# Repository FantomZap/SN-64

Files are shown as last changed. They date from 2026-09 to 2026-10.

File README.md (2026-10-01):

# SN 64

SN 64 is an active engineering project for an FPGA-based SNES/Super Famicom cartridge adapter. **The target is one adapter for both an original Nintendo 64 and ModRetro M64 through the standard N64 cartridge interface, without internal console modifications.** Compatibility has not yet been demonstrated on hardware.

The FPGA will recreate the SNES motherboard environment and provide a protected, complete SNES cartridge interface. Original SNES/SFC cartridges, Super EverDrive X5/X6, and FXPAK Pro are primary compatibility targets. The host console supplies controller input and runs the adapter's configuration and diagnostics bootstrap.

## Current status

**The project now includes a simulated SNES console candidate with a contention-checked physical cartridge bridge and a simulated N64/M64 host endpoint (reused SummerCart64 PI controller with an SN64 ROM window and mailbox), editable mechanical reference parts, and the KiCad cartridge/USB circuit draft. No completed or tested SN 64 hardware exists yet.** The [core evaluation](fpga/README.md) reuses pinned SNESTang sources and includes original diagnostics, synthesis and internal FPGA fit experiments. The [mechanical package](mechanical/README.md) contains FreeCAD, STEP and STL files for a socket hole-pattern coupon and source N64 board reference; these are not a final enclosure. The [editable schematic](hardware/sn64/README.md), revision `0.4-r3`, contains both cartridge connectors and five child sheets wired together by a shared net-name contract: the [USB programmer](hardware/sn64/usb-programmer.kicad_sch) (USB-C, protection, FT232HL, isolated JTAG), the [cartridge interface](hardware/sn64/cart-interface.kicad_sch) (5 V/3.3 V translators, reset/IRQ/CIC), the [FPGA](hardware/sn64/fpga.kicad_sch) (ECP5-85F with every ball assigned, configuration flash, N64 bus switches), [power](hardware/sn64/power.kicad_sch) (host/USB source selection, regulators, default-off cartridge power, monitors) and [clock/cartridge audio](hardware/sn64/av-clock.kicad_sch) (Si5351A, PCM1808 ADC). The FPGA design is routed on that sheet's real pinout.

Independent static checks on the integrated schematic: ERC 0 errors; 30 interface, 69 USB, 20 cartridge, 23 power, 30 clock/A-V and 4 root-connectivity checks pass; the FPGA sheet passes 12 of 13, and the failing check is a recorded open decision (a 5 V divider feeding one FPGA ball). These verify source agreement and schematic connectivity, not working hardware or USB compliance. The [136-entry requirements register](docs/requirements.md) preserves every specification target and records partial evidence separately from acceptance. Several footprints, the final BOM, board-level I/O timing, power and signal-integrity analysis, PCB layout, enclosure and every hardware test remain pending. **This is not fabrication ready.**

Every target in the original specification remains in scope, including PAL, protection, save integrity, telemetry, independent recovery, factory testing, and the additional requirements. The SNES picture and sound go to the console over the cartridge bus and appear on the console's own output (M64 HDMI, N64 AV jack); the adapter has no video output of its own. M64's reserved contacts stay isolated.

## Documents

- [Engineering specification, Rev A](SN_64_Engineering_Specification_Rev_A.docx)
- [Engineering implementation plan](docs/superpowers/plans/2026-09-28-sn64-engineering-plan.md)
- [Full requirements and acceptance register](docs/requirements.md)
- [System architecture and integration status](docs/architecture.md)
- [Console-core evaluation and reproducible builds](fpga/README.md)
- [Physical cartridge bridge design and open tests](docs/design/physical-cartridge-bridge.md)
- [Cartridge bridge implementation and simulation evidence](docs/design/cartridge-bridge-implementation.md)
- [N64/M64 endpoint implementation and mailbox map](docs/design/n64-endpoint-implementation.md)
- [N64 CIC lockout implementation](docs/design/n64-cic-implementation.md)
- [Power-control state machine](docs/design/power-sequencer-implementation.md)
- [Clock plan and region selection](docs/design/clock-plan.md)
- [Controller path and default N64 mapping](docs/design/controller-path-implementation.md)
- [SNES CIC lock and region detection](docs/design/snes-cic-implementation.md)
- [N64 bootstrap menu ROM](docs/design/n64-bootstrap.md)
- [Integrated top level and system simulation](docs/design/system-integration.md)
- [Bootstrap ROM window from the configuration flash](docs/design/bootrom-flash.md)
- [Mechanical architecture: board arrangement, insertion depths, region-free opening](docs/design/mechanical-architecture.md)
- [Console video path: SNES picture and sound through the N64/M64's own output](docs/design/console-video-path.md)
- [ROM-header region fallback](docs/design/header-region-probe.md)
- [On-board HDMI output (retired 2026-09-29)](docs/design/av-output-implementation.md)
- [Cartridge analog audio into the console stream](docs/design/cart-audio-implementation.md)
- [Cartridge interface schematic sheet](docs/design/cart-interface-schematic.md)
- [FPGA schematic sheet and board pinout](docs/design/fpga-schematic.md)
- [Power schematic sheet](docs/design/power-schematic.md)
- [Clock and cartridge-audio schematic sheet](docs/design/av-clock-schematic.md)
- [Cartridge data-bus source evidence and unresolved behavior](docs/design/bus-electrical-evidence.md)
- [FPGA/package, supply and board reuse review](docs/design/fpga-board-selection.md)
- [Power architecture, including M64 USB power](docs/design/power-architecture.md)
- [Socket selection and missing manufacturer dimensions](docs/design/socket-selection.md)
- [Editable mechanical references and fit coupon](mechanical/README.md)
- [Peripheral research and current decisions](docs/research/snes-peripherals.md)
- [Reusable SNES circuits, layouts and FPGA source](docs/research/reusable-designs.md)
- [Connector, cartridge and mounting dimensions](docs/dimensions.md)
- [Official M64 schematics and mechanical references](docs/research/m64-reference-files.md)
- [Local reference collection and source manifests](references/README.md)
- [KiCad cartridge-interface draft and verification](hardware/sn64/README.md)
- [SNES signal directions and electrical notes](docs/design/snes-interface-notes.md)
- [N64/M64 signal directions and power references](docs/design/n64-interface-notes.md)
- [sd2snes level-shifter reuse review](docs/design/translation-reuse-review.md)
- [USB programming architecture and remaining integration](docs/design/usb-programming-architecture.md)
- [USB connector mechanics and crystal selection](docs/design/usb-connector-mechanics.md)
- [Dated project work log](docs/project-work-log.md)

Current input decisions are standard, configurable N64-to-SNES controller mapping; no multitap; and undecided Super Scope/Justifier support. Virtual SNES mouse control using an N64 controller is deferred to a later FPGA/firmware update. The initial design must preserve the necessary input data, update path, and justified resource margins. Other researched accessories are candidates, not selected features.

**USB-C is mandatory in the first hardware revision.** Provide a side-mounted, externally accessible USB-C data port for initial firmware/FPGA programming, subsequent updates and recovery from a computer. It must be usable without a successful N64 or M64 boot. Include the connector, supporting programming circuitry and enclosure opening in the initial design; a power-only port or a future hardware addition does not satisfy this requirement. The bridge circuit is now drawn, but blank-board loading, persistent image programming and recovery still require the selected FPGA/storage, their power design, host software and bench validation.

## Tools and research approach

- **KiCad 10.0.6:** schematics, PCB layout, checks, and manufacturing exports.
- **FreeCAD 1.1.4:** dimensioned enclosure and mechanical assembly models.
- **Blender:** available for visualization and mesh work.
- **OSS CAD Suite 2026-09-28:** Yosys/Slang, Verilator, nextpnr-ecp5 and programming utilities; [pinned toolchain](fpga/reports/toolchain.json). Initial loading of actual SN64 hardware is still untested.

Start by adapting working upstream designs: reuse their HDL, circuits, layouts, footprints and mechanical CAD where they fit. The main custom work is integrating the physical SNES cartridge bridge with the SNES core, protected power, the N64 host endpoint, A/V and enclosure. Dimensions and interface assumptions retain their provenance and are cross-checked. Physical fit and functional tests follow adaptation.

## Planned outputs

These directories describe the intended outputs. Cartridge/USB schematics, the core candidate/tests, mechanical reference models and the acceptance register exist; the complete product implementations remain in progress.

| Planned directory | Contents |
|---|---|
| `references/` | Reference drawings, datasheets, CAD provenance, and license records |
| `hardware/sn64/` | KiCad schematic, PCB, libraries, and component models |
| `fpga/` | HDL, core integration, simulations, and constraints |
| `firmware/` | N64 bootstrap, controls, diagnostics, updates, and recovery |
| `mechanical/` | Enclosure CAD, drawings, fit samples, and assembly models |
| `test/` | Bring-up procedures, fixtures, measurements, and compatibility results |
| `manufacturing/` | Versioned PCBWay fabrication, assembly, and enclosure packages |

PCBWay is the intended manufacturing provider. Release deliverables include editable KiCad sources, schematic PDFs, Gerbers and NC drills, stack-up/fabrication notes, BOM with manufacturer part numbers and approved alternates, placement files, assembly drawings, programming/test instructions, and test-point/JTAG documentation. Enclosure deliverables include editable CAD, STEP/STL parts, dimensioned drawings, material/finish/fastener notes, and verified interface dimensions.

Manufacturing and compatibility claims will follow prototype bring-up, physical fit checks, and recorded validation on both hosts.

## Licensing

SN64 is open hardware and free software: [GPL-3.0-or-later](LICENSE-GPL-3.0-or-later.txt) for the FPGA logic, firmware and scripts, and [CERN-OHL-S-2.0](LICENSE-CERN-OHL-S-2.0.txt) for the hardware design files and documentation. [LICENSING.md](LICENSING.md) says what applies to what and what you may and must do; [NOTICE](NOTICE) holds the attribution terms. Credit line: **SN64 by FantomZap**, source at <https://github.com/FantomZap/SN-64>.

## Credits

SN64 is built on other people's open work, above all [SNESTang](https://github.com/nand2mario/snestang) by nand2mario (a port of the SNES core by srg320 and gyurco) and [SummerCart64](https://github.com/Polprzewodnikowy/SummerCart64) by Mateusz Faderewski. The full list, with what each project contributed and its licence, is in [CREDITS.md](CREDITS.md).

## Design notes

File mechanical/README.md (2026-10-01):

# Mechanical fit references

These are source-backed nominal reference models, not a final SN64 assembly or fabrication package. [Socket selection and open dimensions](../docs/design/socket-selection.md) distinguish supplier evidence from assumptions.

| Model | Editable CAD | Neutral exports | Scope |
|---|---|---|---|
| SNES hole-pattern coupon | [FCStd](fit-references/snes-hole-pattern-coupon.FCStd) | [STEP](fit-references/snes-hole-pattern-coupon.step), [STL](fit-references/snes-hole-pattern-coupon.stl) | 62 nominal Sanni holes; plate margins/thickness are explicit coupon choices |
| N64 source-board reference | [FCStd](fit-references/n64-sc64-board-reference.FCStd) | [STEP](fit-references/n64-sc64-board-reference.step), [STL](fit-references/n64-sc64-board-reference.stl) | SummerCart64 full perimeter, 1.2 mm thickness and two mounting holes; no copper or mating bevel |

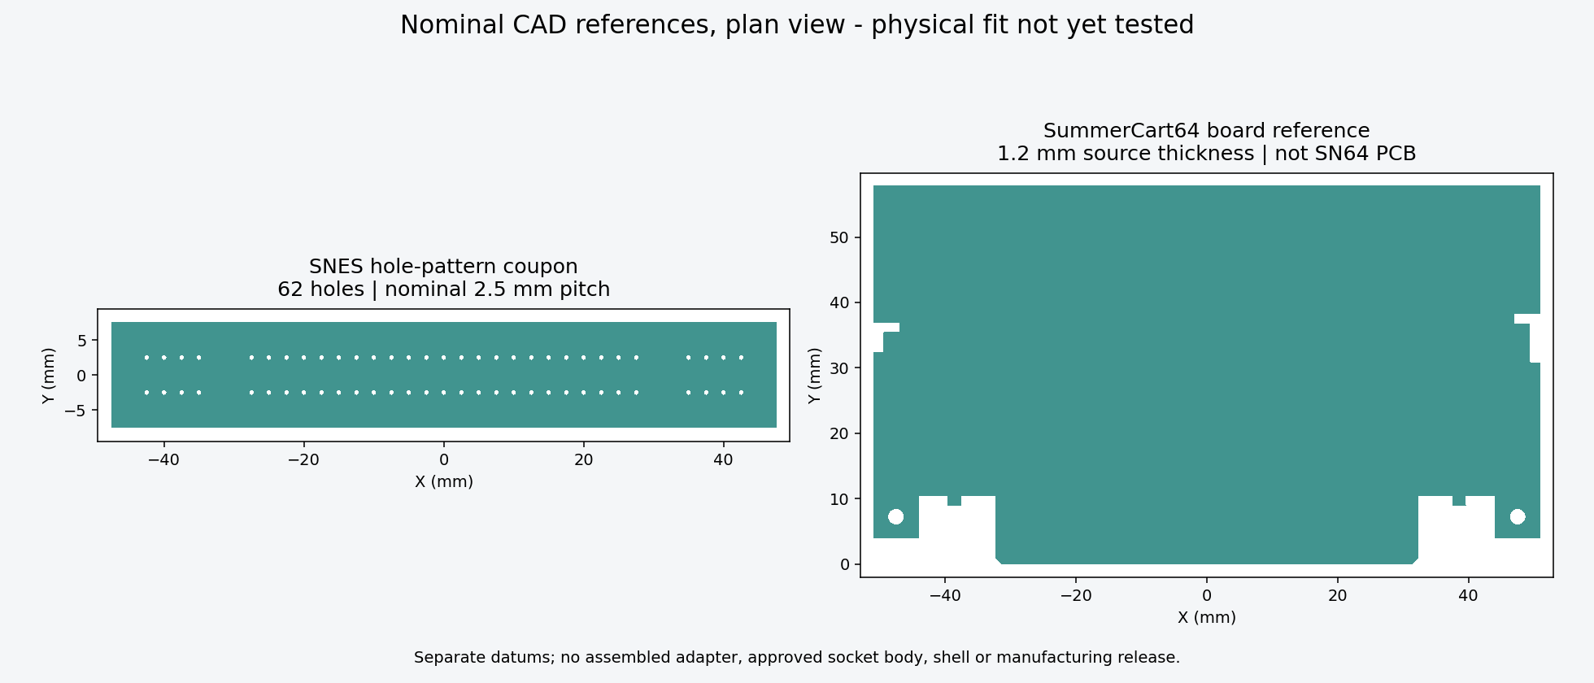
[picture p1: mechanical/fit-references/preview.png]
Nominal reference preview


## Datums and editable parameters

All values are millimetres. The two documents are **independent references**, not assembled at a common mating datum.

- SNES coupon: X = Sanni footprint Y − 42.5; Y = Sanni footprint X − 2.5. Pin 1 is (−42.5, −2.5), pin 31 is (+42.5, −2.5), pin 32 is (−42.5, +2.5). Z = 0 is the coupon bottom. The native `Parameters` spreadsheet controls the 95 × 15 × 1.6 mm plate and nominal 0.762 mm hole diameter; plate dimensions are design choices and are **not socket dimensions or a selected PCB thickness**. Individual cylinder placements retain the 62 source centres. No housing, mounting ears or solder-tail shape has been invented.
- N64 reference: X = source PCB X − 150; Y = 135.5 − source PCB Y. The origin is the insertion-tip midpoint, Y points toward the board body, and Z = 0 is the bottom face. The source-outline sketch preserves all 35 segments as fixed geometry; the spreadsheet controls extrusion thickness and nominal 2.5 mm mounting-hole diameter. Hole centres are (±47.5, 7.25). Do not treat the entire source board perimeter as SN64's approved outline.

The coupon has nominal holes without printer or fabrication compensation. Inspect its dimensions before using it as a sample jig; small printed holes may need calibrated finishing. A plastic reference does not reproduce contact plating, board stiffness or insertion behavior. Do not force a reference into a connector. Physical measurements and sample tests have not been performed.

## Verification and reproduction

[Validation results](fit-references/validation.json) record FreeCAD 1.1.4, bounds, volumes and file hashes. Both generated bodies are valid single solids; STEP reimport preserves validity/volume, and both STL exports are closed. Both FCStd files were reopened and their thickness parameter temporarily changed to 2 mm: each recomputed to a valid 2 mm body. The temporary changes were not saved. The exported mesh preview was visually inspected. These checks verify the artifacts, not socket or host fit.

From the repository root, using the installed tool versions:

```powershell
& 'C:/Program Files/KiCad/10.0/bin/python.exe' mechanical/extract_source_datums.py --source-root '%USERPROFILE%/Documents/Codex/SN 64 Project'
& 'C:/Program Files/FreeCAD 1.1/bin/python.exe' mechanical/build_fit_references.py
& 'C:/Program Files/FreeCAD 1.1/bin/python.exe' mechanical/render_fit_references.py
& 'C:/Program Files/FreeCAD 1.1/bin/python.exe' mechanical/inspect_reference_shells.py --source-root '%USERPROFILE%/Documents/Codex/SN 64 Project'
```

`build_fit_references.py` regenerates its named outputs. Preserve manual edits separately before running it. [Source datums](source-datums.json) include pinned source URLs and SHA-256 hashes. [Shell inspection](shell-inspection.json) records the independently imported upstream models; its bounding boxes must not be combined into a supposed assembled-cartridge envelope. Local originals and `downloads/Upstream-shell-references.FCStd` stay ignored in Git.

The extractor verifies both source CAD hashes and revisions against this checkout's `references/source-manifest.json` before parsing or writing. Run `python mechanical/test_source_provenance.py --source-root <reference-project>` with KiCad Python to check authentic inputs and rejection of both modified inputs without overwriting saved datums.

## Attribution and remaining design

The hole-pattern coupon derives its geometry from [Sanni/cartreader](https://github.com/sanni/cartreader/blob/060d8ae0bf4be40bfc6a368bf6fbf7b594b3884d/hardware/footprints/%21OSCR.pretty/SNES%20Slot.kicad_mod), whose hardware notice is [CC-BY-4.0](licenses/Sanni-hardware-CC-BY-4.0.txt). Changes: rotated/centred coordinate system, added parameterized coupon plate and subtracted the source holes. The N64 reference derives from [Polprzewodnikowy/SummerCart64](https://github.com/Polprzewodnikowy/SummerCart64/blob/a1e7996d2cbece686820a5c785029c68514f17b0/hw/pcb/sc64v2.kicad_pcb), with [CERN-OHL-S-2.0 hardware notice](licenses/SummerCart64-PCB-CERN-OHL-S-2.0.txt). Changes: geometry-only extraction, insertion-tip datum, native extrusion/cuts and exports. Neither upstream author endorses SN64 or these changes. Source and editable generation files accompany the derivatives.

[Shell provenance](shell-source-manifest.json) separately records usagi_'s archived [CC-BY-3.0 notice](licenses/usagi-SFC-shell-CC-BY-3.0.txt); that notice is not assigned to other repository files.

Next mechanical work is qualifying the actual socket, selecting the SN64 board/stackup and placements, aligning both hosts' bay/door/eject geometry, and supporting the full cartridge set. Final shell features must include the first-revision side USB-C port and accessible cable path. Enclosure, print material/tolerances, stress/fit tests and PCBWay release remain unfinished.

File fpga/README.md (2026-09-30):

# Console-core evaluation

This directory contains a reproducible **console-only engineering candidate** built from SNESTang. It is not programmable SN64 release firmware. The blocks listed below (bridge, N64 endpoint and CIC, console video path, power sequencing, clocks, flash boot ROM, cartridge audio) are integrated in `rtl/sn64_top.sv` and routed on the board pinout, but everything is simulated or synthesised only: no bitstream has been generated or run on hardware.

- [Pinned upstream selection and hashes](vendor/snestang/provenance.json), with original GPL license and file notices retained.
- [Candidate wrapper](rtl/sn64_console_candidate.sv): CPU/PPU/APU plus 128 KiB WRAM, 64 KiB VRAM and 64 KiB ARAM in synchronous inferred RAM.
- [Diagnostic](tests/tb_console_boot.sv): original instruction program; no commercial game image.
- [WRAM bus diagnostic](tests/tb_wram_bus.sv): active-cycle RAM data, direct/mirrored addresses, RAM port and B-to-A DMA.
- [Cartridge bridge](rtl/sn64_cart_bridge.sv) and [socket-facing top](rtl/sn64_console_with_bridge.sv): data-bus ownership with one released clock at every turnaround; [physical-bus diagnostic](tests/tb_cart_bridge.sv) with contention monitor and a fault-injected run. See [implementation notes](../docs/design/cartridge-bridge-implementation.md).
- [N64/M64 endpoint](rtl/sn64_n64_endpoint.sv): vendored [SummerCart64 PI controller](vendor/summercart64/provenance.json) (GPL-3.0, unmodified) with an SN64 bootstrap ROM window and mailbox; [host-model diagnostic](tests/tb_n64_endpoint.sv). See [endpoint notes](../docs/design/n64-endpoint-implementation.md).
- [N64 CIC lockout](../docs/design/n64-cic-implementation.md): vendored SummerCart64 CIC (SERV soft core, ISC) running the vendored UltraCIC_C firmware (MIT); build the image with `fpga/tools/build_cic.py` (xPack riscv-none-elf-gcc), then [tb_n64_cic.sv](tests/tb_n64_cic.sv) checks the ID, seed and checksum streams against an independent reference.
- [Recorded evaluation](reports/evaluation.md) and [machine-readable evidence](reports/evaluation.json).
- [Board top level](rtl/sn64_board_top.sv): one ECP5 PLL (25 -> 62.5 MHz), one DCSC that selects the NTSC/PAL SNES master and starts/stops it glitchlessly, bootstrap ROM from the configuration flash, CIC pads, and the pad adapters the FPGA schematic sheet needs (cart_data inout, open-drain Si5351 I2C, cart_reset_pull_n, reserved JOYBUS/INT, cartridge-audio ADC inputs). Its pins come from [constraints/sn64_board.lpf](constraints/sn64_board.lpf), generated with the [FPGA sheet](../docs/design/fpga-schematic.md). Route it with `python tools/route_top.py` (default `--top board` with the real LPF; `--lpf` selects another constraint file, e.g. the older `constraints/sn64_board_trial.lpf`; see [integration notes](../docs/design/system-integration.md)).
- [Cartridge analog audio](../docs/design/cart-audio-implementation.md): [sn64_i2s_rx.sv](rtl/sn64_i2s_rx.sv) (I2S receiver sampled by the 62.5 MHz host clock) and [sn64_audio_mix.sv](rtl/sn64_audio_mix.sv) (elastic buffer into the SNES domain, saturating mix with the DSP output); [bench](tests/tb_audio_mix.sv) with four fault builds.
- [Console video path](../docs/design/console-video-path.md): [sn64_frame_window.sv](rtl/sn64_frame_window.sv) (RGBA5551 frame buffer and audio ring behind the endpoint's PI domain-2 window at 0x0800_0000); [bench](tests/tb_frame_window.sv) with a PI host model at fast timing and a fault build. The board's own HDMI output was removed on 2026-09-29 ([retired notes](../docs/design/av-output-implementation.md)).
- [Bootstrap ROM from flash](rtl/sn64_bootrom_flash.sv): vendored SummerCart64 `memory_flash` (QSPI EBh, unmodified) behind the endpoint's ROM window, `ROM_FROM_FLASH=1`; [bench](tests/tb_bootrom_flash.sv) with a QSPI flash model. See [notes](../docs/design/bootrom-flash.md).
- [ROM-header region probe](rtl/sn64_header_probe.sv): reads the SNES header with the cartridge held in reset to pick NTSC/PAL when there is no key CIC; [bench](tests/tb_header_probe.sv). See [notes](../docs/design/header-region-probe.md).
- [CIC pad sequencing](rtl/sn64_cic_pad.sv): SN74LVC1T45 DIR against pad drive; [bench](tests/tb_cic_pad.sv).
- [Physical-cartridge bridge work](../docs/design/physical-cartridge-bridge.md) and [FPGA selection](../docs/design/fpga-board-selection.md).

## What is reused and changed

SummerCart64's PI controller is vendored separately under `vendor/summercart64/` with its own provenance and GPL-3.0 license. The 35 SNESTang files come from SNESTang commit `5f0ef193145f67bded7f73f2c477ac8da4d85f7e`. They retain their upstream content except newline normalization recorded per file. The ROM-loader/cartridge-emulation wrapper is excluded so the real cartridge retains its ROM, save memory and enhancement hardware.

`tools/prepare_core.py` verifies every source hash and writes generated copies under ignored `build/`. It selects the upstream `VERILATOR` inferred-memory branch, omits ten simulation-only diagnostic statements, connects HIGH_RES, exports PHI2, ties the open TURBO input low and exports the CPU/DMA/HDMA address **before** the upstream WRAM mirror conversion. Internal RAM decoding keeps its original address path. The generated preparation manifest lists changes and hashes. No vendor file is patched in place.

The diagnostic checks reset-vector fetch, native CPU execution, external 16-bit reads/writes, 16-bit WRAM readback, preservation of a low-bank mirrored address, a B-bus write, cartridge-to-WRAM DMA and PHI2 presence. A corrupted cartridge read must produce the expected failure. Both PAL mode-bit values run, but the test clock remains the same: this is **not PAL clock/video qualification**. It does not yet exercise graphics, sound, HDMA, cartridge select qualification, open bus, output-enable timing or real cartridges.

The wrapper now selects the current WRAM byte for `cart_data_out` during an active RAM read instead of the previous MDR byte. `cart_wram_read_valid` qualifies that source with core enable/reset and RAM CE/OE. It is **not** a complete translator output enable. The separate bus diagnostic checks direct reads, both low-memory mirrors, CPU RAM-port reads, B-to-A DMA and immediate source-valid removal during pause/reset with the clock stopped. CPU-internal register reads remain distinct from electrically visible data; see [source evidence](../docs/design/bus-electrical-evidence.md).

## Reproduction

CIC firmware (needed for the CIC test; otherwise that test is reported as skipped):

```powershell
python fpga/tools/build_cic.py --toolchain C:/path/to/xpack-riscv-none-elf-gcc/bin
```

Use [OSS CAD Suite](https://github.com/YosysHQ/oss-cad-suite-build/releases/tag/2026-09-28) for Yosys/Slang, Verilator and nextpnr-ecp5. Windows also needs a C++ compiler and GNU Make; the inspected [w64devkit 2.10.0](https://github.com/skeeto/w64devkit/releases/tag/v2.10.0) provides both. These portable tools were installed under the user's `.codex/tools` folder without changing system PATH. [Tool versions and archive hashes](reports/toolchain.json) identify this run.

From the repository root, adapt the two installation paths:

```powershell
. 'C:/path/to/oss-cad-suite/environment.ps1'
$env:PATH = 'C:/path/to/w64devkit/bin;' + $env:PATH
& 'C:/Program Files/KiCad/10.0/bin/python.exe' fpga/tools/evaluate.py --sim-build-dir C:/sn64-build/sim-console --mode all
```

The Verilator object directory must contain no spaces, even if the repository does. On Windows the runner invokes `verilator_bin.exe` and sets its installed `VERILATOR_ROOT`; the extensionless Perl wrapper is not relied upon. Normal Python 3 works too; KiCad's bundled Python was convenient here. No network download is needed to prepare or evaluate the vendored core once tools are installed.

`--mode sim` runs all diagnostics, including the bridge bench and its fault-injected build (which must fail); `--mode synth` maps the core; `--mode pnr` uses the **existing** `build/console-ecp5.json` and does not independently establish that it matches current sources. Use `--mode all` for a current complete experiment. Logs and the fresh report are written to `build/evaluation/`; reviewed snapshots are copied into `fpga/reports/` deliberately.

Yosys uses `scratchpad -set abc9.xaiger 1`: the pinned Windows build's experimental XAIGER2 backend asserted during export. This selects its existing older XAIGER path; it does not skip logic mapping. The synthesis report explicitly checks that the mapped TURBO control is constant zero. Earlier static-function alias and unused-debug warnings are preserved, not represented as a warning-free build.

P&R targets an ECP5-85F, CABGA381, speed grade 6, at 21.477273 MHz **with unconstrained trial I/O locations**. No board pinout or external setup/hold constraints have been applied and no bitstream is generated. The result is evidence for internal resource/timing feasibility only; the full design must repeat it after host, A/V, protection and board constraints are added.

## License and source availability

The selected core is distributed with [upstream GPL-3.0 text](vendor/snestang/LICENSE) and retained file-level notices. SN64's wrapper and diagnostic use GPL-3.0-or-later. Keep this source, preparation patches, manifests and build instructions with future derived distributions; complete combined-project license review before releasing a product. Other hardware/CAD licenses are tracked in their own directories.

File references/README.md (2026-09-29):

# Downloaded design starting points

The collection is intended for direct reuse and adaptation. Upstream downloads live locally under `references/downloads/`; they are ignored by Git, while source URLs, hashes and our measurements are retained. Downloading an upstream design does not select all its components for SN 64.

| Part of SN 64 | Reuse starting point | Local folder |
|---|---|---|
| SNES FPGA logic | MiSTer SNES CPU/PPU/APU and timing implementation | `downloads/fpga/SNES_MiSTer-c61bfd45171c62000417333cd4679890bcd091a6/` |
| SNES motherboard wiring and footprints | OpenSFC SHVC-CPU-01 Rev A KiCad project and libraries | `downloads/fpga/OpenSFC-6574450b1a4594b2aae436cf23869b0fb5808ce8/` |
| SNES electrical interface, regulator/audio examples, CIC | sd2snes Rev F schematics, PCB, libraries and SuperCIC | `downloads/fpga/sd2snes-cf7e21d7a5978fcd74981d71c3cfbf6e982a4dd1/` |
| Female SNES socket and adapter layout | sanni/cartreader footprint and SNES adapter KiCad project | `downloads/sanni/` |
| N64/M64 lower cartridge edge, host circuitry and shell | SummerCart64 PCB, schematic, STEP and STL shell files | `downloads/summercart64/` |
| M64 host-side cross-check and surrounding mechanics | Official cartridge/mainboard schematics, assembly drawings and cartridge/door/eject CAD | `downloads/m64/` |
| Alternative standalone SNES FPGA integration | SNESTang source archive, HDMI/memory design notes and board constraints | `downloads/snestang/` |

Read the [SNES reuse map](../docs/research/reusable-designs.md), [dimension sheet](../docs/dimensions.md) and [M64 file index](../docs/research/m64-reference-files.md) for exact roles and source links.

## SNESTang alternative

[SNESTang](https://github.com/nand2mario/snestang/tree/5f0ef193145f67bded7f73f2c477ac8da4d85f7e) is an existing port of the SNES core to Sipeed Tang boards. Its working board integration, HDMI path and memory controller are useful alternatives to porting the MiSTer wrapper directly. It loads ROMs from microSD, so a physical cartridge interface is still adaptation work. Its [design notes](https://github.com/nand2mario/snestang/blob/5f0ef193145f67bded7f73f2c477ac8da4d85f7e/doc/design.md) discuss clock changes for HDMI synchronization; those cannot be copied blindly into a physical-cartridge timing design. This is a candidate, not a final FPGA selection.

The board vendor publishes [Tang Console schematics, BOM and mechanical resources](https://wiki.sipeed.com/hardware/en/tang/tang-console/mega-console.html#Hardware-Resources). Those board-resource links were located; the vendor files themselves have not been downloaded in this collection. SNESTang's source archive, README, license and design notes were downloaded and hashed in [its manifest](snestang-manifest.json).

## Provenance and practical outputs

- [SummerCart64 and sanni manifest](source-manifest.json): pinned commits, download URLs, byte counts and SHA-256.
- [SNESTang manifest](snestang-manifest.json): pinned source archive and documentation.
- Other download folders contain their own `manifest.json` with provenance and checksums; the research notes identify pinned upstream versions and source notices.
- [Extracted dimensions](measurements/): full N64 and SNES pad-coordinate CSVs, hole positions, STEP validity and shell bounds.
- [Extraction script](extract_dimensions.py): verifies the upstream hashes before reading the KiCad geometry.
- `.local/research/exports/`: locally generated schematic PDFs, N64 board STEP and a FreeCAD shell reference document.

OpenSFC is a motherboard reproduction using original custom chips. sd2snes is a cartridge, and SummerCart64 is an N64 cartridge. Their useful circuitry is reused according to its role; the SNES motherboard behavior comes from the SNES FPGA core.

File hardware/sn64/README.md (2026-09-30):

# SN 64 KiCad schematic draft

Open **[sn64.kicad_pro](sn64.kicad_pro)** in KiCad 10, then open the schematic. The root (rev `0.4-r3`, A2) holds both cartridge connectors and five child sheets, wired by same-name root labels (the shared net-name contract in [system-integration.md](../../docs/design/system-integration.md#schematic-integration-round-3-2026-09-29)):

- page 2: the [USB programmer child sheet](usb-programmer.kicad_sch) (exports USB_VBUS, USB_3V3, USB_CC1/CC2, jtag_tck/tms/tdi/tdo, TARGET_VREF; R101/R102 DNP because the power sheet's TUSB320 presents Rd);
- page 3: the [SNES cartridge interface child sheet](cart-interface.kicad_sch) (rev 0.3.1-cart: 5 V/3.3 V translators, reset/IRQ/CIC paths, per-pin CIC data translators; see [notes](../../docs/design/cart-interface-schematic.md));
- page 4: the [FPGA child sheet](fpga.kicad_sch) (rev 0.5-fpga, no HDMI pins, designators 4xx: LFE5U-85F CABGA381 with all 381 balls assigned, W25Q128JVSIQ configuration flash, JTAG, SN74CB3Q3384A N64 bus switches; see [notes](../../docs/design/fpga-schematic.md)). Its pin table also generates [interfaces/fpga-pin-map.csv](interfaces/fpga-pin-map.csv) and [fpga/constraints/sn64_board.lpf](../../fpga/constraints/sn64_board.lpf);
- page 5: the [power child sheet](power.kicad_sch) (designators 3xx: host/USB eFuse priority mux, TUSB320, TPS63070 5V_PRE, three TLV62569 FPGA rails, default-off cartridge eFuse and interface switch, monitors; see [notes](../../docs/design/power-schematic.md));
- page 6: the [clock/cartridge-audio child sheet](av-clock.kicad_sch) (draft 0.2-av, designators 7xx: Si5351A + 25 MHz crystal, 25 MHz FPGA oscillator, PCM1808 I2S-master cartridge-audio ADC; the HDMI output of draft 0.1-av was removed on 2026-09-29; see [notes](../../docs/design/av-clock-schematic.md)).

The [PDF](exports/sn64-interface-draft.pdf) is a review export of all six pages; the round-3 export was not visually inspected (no rasteriser available). Project-local libraries hold the symbols KiCad does not ship. It is not a complete electrical design or a manufacturing package.

The SNES socket now lives on its own small board: **[../sn64-socket/](../sn64-socket/)** (generated by [tools/split_socket_board.py](tools/split_socket_board.py); design note [mechanical-architecture.md](../../docs/design/mechanical-architecture.md)). On this main board, J2 is the 2x40 2.00 mm joint header. Check both boards with `tools/verify_socket_joint.py` (and `--negative-test`).

**Board (first draft, 2026-09-29):** [sn64.kicad_pcb](sn64.kicad_pcb) is generated by [tools/build_main_pcb.py](tools/build_main_pcb.py): 6 layers, 1.2 mm, PCBWay-compatible rules, the SummerCart64 lower outline extended to 70 mm above the tongue shoulders, all 410 parts imported with their 530 nets and a connectivity-pulled placement inside block zones (N64 interface at the bottom, FPGA centred with its decoupling underneath, translators under the top joint header with their resistor arrays beneath them, power/USB left, clock/audio right; small passives on the bottom side). DRC after placement (rebuilt 2026-09-29 without the HDMI parts): 0 real errors; the only reports are the USB-C receptacle pads at the board edge (by design; rule exception in `sn64.kicad_dru`) and the N64 fingers' shared solder-mask opening (SummerCart64 footprint).

**Routing draft (2026-09-30):** the tracked board now carries a first autorouted draft ([notes](../../docs/design/pcb-routing.md)): FPGA rotated 180° so its N64 bank faces the bus switches, 240 dog-bone fan-out vias, GND plane on In1, 3.3 V plane on In3, 1.1 V island on In4, signals routed by KiCadRoutingTools (Rust A*, run 2), 157 plane vias, outer GND pours. DRC: no shorts, crossings, clearance or hole violations. **Still open:** 75 signal/power nets (95 connections, mostly in the translator row) and 219 plane pads without a via ([validation/pcb-open-connections.json](validation/pcb-open-connections.json)). Tools: [tools/prepare_route.py](tools/prepare_route.py), [tools/add_plane_vias.py](tools/add_plane_vias.py), [tools/finish_route.py](tools/finish_route.py), [tools/fab-pcbway.txt](tools/fab-pcbway.txt). Rerunning `build_main_pcb.py --force` regenerates the placement and discards this routing. Renders: [top](exports/sn64-pcb-draft-top.png), [bottom](exports/sn64-pcb-draft-bottom.png). Nothing is routed yet; the placement is a starting point, not a reviewed layout.

## What is present

| Item | Contents |
|---|---|
| J1 | 50-contact N64 edge, intended for both original N64 and M64 |
| J2 | Full 62-contact SNES/SFC female socket, including outer contacts and analog audio |
| USB child sheet | J101 JAE USB-C, DNP CC resistors (the power sheet's TUSB320 presents Rd), data/CC ESD arrays, AP2112K-3.3 bridge regulator, FT232HL revision C, 12 MHz crystal, optional DNP EEPROM, SN74AXC4T774 JTAG isolation and J102 target-side service header |
| Symbol library | Editable native KiCad symbols, numbered from the checked pin maps |
| Footprint library | Sanni female-socket and SummerCart64 N64 edge references; local USB component footprints including the reused JAE receptacle geometry |
| Pin maps | [N64](interfaces/n64-pin-map.csv), [SNES](interfaces/snes-pin-map.csv) and [USB circuit nets](interfaces/usb-programmer-net-map.csv) |
| FPGA, power, A/V sheets | See the page list above; authored by [add_fpga_sheet.py](tools/add_fpga_sheet.py), [add_power_sheet.py](tools/add_power_sheet.py) and [add_av_clock_sheet.py](tools/add_av_clock_sheet.py) (deterministic, refuse to overwrite without `--force`), checked by [verify_fpga_sheet.py](tools/verify_fpga_sheet.py), [verify_power_sheet.py](tools/verify_power_sheet.py) and [verify_av_clock_sheet.py](tools/verify_av_clock_sheet.py) |
| Validation | Exported netlist, ERC report, per-sheet checks (interface 31, USB 69, cartridge 20, FPGA 14, power 23, A/V 27) and the [root connectivity check](tools/verify_root_connectivity.py) (4 checks over 141 contract names) |

`GND` is the only net that directly crosses the USB/host-connector boundary. `HOST_3V3`, `HOST_12V`, `SNES_5V_CART`, `USB_VBUS`, `USB_3V3` and `TARGET_VREF` are distinct nets. USB_VBUS also feeds the power sheet's default-off USB input (U302, enabled only when the TUSB320 U301 reports at least 1.5 A and USB_3V3 is present); `TARGET_VREF` comes from FPGA_3V3 through R414 on the FPGA sheet and is not a USB target-power output. The N64 edge reaches the FPGA only through the host-gated bus switches; N64_AUDIO_L/R and the reserved edge contacts stay unconnected. `_N` in net names denotes active low; the cartridge symbols retain the source maps' slash notation.

Connector pins deliberately have the ordinary passive connector type. The CSV and [electrical notes](../../docs/design/snes-interface-notes.md), rather than these pin types, define endpoint direction and special handling. ERC cannot establish drive ownership, voltage tolerance or timing at these pending interfaces.

The USB bridge uses MPSSE JTAG with ACBUS6 controlling the translator's pulled-up, default-disabled `/OE`. The documented host command must include `--status-pin 14`. Its target JTAG nets now reach the ECP5's dedicated JTAG balls on the FPGA sheet (round 3); the configuration flash is loaded through the FPGA. The [programming architecture](../../docs/design/usb-programming-architecture.md) records blank-EEPROM startup, power isolation, persistent-loading requirements and the remaining tests. [Connector and crystal notes](../../docs/design/usb-connector-mechanics.md) record the source geometry and provisional 11 pF crystal load capacitors.

## Reused geometry and its limits

The SNES footprint retains all 62 pads, 2.5 mm ordinary pitch, two 7.5 mm gaps per row, 5 mm row separation, 1.524 mm pads and 0.762 mm drills. A specific purchasable socket, body dimensions and mounting details still need approval before board layout.

The N64 footprint preserves all 50 source pads, 2.5 mm pitch and 1.5 x 7 mm copper dimensions. Pads 1-25 remain on B.Cu and 26-50 on F.Cu. Its origin corresponds to source board coordinates (150,125), so pads are at local Y=6 mm. Six retained `Edge.Cuts` segments form the open lower connector profile, ending at local (±32.25,0) with its bottom at Y=10.5 mm. **Do not duplicate these cuts** when extending the board outline. The footprint does not include a complete board perimeter, mounting holes, layer stack or bevel. Those are separate controlled dimensions in [the geometry record](../../docs/dimensions.md). No generic KiCad board thickness should be treated as the connector thickness.

See [THIRD_PARTY.md](THIRD_PARTY.md), [cartridge provenance](libraries/provenance.json) and [USB provenance](libraries/usb-provenance.json) for sources, modifications and retained licenses. All 24 USB footprint pad objects also match the source geometry in the [footprint review](validation/usb-footprint-review.json). The copies of upstream footprints are reference assets, not a fit-tested SN 64 board.

## Validation and reproducibility

KiCad 10.0.6 exports the six-page schematic to XML and PDF. The round-3 PDF was **not** visually inspected (no rasteriser on this machine); earlier two-sheet exports were. The saved ERC report contains **zero errors** and 10 warnings: 5 `isolated_pin_label` on the reserved N64 edge labels (N64_AUDIO_L/R, N64_KEY1/KEY2_RESERVED, N64_VIDEO_SYNC_RESERVED) and 5 `pin_to_pin` (cartridge U206 unused B4-B8 on the flagged GND). On the integrated root: `verify_cart_interface.py` 20/20 (negative 6/6), `verify_power_sheet.py` 23/23 (negative 11/11), `verify_av_clock_sheet.py` 30/30 (negative 12/12), `verify_fpga_sheet.py` **12/13** (negative 10/10; the failing check is `efuse_fault_n`, a 5V_PRE divider on ball K4, an open owner decision in [system-integration.md](../../docs/design/system-integration.md)), `verify_root_connectivity.py` 4/4 (negative 4/4). The schematic is incomplete and is not an ERC-clean release. Rerun checks as circuitry changes.

The [independent validation script](tools/verify_interfaces.py) checks the exported connector pin/net assignments against the separately researched maps, rejects accidental cross-domain connections, and compares both footprints against the original downloaded sources. The corresponding [result](validation/interface-check.json) and [review](validation/interface-review.md) record the result and remaining limitations.

The saved reports record **30 cartridge-interface checks passed and 69 USB checks passed, with zero failed checks** (the USB set now also checks the DNP CC resistors and the CC/VBUS/USB_3V3/JTAG/TARGET_VREF exports). The [USB validator](tools/verify_usb_programmer.py) independently exports the schematic and compares it with fixed manufacturer pin tables, checking all USB component pins, rail separation, CC/data/ESD connections, bridge support, JTAG directions and disabled startup. See its [result](validation/usb-check.json) and [review](validation/usb-review.md). These are static checks; no USB enumeration, clock measurement, suspend-current measurement, programming, cold boot, electrical protection or compatibility test has been performed on SN 64 hardware.

To regenerate review files after editing, run these from this directory with KiCad's CLI on PATH:

```powershell
kicad-cli sch export netlist --format kicadxml -o validation/sn64.xml sn64.kicad_sch
kicad-cli sch export pdf -o exports/sn64-interface-draft.pdf sn64.kicad_sch
kicad-cli sch erc --format json --output validation/erc.json --exit-code-violations sn64.kicad_sch
```

The per-sheet and root checks, from the repository root with KiCad's Python (each also takes `--negative-test`, except the interface and USB validators):

```powershell
$py = 'C:\Program Files\KiCad\10.0\bin\python.exe'; $cli = 'C:\Program Files\KiCad\10.0\bin\kicad-cli.exe'
& $py hardware/sn64/tools/verify_interfaces.py --source-root . --kicad-cli $cli
& $py hardware/sn64/tools/verify_usb_programmer.py --kicad-cli $cli
& $py hardware/sn64/tools/verify_cart_interface.py --kicad-cli $cli
& $py hardware/sn64/tools/verify_fpga_sheet.py --kicad-cli $cli --lattice-csv <ECP5U-85 pinout CSV> --datasheets <dir>
& $py hardware/sn64/tools/verify_power_sheet.py --kicad-cli $cli
& $py hardware/sn64/tools/verify_av_clock_sheet.py --project hardware/sn64 --kicad-cli $cli
& $py hardware/sn64/tools/verify_root_connectivity.py --kicad-cli $cli
```

The initial authoring script, [create_interface_draft.py](tools/create_interface_draft.py), uses KiCad's Python and downloaded upstream sources. It refuses to replace an existing schematic unless explicitly passed `--force`. Once circuit editing begins, edit the native KiCad files; do not regenerate the initial sheet over the circuit work.

[add_usb_programmer.py](tools/add_usb_programmer.py) records how the initial USB sheet was authored from the reference designs and installed KiCad libraries. It also refuses to replace its sheet without `--force`; use native KiCad editing for subsequent development. Regeneration requires `--source-root <original-project-with-downloads>` and `--kicad-share <KiCad-share-directory>`, and intentionally replaces the entire USB child sheet when forced.

## Remaining integration

**Required in the first revision:** a side-mounted USB-C data/programming port and matching enclosure opening, supporting initial firmware/FPGA loading, updates and recovery without successful host-console boot. The bridge and service-access circuit now exists; the complete programming path remains pending target integration and testing. Final side-port placement, cable access and shell clearances remain mechanical work.

1. Build the power budget for the FPGA, memory, digital A/V and real cartridges on both hosts. The M64 reference annotates a 500 mA cartridge limiter; that is not a guaranteed SN 64 allowance. There is no 5 V N64 edge supply. Select input power, no-backfeed paths and default-off protected cartridge power from the actual budget.
2. Adapt the sd2snes translator circuit using the [reuse review](../../docs/design/translation-reuse-review.md). Reverse address/strobe ownership for a console endpoint; define enable, read/write turnaround and power-off behavior for the exact part. Separately implement IRQ/reset, CIC, expansion and analog audio.
3. Integrate the reusable SNES FPGA core, physical cartridge bridge and N64 endpoint. Select FPGA/package and memory only after resource, I/O, clock and timing evidence. Connect the USB programmer to the selected target and persistent configuration storage, define programming power/boot straps and package the loading/recovery software. Add health monitoring and A/V, then review the complete schematic.
4. Place and route a PCB with the verified mechanical constraints; develop the FreeCAD enclosure around that assembly. Produce PCBWay files after electrical review and prototype/fit validation.

These are stages of the full specification. PAL, protection, save integrity, telemetry, factory testing and all remaining specification targets are retained. Video and audio go to the console over the cartridge bus (console video path); the adapter has no output of its own. No PCB layout, FPGA bitstream, working adapter, print-ready shell or PCBWay manufacturing release is included in this revision.

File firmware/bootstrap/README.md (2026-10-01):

# SN64 bootstrap ROM (N64/M64 side)

The small program an N64 or M64 boots from the SN64 cartridge. It shows the SN64 menu, reads the N64 controllers, maps them to SNES button images and writes them to the SN64 mailbox every frame. It also lets the user request or drop SNES cartridge power. Built with [libdragon](https://github.com/DragonMinded/libdragon) (Unlicense). SN64 sources are GPL-3.0-or-later.

**Status:** builds, passes the CIC-6102 boot-checksum check, and passes host tests and an RTL co-simulation with the FPGA endpoint. **It has not run on an N64, an M64 or an emulator.** Design notes, evidence and limits are in [docs/design/n64-bootstrap.md](../../docs/design/n64-bootstrap.md).

## Layout

| Path | What |
|---|---|
| `src/main.c` | Menu, controller loop, mailbox access (libdragon `display`, `graphics`, `joypad`, `io_read`/`io_write`) |
| `src/sn64_mailbox.h` | Register map at `0x1FFF_0000`, the 32-bit register pairing, and the provisional STATUS bit layout, REGION_INFO/REGION_SOURCE layouts |
| `src/sn64_mapping.[ch]` | N64 to SNES mapping table and function (pure C, host-testable) |
| `rom.mk` | libdragon ROM build (runs inside the output directory) |
| `Makefile` | Entry point: `rom`, `check`, `words`, `test`, `test-negative`, `clean` |
| `tests/test_mapping.c` | Host unit test of the default mapping |
| `tests/tb_bootstrap_rom_window.sv` | Verilator bench: loads the converted image into `sn64_n64_endpoint`, reads it back over the PI model, and replays the per-frame mailbox traffic |
| `tools/setup_libdragon.sh` | Pinned, SHA-256-checked toolchain + libdragon install (no admin, no Docker, no WSL) |
| `tools/n64_cic_check.py` | CIC-6102 boot check (IPL2 hash of IPL3, ported from ares, ISC) |
| `tools/z64_to_rom_words.py` | `.z64` to FPGA ROM-window word image (`$readmemh`, big-endian 16-bit) |
| `tools/test_rom_tools.py` | Self-checking test of both tools, with `--inject-fault` |
| `tools/run_rom_window_sim.ps1` | Builds and runs the Verilator bench, then the fault-injected run |

## Build (Windows, Git Bash)

```bash
bash firmware/bootstrap/tools/setup_libdragon.sh          # once, ~1 min
export N64_INST="$(cygpath -m "$HOME")/.codex/tools/libdragon-gcc-toolchain-20260915/n64inst"
export PATH="$HOME/.codex/tools/libdragon-gcc-toolchain-20260915/n64inst/bin:$PATH"
cd firmware/bootstrap
make                 # -> build/n64-bootstrap/sn64_bootstrap.z64
make check           # CIC-6102 boot checksum
make words           # -> build/n64-bootstrap/sn64_bootstrap_words.mem (+ .json manifest)
make test HOST_CC=$HOME/.codex/tools/w64devkit-2.10.0/w64devkit/bin/gcc.exe
make test-negative HOST_CC=$HOME/.codex/tools/w64devkit-2.10.0/w64devkit/bin/gcc.exe
```

From the repository root in PowerShell, after `make words`:

```powershell
powershell -NoProfile -ExecutionPolicy Bypass -File firmware/bootstrap/tools/run_rom_window_sim.ps1
```

Build outputs stay under `build/n64-bootstrap/`. Do not commit ROM binaries.

## FPGA contract

- The ROM image needs **`ROM_ADDR_BITS = 16`** (64 Ki words = 128 KiB) with the default aPLib compression (`N64_ROM_ELFCOMPRESS=2`). It was 114,688 bytes before the console video path; with the display loop it is 131,072 bytes (exactly the 128 KiB window; the board top uses `ROM_ADDR_BITS = 17`, 256 KiB, for headroom). With libdragon's default LZ4 it is 147,456 bytes and needs 17. The endpoint's current default of 12 (8 KiB) is too small; the converter rejects the image for it.
- Word image: `word[i] = rom[2i] << 8 | rom[2i+1]`. Line *i* of the `.mem` file is `rom_waddr` *i*, with zero padding up to `2**ROM_ADDR_BITS`.
- Mailbox registers are accessed only as 32-bit pairs: `{MAGIC,VERSION}`, `{STATUS,SEQ}`, `{JOY1,JOY2}`, `{JOY1_STICK,CONTROL}`, `{COMMIT,REGION_INFO}` (COMMIT written, REGION_INFO read) and `{REGION_SOURCE,-}` (read). The bootstrap never writes unless MAGIC reads `0x534E`.
- SNES button image: bit 0 = B, then Y, Select, Start, Up, Down, Left, Right, A, X, L, R (bit 11). **1 = pressed.** Bits 15:12 are 0.

## Controls

- **Menu:** Up/Down to move, A to choose, B to go back.
- **Start SNES cartridge:** sets `CONTROL.run_request` and forwards both controllers. While the menu is shown, the SNES sees a neutral pad.
- **Returning to the menu:** hold **Z+L+R for about 1 s**. The cartridge keeps running.
- **Power down cartridge:** clears `run_request`.

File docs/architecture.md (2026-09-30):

# SN64 architecture and current implementation boundary

Engineering snapshot: 2026-09-29. The target is one adapter for original Nintendo 64 and ModRetro M64, with a complete physical SNES/SFC cartridge interface and independent recovery through the side USB-C data port. The [requirements register](requirements.md) and [acceptance matrix](../test/acceptance-matrix.csv) retain the complete specification. **A console-core resource/simulation candidate exists; a completed SN64 board, physical cartridge bridge and hardware compatibility do not.**

## Whole-product blocks

```mermaid
flowchart TB
  PC[Computer / side USB-C data] --> USB[FT232HL programmer and isolated JTAG]
  USB --> CFG[FPGA configuration and persistent flash]
  US[Qualified USB power] --> PWR[Protected source selection / system regulators]
  HOST[Original N64 or M64 cartridge interface] --> PWR
  HOST <--> ENDPOINT[N64 PI / CIC / control endpoint]
  ENDPOINT <--> MAIL[Versioned controls / configuration / telemetry]
  MAIL <--> CORE[SNES CPU / DMA / PPU / APU]
  CORE <--> MEM[WRAM / VRAM / ARAM]
  CORE <--> BRIDGE[Physical A/B bus ownership and timing bridge]
  BRIDGE <--> LEVEL[Voltage translation / shared-line interfaces]
  LEVEL <--> SLOT[Full 62-contact SNES socket]
  PWR --> SWITCH[Default-off protected cartridge 5 V]
  SWITCH --> SLOT
  MON[Hardware rail / fault veto] --> SWITCH
  MON --> LEVEL
  CLOCK[NTSC / PAL / PHI2 / CIC clock and reset control] --> CORE
  CLOCK --> LEVEL
  CORE --> AV[Video / digital audio buffering and output]
  SLOT --> ANALOG[Cartridge L/R analog audio input and conversion]
  ANALOG --> AV
  AV --> OUT[Frame and audio window over the cartridge bus]
  OUT --> HOSTOUT[Console output: M64 HDMI, N64 AV jack]
```

The arrows describe the intended system, not completed circuitry. The current block status is:

| Block | Existing evidence | Work still required |
|---|---|---|
| SNES logic and local memory | Pinned source subset, generated interface patches, synthesizable candidate and original diagnostic program. | PPU/APU/gameplay, timing, reset and compatibility validation; physical bridge integration. |
| SNES socket | Verified 62-contact map and reference footprint. | Exact socket sample/drawing qualification, translator circuitry, protected power, clocks, CIC, analog audio and physical bus implementation. See [socket selection](design/socket-selection.md) and [bridge design](design/physical-cartridge-bridge.md). |
| N64/M64 host endpoint | Pinned SummerCart64 PI/SI/CIC source and connector evidence. | Adapt and test the endpoint, bootstrap and versioned controls/configuration/telemetry protocol. Host reset and SNES reset require separate ownership. See [host interface notes](design/n64-interface-notes.md). |
| USB programming | KiCad FT232HL/MPSSE circuit with default-disabled JTAG isolation. | Blank-safe target power, exact FPGA/flash hookup, persistent-image programming, failed-update recovery and cold-boot tests. See [programming architecture](design/usb-programming-architecture.md). |
| Power/protection | Source budgets and component candidates, with unknown loads explicitly retained. | Full current/transient/thermal budget, rail sequencing, fault circuitry and measurements. Host-only play feasibility remains unresolved; no direct supply paralleling. See [power architecture](design/power-architecture.md). |
| Clocks, A/V and cartridge audio | Core RGB/timing and audio sample ports. | Oscillator/PLL implementation, regional timing, output transport, cartridge analog input conditioning/conversion/mixing, synchronization and measured latency. |
| Board and enclosure | Connector/USB circuit drafts and source-derived mechanical references. | Whole-system pin/bank allocation, PCB layout, qualified socket, complete enclosure, cable clearance and both-host fit. |

The host bootstrap will supply controller state and configuration while the FPGA runs SNES timing. Its proposed control protocol must retain buttons and analog axes, a version/build identity, stale-input handling, reset/fault status and update compatibility. No multitap is selected. Deferred virtual mouse support still needs an update path and justified capacity; lightgun support remains undecided. No throughput or latency acceptance is inferred from the block diagram.

The SNES picture and sound go to the console as frame data over the cartridge bus (PI domain 2) and the boot program shows them on the console's own output: the M64's HDMI, an original N64's AV jack ([console-video-path.md](design/console-video-path.md)). The board has no video output of its own (its HDMI port was removed on 2026-09-29). M64's reserved contacts stay isolated.

## Core reuse comparison

| Source and inspected revision | Useful reusable work | SN64 decision and limitation |
|---|---|---|
| [nand2mario/SNESTang](https://github.com/nand2mario/snestang/tree/5f0ef193145f67bded7f73f2c477ac8da4d85f7e), `5f0ef193145f67bded7f73f2c477ac8da4d85f7e` | Verilog/SystemVerilog CPU, PPU, APU and DMA; portable inferred PPU-memory branches. | Current bounded candidate. Its selected console subset builds with the evaluated Windows tools. Exclude the board wrapper, ROM loader, soft MCU and emulated cartridge maps; physical cartridges must retain responsibility for ROM, save RAM and enhancement logic. |
| [MiSTer SNES](https://github.com/MiSTer-devel/SNES_MiSTer/tree/c61bfd45171c62000417333cd4679890bcd091a6), `c61bfd45171c62000417333cd4679890bcd091a6` | Existing console implementation, compatibility fixes and a broader source reference. | Continue using as a behavioral/reference source. Its [main module](https://github.com/MiSTer-devel/SNES_MiSTer/blob/c61bfd45171c62000417333cd4679890bcd091a6/rtl/main.v) and platform wrapper contain mapped ROM/save interfaces and emulated cartridge chips; these are not physical socket ports. No equivalent SN64 ECP5 build was measured for this snapshot. |
| [m1nl/SNESTang MiSTle fork](https://github.com/m1nl/snestang/tree/c84161d134c35c15d45aeabcef3b40cbe55cf3ef), `c84161d134c35c15d45aeabcef3b40cbe55cf3ef` | Current `mistle` head inspected on 2026-09-29: ECP5/IcePi-Zero integration, SERV/QERV I/O, mixed VHDL/Verilog core, memory/HDMI/audio adaptation. | Strong portability/comparison candidate, not adopted into this build. The [README](https://github.com/m1nl/snestang/blob/c84161d134c35c15d45aeabcef3b40cbe55cf3ef/README.md) calls the port work in progress. Inspected [SNES.vhd](https://github.com/m1nl/snestang/blob/c84161d134c35c15d45aeabcef3b40cbe55cf3ef/src/SNES.vhd) and [main.v](https://github.com/m1nl/snestang/blob/c84161d134c35c15d45aeabcef3b40cbe55cf3ef/src/main.v) retain console internals behind a mapped ROM/BSRAM cartridge path; a physical bridge is still required. Its mixed-language build needs separate toolchain/resource validation. |

The current selection establishes a reproducible starting point, not superiority over the other cores or full cartridge compatibility. Evaluate an alternative against the same memory configuration, diagnostic tests and physical-bus contract before comparing area or timing. Reuse upstream fixes with a recorded diff and regression evidence.

The [vendored provenance](../fpga/vendor/snestang/provenance.json) records the upstream commit, archive hash and hashes for 35 selected files. The retained [LICENSE](../fpga/vendor/snestang/LICENSE) contains GPL version 3; preserve file notices and identify adaptations in distribution records. Hardware and firmware reference licenses are tracked separately in the [reuse record](research/reusable-designs.md) and hardware notices. The original project diagnostic contains no commercial game ROM.

## Candidate implementation

[sn64_console_candidate.sv](../fpga/rtl/sn64_console_candidate.sv) instantiates the SNES subsystem and byte-wide synchronous RAM. [prepare_core.py](../fpga/tools/prepare_core.py) verifies vendored hashes and writes generated copies, leaving upstream files unchanged. It removes diagnostic print statements, exports PHI2 and HIGH_RES, ties the unconnected TURBO input low, and exports the CPU/DMA/HDMA-selected raw address before internal WRAM mirror canonicalization. Generated-file hashes and interface changes are recorded in `build/core-preparation.json`.

| Memory | Candidate capacity | Baseline mapped DP16KD blocks |
|---|---:|---:|
| WRAM | 128 KiB | 64 |
| VRAM low/high byte banks | 32 KiB + 32 KiB | 16 + 16 |
| ARAM | 64 KiB | 32 |
| Other core memories | Microcode, PPU/APU storage | 11 |
| Total observed baseline | 256 KiB main RAM plus core storage | 139 |

Reads have one master-clock latency; writes use the core's active-low enables. The candidate does not initialize its main RAM arrays. Simulation initialization and FPGA power-up contents must not become an assumed software contract. Cartridge ROM/save storage is external to this candidate; no game image buffer or emulated save backup path replaces the inserted cartridge.

The current resource experiment measured **139 DP16KD, 26,669 LUT4, 10,775 FF and 19 multipliers** after the interface fixes. Trial routing achieved 29.91 MHz against the 21.477273 MHz internal-clock constraint, with unconstrained I/O. The [evaluation report](../fpga/reports/evaluation.md) and [machine-readable results](../fpga/reports/evaluation.json) own source fingerprints, commands, test results, warnings and route limits; this does not qualify board pins or external timing.

The [FPGA selection note](design/fpga-board-selection.md) keeps an ECP5-85F/BG381 candidate. Baseline RAM uses 139 of its 208 EBR blocks, leaving 69 before adding host logic, output buffers and all remaining integration. That arithmetic is not a reserved product budget. A 45F/external-memory alternative requires a new memory controller, synthesis, route, power estimate and latency validation. Board package/pins, rails and grade must be fixed from the complete system, not from an unconstrained core-only placement.

## Evidence and next integration boundary

The boot diagnostic exercises reset/native CPU execution, external data reads/writes, WRAM, an internal WRAM mirror's raw bus address, a B-bus write, A-to-B DMA and PHI2 activity. A separate WRAM diagnostic checks the current byte on the candidate's cartridge output during direct and mirrored RAM reads, RAM data-port reads and B-to-A DMA, plus source-valid disable with a stopped clock during pause/reset. The wrapper now selects current WRAM Q during its qualified read window; the previous output could retain a stale CPU byte. This source-valid flag is not a complete translator output enable. The [bus evidence audit](design/bus-electrical-evidence.md) records the motherboard topology supporting this change and the unresolved CPU-register drive behavior.

A run with PAL asserted uses the same testbench input-clock period; it is a mode-bit test, not PAL video, clock or compatibility acceptance. Preserve an intentionally corrupted-read run to show that the data checks fail when expected. Current results belong in the evaluation report.

Before a board-facing build, implement and test the [physical cartridge bridge contract](design/physical-cartridge-bridge.md), constrain real clocks and socket I/O timing, integrate safe rail/fault gating, and add PPU/APU and both-host tests. Static-function alias and temporary-reset synthesis warnings require recorded disposition; a clean final netlist check alone does not validate gameplay. A resource count or synthetic route cannot establish cartridge thresholds, power draw, setup/hold at the socket, safe startup, USB compliance or manufacturer readiness.

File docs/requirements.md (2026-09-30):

# SN64 requirements and acceptance register

Baseline recorded 2026-09-29 from [Engineering Specification Rev A](../SN_64_Engineering_Specification_Rev_A.docx), with the user's clarifications in the [engineering plan](superpowers/plans/2026-09-28-sn64-engineering-plan.md) and [project README](../README.md). **Every specification target remains in scope. No completed prototype, hardware acceptance, or fabrication readiness is claimed.**

The authoritative row-level register is [test/acceptance-matrix.csv](../test/acceptance-matrix.csv). It contains **136 stable IDs: 110 source-item rows covering all 18 sections, 16 explicit compatibility subclasses, and 10 user-clarification rows**. Every original paragraph/bullet is retained verbatim in `source_text`; compound clauses remain binding together and their acceptance evidence names the required checks. Section 18 rows track source provenance rather than additional product functions.

## IDs and source mapping

`SN64-SS-II` identifies source section SS and paragraph/bullet II, counted in source order beneath that heading. These item numbers are register locators; Rev A itself only numbers sections. `SN64-14-02-X5`, for example, refines §14 item 2 without replacing its parent. `SN64-U-NN` records an explicit user clarification or its recorded project interpretation. Do not reuse or renumber IDs when the design changes; record supersession and keep traceability.

| Source section | Original items covered | Base IDs |
|---|---:|---|
| 1. Product Definition | 2 | `SN64-01-01`–`SN64-01-02` |
| 2. Hard Requirements | 9 | `SN64-02-01`–`SN64-02-09` |
| 3. Architecture | 2 | `SN64-03-01`–`SN64-03-02` |
| 4. SNES Cartridge Interface | 3 | `SN64-04-01`–`SN64-04-03` |
| 5. FPGA SNES Subsystem | 4 | `SN64-05-01`–`SN64-05-04` |
| 6. N64 and M64 Host Interface | 4 | `SN64-06-01`–`SN64-06-04` |
| 7. Video and Audio | 3 | `SN64-07-01`–`SN64-07-03` |
| 8. Safety and Protection | 13 | `SN64-08-01`–`SN64-08-13` |
| 9. Firmware and Recovery | 4 | `SN64-09-01`–`SN64-09-04` |
| 10. Mechanical Design | 7 | `SN64-10-01`–`SN64-10-07` |
| 11. PCB Architecture | 3 | `SN64-11-01`–`SN64-11-03` |
| 12. Manufacturing Package | 10 | `SN64-12-01`–`SN64-12-10` |
| 13. Bring-Up Procedure | 16 | `SN64-13-01`–`SN64-13-16` |
| 14. Compatibility Certification | 2 | `SN64-14-01`–`SN64-14-02` |
| 15. Additional Requirements Worth Adding | 12 | `SN64-15-01`–`SN64-15-12` |
| 16. Rev A Success Criteria | 2 | `SN64-16-01`–`SN64-16-02` |
| 17. Known Unknowns Before Fabrication | 7 | `SN64-17-01`–`SN64-17-07` |
| 18. Source Notes | 7 | `SN64-18-01`–`SN64-18-07` |

The 16 compatibility refinements distinguish LoROM, HiROM, battery SRAM, DSP, Super FX, SA-1, S-DD1, Cx4, physical X5, physical X6, FXPAK Pro ordinary ROMs, FXPAK enhancement implementations, representative N64 revisions, PAL, M64 stock timing and M64 overclock modes. Original SNES/SFC regions and shell families are also required by §1, §2 and §10; they must be represented in the actual test inventory.

Source fingerprint: DOCX SHA-256 `9d29fa2ec6e551718fd1fb2367175e7e6764853a06179bc2e7424c8235a84581`. The extraction used for item ordering was `.local/specification.txt`, SHA-256 `01445c56e40a48ba294c58872e9a5bb71c81f2eb692aab53b0db2b78d3038780`. If an extraction conflicts with the original document, use the original document and record the correction.

## Evidence is separate from acceptance

`evidence_level` describes the strongest **partial evidence actually referenced**, not completion of the entire row:

| Level | Meaning |
|---|---|
| documented | Requirement, provenance, architecture decision or acceptance procedure recorded |
| designed | Relevant draft circuit, HDL, CAD or interface artifact exists; it may implement only part of the row |
| simulated | A reproducible passing simulation is cited with its exact tested scope and limitations |
| measured | Measurements on identified SN64 hardware are cited with instruments, conditions, limits and raw evidence |

Static schematic/footprint/CAD checks remain design evidence. They do not become electrical measurements, a USB-compliance result, cartridge compatibility or host-fit validation. A compiled simulation executable alone is not a passing simulation. A hardware measurement alone is not acceptance unless it covers the complete requirement under defined limits.

At this register snapshot (updated 2026-09-29 after the round-3 integration: power, FPGA and clock/cartridge-audio schematic sheets attached to the root, cartridge-audio simulation; the on-board HDMI output was removed later that day in favour of the console video path), **24 rows have partial simulation evidence, 39 have partial design evidence and 73 are documented; zero are measured. All 136 rows remain `NOT_ACCEPTED`.** Round 3 moved `SN64-07-01` to simulated (now evidenced by the console video path benches, `tb_frame_window` and `tb_system`, after the on-board HDMI was removed) and `SN64-17-04` to designed (A/V schematic candidate), and added power-sheet static evidence to `SN64-02-07`, `04-03`, `08-01`, `08-02`, `08-03`, `08-06`, `08-10` and `08-13`. Simulation rows cite the exact benches in `current_evidence`; they establish behaviour against models, not hardware. The referenced [30 interface checks](../hardware/sn64/validation/interface-check.json), [69 USB checks](../hardware/sn64/validation/usb-check.json), the per-sheet checks in [hardware/sn64/validation](../hardware/sn64/validation/) and [CAD validation](../mechanical/fit-references/validation.json) are useful limited design evidence.

The [preserved core evaluation](../fpga/reports/evaluation.md) and [machine-readable results](../fpga/reports/evaluation.json) support `simulated` for `SN64-05-01` through `SN64-05-03` only: a 1,336-clock diagnostic checks reset/native CPU execution, modeled external reads/writes, WRAM and its mirror address, a B-bus write, two-byte A-to-B DMA and PHI2 activity. A separate 1,089-clock regression checks current WRAM output during direct/two-mirror reads, RAM data-port reads, B-to-A DMA and reset/pause source-valid gating. It does not model physical output enables or prove bus ownership. The PAL mode-bit run uses the same 46.56 ns clock and does not qualify PAL clock/video/audio. Core synthesis and a trial internal route provide resource/timing feasibility evidence with unconstrained external I/O. Graphics, sound, HDMA, full clock/memory timing, physical bus ownership, real cartridges and whole-system operation remain unverified; no requirement is accepted by these results.

## Stage gates and scope decisions

- **Rev A:** independent digital SNES A/V, safe original-N64 and ordinary-cartridge M64 operation, representative real cartridges plus physical X5/X6/FXPAK Pro, saves, controls, fault reporting, reset/power-cycle resilience and invalid-image recovery without rework. §16 is a conjunction: all its criteria need evidence.
- **First-revision USB:** side-mounted externally accessible USB-C **data** circuitry and enclosure access are mandatory. USB enumeration, blank-target initial loading, persistent storage programming, power-off/cold-boot persistence, later updates and failed-image recovery are distinct tests. Operation must not require a working N64/M64 boot or preloaded main FPGA/MCU image. JTAG/service access remains required independently; a connector or FTDI enumeration alone does not satisfy the complete path.
- **Full target:** PAL and supported M64 single-HDMI remain required, along with every additional §15 provision and the complete compatibility inventory. NTSC-first work and independent A/V do not remove those targets. Resource reservation does not establish M64 integration.
- **Production:** complete §12 package, factory self-test, golden cartridge/fixture, lifecycle/license/branding work, pre-compliance and mechanical/thermal reliability evidence are required. §16.2 prohibits treating the design as a production candidate, reducing cost or miniaturizing before Rev A success. Later changes need affected regression checks.
- **User control decisions:** no multitap. Virtual mouse implementation is deferred, while initial analog/button transport, update path and justified capacity provision remain required. Super Scope/Justifier remain undecided; other researched accessories are not automatically selected.
- **Manufacturing route and reuse:** PCBWay is the intended PCB/assembly and enclosure provider. Reuse existing working designs with exact provenance; existing schematics or models do not automatically qualify a different device, socket or integration.

## Open interpretations and quantitative limits

These points need explicit engineering resolution; none is an implicit waiver or pass:

| Issue | Source relationship and current interpretation |
|---|---|
| Future M64 interface versus “Before Fabrication” | §6.4/§7.3 reserve a future supported path, while §17 lists that unknown under a broad pre-fabrication heading. Track it as an unresolved full-target dependency. Any prototype release decision must explicitly state its limited scope; do not claim full completion or invent a private interface. |
| PAL sequencing versus full coverage | §5 starts validation with NTSC; §14 says PAL where available. PAL implementation/qualification remains required. Record missing samples as untested and track host region, cartridge region and SNES timing mode separately. |
| Representative Rev A set versus complete matrix | §16 permits a representative milestone set; §14 supplies the broader target inventory. Define the representative set before accepting Rev A and keep all uncovered classes open for full completion. |
| Controller default detail | §6 fixes D-pad, Start→Start and Z→Select, but does not specify each face/C/shoulder assignment. Freeze a complete A/B/X/Y/L/R mapping table and test it; do not infer a unique mapping from the prose. |
| Clock and peripheral completeness | SYSTEM CLK, PHI2 and REFRESH are real socket signals in the verified map. All outer contacts, EXPAND, shared reset/CIC behavior and L/R analog input handling remain required; a 62-hole count is insufficient. |
| Power available from either host | Host limits, cartridge loads and exact FPGA demand are not specified. The M64 limiter annotation is not a guaranteed system budget. Determine whether supplemental USB play power is required and supported; initial USB programming power must work independently. |
| Conditional implementation choices | BRAM is preferred where practical; external RAM requires characterized deterministic timing. A multilayer PCB is mandatory, but the source permits a justified four-layer design and prefers six where beneficial. Alternates are required where possible, with no assumed pin-compatible substitutes. |

The source gives few numeric performance or abuse-test limits. Define, review and version the following before their acceptance runs; candidate numbers from design notes are not source requirements or universal manufacturer guarantees.

| Owner | Limits/protocol still to freeze |
|---|---|
| Power/protection | Rail windows/ripple, source margin, inrush/peak/steady load, trip and discharge timing, reverse leakage and power-order cases |
| Signal integrity/clocks | Logic levels/leakage, OE/DIR dead time, setup/hold, frequency/jitter/duty, overshoot/ringing/edges and representative loading |
| Firmware/A/V | Controller update/latency/stale-input handling; output formats, frame/dropout/synchronization and cartridge-audio mixing/clipping/noise criteria |
| Reliability/save integrity | Cold/warm/power-cycle counts, extended-runtime duration, fault/brownout profiles, interruption phases and byte/state comparison method |
| Mechanical/thermal | Fit/cable/eject clearances, insertion/extraction forces, cycles, side load/wobble/permanent set, ambient/load range and thermal margin |
| EMC/ESD | Test setup, operating modes, levels/limits, acceptable recovery and remediation/retest criteria |

For example, the provisional 4.75–5.25 V window in a candidate power note is not certified as every cartridge's allowed supply range. Freeze the actual device/system tolerance budget before using any such window as a pass criterion.

## Required acceptance-run records

The CSV is the acceptance **plan/register**, not a fabricated log of completed runs. Each later run should record:

- Run ID/date/operator and linked requirement IDs; hardware revision, FPGA build ID, firmware/tool/source hashes and image versions.
- Host model/motherboard revision/region/firmware, M64 stock or exact overclock setting, cartridge title/board/chip/region, and flashcart hardware/firmware/core/SD details.
- SNES NTSC/PAL mode separately from host and cartridge region; supply source, enclosure configuration, ambient/load and instrument/probe settings.
- Versioned procedure and predeclared limits, repetitions/runtime, raw captures/measurements/save comparisons, and per-check pass/fail/not-run results. “Not applicable” needs a reason.
- All eight §14.1 outcomes for each applicable target pair: cold boot, warm reset, controls, video, audio, saves, cartridge reset and extended runtime.
- Fault/recovery state, anomalies, follow-up fixes and the exact evidence reviewed for acceptance.

Preserve §13 ordering: unpowered inspection, isolated current-limited bench power, rails/safe image, host fixture, dummy cartridge load, clocks/buses, diagnostic ROM, progressively more capable real cartridges, both hosts, and fault injection before extended compatibility testing. Do not attach valuable host/cartridge hardware before the fixture and protection checks that precede it.

Coverage verification for this revision checks unique IDs, all 110 original source items represented with matching source text, all 16 compatibility subclasses and all 10 user entries, and no accepted/measured row without evidence. This is a completeness check of the register, not verification of SN64 hardware.

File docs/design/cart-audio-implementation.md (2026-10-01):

# Cartridge analog audio into the console audio stream

Snapshot 2026-09-29. Some SNES cartridges put their own sound on socket pins 31/32: MSU-1 music on the FXPAK Pro, and a few coprocessor boards. This block adds that sound to the SNES core's sound before it goes to the console ([console-video-path.md](console-video-path.md)).

**Status: simulated and synthesised only.** It has run in Verilator and also in Icarus, which is four-state and therefore able to see unknown (X) values. Nothing has run on hardware. The ADC part number, its oscillator and the analog front end belong to the clock/A-V schematic sheet and are not chosen here.

## Plain-language summary

A small converter chip (the ADC) on the board turns the cartridge's left and right audio into numbers, 32,000 times a second. It runs on its own crystal and sends those numbers over three wires in the standard I2S format.

The FPGA listens on those wires with a fast clock, about 30 times faster than the ADC's bit clock. It picks out each 24-bit left/right pair. It adds the pair to the SNES core's own sound, and the result goes into the frame window's audio ring, which the console reads over the cartridge bus.

The two sounds are made by different clocks, so one side always runs a tiny bit faster than the other. A short waiting line (8 samples) absorbs the difference. When the line runs completely full or completely empty, one cartridge sample is skipped or played twice. At the ±500 ppm offset tested here that happens about 16 times a second, and each one is a single sample.

If both sounds are loud at the same instant, the sum is clipped at full scale. It never wraps around into a loud click.

## Files

| File | Role |
|---|---|
| [fpga/rtl/sn64_i2s_rx.sv](../../fpga/rtl/sn64_i2s_rx.sv) | I2S slave receiver. BCK/LRCK/DOUT are oversampled by a fast clock (`clk_host`, 62.5 MHz). It detects edges, extracts the words and checks framing. |
| [fpga/rtl/sn64_audio_mix.sv](../../fpga/rtl/sn64_audio_mix.sv) | Toggle crossing into `clk_snes`, 8-frame elastic buffer with one-sample slips, and saturating mix into the DSP stream. |
| [fpga/rtl/sn64_top.sv](../../fpga/rtl/sn64_top.sv) | New ports `adc_bck`, `adc_lrck`, `adc_dout`. The receiver runs on `clk_host` and the mixer sits between the core's audio and `sn64_av_out`. |
| [fpga/tests/tb_audio_mix.sv](../../fpga/tests/tb_audio_mix.sv) | Self-checking bench: an asynchronous I2S master at a chosen ppm offset, and an SNES sample stream. It also holds the four fault builds. |
| [fpga/tests/tb_system.sv](../../fpga/tests/tb_system.sv) | Whole-system check: an I2S master on the new ports, with the mixed audio checked at the input of `sn64_av_out`. |

Both RTL files are original SN64 code, GPL-3.0-or-later. No suitable open I2S-slave-with-elastic-buffer block was found to reuse:

- SNESTang's HDMI audio path resamples through a FIFO. [av-output-implementation.md](av-output-implementation.md) records why that was rejected.

## Signal path

```text
 ADC (I2S master, own oscillator)          clk_host 62.5 MHz                     clk_snes 21.48 / 21.28 MHz
 BCK 2.048 MHz, LRCK 32 kHz, DOUT  ──►  sn64_i2s_rx: 3+2-stage synchronisers, ──► sn64_audio_mix: toggle sync ──► FIFO (8) ──┐
                                        BCK-rise detect, 24-bit L/R, framing     (frame held 31 us)                            │
 SNES core DSP: audio_left/right, audio_ready (1 pulse per sample) ───────────────────────────────────────────► sat16(snes + cart)
                                                                                                                   │
                                                                                 sn64_av_out (audio port unchanged) ◄┘
```

## Board ADC (from the clock/audio sheet)

- ADC: **PCM1808** in I2S master mode at 384 fs from its own 12.288 MHz oscillator, 24-bit I2S, BCK = 64 fs = 2.048 MHz ([av-clock-schematic.md](av-clock-schematic.md)).
- TI SLES177B section 6.6 master-mode timing: BCK high/low >= 65 ns; t(CKLR) and t(CKDO), BCK falling edge to LRCK/DOUT valid, -10 to +20 ns; t(LRDO) -10 to +20 ns; rise/fall <= 20 ns.
- Level: ADC full scale (0.6 x VCC = 3.0 Vp-p at VINx) corresponds to 6.0 Vp-p at the socket contact (network gain 0.500). An sd2snes-class source sits at about -20.6 dBFS. The console mixes cartridge audio and S-DSP with equal 10 k weights (OpenSFC R62/R55 vs R60/R61), so the digital mix gain needs the S-DSP's analog level: open.

## Sources

- **I2S format and timing.** Philips Semiconductors, "I2S bus specification", February 1986, revised 5 June 1996. The copy came from the Internet Archive capture of `nxp.com/acrobat_download/various/I2SBUS.pdf`, downloaded 2026-09-29, 61,326 bytes, SHA-256 `8b745bc8e8a3d8da17e982477411ddf20c627edd557a84c2e7a6c5647ed97bda`, saved as `build/r3-audio/refs/philips-i2s-bus-spec-1996.pdf` (untracked). The current NXP UM11732 link returned "page not available". Facts used:
  - two's complement, MSB first;
  - the MSB is sent one clock period after WS changes;
  - WS = 0 is left;
  - the receiver latches on the rising (leading) SCK edge;
  - the transmitter's delay is tdtr ≤ 0.8T and its hold is thtr ≥ 0;
  - master-mode SCK HIGH and LOW are each ≥ 0.35T (Table 1 and notes 2a, 3, 4).
- **Task inputs, not re-derived here.** fs = 32 kHz nominal, 24-bit Philips I2S, BCK = 64 fs, and the ADC as I2S master on its own oscillator come from the round's system contract. The ADC part is not yet selected, so its tDO, duty and word length must be checked against the table below once it is.
- **SNES DSP sample rate.** Taken from the pinned SNESTang core (`build/generated/snestang/src/dsp.v`, `CEGen.v`, `dsp.vh`, prepared by `fpga/tools/prepare_core.py`):
  - `CEGen` fires at `f_master × ACLK_FREQ / 2147730`, with `ACLK_FREQ = 411904`;
  - `SND_RDY` fires once per 32 steps × 4 substeps = 128 CE.

## Receiver: why the sampling point is safe

The I2S lines are not used as clocks. All three pass through identical flip-flop chains clocked by `clk_host`, which is 16 ns and always on. A BCK rising edge is detected at stage 2, the first sample that is high after one that is low. SD and WS are taken `DATA_LAG = 2` captures before the capture that first saw BCK high.

| Quantity (T = 1/(64 × 32 kHz) = 488.3 ns) | Value | Source |
|---|---:|---|
| SD/WS guaranteed valid before a rising edge (tdtr ≤ 0.8T, thtr ≥ 0) | last 0.2T = 97.7 ns | I2S spec, Table 1 |
| When the lagged capture was taken | 16 to 48 ns before the edge (includes one clock of metastability uncertainty) | design |
| Margin, early side | 97.7 − 48 = **49.7 ns** | |
| Margin, late side | **16 ns** (one full clock before the edge) | |
| SCK HIGH/LOW minimum (0.35T) versus the sampling period | 170.9 ns = 10.7 clocks, so no edge is missed | I2S spec, Table 1 |
| The same arithmetic at `clk_snes` (46.6 ns) | lag window 140 ns > 97.7 ns: **does not fit** | why `clk_host` is used |

A converter that changes data on the falling edge, as most do, has far more margin (about T/2 − tDO before the rising edge). The bench does not rely on that. After every rising edge its model changes SD/WS at a random time anywhere in the specification's window, [1 ns, 0.78T]. The fault build `SN64_FAULT_I2S_LATE_SAMPLE` takes SD/WS from the same capture as BCK, which is up to 16 ns after the edge, and the bench rejects it.

**Framing.** Every slot must be exactly 32 BCK periods (64 fs). The first rising edge after a WS change carries the previous slot's last bit; the next 24 edges carry the word. A frame (left, then right) is delivered only if the slots before and between the words had full length. `locked` needs 2 good frames and drops on any bad slot. `frame_errors` counts bad slots, saturating.

## Elastic buffer and slip policy

Each frame the receiver completes flips `frame_tog`, and the words are held for a whole frame (31 µs). The mixer synchronises the toggle with two flops, then writes the held words into an 8-entry FIFO in `clk_snes`.

- **Priming.** Reading starts when the FIFO is half full (4 frames). Cartridge latency is therefore about 125 µs, which is negligible.
- **One output per SNES sample.** Each `audio_ready` rising edge pops one frame and emits one mixed sample one clock later. The SNES stream is never delayed, dropped or repeated.
- **ADC faster.** If the FIFO is full and nothing is popped on that clock, the incoming frame is dropped (overflow slip).
- **ADC slower.** If the FIFO is empty at a pop, the previous frame is repeated (underflow slip).
- **Slip rate.** Slips occur once per 1/|Δf| samples. They do not come in bursts, because the synchroniser can only move a frame by one clock, so the next event order cannot change twice in a row.
- **Checks.** The bench checks that no two slips are adjacent and that the gap between slips is at least half the gap the rate predicts.
- **Reset and lock loss.** With `cart_enable` low, core reset, or the ADC not locked, the FIFO is flushed and the SNES samples pass through bit-exact.

### Rates, and a finding about the pinned core

| SNES clock | Core DSP sample rate with the pinned `ACLK_FREQ = 411904` | Offset vs a 32,000 Hz ADC | One cartridge-sample slip every |
|---|---:|---:|---:|
| NTSC 21.477272 MHz | 32,179.96 Hz | +5,624 ppm | 5.6 ms (repeats) |
| PAL 21.28137 MHz | 31,886.43 Hz | −3,549 ppm | 8.8 ms (drops) |

The SNESTang default makes the DSP 0.56 % fast. `dsp.vh` keeps the original 409600 commented out. SNESTang also derives the CE from an NTSC constant in both regions. A 32 kHz ADC therefore slips about 180 times a second on NTSC, not the few times a second that crystal tolerances alone would cause.

`tb_system` sees this directly on the real core. Its run slips the cartridge stream 2 to 3 times in about 1,000 samples (repeats), as the table predicts.

- **Scope of the finding.** The mixer handles it correctly: it is tested at the SNESTang rate (`+snes_rate=32180`). It is still an audible-quality question for MSU-1 music.
- **Not changed here.** The DSP rate is a core-configuration decision. See the open items.

**Resolved 2026-09-29.** `fpga/tools/prepare_core.py` now patches the generated core back to the original rate: `ACLK_FREQ = 409600` (the value SNESTang keeps commented out as "original snes frequency") and a CE divider that uses the region's own master clock (`PAL ? 2128137 : 2147727`, as MiSTer `DSP.vhd` line 238 does). The DSP then runs at 4.096 MHz / 128 = **32,000 Hz in both regions**, matching the ADC and the HDMI channel status; the only remaining slips come from crystal tolerance (tens of ppm, a slip every several seconds). The `+snes_rate=32180` bench runs are kept as a stress test of the slip path. The table above records the pinned core's behaviour before the patch. After it, `tb_system` NTSC runs show 0 slips; the PAL runs show about 8 overflow slips per run because the bench's PAL master is 21.04 MHz (chosen for an exact 432/341 pixel ratio), 1.1 % below the real 21.28137 MHz, which makes the simulated DSP 1.1 % slower than the 32 kHz ADC model. That is a bench artefact, not a design rate.

## Mix, gain and headroom

`out = sat16(snes + cart_scaled)`, where `cart_scaled = (adc × CART_GAIN_Q12) >>> 20`, an arithmetic shift, i.e. floor.

- **Gain.** `CART_GAIN_Q12` is unsigned Q4.12; 4096 = 1.0, the default. At 1.0 an ADC full-scale word maps to 16-bit full scale (`adc[23:8]`) and no multiplier is synthesised. Any other value costs a MULT18X18D pair per channel.
- **Headroom.** The core's DSP output is already clamped to 16 bits (`CLAMP16` in `dsp.v`). The sum can reach twice full scale, so there is **0 dB of headroom** for coincident full-scale peaks. The output saturates at +32767 / −32768 and never wraps. The bench exercises this on more than 150 samples per run (more than 1,400 in the long runs), and the `SN64_FAULT_AUDIO_WRAP` build is rejected.
- **Why not −6 dB on both.** That would make clipping impossible but would lower every game by 6 dB and drop one bit of DSP resolution for the rare cartridge that has its own audio.
- **PROVISIONAL.** The gain of 1.0 is a placeholder. The correct value depends on the analog front end (cartridge line level versus ADC full scale, clock/A-V sheet) and on the level of cartridge audio relative to the DSP on a real console. Neither has been sourced or measured. Measure both on the prototype before fixing it.

## Verification

Commands, from the repo root with the tool environment in `CLAUDE.local.md`. `evaluate.py --mode sim` runs all of these.

```powershell
verilator_bin --binary --timing --build-jobs 4 -Wno-fatal --top-module tb_audio_mix --Mdir %USERPROFILE%/.claude/projects/SN64/build/r3-audio/mix fpga/rtl/sn64_cdc.sv fpga/rtl/sn64_i2s_rx.sv fpga/rtl/sn64_audio_mix.sv fpga/tests/tb_audio_mix.sv
build/r3-audio/mix/Vtb_audio_mix.exe +adc_ppm=500
build/r3-audio/mix/Vtb_audio_mix.exe +adc_ppm=-500 +duty=35
build/r3-audio/mix/Vtb_audio_mix.exe +adc_ppm=0 +snes_rate=32180
# fault builds: add +define+SN64_FAULT_AUDIO_SWAP_LR | SN64_FAULT_AUDIO_NO_SIGNEXT | SN64_FAULT_AUDIO_WRAP | SN64_FAULT_I2S_LATE_SAMPLE (each must FAIL)
iverilog -g2012 -o build/r3-audio/iv/tb_audio_mix.vvp -s tb_audio_mix fpga/rtl/sn64_cdc.sv fpga/rtl/sn64_i2s_rx.sv fpga/rtl/sn64_audio_mix.sv fpga/tests/tb_audio_mix.sv
vvp -n build/r3-audio/iv/tb_audio_mix.vvp +adc_ppm=0 +snes_rate=32180
```

### What the bench checks

- **Integrity.** Every output equals `sat16(snes + adc[23:8])` for a single ADC frame *n*, the same *n* on L and R. That covers pairing, sign, truncation and gain.
- **Sequence.** *n* advances by exactly one per SNES sample except at a slip.
- **Slip direction and count.** Only drops when the ADC is faster and only repeats when it is slower, with at least two per run. The net count must agree with the rate offset to within half the buffer ±2, and the DUT's own counters must agree.
- **Second mixer.** A second mixer with gain 0.5 is checked on the same frames.
- **Other checks.** At least 10 saturating outputs, exactly one output per SNES sample, and `$isunknown` on every output.

### Results, 2026-09-29, this snapshot

| Run | Result |
|---|---|
| `+adc_ppm=500` | PASS: 14,785 outputs bit-exact, **3 drops, 0 repeats**, min gap 2,079 (rate implies 2,076), 1,454 saturated, 0 framing errors |
| `+adc_ppm=-500 +duty=35` (BCK high 35 %, the specification minimum) | PASS: 13,764 outputs, **0 drops, 5 repeats**, min gap 1,927 (1,930), 1,449 saturated |
| `+adc_ppm=0 +snes_rate=32180` (pinned SNESTang NTSC rate) | PASS: 1,503 outputs, 0 drops, **6 repeats**, one every 178 samples as predicted, 152 saturated |
| same run, Icarus `vvp` (four-state) | PASS with identical counts, no X on any output |
| `SN64_FAULT_AUDIO_SWAP_LR` | **FAIL as required**: output 6 `L=ce19 R=8eb6` matches no ADC frame |
| `SN64_FAULT_AUDIO_NO_SIGNEXT` | **FAIL as required**: negative cartridge words come out as `7fff` |
| `SN64_FAULT_AUDIO_WRAP` | **FAIL as required**: `snes 7d00 + cart` gives `da07` instead of `7fff` |
| `SN64_FAULT_I2S_LATE_SAMPLE` | **FAIL as required**: bit errors (for example `R=3b6b`, expected `3b5b`) when SD changes within 16 ns after the edge |
| `tb_system`, all four runs (default, `+pal_header`, `+pal_key +ntsc_header`, `+ntsc_key +pal_header`) | PASS: 997 to 1,098 samples at `sn64_av_out` equal `sat16(DSP + ADC word)` after 3 priming samples, 0 wrong, 0 framing errors, 2 to 3 underflow slips at the core's real rate |

### Synthesis

Yosys, OSS CAD Suite 20260928, `synth_ecp5`, `check -assert` gives 0 problems for both:

- **`sn64_i2s_rx`:** 58 LUT4, 147 FF, 25 CCU2C.
- **`sn64_audio_mix`:** 208 LUT4, 112 FF, 50 CCU2C, 8 TRELLIS_DPR16X4 (the FIFO; the 8 LSBs the gain-1.0 mix never uses are trimmed), and no multiplier.

Logs: `build/r3-audio/synth-*.log`, untracked. Not yet in a place-and-route run: `route_top.py` needs the two new files (integration edit).

## Limits and open items

1. **Hardware.** The ADC part, its oscillator, tDO and BCK duty, the analog front end, and the grounding against FPGA noise all belong to the clock/A-V sheet. Check them against the sampling table above once chosen.
2. **SNES DSP rate (decision needed, not made here).** With the pinned `ACLK_FREQ = 411904`, cartridge audio slips every 5.6 ms (NTSC) or 8.8 ms (PAL). Options:
   - restore 409600, the original 32.000 kHz, in the generated core copy, and make the CE input constant region-correct;
   - or choose the ADC oscillator to match the core.

3. **Gain and headroom** are provisional (see above). Consider making `CART_GAIN` a menu setting through the mailbox if cartridges differ.
4. **Telemetry.** `adc_locked`, `frame_errors` and the slip counters exist in `sn64_top` but are not yet in the mailbox. They are useful for a diagnostics page.
5. **No glitch filter on BCK.** A noise spike longer than one 16 ns sample would be taken as an edge. The framing check then drops lock until two clean frames arrive. Revisit after board layout.
6. **Slip audibility.** A single-sample repeat or drop is inaudible on most material at the crystal-tolerance rate. At the SNESTang rate offset it may be audible on sustained tones. A fractional resampler would remove it, at the cost of logic and a multiplier.

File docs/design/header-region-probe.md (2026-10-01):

# ROM-header region probe

Snapshot 2026-09-29. Region fallback for cartridges that have no key CIC or whose key does not pass. **Simulated and synthesised only; nothing here has run on hardware.** It is not yet wired into `sn64_top.sv`: the integration edits are listed below and were checked on a scratch copy of the top level only (see "Integration trial").

| File | What it is |
|---|---|
| [fpga/rtl/sn64_header_probe.sv](../../fpga/rtl/sn64_header_probe.sv) | `sn64_header_probe` (clk_25 state machine) and `sn64_header_probe_mux` (socket owner mux) |
| [fpga/tests/tb_header_probe.sv](../../fpga/tests/tb_header_probe.sv) | Self-checking bench: cartridge models, strobe timing, safety monitors, fault injection |

## Plain-language summary

A real SNES starts at one speed for NTSC and a slightly different one for PAL. SN64 must choose before the SNES clock starts, and the clock never changes afterwards ([clock plan](clock-plan.md)). The cartridge's key chip usually says which region it is. When there is no key chip, SN64 now reads the cartridge's name tag (the ROM header) instead. ROM chips answer without a clock, so the FPGA can put an address on the socket, pull the "ROM select" and "read" lines low, and read the byte back. It reads the 32-byte header twice, and trusts it only if both reads match, the built-in checksum pair agrees, and the map-mode and country bytes are known values. If anything looks wrong, it falls back to NTSC. It never drives the data lines, never writes, never touches the reset line, and lets go of the socket the instant its permission is withdrawn.

## Where it sits

```text
          clk_25 domain                              clk_snes domain (stopped during the probe)
 seq_state, rails, !snes_clk_run ──► hdr_permit       sn64_console_with_bridge ──► br_* outputs
                                        │                                                │
                          sn64_header_probe ──► hdr_* ─────► sn64_header_probe_mux ◄─────┘
                                        │                           │  (bridge_permit selects the bridge)
                   header_valid/pal ───►│ region decision           ▼
                                                              socket pads / translator /OE, DIR
```

The mux owns the pads. The bridge drives them only while `bridge_permit` is high. The probe drives the address/strobe octets only while its own permit is high and the bridge is not permitted. Otherwise every translator is released. `/RESET` does not go through the mux; it stays with the power sequencer, which holds it low for the whole probe window.

## Header format (sources)

- fullsnes, "SNES Cartridge ROM Header", <https://problemkaputt.de/fullsnes.htm>, downloaded 2026-09-29, 1,524,441 bytes, SHA-256 `3853b65a7331bf12eea431ff494a2948a1c78ef22f7e819db4b139fd5a79f6c6`. The header is "mapped to 00FFxxh in SNES memory"; in ROM images it sits at 007Fxxh (LoROM), 00FFxxh (HiROM) or 40FFxxh (ExHiROM).
- SNESdev wiki, "ROM header", <https://snes.nesdev.org/wiki/ROM_header>, read 2026-09-29 (the raw page is behind a bot check, so no hash). It gives the same field offsets, the `001smmmm` map-mode layout, map modes 0/1/2/3/5/A and the ExHiROM location. Its region table lists names but no video standard for $0D-$10, so the NTSC/PAL column below is taken from fullsnes.

| Address | Field | Used for |
|---|---|---|
| `$FFD5` | Map mode: bits 7-6 = 0, bit 5 = 1, bit 4 = speed, bits 3-0 = map mode (0 LoROM, 1 HiROM, 2 S-DD1, 3 SA-1, 5 ExHiROM, A SPC7110) | Validity |
| `$FFD9` | Country code, which implies NTSC or PAL | Region |
| `$FFDC-$FFDD` | Checksum complement, little-endian, = checksum XOR `$FFFF` | Validity |
| `$FFDE-$FFDF` | Checksum | Validity |

ExHiROM: CPU bank `$00` upper half shows ROM `$40xxxx`, where the ExHiROM header lives, so reading `$00:FFC0` covers all three maps. The optional second read at `$40:FFC0` is therefore not implemented. Only two JP games use ExHiROM, and neither has a real cartridge in the test plan yet.

### Country code to region (fullsnes, "Country (also implies PAL/NTSC) (FFD9h)")

| Code | Country | Region used |
|---|---|---|
| `$00` | Japan / International | NTSC |
| `$01` | USA and Canada | NTSC |
| `$02` | Europe, Oceania, Asia | PAL |
| `$03` | Sweden/Scandinavia | PAL |
| `$04` | Finland | PAL |
| `$05` | Denmark | PAL |
| `$06` | France (SECAM, 50 Hz) | PAL |
| `$07` | Holland | PAL |
| `$08` | Spain | PAL |
| `$09` | Germany, Austria, Switzerland | PAL |
| `$0A` | Italy | PAL |
| `$0B` | China, Hong Kong | PAL |
| `$0C` | Indonesia | PAL |
| `$0D` | South Korea | NTSC |
| `$0E` | "Common (?)" | not trusted |
| `$0F` | Canada | NTSC |
| `$10` | Brazil (PAL-M, 60 Hz NTSC-like timing) | NTSC |
| `$11` | Australia | PAL |
| `$12-$14`, `$15+` | "Other variation (?)" / undefined | not trusted |

An untrusted code makes the header invalid, and the top falls back to NTSC.

## Validation

`header_valid` is 1 only if **all** hold:

1. **Stable bus**: the 32 bytes read the same on two full passes. This rejects a floating data bus (no cartridge, or a cartridge that is not answering).
2. **Checksum pair**: `complement XOR checksum == $FFFF`.
3. **Map mode**: bits 7-5 = `001`, and the mode is one of 0, 1, 2, 3, 5, A.
4. **Known country**: one of the codes in the table above that has a region.

`reject[3:0]` reports which checks failed, as `{unstable, checksum, map, country}`, and `header_country` and `header_map` report the raw bytes for telemetry. An abort (permit lost mid-probe) gives `done=1, aborted=1, header_valid=0`.

Known consequence: homebrew often carries `0000/0000` or `FFFF/0000` in the checksum fields (fullsnes). Such carts fail check 2 and run NTSC unless the menu forces PAL.

## Bus timing (clk_25, 40 ns per cycle, defaults)

| Step | Cycles | Time | Requirement |
|---|---|---|---|
| Translators enabled at idle levels before the first address | 4 | 160 ns | Translator enable time |
| Address valid before `/ROMSEL` falls | 2 | 80 ns | ≥ 50 ns setup |
| `/ROMSEL` low before `/RD` falls | 1 | 40 ns | `/RD` nested inside `/ROMSEL` |
| `/RD` low | 10 | 400 ns | ≥ 200 ns (slow mask ROM, fullsnes `FFD5h` bit 4: "Slow 200ns") plus translator delays |
| Data sampled (two-flop synchroniser, captured at the end of `/RD`) | | 320 ns after `/RD` fell, 440 ns after the address | Data stable long before sampling |
| `/RD` high before `/ROMSEL` rises | 1 | 40 ns | |
| Both strobes high, address held, before the next address | 3 | 120 ns | Full release; ROM output float time |

That is 17 cycles per byte and 64 reads (two passes), about 44 µs per cartridge power-up. With 64 reads the probe finishes long before the 300 ms region timeout.

## Safety rules and how they are enforced

| Rule | Mechanism | Checked by |
|---|---|---|
| D0-D7 never driven | The mux forces `data_dir = 0` (cartridge to FPGA) while the probe owns the pads; the probe's data enable is listen-only, from `/ROMSEL` fall to `/ROMSEL` rise | Bench monitor, every ns |
| Drive only with permission | Every enable and strobe is `permit AND register`, combinationally | "socket enabled without permit / with no owner" monitors |
| Release immediately when permit drops | Combinational gate; the state machine then aborts on the next clk_25 edge and never restarts in the same enable window | Permit dropped mid-`/RD` (not on a clock edge): released 1.0 ns later (monitor resolution), well inside the one-cycle (40 ns) limit |
| Never assert `/WR`, `/PWR` | The mux ties `/WR`, `/PWR`, `/PARD`, `/WRAMSEL` high, `PA=$FF`, and `REFRESH`, `PHI2`, `SYSTEM_CLK` low while the probe owns | Bench monitor |
| Never touch `/RESET` | No `/RESET` port. The top only permits the probe while the sequencer holds `/RESET` (`seq_reset_pull`) | Integration trial monitor (`tb_system` copy) |
| Bridge and probe never both own | The probe permit includes `!bus_permit` and `!snes_clk_run`; the mux gives the bridge priority | Bench mux check |
| Stale bridge data-octet state after the SNES clock stops | The mux passes bridge `data_oe_n`/`data_dir`/`ctl_oe_n` only while `bridge_permit` is high | Bench: stale `data_dir=1, data_oe_n=0` with the bridge not permitted is blocked |

**Finding (bridge, not changed here):** in [sn64_cart_bridge.sv](../../fpga/rtl/sn64_cart_bridge.sv), `data_oe_n` and `data_dir` come from `drive_q`/`listen_q`, which are cleared only on a `clk_snes` edge. `ctl_oe_n` is gated by permit combinationally, but the data octet is not. When the sequencer shuts down, `snes_clk_run` falls one clk_25 cycle after `bus_permit`, so the board clock gate may stop `clk_snes` before an edge clears a driving `drive_q`. That would leave D0-D7 driven toward a cartridge that is powering down. The mux gate above closes this at the top level. A direct fix in the bridge (`data_oe_n = !((drive_q || listen_q) && permit)`) is still recommended. Not reproduced in `tb_system`; this is a code-review finding.

## Region decision priority (in `sn64_top`)

**Forced mode > passing key CIC > valid ROM header > NTSC default.**

- Forced (menu NTSC/PAL): the probe is not enabled at all (`hdr_enable` requires auto mode). `sn64_clock_init` already gives the forced mode priority.
- Passing key: `cic_region_valid` decides at once, and the header result is ignored.
- Otherwise, the decision waits until the key has settled (failed, or the region timeout expired) **and** the probe is done (or the timeout expired). Then `det_pal = header_valid ? header_pal : 0`.
- `det_valid` is now asserted for the NTSC default too. Before this, an absent key left `sn64_clock_init` holding whatever region the previous cartridge had used, because it keeps `region_pal` when `detected_valid = 0`.

## Tests run (2026-09-29, this snapshot)

Commands, from the repo root, after the tool environment in `CLAUDE.local.md`:

```powershell
verilator_bin --binary --timing --build-jobs 4 -Wno-fatal --top-module tb_header_probe --Mdir %USERPROFILE%/.claude/projects/SN64/build/hdrprobe-sim fpga/rtl/sn64_header_probe.sv fpga/tests/tb_header_probe.sv
build/hdrprobe-sim/Vtb_header_probe.exe
# fault builds (each must FAIL): add +define+SN64_FAULT_SKIP_CHECKSUM or +define+TB_SHORT_ACCESS
yosys -Q -T -p "plugin -i slang; read_slang --top sn64_header_probe fpga/rtl/sn64_header_probe.sv; scratchpad -set abc9.xaiger 1; synth_ecp5 -top sn64_header_probe -json build/hdrprobe-sn64_header_probe.json; stat; check -assert"
```

| Run | Result |
|---|---|
| Normal bench | **PASS**. Accepted LoROM US (valid, NTSC, `$01`), HiROM EU (valid, PAL, `$02`, with a LoROM-looking decoy at the wrong offset) and South Korea (`$0D`, NTSC). Rejected, with the expected `reject` bits: corrupted checksum pair (`0100`), unknown country `$0E` (`0001`), bad map mode (`0010`), absent cartridge pulled up (`0111`), pulled down (`0110`) and floating (unstable bit set). Also checked: 576 reads with minimum address→`/ROMSEL` 80 ns, `/RD` low 400 ns, `/ROMSEL` high gap 200 ns; no D-bus drive, no `/WR`/`/PWR`; permit drop released in 1.0 ns and gave an aborted, invalid result with no restart; permit without enable drives nothing; the result clears when enable drops; stale bridge state blocked; the bridge wins over the probe. |
| `+define+SN64_FAULT_SKIP_CHECKSUM` | **FAIL** as required: the corrupted checksum is accepted (`header_valid=1 expected 0`). Floating and absent buses are still rejected by the other checks. |
| `+define+TB_SHORT_ACCESS` (`/RD` 120 ns) | **FAIL** as required: every valid cartridge reads garbage bytes (the ROM model returns correct data only after 214 ns), and the timing check reports `/RD` low < 200 ns. |
| Yosys ECP5 synthesis | `sn64_header_probe`: 399 LUT4, 323 TRELLIS_FF (256 of them hold the header bytes), 61 PFUMX, 18 L6MUX21, 7 CCU2C. `sn64_header_probe_mux`: 45 LUT4. `check -assert`: 0 problems. |

The cartridge models are behavioural: a mask ROM with one lumped 214 ns access delay (200 ns plus two 7 ns translator hops, an assumption, not a measured value), ideal translators, and no analog levels. The absent-cartridge "floating" model is random data, not a physical model of the SN74LVC4245A with an open A side.

## Integration trial

The integration edits were applied to scratch copies of `sn64_top.sv` (as of 2026-09-29 18:08, which already includes the HDMI output) and `tb_system.sv`, not to the repo files. They were built with the full `evaluate.py` system source list plus `fpga/rtl/sn64_header_probe.sv` (build dir `build/hdrprobe-integ-system`; the diffs are in `build/hdrprobe-integ-system-patches/`). The `tb_system` copy adds: probe ownership accepted by the "no socket drive without permission" invariant; a new invariant that while the probe owns the socket there is no `/WR`/`/PWR`, no D-bus drive, no running SNES clock and `/RESET` is held; an optional EU header at `$00:FFC0` (`+pal_header`); and a check that the region at clock start matches the header (PAL) or the NTSC default.

| `tb_system` run | Result |
|---|---|
| Default cartridge (no header at `$00:FFC0`, the bus reads `$00`) | **PASS**, STATUS `0x545F` (same as the baseline). Probe `done=1 valid=0 reject=0110`, so the NTSC default was used. |
| `+pal_header` (EU `$02`, valid checksum pair) | **PASS**, STATUS `0x54DF` (PAL bit set). Probe `done=1 valid=1 pal=1 country=02`. The SNES program ran and the region did not change while the clock ran. |

This trial does not replace running `evaluate.py --mode sim` after the real merge.

## Limits and open items

1. **Hardware**: nothing measured. Check real mask-ROM, MAD-1 decoder and translator timing, and the floating-bus behaviour with no cartridge, on the prototype.
2. **Cartridges that do not answer in reset or without a clock**: the probe runs with `/RESET` held and no SYSTEM_CLK. Coprocessor boards whose ROM is reached through the coprocessor (for example SA-1), and flashcarts that are still booting (FXPAK Pro / Super EverDrive load their FPGA from SD), may return garbage or their menu header. Validation fails closed (NTSC), or reports the flashcart menu's own region, as the clock plan already expects. A late retry (re-probe shortly before the region timeout) is not implemented.
3. **Telemetry: done 2026-09-29**, see "Telemetry" below.
4. **`tb_system`** must accept probe ownership in its "socket enabled without permission" invariant (edit listed in the integration notes).
5. **Constraints**: the mux mixes clk_25-domain and clk_snes-domain signals onto the same pads. They are never active together, so the cross-domain paths into the mux are false paths for timing. `SYSTEM_CLK` gains one LUT level through the mux (review with the board wrapper's clock-output choice).
6. **Glitches on `cart_5v_ok`/`iface_rail_ok`** drop the probe permit combinationally, which aborts the probe (invalid, so NTSC). The sequencer faults on a real rail loss in IFACE anyway.
7. The 256-flop header store could shrink to the six used bytes plus a signature for the stability check if LUT/FF budget becomes tight.

## Telemetry

Added 2026-09-29. STATUS is full, so the probe result and the reason for the region choice are in two new mailbox words, [n64-endpoint-implementation.md](n64-endpoint-implementation.md):

| Word | Bits |
|---|---|
| `0x1A` REGION_INFO | 7:0 `header_country`, 11:8 `reject` `{unstable, checksum, map, country}`, 12 `done`, 13 `header_valid`, 14 `header_pal`, 15 `aborted` |
| `0x1C` REGION_SOURCE | 1:0 source: 0 forced (CONTROL region mode), 1 passing key CIC, 2 valid ROM header, 3 NTSC default (no passing key and no valid header, or the timeout); 2 decided; 3 region timeout had expired; 4 decided region PAL |

- **Where it is computed.** In `sn64_top` (clk_25). The source follows the same priority as the decision: forced > key > header > default.
- **Snapshot.** Both words are captured on the clk_25 edge that sets `snes_clk_run`. That is the edge on which `sn64_clock_init` latches `region_pal` from the same inputs, so the telemetry describes the region actually used.
- **Before and after.** The snapshot is kept until the next cartridge start. Before the first decision REGION_INFO shows the live probe outputs and `decided` is 0.
- **Crossing.** One 32-bit `sn64_cdc_word` to the host clock.
- **Menu.** The bootstrap shows "Region: PAL via key CIC" (or ROM header, menu (forced), default) on the main screen. The status screen adds "Header: ok/bad, ctry XX, rej ....".

| `tb_system` run | REGION_INFO | REGION_SOURCE | STATUS |
|---|---|---|---|
| no header, no key | `1600` (done, invalid, reject `0110`, country `00`) | `0007` (NTSC default, decided) | `545F` |
| `+pal_header` | `7002` (valid EU) | `0016` (header, PAL) | `54DF` |
| `+pal_key +ntsc_header` | `3001` (valid USA) | `0015` (**key**, PAL) | `34DF` |
| `+ntsc_key +pal_header` | `7002` (valid EU) | `0005` (**key**, NTSC) | `345F` |

The endpoint bench has a fault build with the two words swapped, and it fails as required.

## Reuse

No existing hardware header reader was found to reuse. The pinned SNESTang and SNES_MiSTer sources receive ROM images from a loader. SNES_MiSTer (`SNES.sv` at `c61bfd4`, "ROM DETECT") takes `rom_region` from a word the HPS loader sends and applies `PAL <= (!status[15:14]) ? rom_region : status[15]`, meaning the menu's Auto/NTSC/PAL setting with the ROM's region in Auto. SN64 follows the same precedence. The pinned sd2snes files are only its CIC and PCB. The probe logic is original SN64 code (GPL-3.0-or-later), written from the published header format above.

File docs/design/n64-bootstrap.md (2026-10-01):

# N64 bootstrap ROM: implementation and evidence

Implemented 2026-09-29. This is the first version of the program the N64 or M64 runs from the SN64 cartridge. It is built with libdragon and passes a boot-checksum check, host unit tests and a co-simulation against the FPGA N64 endpoint. **It has not run on an N64, an M64 or an emulator.** The register contract is the [endpoint note](n64-endpoint-implementation.md). Relevant requirements are SN64-06-01, -06-02, -06-03, -09-02 and -08-13; none is accepted by this work.

## Plain-language summary
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

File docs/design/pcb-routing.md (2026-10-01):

# Main board routing

Started 2026-09-29. This note records how the placed main board ([hardware/sn64/sn64.kicad_pcb](../../hardware/sn64/sn64.kicad_pcb)) is being routed, what each tool does and what the result is worth. **Nothing here is a reviewed layout**: the placement is the block-zone draft from [build_main_pcb.py](../../hardware/sn64/tools/build_main_pcb.py), the fan-out and planes are generated, and the traces come from an autorouter. It is the first complete
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

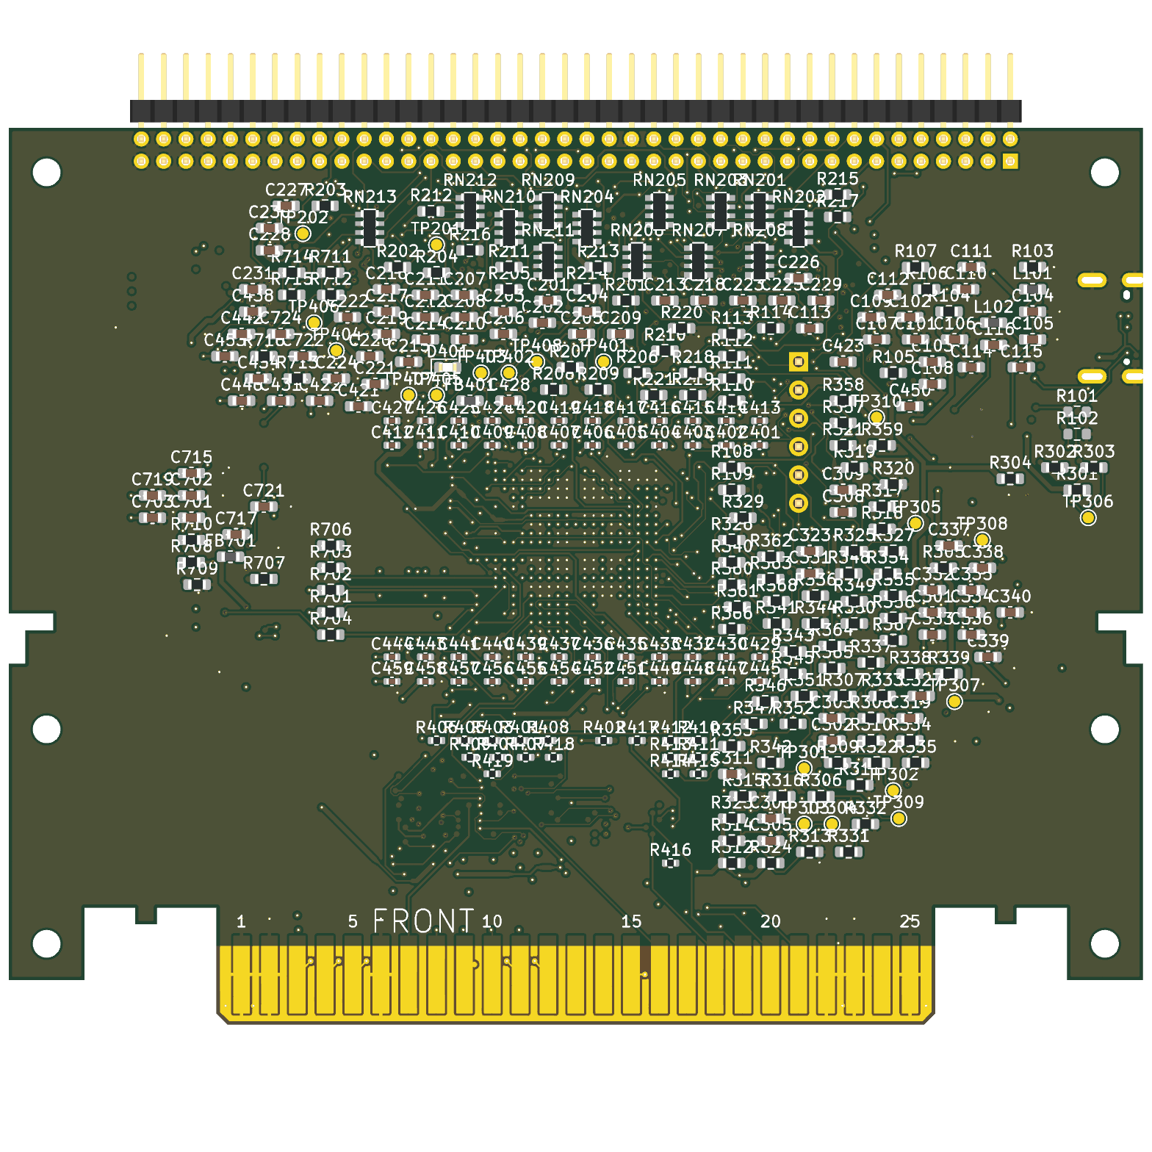
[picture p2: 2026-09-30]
hardware/sn64/exports/sn64-pcb-draft-bottom.png

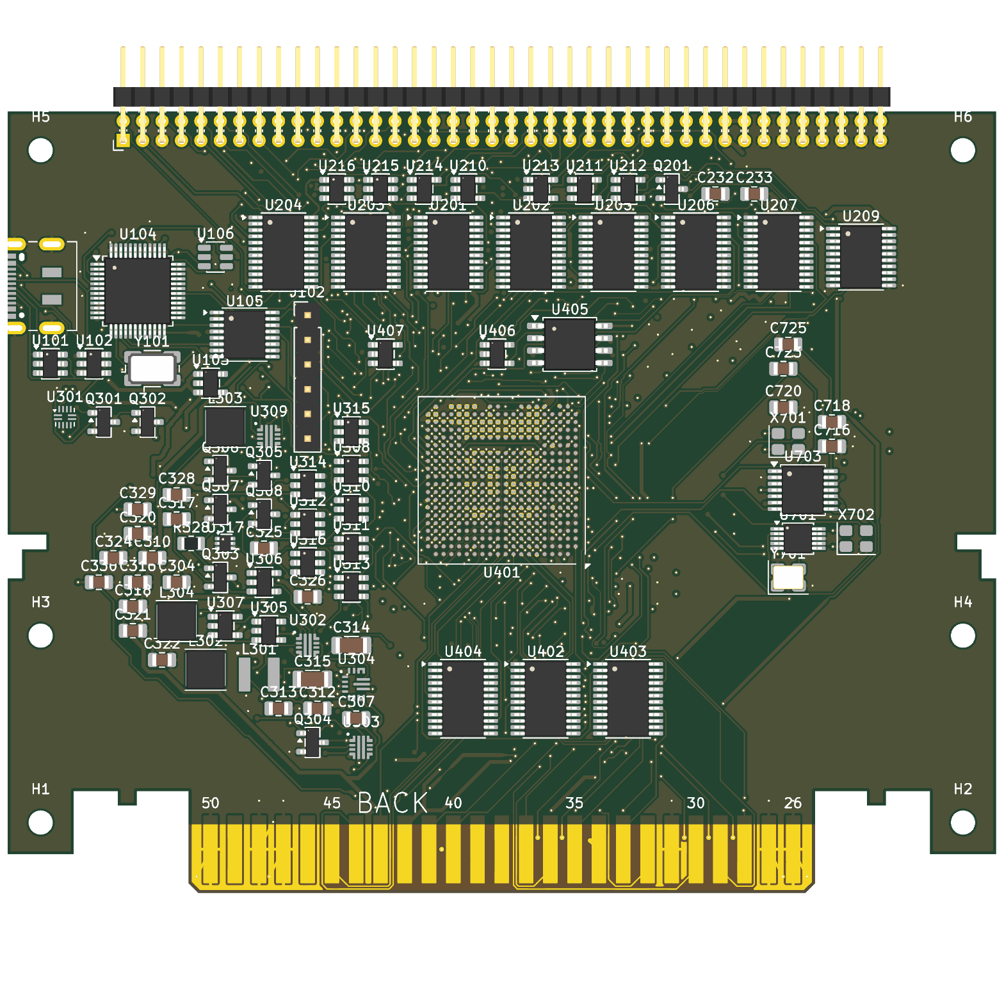
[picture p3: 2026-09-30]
hardware/sn64/exports/sn64-pcb-draft-top.png

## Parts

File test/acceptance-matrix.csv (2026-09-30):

requirement_id | source_ref | source_text | target | stage | owner | evidence_level | acceptance_status | acceptance_evidence | current_evidence | open_dependencies
SN64-01-01 | Rev A §1 item 1 | SN 64 is a modern FPGA-based successor in concept to the TriStar 64's SNES functionality. It recreates the console-side SNES environment required by real cartridges while using an original Nintendo 64 or ModRetro M64 as the host/controller platform. | FPGA SNES environment with N64/M64 host/controllers | Rev A | system | simulated | NOT_ACCEPTED | Architecture review plus recorded real-cartridge operation on each unmodified host; host controller data demonstrably drives console-side SNES logic. | docs/superpowers/plans/2026-09-28-sn64-engineering-plan.md; fpga/rtl/sn64_console_candidate.sv; fpga/tests/tb_console_boot.sv (candidate and testbench; this entry does not assert a passing run); fpga/tests/tb_system.sv (whole-system power-on in simulation: N64 mailbox, ordered cartridge power, Si5351 lock, region decision, SNES program from a modelled cartridge reading the N64 controller image; see docs/design/system-integration.md) | Integrated hardware, FPGA and bootstrap; both hosts.
SN64-01-02 | Rev A §1 item 2 | The top slot is required to behave electrically and temporally like a genuine SNES/Super Famicom cartridge interface. Original cartridges, Super EverDrive X5/X6 and FXPAK Pro are first-class targets. | Electrically/timing-faithful full SNES slot and first-class cartridges | Rev A | cartridge interface | designed | NOT_ACCEPTED | Capture address/data/control/clock/reset/audio behavior against approved SNES timing limits and complete §14 matrix for original carts, X5, X6 and FXPAK Pro. | hardware/sn64/validation/interface-check.json (30 static checks; connector reference consistency only) | Qualified socket, complete bridge, timing limits and physical cartridge tests.
SN64-02-01 | Rev A §2 item 1 | Original Nintendo 64 operation with no internal console modification. | Original Nintendo 64 without internal modifications | Rev A | N64 endpoint | simulated | NOT_ACCEPTED | Identify tested N64 revisions; run bootstrap, controllers, real SNES cartridge, A/V, telemetry and recovery with no internal console modification. | docs/superpowers/plans/2026-09-28-sn64-engineering-plan.md; fpga/tests/tb_n64_endpoint.sv, tb_n64_cic.sv (PI endpoint and CIC-6102 handshake against console models); firmware/bootstrap (menu ROM, CIC-6102 IPL checksum verified) | Working adapter and representative N64 hardware.
SN64-02-02 | Rev A §2 item 2 | ModRetro M64 operation using ordinary N64-cartridge-compatible behavior. | M64 through ordinary N64-cartridge behavior | Rev A | N64 endpoint | simulated | NOT_ACCEPTED | Repeat baseline tests on stock-timing M64 using the same adapter and only documented/ordinary cartridge transactions. | docs/superpowers/plans/2026-09-28-sn64-engineering-plan.md; Same ordinary-cartridge endpoint as SN64-02-01 (no M64-specific interface used) | Working endpoint and M64 tests; no private integration assumption.
SN64-02-03 | Rev A §2 item 3 | Original SNES/SFC cartridge support. | Original SNES/SFC cartridge support | Rev A | compatibility | documented | NOT_ACCEPTED | Record §14 per-target results for physical original SNES and SFC cartridges across required board and region classes. | hardware/sn64/validation/interface-check.json (30 static checks; connector reference consistency only) | Physical cartridge suite; completed console core and bridge.
SN64-02-04 | Rev A §2 item 4 | Explicit Super EverDrive X5/X6 and FXPAK Pro validation. | Physical Super EverDrive X5/X6 and FXPAK Pro validation | Rev A | compatibility | documented | NOT_ACCEPTED | Separate passing result records for physical X5, X6 and FXPAK Pro, with product/hardware/firmware revisions and §14 outcomes; generic ROM simulation is insufficient. | docs/superpowers/plans/2026-09-28-sn64-engineering-plan.md | All three physical products and their supported modes.
SN64-02-05 | Rev A §2 item 5 | Complete 62-pin SNES interface including expansion pads and cartridge audio inputs. | 62 contacts including expansion and cartridge audio | Rev A | cartridge interface | designed | NOT_ACCEPTED | Schematic/netlist and continuity checks cover all 62 numbered contacts; functional tests exercise outer pins, CIC/reset/EXPAND and both analog audio inputs. | hardware/sn64/validation/interface-check.json (30 static checks; connector reference consistency only); hardware/sn64/validation/av-clock-check.json (static: analog audio input network and ADC for contacts 31/62); hardware/sn64/validation/root-connectivity-check.json (SNES_AUDIO_L/R_IN reach the A/V sheet; static) | Active circuitry and hardware measurements; passive pad count alone cannot pass.
SN64-02-06 | Rev A §2 item 6 | FPGA-based SNES motherboard logic and timing-sensitive N64 interface. | FPGA SNES motherboard and timing-sensitive N64 endpoint | Rev A | FPGA | simulated | NOT_ACCEPTED | Synthesized integrated top includes both functions; timing reports and measured transactions demonstrate correct operation on both hosts. | fpga/rtl/sn64_console_candidate.sv; fpga/tests/tb_console_boot.sv (candidate and testbench; this entry does not assert a passing run); fpga/tests/tb_cart_bridge.sv, tb_n64_endpoint.sv, tb_system.sv; whole-design ECP5 synthesis in docs/design/system-integration.md | FPGA/package choice, endpoint integration, constraints and timing closure.
SN64-02-07 | Rev A §2 item 7 | Electrical protection for host, adapter and cartridge. | Protection for host, adapter and cartridge | Rev A | power/protection | simulated | NOT_ACCEPTED | Execute §8 and §15 fault matrix without unsafe voltages/contention, unintended cartridge enable, save corruption or hardware damage under defined fault conditions. | docs/design/power-architecture.md (candidate architecture; no measured power budget); hardware/sn64/validation/usb-check.json (64 static connectivity checks; no USB hardware test); fpga/tests/tb_power_sequencer.sv (digital permission/fault logic only); hardware/sn64/cart-interface.kicad_sch (translator default-disable topology, verify_cart_interface.py); hardware/sn64/power.kicad_sch + tools/verify_power_sheet.py (23 static checks, 11/11 mutations detected; attached to the root at the round-3 integration, ERC 0 errors; schematic only, no hardware) | Protection implementation, approved thresholds and fault equipment.
SN64-02-08 | Rev A §2 item 8 | Field-updatable FPGA/firmware with independent recovery programming. | Field updates with independent recovery | Rev A | firmware/programmer | designed | NOT_ACCEPTED | Update FPGA/firmware using version/integrity checks; recover deliberately invalid images without successful host boot or hardware rework. | hardware/sn64/validation/usb-check.json (64 static connectivity checks; no USB hardware test) | Target power/storage/programming route, host software and hardware recovery tests.
SN64-02-09 | Rev A §2 item 9 | Manufacturing test pads, telemetry and diagnostic firmware. | Manufacturing pads, telemetry and diagnostics | Rev A | manufacturing/firmware | designed | NOT_ACCEPTED | Audit test-point coverage; fixture and diagnostic image return recorded measurements, identity and faults against known injected conditions. | hardware/sn64/validation/usb-check.json (64 static connectivity checks; no USB hardware test); J102 service-access draft | Full test-point map, sensors/registers, fixture and diagnostic firmware.
SN64-03-01 | Rev A §3 item 1 | N64 / M64 → N64 cartridge-bus interface → FPGA + protection/support logic → SNES motherboard core → protected 5 V SNES cartridge interface → SNES/SFC cartridge, Super EverDrive or FXPAK Pro. | Complete host-to-physical-cartridge architecture | Rev A | system | designed | NOT_ACCEPTED | Trace every architectural block from host edge through endpoint/protection/core and translated protected 5 V socket; demonstrate end-to-end physical-cartridge operation. | docs/superpowers/plans/2026-09-28-sn64-engineering-plan.md; hardware/sn64/validation/interface-check.json (30 static checks; connector reference consistency only); docs/design/power-architecture.md (candidate architecture; no measured power budget) | Core/bridge/endpoint integration and remaining circuitry.
SN64-03-02 | Rev A §3 item 2 | The original TriStar proves the concept but is not copied circuit-for-circuit. Its obsolete NES subsystem, cheat hardware, memory editor and analog switching are omitted. | TriStar conceptual precedent and explicit exclusions | Rev A | system | documented | NOT_ACCEPTED | Design/BOM/HDL review shows no copied obsolete NES subsystem, cheat hardware, memory editor or required legacy analog-switch topology; reused blocks have provenance. | docs/superpowers/plans/2026-09-28-sn64-engineering-plan.md | Repeat scope audit of final design.
SN64-04-01 | Rev A §4 item 1 | The 62-contact SNES connector carries A0–A23, D0–D7, /RD, /WR, /ROMSEL, /IRQ, /RESET, SYSTEM CLK, PHI2, PA0–PA7, /PRD, /PWR, /WRAMSEL, REFRESH, EXPAND, CIC-related lines, +5 V, grounds, enhancement/expansion pads and left/right cartridge audio inputs. | Complete 62-contact signal behavior | Rev A | cartridge interface | simulated | NOT_ACCEPTED | Verify pin maps, continuity and behavior for A0–23, D0–7, RD/WR/ROMSEL/IRQ/RESET, SYSTEM CLK/PHI2, PA0–7/PRD/PWR/WRAMSEL/REFRESH/EXPAND, CIC, +5 V/grounds, outer contacts and L/R audio. Record shared/open-drain drive ownership. | hardware/sn64/validation/interface-check.json (30 static checks; connector reference consistency only); docs/design/snes-interface-notes.md; fpga/tests/tb_cart_bridge.sv (bus ownership), hardware/sn64/cart-interface.kicad_sch with verify_cart_interface.py (62/62 contacts accounted); CIC data pins must-fix open | Complete routing, bidirectional reset/CIC handling, audio integration and timing fixtures.
SN64-04-02 | Rev A §4 item 2 | The cartridge domain is 5 V. FPGA pins must not rely on undocumented 5 V tolerance. Proper direction-controlled translation/buffering is required, including power-off isolation and contention-safe bidirectional data handling. | 5 V cartridge translation, isolation and bus turnaround | Rev A | cartridge interface | simulated | NOT_ACCEPTED | Datasheet audit and worst-case timing calculation for each exact translator; measure legal logic levels, disabled/power-off leakage and contention-free OE/DIR read-write transitions with all power orders. | docs/design/translation-reuse-review.md (reference review; no final cartridge translator); docs/design/power-architecture.md (candidate architecture; no measured power budget); fpga/tests/tb_cart_bridge.sv (released clock at every owner change, contention monitor, fault build rejected); SN74LVC4245A translator sheet | Exact translator/order code, voltage limits, delays, dead time and isolation circuit.
SN64-04-03 | Rev A §4 item 3 | Cartridge +5 V uses a protected high-side load switch with soft start, current limiting, reverse-current blocking, voltage/current sensing and a hardware default-OFF state until configuration and rail checks pass. | Protected default-off 5 V cartridge supply | Rev A | power/protection | simulated | NOT_ACCEPTED | Verify high-side switch soft-start, current limit, reverse blocking and calibrated voltage/current sense; inject faults/configuration failure and prove hardware keeps power OFF until configuration and rail checks pass. | docs/design/power-architecture.md (candidate architecture; no measured power budget); fpga/tests/tb_power_sequencer.sv (default-off 5 V, ordered bring-up, latched faults; digital half only); hardware/sn64/power.kicad_sch + tools/verify_power_sheet.py (23 static checks, 11/11 mutations detected; attached to the root at the round-3 integration, ERC 0 errors; schematic only, no hardware) | Final switch/monitor circuit, characterized loads, tolerance analysis and enable truth table.
SN64-05-01 | Rev A §5 item 1 | The FPGA reproduces the console-side CPU, PPU, APU, memory map, DMA/HDMA, timers, arbitration and cartridge timing. With a physical cartridge inserted, cartridge ROM and cartridge-specific hardware remain outside the FPGA. | Console-side SNES CPU/PPU/APU/memory/timing with physical cart hardware | Rev A | FPGA | simulated | NOT_ACCEPTED | Trace CPU, PPU, APU, map, DMA/HDMA, timers, arbitration and timing; compare functional traces and real output against test expectations while ROM/enhancement hardware reside in the inserted cartridge. | fpga/reports/evaluation.md and evaluation.json (2026-09-29, --mode all): 1,336-clock diagnostic passes reset/native CPU, modeled external reads/writes, WRAM, B-bus write and two-byte A-to-B DMA; PHI2 activity only. NTSC and PAL mode-bit runs use the same 46.56 ns clock; no PAL clock/video/audio qualification. Candidate synthesis and trial internal route complete; no physical hardware tested. Additional 1,089-clock WRAM bus regression passes current direct/two-mirror and data-port reads, B-to-A DMA and reset/pause source-valid gating; no electrical OE or physical bus qualification. | PPU/APU/HDMA/timers/arbitration and full cartridge clock timing verification; physical ROM/enhancement-chip, graphics/audio and complete-system tests.
SN64-05-02 | Rev A §5 item 2 | A mature open SNES FPGA core can be adapted, but its ROM-loader path must be replaced by a physical cartridge bridge. | Replace loader path with physical cartridge bridge | Rev A | FPGA | simulated | NOT_ACCEPTED | Show active ROM/cart access reaches external address/data/control pins without loader remapping or an uploaded-ROM substitute; test physical reads/writes and cartridge-owned hardware arbitration. | fpga/reports/evaluation.md and evaluation.json (2026-09-29): modeled external read/write and DMA checks pass; raw $00:0010 mirrored-WRAM address is preserved at the wrapper cartridge interface. Corrupt low-byte injection fails the expected readback assertion. These are core/testbench checks, not electrical slot or real-cartridge validation. Additional 1,089-clock WRAM bus regression passes current direct/two-mirror and data-port reads, B-to-A DMA and reset/pause source-valid gating; no electrical OE or physical bus qualification.; fpga/tests/tb_cart_bridge.sv and tb_system.sv: physical-bus bridge replaces the loader path in simulation | Physical D-bus reads/ownership, partially driven/open-bus behavior, peripheral-bus completeness, clocks, reset/CIC, translator turnaround/latency and cartridge-owned hardware arbitration.
SN64-05-03 | Rev A §5 item 3 | SNES WRAM and other cycle-critical memories require deterministic latency. BRAM is preferred where practical, with synchronous external RAM only where timing is characterized. | Deterministic WRAM and cycle-critical memory | Rev A | FPGA/memory | simulated | NOT_ACCEPTED | Document allocation and worst-case latency per memory; prefer BRAM with justification; simulate arbitration and close timing for any synchronous external RAM under simultaneous CPU/PPU/APU/DMA traffic. | fpga/reports/evaluation.md and evaluation.json (2026-09-29): WRAM readback, mirror-address regression and two-byte cartridge-to-WRAM DMA pass. Synthesis uses 139/208 EBRs (64 WRAM, 16+16 VRAM, 32 ARAM, 11 other); trial internal route reaches 29.91 MHz against 21.477273 MHz with unconstrained I/O. This is partial core evidence, not complete memory timing qualification. Additional 1,089-clock WRAM bus regression passes current direct/two-mirror and data-port reads, B-to-A DMA and reset/pause source-valid gating; no electrical OE or physical bus qualification. | Worst-case simultaneous CPU/PPU/APU/DMA/HDMA memory latency and ARAM timing; full-product capacity/margins, final device/pins, external-memory decision and any external timing closure.
SN64-05-04 | Rev A §5 item 4 | A low-jitter oscillator and FPGA clock management generate SNES timing. NTSC is the first validation target; PAL remains an architectural target. Cartridge clock outputs include tunable series termination footprints. | Low-jitter clocks, NTSC first, retained PAL and tunable outputs | Rev A NTSC; full-target PAL | clocks/FPGA | simulated | NOT_ACCEPTED | Oscillator/PLL plan supports NTSC and PAL; measure frequency, jitter, duty cycle and waveform limits under load; inspect populated/tunable series footprints at cartridge clock drivers. | docs/superpowers/plans/2026-09-28-sn64-engineering-plan.md; docs/design/clock-plan.md; fpga/tests/tb_clock_init.sv (Si5351 NTSC/PAL masters programmed and locked; region fixed at power-on) | Exact clock source, quantified limits and both timing-mode evidence.
SN64-06-01 | Rev A §6 item 1 | The lower edge presents SN 64 as an N64 cartridge. FPGA logic implements the timing-sensitive cartridge endpoint plus a mailbox/register protocol for a small N64-side bootstrap. | N64 cartridge FPGA endpoint and bootstrap mailbox/registers | Rev A | N64 endpoint | simulated | NOT_ACCEPTED | Simulation plus bus captures verify N64 cartridge protocol/boot behavior and all mailbox/register reads/writes; a small host bootstrap exercises the documented ABI. | docs/design/n64-interface-notes.md; fpga/tests/tb_n64_endpoint.sv (ROM window, mailbox); firmware/bootstrap/tests/tb_bootstrap_rom_window.sv (menu image read back over PI) | Endpoint/CIC implementation, host ABI, timing constraints and bootstrap.
SN64-06-02 | Rev A §6 item 2 | The host reads N64 controller state, presents configuration/diagnostics and forwards controller data to the SNES subsystem. | Host controllers, configuration and diagnostics | Rev A | host firmware | simulated | NOT_ACCEPTED | Host bootstrap reads controller states, displays configuration/health, and transfers states correctly to SNES input logic; measure update interval and stale-input/fault behavior. | docs/superpowers/plans/2026-09-28-sn64-engineering-plan.md; firmware/bootstrap (menu, diagnostics, per-frame controller mailbox loop; built, not yet run on a console); tb_system.sv controller image reaches the SNES CPU | Firmware, mailbox implementation and latency policy.
SN64-06-03 | Rev A §6 item 3 | Controller mapping is firmware-configurable. Default mapping uses the D-pad directly, maps N64 face/C/shoulder buttons to SNES A/B/X/Y/L/R, Start to Start and Z to Select. | Configurable mapping and specified default controls | Rev A | host firmware | simulated | NOT_ACCEPTED | Test editable/persisted mappings; default D-pad is direct, Start→Start, Z→Select, and face/C/shoulder assignments provide A/B/X/Y/L/R. Record exact chosen default table and validate simultaneous inputs. | docs/research/snes-peripherals.md; firmware/bootstrap/tests/test_mapping.c (default table v1, 27 checks); docs/design/controller-path-implementation.md | Exact face/C/shoulder default, mapping persistence and physical controller tests.
SN64-06-04 | Rev A §6 item 4 | Baseline M64 support must depend only on behavior available to an ordinary N64 cartridge. A future enhanced M64 path is reserved until ModRetro's public console implementation exposes a supported integration mechanism. | Ordinary M64 baseline and supported future integration only | Rev A baseline; full-target enhancement | system/M64 | documented | NOT_ACCEPTED | Audit baseline host transactions as ordinary cartridge behavior; enhanced mode remains disabled/unclaimed until a public supported M64 interface is identified, versioned and tested. | docs/superpowers/plans/2026-09-28-sn64-engineering-plan.md; docs/research/m64-reference-files.md | Public M64 implementation/API, supported capability and host-version qualification.
SN64-07-01 | Rev A §7 item 1 | Rev A provides an independent digital SNES video/audio output for validation. This avoids assuming that full SNES A/V can be transported through the original N64 cartridge interface. | Independent digital SNES video and audio in Rev A | Rev A | A/V | simulated | NOT_ACCEPTED | Capture stable digital video/audio from the adapter's own output on both hosts; validate formats, frame cadence, synchronization and audio including cartridge L/R under frozen criteria. | docs/superpowers/plans/2026-09-28-sn64-engineering-plan.md; docs/design/console-video-path.md (owner decision 2026-09-29: the SNES picture and sound go to the console over the cartridge bus and appear on its own output; the adapter's HDMI output was removed); fpga/tests/tb_frame_window.sv and tb_system.sv (frame/audio window read by a PI host model at domain-2 timing, every RGBA5551 pixel exact, simulated only); fpga/tests/tb_audio_mix.sv (cartridge L/R I2S receive and saturating mix, simulated only); docs/design/av-clock-schematic.md (PCM1808 cartridge-audio ADC; static checks only) | Transmitter/interface selection, pipeline, audio input path and quantitative A/V limits.
SN64-07-02 | Rev A §7 item 2 | The original TriStar generated its own A/V and switched analog video. SN 64 does not need to retain that legacy topology. | No required TriStar analog-switch topology | Rev A | A/V | documented | NOT_ACCEPTED | Architecture review demonstrates the independent digital path operates without reliance on the omitted TriStar analog video switching. | docs/superpowers/plans/2026-09-28-sn64-engineering-plan.md | Final A/V schematic and output tests.
SN64-07-03 | Rev A §7 item 3 | The long-term M64 target is single-HDMI operation through the M64. PCB and FPGA resources are reserved for that path, but no undocumented M64 interface is invented. | Required future M64 single-HDMI with resource reservation | Full target | system/M64 | documented | NOT_ACCEPTED | Record justified PCB/FPGA resource reserve now; final acceptance requires real SNES video/audio through M64 HDMI using a public supported mechanism and passing A/V/control tests. | docs/superpowers/plans/2026-09-28-sn64-engineering-plan.md | Public M64 integration mechanism and implementation; reservation alone cannot pass.
SN64-08-01 | Rev A §8 item 1 | Input overcurrent protection and reverse-current protection where applicable. | Input overcurrent and applicable reverse-current protection | Rev A | power/protection | designed | NOT_ACCEPTED | Inject shorts/overload and every USB/host connection sequence; record trip behavior, delivered energy and reverse current within approved limits without back-powering sources. | docs/design/power-architecture.md (candidate architecture; no measured power budget); hardware/sn64/power.kicad_sch + tools/verify_power_sheet.py (23 static checks, 11/11 mutations detected; attached to the root at the round-3 integration, ERC 0 errors; schematic only, no hardware) | Source policies/current budget, input protection circuit and limits.
SN64-08-02 | Rev A §8 item 2 | Protected switched cartridge +5 V. | Protected switched cartridge 5 V | Rev A | power/protection | designed | NOT_ACCEPTED | Execute §4.3 switch tests at no load, worst valid load, startup and faults; verify controlled discharge/reset interaction. | docs/design/power-architecture.md (candidate architecture; no measured power budget); hardware/sn64/power.kicad_sch + tools/verify_power_sheet.py (23 static checks, 11/11 mutations detected; attached to the root at the round-3 integration, ERC 0 errors; schematic only, no hardware) | Completed switch circuit and load measurements.
SN64-08-03 | Rev A §8 item 3 | Supervised FPGA core and I/O rails. | Supervised FPGA core and I/O rails | Rev A | power/protection | designed | NOT_ACCEPTED | Independently sweep each rail through defined validity limits and prove supervisor/reset/enable response; no unsafe release while any required rail is invalid. | docs/design/power-architecture.md (candidate architecture; no measured power budget); hardware/sn64/power.kicad_sch + tools/verify_power_sheet.py (23 static checks, 11/11 mutations detected; attached to the root at the round-3 integration, ERC 0 errors; schematic only, no hardware) | FPGA rails, monitors, thresholds and timing.
SN64-08-04 | Rev A §8 item 4 | ESD protection on externally accessible connectors. | ESD on accessible connectors | Rev A | hardware/protection | designed | NOT_ACCEPTED | Review coverage and placement for every accessible connector; perform a defined ESD protocol with recorded levels and acceptable fault/recovery behavior. | hardware/sn64/validation/usb-check.json (64 static connectivity checks; no USB hardware test) (USB data/CC arrays only) | All connector circuits, PCB return paths and ESD test method/levels.
SN64-08-05 | Rev A §8 item 5 | Power-off isolation on translators. | Translator power-off isolation | Rev A | cartridge interface | designed | NOT_ACCEPTED | Measure leakage/back-power with each supply absent, ramping or brownout and every external logic state; demonstrate high impedance and no protection-diode overstress. | docs/design/translation-reuse-review.md (reference review; no final cartridge translator); hardware/sn64/validation/usb-check.json (64 static connectivity checks; no USB hardware test) | Cartridge/host translator choice and powered/unpowered matrix.
SN64-08-06 | Rev A §8 item 6 | Controlled reset and power sequencing. | Controlled reset and sequencing | Rev A | power/FPGA | simulated | NOT_ACCEPTED | Capture power/reset/enable timing for all source attach/detach orders, configuration success/failure, cartridge assertion and watchdog; compare against approved sequencing diagram. | docs/design/power-architecture.md (candidate architecture; no measured power budget); fpga/tests/tb_power_sequencer.sv and tb_system.sv (reset held until rails and SNES clock are valid; soft reset keeps cartridge power); hardware/sn64/power.kicad_sch + tools/verify_power_sheet.py (23 static checks, 11/11 mutations detected; attached to the root at the round-3 integration, ERC 0 errors; schematic only, no hardware) | Hardware reset/enable logic, complete state machine and sequence limits.
SN64-08-07 | Rev A §8 item 7 | Series termination footprints on clocks and sensitive buses. | Series-termination footprints | Rev A | PCB/signal integrity | designed | NOT_ACCEPTED | Layout/netlist audit shows tunable series footprints on cartridge clocks and identified sensitive buses; waveform measurements justify fitted values. | hardware/sn64/validation/usb-check.json (64 static connectivity checks; no USB hardware test) (USB JTAG series positions only) | Identify all sensitive buses, route and tune hardware.
SN64-08-08 | Rev A §8 item 8 | Bulk and local high-frequency decoupling. | Bulk and high-frequency decoupling | Rev A | PCB/power | designed | NOT_ACCEPTED | Calculate transient/capacitance requirements; review actual placement/current-return loops and measure rail ripple/droop at pins during worst load changes. | hardware/sn64/validation/usb-check.json (64 static connectivity checks; no USB hardware test) (USB bypass connectivity only) | System rails, bulk budget, placement and ripple limits.
SN64-08-09 | Rev A §8 item 9 | Grounding that keeps noisy digital returns away from sensitive A/V references. | Digital returns separated from sensitive A/V references | Rev A | PCB/A/V | documented | NOT_ACCEPTED | Review stackup and return-current paths without unintentional signal-reference breaks; measure A/V noise under worst switching/FPGA/cartridge activity. | docs/superpowers/plans/2026-09-28-sn64-engineering-plan.md | Final stackup, routing and A/V noise criteria.
SN64-08-10 | Rev A §8 item 10 | Board temperature monitoring. | Board temperature monitoring | Rev A | telemetry | designed | NOT_ACCEPTED | Calibrate reported temperature at multiple known points; exercise threshold/fault reporting and verify host-visible values during thermal-load tests. | docs/design/power-architecture.md (candidate architecture; no measured power budget); hardware/sn64/power.kicad_sch + tools/verify_power_sheet.py (23 static checks, 11/11 mutations detected; attached to the root at the round-3 integration, ERC 0 errors; schematic only, no hardware) | Sensor/circuit, placement, calibration and thermal limits.
SN64-08-11 | Rev A §8 item 11 | Safe FPGA default state with external bus outputs high impedance until configuration succeeds. | High-impedance external buses until FPGA configuration | Rev A | power/FPGA | simulated | NOT_ACCEPTED | Measure all host and cartridge drivers before/during failed and successful configuration; hardware enables remain disabled until required validity/health conditions hold. | docs/design/power-architecture.md (candidate architecture; no measured power budget); hardware/sn64/validation/usb-check.json (64 static connectivity checks; no USB hardware test) (JTAG isolation draft only); fpga/tests/tb_cart_bridge.sv, tb_system.sv (no socket drive without permission); translator /OE default-disabled in the cart-interface sheet | Main bus isolation, reset and configuration qualification.
SN64-08-12 | Rev A §8 item 12 | SNES cartridges are not treated as hot-swappable. Firmware should require cartridge power-down before insertion/removal. Protection mitigates mistakes but does not redefine the connector as a hot-plug standard. | Controlled cartridge power-down; no hot-swap claim | Rev A | firmware/protection | simulated | NOT_ACCEPTED | User workflow requests power-down before change; verify rails discharge and drivers isolate before safe-to-remove state. Defined mistake/fault tests verify mitigation without classifying connector as hot-plug. | docs/superpowers/plans/2026-09-28-sn64-engineering-plan.md; fpga/tests/tb_power_sequencer.sv (request drop / host reset shut the cartridge down); bootstrap power-down menu item | Power-state UI/firmware, safe-removal thresholds and fault protocol.
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

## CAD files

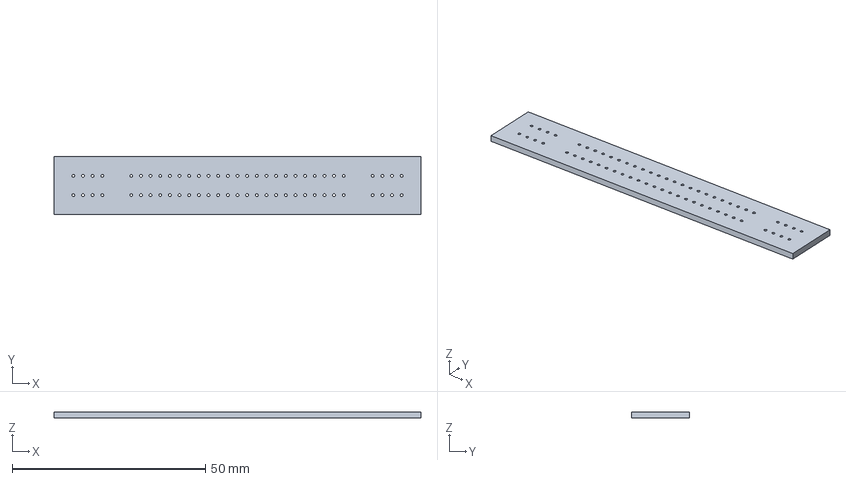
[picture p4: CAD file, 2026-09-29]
mechanical/fit-references/snes-hole-pattern-coupon.step
95.0 x 15.0 x 1.60 mm

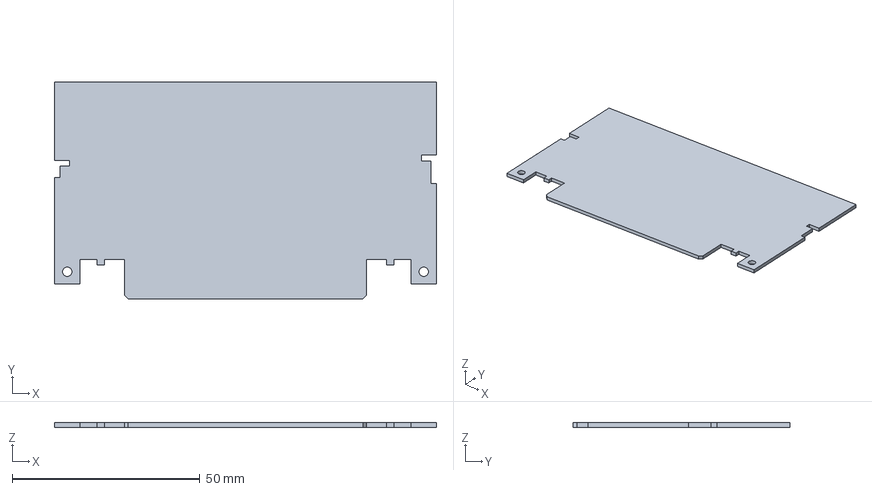
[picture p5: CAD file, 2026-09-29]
mechanical/fit-references/n64-sc64-board-reference.step
101.8 x 57.8 x 1.20 mm

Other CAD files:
mechanical/fit-references/n64-sc64-board-reference.FCStd
mechanical/fit-references/n64-sc64-board-reference.stl
mechanical/fit-references/snes-hole-pattern-coupon.FCStd
mechanical/fit-references/snes-hole-pattern-coupon.stl

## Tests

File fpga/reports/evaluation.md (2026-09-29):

# Console candidate evaluation — 2026-09-29

**The current console candidate passes its boot and WRAM diagnostics, synthesizes, and completes a trial ECP5-85F place-and-route.** This is an internal feasibility experiment, not a complete SN64 design or proof of real-cartridge compatibility.

The [JSON snapshot](evaluation.json) records source hashes, exact tool commands, exit codes, log hashes, memory/logic counts and timing. [Toolchain provenance](toolchain.json) and [reproduction instructions](../README.md) accompany it. The full run used `fpga/tools/evaluate.py --mode all`; raw logs remain in ignored `build/evaluation/` and can be regenerated. No FPGA bitstream, board pinout or manufacturing files were emitted.

## Results

| Check | Recorded outcome | Limit |
|---|---|---|
| NTSC mode diagnostic | PASS, 1,336 master clocks | Original diagnostic program; no game image or physical cartridge |
| PAL mode-bit diagnostic | PASS, 1,336 master clocks | Same 46.56 ns test clock; PAL master clock/video/audio not qualified |
| Corrupted cartridge read | Expected nonzero exit and `cartridge low readback` assertion | Demonstrates data checking catches the injected error |
| WRAM bus regression | PASS, 1,089 master clocks | Current data during direct/two-mirror reads, data-port reads and B-to-A DMA; source-valid reset/pause gating, without an electrical bus model |
| Normal-speed CPU control | Synthesized TURBO net is constant `0` | External PHI2 frequency/phase still needs full timing tests |
| Yosys final netlist check | Zero reported problems; synthesis exit 0 | Earlier warnings retained and discussed below |
| ECP5-85F / CABGA381 / grade 6 trial route | Completed; internal clock **29.91 MHz** achieved against **21.477273 MHz** constraint | Arbitrary unconstrained trial I/O; no external timing or final bank/pin qualification |

The boot diagnostic checks reset-vector fetch, native CPU execution, external 16-bit reads/writes, WRAM readback, a mirrored WRAM write with raw address `$00:0010`, a peripheral B-bus write, two-byte A-to-B cartridge-to-WRAM DMA and PHI2 activity. The new WRAM diagnostic checks current bytes throughout the observed A-side read window, RAM data-port reads, B-to-A DMA writes and immediate source-valid disable when reset/enable changes with the master clock stopped. Neither diagnostic establishes PHI2's full cycle-period matrix or electrical D-bus ownership/turnaround. Refer to the [bridge design](../../docs/design/physical-cartridge-bridge.md) for those pending tests.

| Synthesized resource | Count |
|---|---:|
| LUT4 | 26,669 |
| TRELLIS_FF | 10,775 |
| DP16KD | 139 of 208 EBRs |
| MULT18X18D | 19 |
| CCU2C | 1,030 |
| PFUMX / L6MUX21 | 4,392 / 855 |
| TRELLIS_DPR16X4 | 34 |

Placement packs 29,657 TRELLIS_COMB sites and 10,775 FF sites. Do not add these figures to the prepacking cell counts as if they were separate logic. The route report's architecture-wide I/O availability is not the bonded BG381 user-pin count. Actual product pin/bank allocation is still pending.

The 139 EBRs include 64 for WRAM, 16+16 for VRAM, 32 for ARAM and 11 for other core memories. This leaves 69 EBRs before host, A/V buffers and remaining integration. The candidate already includes 256 KiB main RAM, but no resource margin is yet reserved or accepted for the complete product. Final mapped netlist SHA-256: `da43318240ff16cfc0e9e6f4fc61443f6aaaf7737611bfde08c8dafdfa4e93a2`.

## Bugs found during reuse and regression evidence

- Upstream left SCPU's TURBO input open. A first mapped-netlist check failed with `normal-speed control is not tied low: ['x']`. The generated source now ties it to zero; the evaluator verifies the mapped constant. A passing two-state simulation alone had not caught this issue.
- Upstream's exported CA converted low-bank WRAM mirrors into bank `$7E`. The new mirror diagnostic failed with `WRAM mirror address changed on cartridge bus: 7e0010`. Generated SCPU now exports the CPU/DMA/HDMA-selected raw address separately; SNES forwards it and the wrapper uses it. Internal WRAM keeps the old converted CA path. The current diagnostic passes without changing the expected address.
- The previous wrapper exposed stale `$7E` instead of current `$A5` during a direct WRAM read. The [preserved development failure](wram-regression-development.txt) preceded the current WRAM mux fix. The wrapper now selects WRAM Q during qualified CE/OE and exports reset/enable-qualified source validity. This flag is not a translator output enable. The [bus evidence audit](../../docs/design/bus-electrical-evidence.md) supports the WRAM change while leaving CPU-register electrical behavior unresolved.
- The diagnostic additionally runs with a deliberately corrupted external low byte. It fails at the expected readback assertion, confirming that a successful process exit is not the sole acceptance condition.

The upstream source patches are generated by [prepare_core.py](../tools/prepare_core.py); original vendor sources remain pinned. Earlier 27,248-LUT/28.97-MHz and 27,817-LUT/27.99-MHz experiments preceded the current WRAM correction and are superseded for current implementation results. Differences in this unconstrained trial mapping are not evidence of improved physical cartridge timing.

## Warnings and interpretation

This is **not a warning-free build**. Slang reports an unreset local `STATE2` temporary in the CPU microcode process; source inspection shows it assigned with blocking assignment before use, while MI has an explicit reset. Early Yosys checks report shared static-function argument aliases in the pure `FlipPlane` and `CLAMP16` functions; those aliases disappear during mapping and the final check reports zero problems. Unused debug outputs are also undriven; the candidate ties debug controls off. These observations justify a bounded experiment, not full PPU/DSP equivalence or gameplay correctness. ABC reports its box/internal-fanout and combinational-network warnings; its internal mapping equivalence check passes.

The fresh evaluator compiled both diagnostics: the boot build produced 29 warnings and the WRAM build produced 29. Their warning summaries are preserved in [compiler diagnostics](compiler-diagnostics.txt); exact full-log hashes are in the JSON snapshot. The build uses `-Wno-fatal` and therefore must not be described as lint clean. [Simulation output](simulation-results.txt) preserves all three passing runs and the injected failure. Graphics, sound, ARAM timing, open-bus/partially driven reads, HDMA, save integrity, real translators, rail sequencing, fault timing, cartridge clocks, CIC, host operation and USB initial loading still require dedicated verification.

ECP5 resource fit is useful evidence for the 85F candidate. It does not fix the BOM, determine power consumption, prove PCB routability or establish original-N64/M64 compatibility.

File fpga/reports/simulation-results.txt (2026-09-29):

=== ntsc-mode ===
PASS: reset/native CPU, cartridge R/W, WRAM, B-bus, DMA, PHI2; PAL flag=0; 1336 clocks
- fpga/tests\tb_console_boot.sv:101: Verilog $finish
- S i m u l a t i o n   R e p o r t: Verilator 5.053 devel
- Verilator: $finish at 62us; walltime 0.001 s; speed 41.492 ms/s
- Verilator: cpu 0.000 s on 1 threads; allocated 5 MB

=== pal-mode-bit ===
PASS: reset/native CPU, cartridge R/W, WRAM, B-bus, DMA, PHI2; PAL flag=1; 1336 clocks
- fpga/tests\tb_console_boot.sv:101: Verilog $finish
- S i m u l a t i o n   R e p o r t: Verilator 5.053 devel
- Verilator: $finish at 62us; walltime 0.001 s; speed 62.477 ms/s
- Verilator: cpu 0.000 s on 1 threads; allocated 5 MB

=== corrupt-cartridge-read ===
[27750000] %Fatal: tb_console_boot.sv:91: Assertion failed in tb_console_boot: cartridge low readback
%Error: fpga/tests\tb_console_boot.sv:91: Verilog $stop
Aborting...

=== wram-bus ===
PASS: active-cycle WRAM data, both mirrors, WRAM-port reads, B-to-A DMA, pause/reset source validity (1089 clocks)
- fpga/tests\tb_wram_bus.sv:60: Verilog $finish
- S i m u l a t i o n   R e p o r t: Verilator 5.053 devel
- Verilator: $finish at 51us; walltime 0.001 s; speed 46.364 ms/s
- Verilator: cpu 0.000 s on 1 threads; allocated 5 MB

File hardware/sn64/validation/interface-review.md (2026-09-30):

# Independent interface review

Result: **PASS** — 31 checks passed; 0 failed.

The validator independently exports the current schematic with KiCad and checks all 112 pin-to-net assignments against both CSV maps. It compares the N64 footprint with J_N1 loaded directly from the original SummerCart64 PCB, including copper sides, pad geometry, mask polygons and connector edge profile. The SNES footprint must be byte-identical to the original Sanni footprint.

Only GND may join the two connectors. HOST_3V3, HOST_12V and SNES_5V_CART must remain separate. Both reusable symbols must match the schematic copies and preserve all pin numbers and names.

Limits:

- Reference agreement is not a validated SNES socket purchase/fit; no final socket manufacturer part number is selected.
- The N64 footprint includes six source Edge.Cuts segments forming an open connector profile; complete the board perimeter without duplicating them.
- All connector pins are deliberately passive; ERC cannot establish endpoint direction, power safety, translation or drive-enable correctness.
- Only the connector scaffold is checked: no FPGA assignment, power circuitry, timing behavior, complete PCB, host fit or manufacturing release is validated.

Reproduce with KiCad 10 Python: `python hardware/sn64/tools/verify_interfaces.py --source-root <original-project-with-reference-downloads>`.

See [machine-readable checks](interface-check.json) for input SHA-256 hashes and per-check evidence. The stored netlist is compared to a fresh export; the PDF was not visually reviewed by this validator.

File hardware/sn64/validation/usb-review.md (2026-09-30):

# Independent USB programmer review

**PASS**: 69 checks passed; 0 failed.

Checked a fresh KiCad export against hand-authored manufacturer pin assignments, not the generated CSV or builder script. The checker covers DNP CC resistors (TUSB320 Rd on the power sheet) and the CC/VBUS/USB_3V3/JTAG/TARGET_VREF exports; DP/DM and ESD pairs; FT232HL supplies, crystal and EEPROM; AXC pin directions and default-disabled /OE; target-side service header; library pad sets; and host/USB rail separation.

Limits:

- This checks schematic connectivity against fixed pin tables; it does not prove physical routing, signal integrity, protection performance or USB compliance.
- Crystal startup, effective load capacitance and frequency accuracy require layout and prototype measurements. The 11 pF values are explicitly provisional.
- USB_VBUS also feeds the power sheet default-off target input (U302), enabled only when the TUSB320 (U301) reports >=1.5 A and USB_3V3 is present; USB_3V3 also powers U301. JTAG reaches the ECP5 dedicated balls and TARGET_VREF comes from FPGA_3V3 through R414 (FPGA sheet). The persistent-loading algorithm remains unimplemented.
- A fitted EEPROM must preserve the safe ACBUS6 startup contract. Host loading must use the documented --status-pin 14 option.
- Target-off leakage, USB/target power sequencing, abnormal process termination/reset, inrush, thermal margin, suspend current and cold-boot persistence require bench tests.
- ESD array pin connectivity is checked; this is not a short-to-VBUS/USB-PD protection claim. USB and target supplies have no direct schematic connection to host power.

Reproduce using KiCad 10 Python: `python hardware/sn64/tools/verify_usb_programmer.py`.

See [usb-check.json](usb-check.json) for input hashes, manufacturer source links and detailed results. No hardware measurements were performed.

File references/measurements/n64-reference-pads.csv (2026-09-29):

pin | x_mm | y_mm | width_mm | height_mm | drill_x_mm | drill_y_mm | layers | net
1 | 180.0 | 131.0 | 1.5 | 7.0 | 0.0 | 0.0 | B.Cu | GND
2 | 177.5 | 131.0 | 1.5 | 7.0 | 0.0 | 0.0 | B.Cu | GND
3 | 175.0 | 131.0 | 1.5 | 7.0 | 0.0 | 0.0 | B.Cu | N64_AD15
4 | 172.5 | 131.0 | 1.5 | 7.0 | 0.0 | 0.0 | B.Cu | N64_AD14
5 | 170.0 | 131.0 | 1.5 | 7.0 | 0.0 | 0.0 | B.Cu | N64_AD13
6 | 167.5 | 131.0 | 1.5 | 7.0 | 0.0 | 0.0 | B.Cu | GND
7 | 165.0 | 131.0 | 1.5 | 7.0 | 0.0 | 0.0 | B.Cu | N64_AD12
8 | 162.5 | 131.0 | 1.5 | 7.0 | 0.0 | 0.0 | B.Cu | ~{N64_WRITE}
9 | 160.0 | 131.0 | 1.5 | 7.0 | 0.0 | 0.0 | B.Cu | N64_3V3
10 | 157.5 | 131.0 | 1.5 | 7.0 | 0.0 | 0.0 | B.Cu | ~{N64_READ}
11 | 155.0 | 131.0 | 1.5 | 7.0 | 0.0 | 0.0 | B.Cu | N64_AD11
12 | 152.5 | 131.0 | 1.5 | 7.0 | 0.0 | 0.0 | B.Cu | N64_AD10
13 | 150.0 | 131.0 | 1.5 | 7.0 | 0.0 | 0.0 | B.Cu | unconnected-(J_N1-12V-Pad13)
14 | 147.5 | 131.0 | 1.5 | 7.0 | 0.0 | 0.0 | B.Cu | unconnected-(J_N1-KEY-Pad14)
15 | 145.0 | 131.0 | 1.5 | 7.0 | 0.0 | 0.0 | B.Cu | N64_AD9
16 | 142.5 | 131.0 | 1.5 | 7.0 | 0.0 | 0.0 | B.Cu | N64_AD8
17 | 140.0 | 131.0 | 1.5 | 7.0 | 0.0 | 0.0 | B.Cu | N64_3V3
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

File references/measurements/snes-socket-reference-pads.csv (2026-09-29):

pin | x_mm | y_mm | width_mm | height_mm | drill_x_mm | drill_y_mm | layers | net
1 | 0.0 | 0.0 | 1.524 | 1.524 | 0.762 | 0.762 | F.Cu,F.Mask,B.Cu,B.Mask,In1.Cu,In2.Cu,In3.Cu,In4.Cu,In5.Cu,In6.Cu,In7.Cu,In8.Cu,In9.Cu,In10.Cu,In11.Cu,In12.Cu,In13.Cu,In14.Cu,In15.Cu,In16.Cu,In17.Cu,In18.Cu,In19.Cu,In20.Cu,In21.Cu,In22.Cu,In23.Cu,In24.Cu,In25.Cu,In26.Cu,In27.Cu,In28.Cu,In29.Cu,In30.Cu
2 | 0.0 | 2.5 | 1.524 | 1.524 | 0.762 | 0.762 | F.Cu,F.Mask,B.Cu,B.Mask,In1.Cu,In2.Cu,In3.Cu,In4.Cu,In5.Cu,In6.Cu,In7.Cu,In8.Cu,In9.Cu,In10.Cu,In11.Cu,In12.Cu,In13.Cu,In14.Cu,In15.Cu,In16.Cu,In17.Cu,In18.Cu,In19.Cu,In20.Cu,In21.Cu,In22.Cu,In23.Cu,In24.Cu,In25.Cu,In26.Cu,In27.Cu,In28.Cu,In29.Cu,In30.Cu
3 | 0.0 | 5.0 | 1.524 | 1.524 | 0.762 | 0.762 | F.Cu,F.Mask,B.Cu,B.Mask,In1.Cu,In2.Cu,In3.Cu,In4.Cu,In5.Cu,In6.Cu,In7.Cu,In8.Cu,In9.Cu,In10.Cu,In11.Cu,In12.Cu,In13.Cu,In14.Cu,In15.Cu,In16.Cu,In17.Cu,In18.Cu,In19.Cu,In20.Cu,In21.Cu,In22.Cu,In23.Cu,In24.Cu,In25.Cu,In26.Cu,In27.Cu,In28.Cu,In29.Cu,In30.Cu
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

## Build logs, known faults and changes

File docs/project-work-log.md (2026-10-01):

# SN 64 project work log

This log records engineering artifacts, evidence and publication. It does not certify working hardware or manufacturing readiness. Every target in [specification Rev A](../SN_64_Engineering_Specification_Rev_A.docx) remains in scope, subject to the explicit user decisions recorded in the [engineering plan](superpowers/plans/2026-09-28-sn64-engineering-plan.md).

## 2026-09-28 — References and cartridge-interface draft

- Collected native upstream schematics, layouts, HDL, footprints and mechanical references, with source revisions and license notes. The [reuse map](research/reusable-designs.md) distinguishes the MiSTer SNES core, sd2snes cartridge-side circuitry, OpenSFC donor-chip motherboard and SummerCart64 N64 endpoint. These are reusable blocks; they do not constitute a working SN 64 adapter.
- Recorded [connector and shell dimensions](dimensions.md), including source/derived dimensions and remaining fit checks. Created a native KiCad root sheet with the 50-contact N64 edge and complete 62-contact SNES/SFC socket, project libraries and signal maps.
- Checked cartridge signal identity, direction and special handling against the references. Documented the [SNES interface](design/snes-interface-notes.md), [N64 interface](design/n64-interface-notes.md) and [translator reuse limits](design/translation-reuse-review.md). Physical cartridge bridge logic, power switching and remaining interface circuits are still pending.

## 2026-09-29 — Side USB-C programmer circuit draft

- Added the real [USB programmer child schematic](../hardware/sn64/usb-programmer.kicad_sch), revision `0.2-usb`, to the cartridge-interface project. It includes the reused JAE receptacle geometry, independent 5.1 kΩ CC terminations, data/CC ESD arrays, bridge regulator, FT232HL revision C, 12 MHz crystal, optional DNP EEPROM, default-disabled JTAG translator and target-side service header.
- Documented [blank-board startup and the host programming contract](design/usb-programming-architecture.md), including the required `--status-pin 14` option. USB enumeration is designed to be independent of the main FPGA image; actual blank-board enumeration and programming have not been tested.
- Checked the [connector manufacturer's geometry and crystal requirements](design/usb-connector-mechanics.md). The crystal's two 11 pF load capacitors remain provisional pending layout parasitics, startup and frequency measurements. Final enclosure location and cable clearance remain open.
- Exported the schematic/netlist and ran independent static checks. The saved reports show [30 cartridge-interface checks passed](../hardware/sn64/validation/interface-check.json) and [64 USB checks passed](../hardware/sn64/validation/usb-check.json), with zero failures. The ERC report retains 90 isolated-label warnings at the unfinished cartridge interfaces. Static connectivity checks do not demonstrate hardware operation or USB compliance.

The first hardware revision must provide externally accessible, side-mounted USB-C for initial loading, later updates and recovery without a successful N64/M64 boot. The drawn bridge powers only its own interface; FPGA selection, persistent storage, target programming power and hookup, boot straps, loading software and cold-boot recovery tests are still required to fulfill that requirement.

## 2026-09-29 — GitHub publication

Published the current design and earlier reference/interface work as [draft pull request #1](https://github.com/FantomZap/SN-64/pull/1), branch `codex/usb-programmer`. A fresh Git fetch verified that the published design commit `d3db0f4f9429eb83c969087c73f5e3363d037a52` and local design commit `7094cacce50dbb26ff0d79bc2e650ac01cc8259c` have the identical file tree `20c06d39eb0ad66bb94ad47702d34fa73e29d65c`.

The main project folder contains the new work. GitHub's `main` branch remains at the earlier reviewed baseline; the complete current draft is on the linked pull request. Local commit history was retained. Publication used the connected GitHub app because command-line Git had no usable login, so the remote publication commit differs from the local development commits while preserving identical files. This work-log entry is a subsequent documentation update to that same pull request. No files were sent to PCBWay and no manufacturing order was placed.

## 2026-09-29 — Console evaluation, mechanical references and full requirements

- Created the [136-entry requirements register](requirements.md), retaining every one of the original document's 110 items, 16 compatibility refinements and 10 user clarifications. Partial design/simulation evidence remains separate from acceptance; no product or hardware requirement is marked accepted.
- Vendored 35 pinned SNESTang source/license files and added an auditable preparation script, memory wrapper and original diagnostic. The [current evaluation](../fpga/reports/evaluation.md) passes reset/native CPU, cartridge reads/writes, WRAM, raw mirror addressing, B-bus write, A-to-B DMA and PHI2 activity in 1,336 master clocks. Both PAL mode-bit values pass at the same test clock; this does not validate PAL clocks/video. An injected bad cartridge read produces the intended assertion failure.
- Independent review found upstream's open TURBO input and converted WRAM mirror address on the exported bus. Each issue was demonstrated before correction. Generated patches now tie normal speed low and export the raw CPU/DMA/HDMA address separately, retaining the core's internal memory path. [Physical D-bus ownership and further bridge work](design/physical-cartridge-bridge.md) remain open.
- Installed official portable OSS CAD Suite 20260928 and w64devkit 2.10.0 after checking their release-asset SHA-256 digests. Recorded tool versions and the Windows Make/path and XAIGER compatibility choices. The full current run synthesizes to 27,817 LUT4, 10,775 FF and 139 EBRs; trial ECP5-85F/BG381 grade-6 routing reaches 27.99 MHz against 21.477273 MHz. Arbitrary trial I/O and the incomplete system mean this is internal feasibility evidence only.
- Created two editable [FreeCAD reference models](../mechanical/README.md) with STEP and closed STL exports: the complete 62-hole Sanni pattern coupon and SummerCart64 board outline/thickness/mounting reference. Native solid/parameter checks and STEP round-trip checks passed; a separate root review checked six file hashes plus STEP validity, STL closure and native reopen/recompute. No socket, cartridge or host fit was physically tested.
- Strengthened the mechanical importer after review: both source hashes and revisions must match the trusted project manifest before parsing or writing. A regression first reproduced acceptance of modified source, then passed after the fix: both altered input files are rejected and existing datums remain untouched. Online socket leads are recorded, but no exact production socket has a qualified body/seating drawing yet.
- Recorded [power architecture](design/power-architecture.md), [FPGA availability/reuse](design/fpga-board-selection.md) and [system architecture](architecture.md). The M64 cartridge limiter's 500 mA setting is not a guaranteed load allocation. The user's M64 USB-port power idea is included: a short C-to-C cable is a candidate, while published standard-current advertisement, enumeration/startup policy and actual loads still need qualification. Unknown flashcart currents stay blank, not zero.
- Fresh existing KiCad checks passed again: 30 cartridge-interface and 64 USB static checks, zero failures. The USB circuit itself remains revision 0.2; the new power architecture still needs to be drawn and integrated. Nothing was ordered or sent to PCBWay.

These changes form the next engineering checkpoint for the existing draft pull request. Sources, generated reference models, reports and next tests are retained together; this checkpoint does not complete the multi-stage implementation plan.

## 2026-09-29 — First physical-bus data correction and evidence audit

- Continued the existing plan in the isolated `codex/cartridge-bus` worktree, starting from published checkpoint `f75c0e1201be7fe15c7889237ee1bf264077ba50`. The original project folder was clean and its file tree matched that published checkpoint before this work began.
- Audited the pinned OpenSFC netlist and original SNESTang WRAM logic. The [bus evidence note](design/bus-electrical-evidence.md) records exact source revisions, shared D0–D7 connectivity, a representative pin list and the distinction between primary motherboard evidence, upstream functional logic and secondary descriptions. Shared topology supports current WRAM read data reaching the cartridge contacts; it does not establish measured original-console timing.
- Corrected the earlier proposal to export all CPU-internal register reads onto the physical cartridge bus. Internal readback alone does not establish external drive. Ordinary CPU-register reads, DMA involving CPU registers and PPU-internal retained bits remain separate evidence/verification questions. The bridge contract and implementation plan now reflect that correction.
- Preserved a [machine-readable source-net extract](research/snes-data-bus-net-evidence.json) with all eight complete data nets, component values, original schematic/netlist SHA-256 hashes, source revision and export-tool identity. Each net contains the seven functional endpoints and its test point; no physical continuity or waveform measurement is implied.
- Added an original cartridge-output diagnostic before changing the data path. The [preserved failure](../fpga/reports/wram-regression-development.txt) shows stale `$7E` during a read expecting `$A5`. The candidate now selects current WRAM Q during its CE/OE read window and qualifies `cart_wram_read_valid` with reset and enable. The flag describes one data source; it does not implement translator OE, contention prevention or fault gating.
- The new diagnostic passes in 1,089 master clocks: direct WRAM reads, both low-memory mirror classes, two RAM data-port reads, two-byte B-to-A DMA and immediate source-valid disable under reset/pause with the master clock stopped. Added it to the reproducible evaluator beside the existing boot, PAL mode-bit and corrupt-read runs. Test programs are original diagnostic code; no commercial game image is included.
- Fresh-context independent review checked the upstream predicate, current test and source netlist, and reran the built WRAM diagnostic. It found no blocking issue. Remaining coverage includes a resolved physical-bus model, validity negatives across other responders, boundary cases, HDMA and hardware timing. These remain explicit next work rather than accepted compatibility.
- The fresh full evaluator completed successfully: both 1,336-clock boot mode-bit runs, the expected injected-read failure, the 1,089-clock WRAM regression, synthesis and trial routing. Current mapping uses 26,669 LUT4, 10,775 FF and 139 EBRs; the unconstrained trial ECP5-85F/BG381 grade-6 route reaches 29.91 MHz against 21.477273 MHz. Routing itself took 1,101.81 seconds. Each diagnostic compilation emitted 29 warnings, retained in the report. Verified all 38 recorded input hashes and all 11 command/log records before publication preparation. No external socket or final board timing is qualified by this result.
- Updated the bridge design, architecture, requirements evidence, plan checkpoint, FPGA documentation and document index together. The three partially simulated requirements retain `NOT_ACCEPTED`; all 136 requirements remain unaccepted. The user reiterated that sources, decisions, failures, tests and unresolved work must be retained in the project folder and GitHub.

The current [evaluation report](../fpga/reports/evaluation.md) and [JSON snapshot](../fpga/reports/evaluation.json) own exact build inputs, commands, results and limitations. Historical resource/timing figures above describe their original checkpoint; use the current report for the latest candidate.

## 2026-09-29 — Development moved to Claude Code; GitHub main updated

- Development continues from a complete copy of the Codex project folder: Git history, ignored research downloads, build evidence and the Codex worktrees' ignored scratch files. A hash comparison confirmed every original file is present and identical; only Git fetch metadata differs. The original folder is unchanged.
- Re-ran the existing checks from the new location. `evaluate.py --mode sim` passed both 1,336-clock boot runs (PAL flag 0 and 1). It rejected the injected corrupt read and passed the 1,089-clock WRAM regression. KiCad static checks again passed 30 interface and 64 USB checks. This repeats existing simulation/static evidence only; no hardware was tested.
- Published the full local development history to GitHub `main` as a fast-forward. Draft PR #1 held the identical file tree under different publication commits, so it was closed as superseded instead of merged.
- Added [CLAUDE.md](../CLAUDE.md) with working rules and check commands. The user handed project control to Claude and allowed replacing the named software where better-suited tools exist.
- Current tool assessment: keep KiCad, because PCBWay accepts it directly and every reused upstream board is KiCad. Keep the OSS CAD Suite ECP5 flow. New enclosure geometry may move to code-first build123d with STEP/STL exports, keeping the FreeCAD references. No tool change has been made yet.
- Recorded a quick [risk assessment](risk-assessment.md). Top risks are power, the video path, real-cartridge timing and BGA board layout. It recommends proving the cartridge path on development hardware before the custom board.

## 2026-09-29 — Physical cartridge bridge implemented in simulation

- Cross-referenced the pinned core's cartridge bus (`cpu.v` strobe generation and cycle counters, `SNES.v` data muxing, `P65C816.v` read-data latch point) with console-side hardware behaviour and wrote [sn64_cart_bridge.sv](../fpga/rtl/sn64_cart_bridge.sv): registered socket outputs gated by a hardware permission, a data-bus ownership state machine with a released clock at every owner change, look-ahead so turnarounds finish before the strobe edge reaches the cartridge, and one clock of write-data hold. Internal CPU-register reads are not exported, per the evidence audit. [Implementation notes](design/cartridge-bridge-implementation.md).
- Added a physical-bus testbench with a cartridge model that drives only when selected and a monitor that fails on contention, unpermitted output, missing write data or a missing turnaround. Passes in 1,411 clocks with 56 ownership changes and zero contention. A fault-injected build (turnaround removed) is rejected as required.
- Two bugs found and fixed during development: (1) deciding ownership from the delayed socket strobes shortened the effective write pulse; (2) the bench's SRAM model latched after the address had advanced. Both are recorded in the implementation note.
- `evaluate.py --mode sim` now runs seven checks. CIC, EXPAND, analog audio, HDMA/PPU/APU responder cases, fault-input wiring and hardware timing remain open.

## 2026-09-29 — N64/M64 host endpoint implemented in simulation

- Vendored SummerCart64's N64 PI controller, FIFO and bus interfaces unmodified (GPL-3.0, commit `a1e7996d`, [provenance](../fpga/vendor/summercart64/provenance.json)) and wrote [sn64_n64_endpoint.sv](../fpga/rtl/sn64_n64_endpoint.sv): a bootstrap ROM window at `0x1000_0000` and a mailbox register block at `0x1FFF_0000` for controller state, run request, status and build identity. The run request is cleared by host reset. [Implementation notes and register map](design/n64-endpoint-implementation.md).
- Added a host-model testbench driving the PI protocol (ALE_H/ALE_L latch, read/write strobes) with AD-bus ownership checks. Passes ROM burst/offset reads, mailbox read/write/readback and reset behaviour in 4,595 clocks. Added to `evaluate.py --mode sim`. Two host-model mistakes (ALE hold time, ALE order) were fixed in the bench and recorded as guidance for the bootstrap.
- CIC lockout (SummerCart64's soft-CPU implementation), /INT and the libdragon bootstrap remain open; the register map is the bootstrap's contract.

## 2026-09-29 — N64 CIC lockout and power-control state machine

- Vendored SummerCart64's CIC module, the SERV RISC-V core (ISC) and the UltraCIC_C-derived firmware (MIT), unmodified, and wired them into the endpoint as CIC-6102/7101 (seed `0x3F`, checksum `0xA536C0F1D859`). Installed the xPack RISC-V GCC 15.2.0-1 (checksum verified against GitHub's release digest) and added [build_cic.py](../fpga/tools/build_cic.py); the firmware uses 395 of 512 words. A console-side model now passes ID, seed and 64-bit checksum against independently computed references and enters compare mode; an altered expectation is rejected. [CIC notes](design/n64-cic-implementation.md).
- Design finding: the bit-serial soft CPU is too slow at 21.477 MHz; the endpoint now runs it from a separate 62.5 MHz PLL clock, as SummerCart64 does. The real PIF bit rate and phase gaps remain a hardware measurement item.
- Added [sn64_power_sequencer.sv](../fpga/rtl/sn64_power_sequencer.sv): ordered bring-up (reset held, 5 V, interface rail, reset release), combinational bus permission, shutdown on request loss or host reset, latched faults with codes and a deliberate clear. Its bench passes bring-up, shutdown, four fault classes and a rail timeout. [Notes](design/power-sequencer-implementation.md).

## 2026-09-29 — Parallel blocks: controllers, SNES CIC, N64 menu ROM; integration

Built by parallel helper agents with self-checking tests, then reviewed and integrated:

- **Controller path** ([notes](design/controller-path-implementation.md)): `sn64_snes_joypad` emulates two standard SNES pads from the mailbox images, reusing SNESTang's `controller_adapter.sv` unmodified (vendored with provenance). It forces the ID bits, keeps the multitap line idle (upstream's tie-low reads as a multitap, which is excluded) and supports an empty port. The serial protocol bench (82 cases) and a whole-core bench (auto-joypad and manual reads over two frames) pass; a B/Y swap is rejected. Default N64→SNES mapping v1 is frozen in the notes.
- **SNES CIC lock** ([notes](design/snes-cic-implementation.md)): original HDL written from published descriptions (segher's article, the Super Famicom dev wiki); no reusable code with a compatible, clean provenance was found. NTSC and PAL keys pass for four seeds, two cases match the wiki's reference program bit for bit, absent and corrupted keys are flagged, and two fault builds are rejected. Instruction-cycle timing is derived from SuperCIC and must be measured against a real key.
- **N64 bootstrap ROM** ([notes](design/n64-bootstrap.md)): libdragon toolchain installed without admin (checksum verified); the menu ROM (114,688 bytes) builds, its IPL checksum matches CIC-6102, mapping and ROM-tool tests pass with fault injection, and an endpoint co-simulation reads the image back and replays the mailbox traffic. Not yet run on an emulator or console.
- **Integration** ([notes](design/system-integration.md)): `sn64_top` connects all blocks across three clock domains with tested CDC helpers; `tb_system` passes the whole power-on sequence (STATUS `0x545F`) and found and fixed a /RESET deadlock. STATUS, FAULT and CONTROL layouts are reconciled between RTL and the menu.
- Design decisions recorded: the N64 endpoint runs from an always-on 62.5 MHz clock; the SNES master starts once at power-on at the detected region and never changes while running; a soft reset never removes cartridge power; the SNES CIC lock runs at 25 MHz / 8.
- Open: bootstrap ROM storage (64 block RAMs vs configuration flash or external RAM), A/V integration, board wrapper, ROM-header region fallback, whole-design place-and-route.

## 2026-09-29 — HDMI, round-2 blocks, board top level routed with real clocks

- **HDMI output** (720x480p frame-locked to the SNES, 32 kHz audio, [notes](design/av-output-implementation.md)) merged into `sn64_top`; the first whole-design place-and-route met all five clocks.
- **CIC data pins fixed in the schematic** (cart sheet rev 0.3.1): each CIC data pin has its own SN74LVC1T45 (U215/U216, LCSC C7843) with a dedicated DIR pin and provisional pull-downs; the shared-octet paths were removed. Cartridge checks 20/20 plus a 6-mutation negative test, ERC 0 errors (32 isolated_pin_label, 5 pin_to_pin), interface 30/30, USB 64/64. [sn64_cic_pad.sv](../fpga/rtl/sn64_cic_pad.sv) sequences DIR against the pad drive; its bench checks a translator model for contention (126 drive windows, none) and a fault build that switches both together is rejected.
- **ROM-header region fallback** ([notes](design/header-region-probe.md)): reads `$00:FFC0-$00:FFDF` twice with the cartridge held in /RESET and no SYSTEM_CLK; trusts it only if both reads match, the checksum pair complements, the map byte and country are known. Region priority is now forced > passing key CIC > valid header > NTSC. `tb_system` passes without a header (NTSC, STATUS `0x545F`) and with an EU header (PAL, `0x54DF`).
- **Bridge hardening:** the data octet's enable and direction are now also gated by bus permission combinationally, so they release even if the SNES clock has already stopped.
- **Bootstrap ROM from the configuration flash** ([notes](design/bootrom-flash.md)): SummerCart64 `memory_flash.sv` vendored unmodified behind the endpoint's ROM window. Bench with a QSPI flash model reads 1411 words in 15 bursts; 240 ns per word gives 1.53x margin at the standard ROM-header PI timing. Rule found: the menu must keep PI DOM1 LAT at the header's 0x40 (floor about 0x30) because the flash needs about 1 us for the first word.
- **Board top level** [sn64_board_top.sv](../fpga/rtl/sn64_board_top.sv): EHXPLLL 25 -> 62.5 MHz and pixel -> x5 (parameters from `ecppll`), one DCSC in glitchless falling-edge mode that both selects the NTSC/PAL master and starts/stops it (Lattice FPGA-TN-02200 Table 10.2: SEL 01 = CLK0, 10 = CLK1, 00 = held low), flash boot ROM through USRMCLK, CIC pads. Routed with trial constraints: all five clocks pass (SNES 27.3 MHz achieved vs 21.48 required); 41 % logic, 143/208 block RAMs. [Details](design/system-integration.md).
- Simulation suite: `evaluate.py --mode sim` passes all 30 recorded results, including every injected-fault run.
- Open: FPGA and power schematic sheets and the real pinout, clocks/HDMI/audio-ADC sheet, PAL HDMI raster, cartridge analog audio, header telemetry word, flash sysCONFIG/part selection.

## 2026-09-29 — Round 3: PAL HDMI, cartridge audio, telemetry, FPGA/power/A-V sheets, integration

Built by parallel helper agents with self-checking and fault-injection tests, then integrated into the shared files in one pass:

- **PAL HDMI 576p50** ([clock plan](design/clock-plan.md), [A/V notes](design/av-output-implementation.md)): 864x624 raster (CEA-861 VIC 17 timing with 624 lines so one 312-line SNES frame fills one HDMI frame), 4:3 AVI InfoFrame, pixel 27.0398584 MHz = PAL master x 108/85 from PLLB, MS2 31+13/27 (registers 58-65 = 00 1B 00 0D BD 00 00 11, register 18 = 0x2F), derived with Skyworks AN619 (SHA-256 recorded). `sn64_clock_init` rewrites only MS2 and register 18, never a PLL, and only while the SNES clock is stopped; the SNES clock waits for `pixel_clock_ready`. tb_clock_init passes and its new fault build (keeps writing after the SNES clock starts) fails; tb_av_out PAL passes (2,567,520 pixels exact, CTS 27288-27290) and a 625-line fault is rejected.
- **Finding (owner decision):** the prepared core's lines are 1360 master clocks in both regions (NTSC frame 356,320, PAL 424,320 clocks), not the 1364 the recorded NTSC 39/31 ratio assumes, so the NTSC HDMI raster re-phases every frame (about -1,328 px) and `av_locked` stays 0. The NTSC decision was not changed; options are in the clock plan.
- **Cartridge audio** ([notes](design/cart-audio-implementation.md)): `sn64_i2s_rx` oversamples the ADC's I2S lines at 62.5 MHz (sampling point justified from the 1996 Philips I2S spec, SHA-256 recorded); `sn64_audio_mix` crosses frames into clk_snes through an 8-frame elastic buffer that drops or repeats exactly one sample and adds them to the DSP stream with 16-bit saturation. Passes at ±500 ppm and at the core's real rate, also four-state in Icarus; four fault builds fail. Gain 1.0 and 0 dB headroom are provisional.
- **Finding (owner decision):** the pinned SNESTang DSP runs at 32,179.96 Hz (NTSC) / 31,886.43 Hz (PAL), not 32 kHz.
- **Region telemetry:** REGION_INFO (0x1A) and REGION_SOURCE (0x1C) mailbox words, snapshot at SNES clock start; the menu shows "Region: PAL via key CIC" and the header result; bootstrap rebuilt (114,688 bytes, CIC-6102 OK). `tb_system` now has the key CIC model on the CIC pins: a PAL key beats an NTSC header, an NTSC key beats a PAL header, and a corrupted key is rejected.
- **FPGA sheet** rev 0.4-fpga ([notes](design/fpga-schematic.md)): all 381 LFE5U-85F CABGA381 balls assigned; W25Q128JVSIQ configuration flash (LCSC C97521); master-SPI straps; PROGRAMN held until `fpga_rails_ok`; N64 edge through three host-gated SN74CB3Q3384A switches; the board pinout [sn64_board.lpf](../fpga/constraints/sn64_board.lpf) and pin-map CSV are generated from the same table.
- **Power sheet** ([notes](design/power-schematic.md)): TPS259470L priority mux of HOST_3V3 and USB_VBUS (USB allowed only when a TUSB320 sees 1.5 A or 3 A), TPS63070 5V_PRE, three TLV62569 FPGA rails, default-off cartridge eFuse and interface load switch, TPS3700/TPS3808/TMP302A monitors that read "not OK" when their supply is lost.
- **Clock/HDMI/cartridge-audio sheet** ([notes](design/av-clock-schematic.md)): Si5351A with a 25 MHz 10 pF crystal (matches register 183 = 0xD2, cross-checked from the RTL), 25 MHz FPGA oscillator, HDMI type-A with a TPD12S016 and ULX3S-style 22 nF TMDS coupling, PCM1808 I2S master at 384 fs from a 12.288 MHz oscillator (fs 32 kHz) behind a console-equivalent 196 ohm load and 0.5 gain. SNES audio is not routed to N64_AUDIO_L/R (no requirement).
- **Integration** ([details](design/system-integration.md#schematic-integration-round-3-2026-09-29)): the root (rev 0.4-r3, A2) now holds all five child sheets, every contract name wired by same-name labels; the USB sheet exports VBUS/USB_3V3/CC/JTAG/TARGET_VREF and R101/R102 are DNP (the TUSB320 presents Rd). Fixed on the way: about 80 duplicate designators between the FPGA and power sheets (FPGA sheet renumbered to 4xx in its generator), five duplicate PWR_FLAG ERC errors, and validator assumptions that only held for unattached sheets (each negative test still catches every fault; the FPGA JTAG check was tightened after a parallel USB-sheet pull masked one fault). Results on the real root: ERC 0 errors (5 isolated_pin_label on reserved N64 labels, 5 pin_to_pin unchanged); interfaces 30/30; USB 69/69 plus a fault injection; cartridge 20/20 and 6/6; power 23/23 and 11/11; A/V 30/30 and 12/12; FPGA 12/13 and 10/10; new root-connectivity check 4/4 (141 contract names) and 4/4. The PDF was regenerated but not visually inspected.
- **Integration finding (owner decision):** `efuse_fault_n` comes from a 12.1k/20k divider on 5V_PRE (a recorded power-sheet choice) and reaches FPGA ball K4, which the FPGA sheet's 5 V rule rejects; it is the one failing FPGA check. Also pending owner review: cartridge enable pull-ups R206-R208 10k vs 4.7k (FPGA sheet finding) and the TLV62569 input from 5V_PRE (power sheet).
- **RTL integration:** the PAL HDMI and cartridge-audio edits merged into `sn64_top`/`tb_system`/`evaluate.py`; `sn64_board_top` gained the pad adapters the schematic needs (cart_data inout, open-drain Si5351 I2C, cart_reset_pull_n, expand_sense, reserved JOYBUS/INT/HPD/DDC, adc_*). `route_top.py --top board` now uses the real LPF: all five clocks pass (SNES 28.94 MHz vs 21.48, host 86.26 vs 62.5, TMDS 170.85 vs 135.21; `si_clk2` constrained at the PAL 27.0399 MHz), 121/365 I/O, 43 % logic, 143/208 block RAMs.
- **Simulation suite:** `evaluate.py --mode sim` exit 0 with 86 recorded commands; all 23 non-zero exits are the intended fault injections.
- Open: board-level I/O timing, footprints left empty on purpose (eFuse, TPS63070, inductors, J701 -111RLF variant), PCB/SI/PDN, `sn64_pnr_wrap.sv` still lacks the ADC ports, license notes in `hardware/sn64/THIRD_PARTY.md` for the new ULX3S facts.

## 2026-09-29 — Two SNES core timing bugs fixed; HDMI locks in NTSC

- **Long dots (video timing).** The SNESTang Verilog port turned MiSTer's `H_CNT = 323 or H_CNT = 327` into `H_CNT == 323 && H_CNT == 327`, which is never true. Every scanline was 1360 master clocks instead of hardware's 1364, so the console ran about 0.3 % fast (60.27 Hz instead of 60.10 Hz) and scanline-timed behaviour differed from a real SNES. The bug is still on SNESTang master. `prepare_core.py` now patches the generated copy; measured afterwards: NTSC frames alternate 357,368 / 357,364 clocks (hardware short line), PAL frames are 425,568.
- **Audio rate.** SNESTang raised the S-DSP clock-enable target by 0.5625 % (`ACLK_FREQ 411904`, the original 409600 kept commented out) and divided by the NTSC master even in PAL. The DSP ran at 32,179.96 Hz (NTSC) / 31,886.43 Hz (PAL). Patched back to MiSTer behaviour: 32,000 Hz in both regions, so pitch and tempo are right and the 32 kHz cartridge-audio ADC almost never slips.
- **HDMI pixel clocks.** NTSC MS2 = 31 + 14887/18733 (27.0199459 MHz): one 858 x 524 frame equals the mean SNES frame, so the raster never re-phases; `LOCK_TOL` 2 -> 8 pixels absorbs the ±5-pixel short-line wobble. PAL MS2 = 31 + 31/54 (26.9605626 MHz, 50.007 Hz). `tb_system` now checks frame lock in NTSC too, with exact clock ratios.
- **Power/schematic decisions closed.** `efuse_fault_n` pulled up to FPGA_3V3 (a 5V_PRE divider would back-drive a non-hot-socket ECP5 bank, DS-02012 section 3.6); cartridge enable pull-ups 10k -> 4.7k (ECP5 configuration-time pull-down up to 150 µA, Table 3.7); FPGA bucks fed from 5V_PRE accepted (a buck cannot make 3.3 V from the host's 3.3 V).
- Sources: MiSTer `SNES_MiSTer` commit `c61bfd45171c62000417333cd4679890bcd091a6` (`rtl/PPU.vhd` lines 323-324, `rtl/DSP.vhd` lines 238-247).

## 2026-09-29 — Console video path: frames and audio to the N64 over the cartridge bus

- **Decision (owner):** the SNES picture and sound go to the console through the cartridge bus and the boot program shows them on the console's own output (N64 AV jack, M64 HDMI). This is the primary A/V path; the board's own HDMI is secondary and is to be removed unless kept on purpose. Design: [console-video-path.md](design/console-video-path.md).
- **FPGA side done in simulation:** `sn64_frame_window` (RGBA5551 frame buffer + audio ring) behind the vendored PI controller's SRAM window at `0x0800_0000` (PI domain 2, fast timing), three new mailbox words. Bench: a full frame reads back exactly at 128 ns/word (15.6 MB/s, 2.3× the 60 Hz need) while following the line counter; R/B-swap fault build fails; whole-system runs read frames from the real core in NTSC and PAL. Suite: 42/42.
- **Next:** the boot program's display loop (libdragon: PI domain-2 timing, frame DMA following `lines_done`, VI 256×224 16-bit, AI 32 kHz), then HDMI removal from the schematic/board, then routing.
- **PCB:** six shell-screw holes (2.5 mm), corrected SummerCart64 outline, connectivity-pulled placement.
- Setback acknowledged: the HDMI output block and its schematic corner were built on the spec's "independent digital output" line without confirming intent with the owner.

## 2026-09-29 — On-board HDMI output removed; the console output is the only video path

- **Decision (owner):** the SNES picture and sound must reach the TV through the console's own output (M64 HDMI, N64 AV jack) by way of the cartridge bus. The board's own HDMI port, built on the spec's "independent digital output" wording without confirming intent, is removed rather than kept as a secondary output. Retirement record: [av-output-implementation.md](design/av-output-implementation.md).
- **FPGA:** deleted `sn64_av_out`, `sn64_av_hdmi_tx`, `sn64_av_serializer`, `tb_av_out` and the vendored hdl-util/hdmi tree. `sn64_clock_init` no longer programs MultiSynth 2 or retargets CLK2: CLK2 stays powered down, register 3 = 0xFC, nothing is written after start-up, and the SNES clock waits only for lock and the region decision. The board top keeps one EHXPLLL (host) and loses `si_clk2` and the `hdmi_*` ports. `evaluate.py --mode sim` exit 0, 38 recorded results (the clock-init bench was rewritten: register image with CLK2 off, region latch stopped/running, zero I2C STARTs after start-up; the `+wrong_addr` negative run stays). Routed on the real pinout: 203/208 DP16KD, 113/365 I/O, 41 % logic, 1 PLL; host 72.5 MHz vs 62.5, SNES 26.7 vs 21.5, housekeeping 57.4 vs 25, all pass.
- **Schematic:** FPGA sheet rev 0.5-fpga (12 ports fewer: the four TMDS pairs, HPD/DDC and `si_clk2`; bank 1 spare; LPF and pin-map CSV regenerated from the same table), A/V sheet draft 0.2-av (J701, U702 TPD12S016, C704-C714, TP701, R705 gone; Si5351 pin 6 open with a no-connect), both root sheet symbols re-packed by a one-off script. ERC 0 errors and the same 10 warnings as before. Checks on the real root: interfaces 31/31, USB 69/69, cartridge 20/20 (negative 6/6), FPGA 14/14 with the Lattice CSV (negative 10/10; new check: no HDMI or `si_clk2` port in the LPF or board top), power 23/23 (negative 12/12), A/V 27/27 (negative 10/10; new check: CLK2 open on the sheet and disabled in the RTL, with a mutation that wires it back), root connectivity 4/4 (negative 4/4), socket joint 9/9 (negative 3/3). Power budget rows PWR-L37/L38 (HDMI +5 V, TPD12S016) removed.
- **Board:** rebuilt from the new netlist by `build_main_pcb.py` (410 parts, 530 nets; the right-edge zone that held the HDMI receptacle is free). The first rebuild left two 10 uF capacitors and a test point overlapping on the bottom side, so the FPGA-support bottom zone was widened; DRC now reports only the USB-C receptacle pads at the board edge (by design) and the N64 fingers' shared solder-mask opening (SummerCart64 footprint), no shorts or courtyard overlaps. Renders and the PDF regenerated. Still nothing routed.
- **Docs:** clock plan, FPGA schematic, system integration (new "HDMI output removed" section with the route numbers), cartridge audio, console video path, architecture, risk assessment, requirements register, acceptance matrix rows SN64-07-01/09-01, READMEs, THIRD_PARTY and CLAUDE.md updated; the retired HDMI sections in the clock plan are marked as such rather than deleted.
- Cost of the detour: about one evening of HDMI work; what survives is the two SNES core timing fixes found while locking the raster and the cartridge-audio path, which now feeds the console.

## 2026-09-30 — First routed draft of the main board

- **Preparation (scripted, KiCad python):** 240 dog-bone fan-out vias for the caBGA-381 (0.45/0.2 mm, 0.4 mm diagonal), GND plane on In1, FPGA_3V3 plane on In3, FPGA_1V1 island on In4, power/usb net classes, keep-out over the N64 finger tongue, plane vias beside plane-net pads where a spot is free. Decoupling moved out of the via field after the first fan-out landed on it; FPGA rotated 180° after the first autoroute left the whole N64 bus unrouted (bank 0 faced away from the bus switches); hole-to-copper relaxed to PCBWay's 0.2 mm.
- **Routers tried:** Freerouting 2.4.1 (local API server; single-threaded per run, time-slices jobs in one instance, so a second instance was scripted): about 335 nets after 2 h 20 min. KiCadRoutingTools v0.22 (Rust A*, per-user install): all 375 signal nets attempted in 5 min, 300 connected in 30-60 min; its default "fab tier" escalation narrowed 4,280 features below the board rules until pinned with `fab-pcbway.txt`; placing plane vias before routing (run 3) cost 90 signal nets; its plane-tap pass and a Freerouting finishing pass on its output both reverted or degraded the board.
- **Result on the tracked board:** run 2 routing + 157 plane vias + outer pours; DRC has no shorts, crossings, clearance or hole errors (18 USB-C edge pads by design, 79 starved thermals, N64 finger mask). Open: 75 signal/power nets (95 connections) and 219 plane pads. Renders and the open-connection list are in `hardware/sn64/exports` and `validation`. Notes: [pcb-routing.md](design/pcb-routing.md).
- **PCBWay capability check (2026-09-30):** hole-to-copper 8 mil, edge 0.25 mm, via drill 0.15 mm, annular 6 mil (board vias have 0.125 mm), trace/space 4/5 mil (board spacing 0.1 mm). Annular ring and spacing must be settled with the quote before the final layout pass.
- **KiCad 10 python finding:** `PCB_VIA.GetWidth()` without a layer argument raises an internal assertion that opens a hidden dialog and hangs the process; `board.Remove()` leaves later lookups as bare SWIG pointers in the same process. Both recorded in the scripts.
- Cost: the night of 2026-09-29/30. The owner asked for speed; the honest lesson is that autorouting a 381-ball BGA board on a block-zone placement leaves a fifth of the work for hand routing whichever tool is used, and that the placement (translator row) is the next thing to improve, not the router.

## Remaining work

Select and validate the FPGA/storage and physical-cartridge bridge, complete system/cartridge power and protection, N64 endpoint, controller/firmware functions, clocks, A/V and diagnostics. Retain PAL and the required M64 single-HDMI target; its supported integration mechanism remains unresolved. Complete PCB placement/routing and the FreeCAD enclosure, then perform electrical, programming, compatibility and fit tests on prototypes before producing a PCBWay release. No working SN 64 hardware or fabrication-ready package exists yet.

## 2026-10-01 — licences, attribution notice and credits

Owner decision: code is GPL-3.0-or-later, hardware and docs are CERN-OHL-S-2.0, credit line "SN64 by FantomZap" with this repository as the source location. Added at the top level: the two licence texts, [LICENSING.md](../LICENSING.md), [NOTICE](../NOTICE) and [CREDITS.md](../CREDITS.md), which lists everyone the project borrows from. Current design work is on the `v2` branch; its work log has the details.

## 2026-10-01 — local user-folder paths removed from the tracked files

The repository is public and its notes, scripts, check reports and KiCad netlists carried absolute paths with the Windows user folder in them. No file from outside the project was ever uploaded; the exposure was the folder name inside those paths. `tools/scrub_local_paths.py` now replaces that prefix in every tracked text file (`%USERPROFILE%` in notes, reports and netlists, `$env:USERPROFILE` in PowerShell scripts, `$HOME` in shell scripts and snippets); it reads the name from the PC at run time, so the tool does not contain it. Scripts still resolve their tools; JSON and XML reports still parse. A local pre-commit hook refuses commits that contain the path. Applied to the tips of all public branches. Earlier commits still hold the old text until the history is rewritten, which is the owner's call.

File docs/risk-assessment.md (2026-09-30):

# SN64 risk assessment

Quick assessment, 2026-09-29, based on the current design documents. Levels are engineering judgment, not measurements. All specification targets remain in scope; this document orders work by risk and does not remove anything.

| # | Risk | Level | Response |
|---|---|---|---|
| 1 | **Power.** The N64/M64 slot has no 5 V contact and limited current: the M64 limiter is set near 500 mA at 3.3 V, about 1.65 W. The FPGA, a SNES cartridge (especially Super FX, SA-1 or FXPAK Pro) and video output plausibly need more. | High | Close the power budget first. Expect the mandatory side USB-C port to be needed for power during play, particularly on original N64. Cartridge power stays off until hardware checks pass. |
| 2 | **Video path.** The picture reaches the console as frame data over the cartridge bus (PI domain 2: 6.9 MB/s needed, 15.6 MB/s in simulation) and the boot program shows it on the console's own output. Real PI timing, the VI's handling of a 256-wide framebuffer on both hosts and the one-frame latency are unproven on hardware. | High | Prototype-first checks: measure the sustained PI rate on an N64 and an M64, verify the picture on both, keep a 320x240 centred framebuffer as the fallback. The board has no video output of its own. |
| 3 | **Real-cartridge timing.** The FPGA must reproduce SNES bus timing closely enough for real cartridges. Enhancement chips and FXPAK Pro are sensitive. SNESTang was built around loaded ROM images, not a physical slot. | High | Feasibility is proven commercially: Analogue Super Nt runs real cartridges on an FPGA SNES. Build the bridge in simulation with contention/timing checks, then prove it on inexpensive development hardware before the custom board. |
| 4 | **Board complexity.** ECP5 BG381 is a 0.8 mm-pitch BGA. It needs a 4–6 layer board, careful fan-out and power integrity, and X-ray-inspected assembly. PCB layout is the weakest area for automated design. | High | Reuse a proven open ECP5 layout (ULX3S, observing its logo condition), or evaluate an off-the-shelf ECP5 module on a simpler carrier board. Independent review before any order. |
| 5 | **N64 host side.** The adapter must pass the N64 CIC lockout and run an N64 program for the menu and controller transfer. | Medium | Reuse SummerCart64 (proven PI/CIC/SI endpoint) and the libdragon N64 SDK. |
| 6 | **Damaging hardware during bring-up.** | Medium | First power-ups use a current-limited supply with no console or cartridge. Early host tests use an inexpensive used N64 and an inexpensive cartridge, not the M64 or valuable games. |
| 7 | **Physical fit.** A tall assembly levers on the host slot. M64 door/eject clearance and varied cartridge shells must fit. | Medium | Buy a socket sample (~US$10). Iterate with 3D-printed fit coupons before the full enclosure. |
| 8 | **Parts availability.** `LFE5U-85F-6BG381C` shows no stock until 2027; `-8BG381I` was in stock (60 units). | Medium | Design for an orderable part. Recheck stock before committing the BOM. |
| 9 | **Cost and revisions.** First boards rarely work unchanged. Expect 2–3 board revisions and basic test equipment (multimeter; ideally an inexpensive logic analyzer). | Medium | Retire the largest risks cheaply before the full custom board. |
| 10 | **Scope.** The specification includes PAL, telemetry, factory test, recovery and M64 HDMI. The risk is never reaching a working unit. | Medium | Staged milestones: first a playable cartridge path, then host integration, then the remaining targets in order. |
| 11 | **M64 unknowns.** A newer console whose firmware can change, with MCU-controlled cartridge power and limited documentation. | Medium | Test on a real M64 early. Do not depend on undocumented behavior. |
| 12 | **Licensing.** GPL-3.0 core, CERN-OHL-S-2.0 SummerCart64 hardware, the ULX3S logo condition and Nintendo trademarks matter if the product is ever sold. | Low now | Already tracked per source. Review before any sale or public release. |

## Verification limits

Software checks — simulation, ERC/DRC, comparison against proven designs and independent review — catch most design errors before ordering. They cannot establish real-cartridge timing margins, actual power draw, thermal behavior, noise or host-console behavior. Those require physical tests, performed by the user with guided procedures. Verification therefore happens throughout the work, with the riskiest parts proven early, not only as a final check.

## Recommended de-risking milestone

Before the full custom board, prove the hardest path on inexpensive hardware: an ECP5 development board (for example ULX3S-85F, about US$275) plus a small, simple adapter board carrying the SNES socket and level translators. Target: a real SNES cartridge playing through the FPGA core with HDMI output, powered over USB, with no N64 involved. Success retires risks 3 and much of 1 and 4 before committing to the BGA board.

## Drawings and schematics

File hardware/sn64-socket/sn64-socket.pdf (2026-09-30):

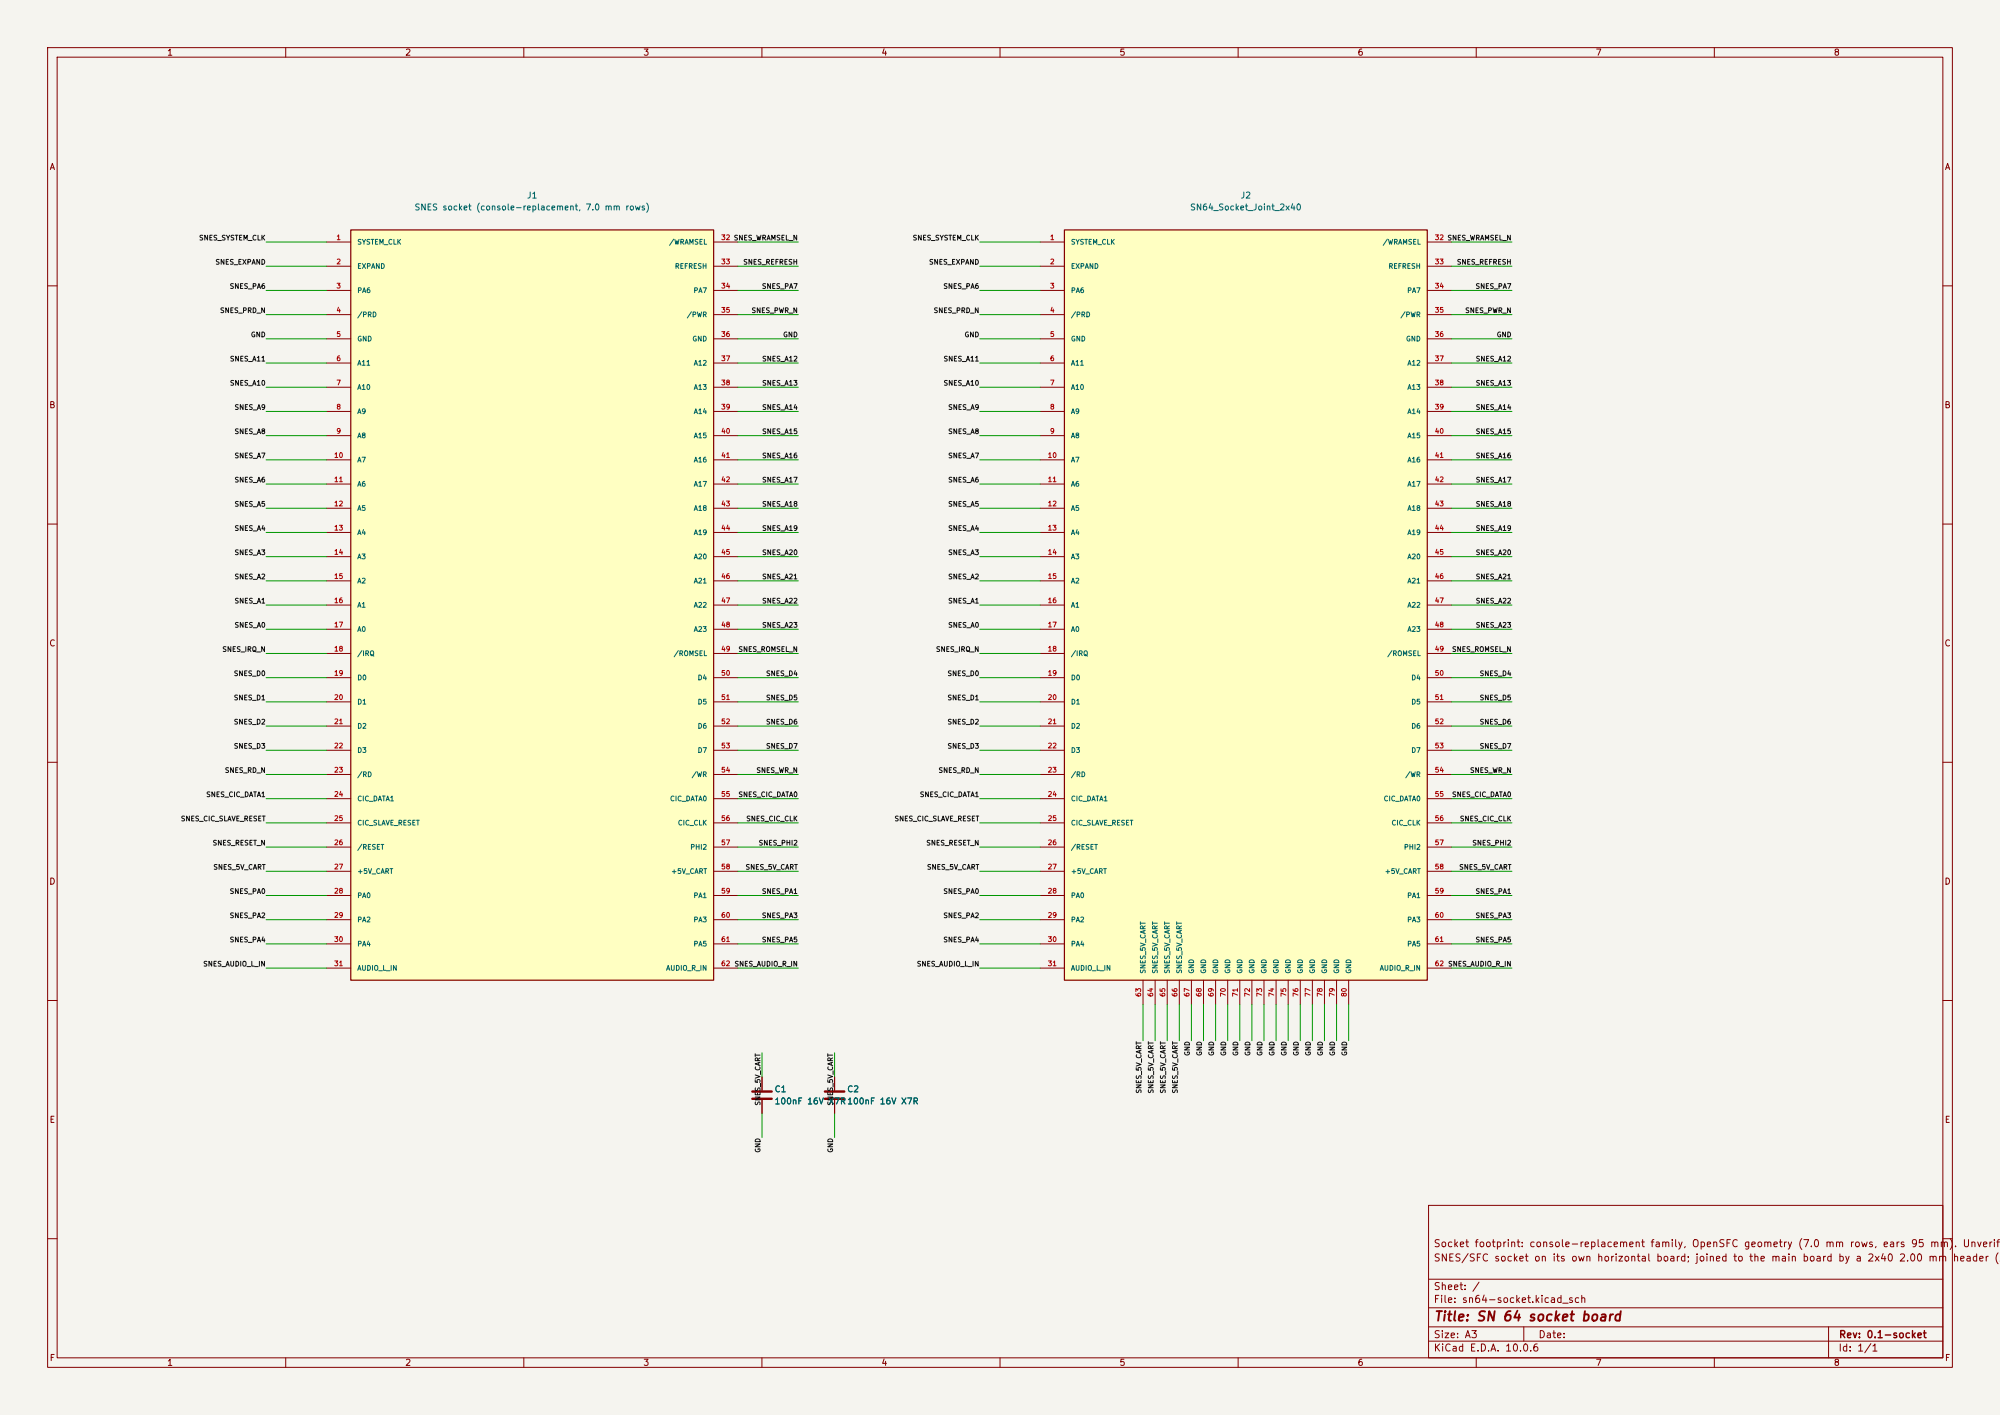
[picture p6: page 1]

Socket footprint: console-replacement family, OpenSFC geometry (7.0 mm rows, ears 95 mm). Unverified on a sample; see docs/dimensions.md.
SNES/SFC socket on its own horizontal board; joined to the main board by a 2x40 2.00 mm header (J2 on both boards). Net names match the main root sheet.

Sheet: /
File: sn64-socket.kicad_sch
Title: SN 64 socket board

Size: A3 | Rev: 0.1-socket | F Date:
KiCad E.D.A. 10.0.6 | Id: 1/1

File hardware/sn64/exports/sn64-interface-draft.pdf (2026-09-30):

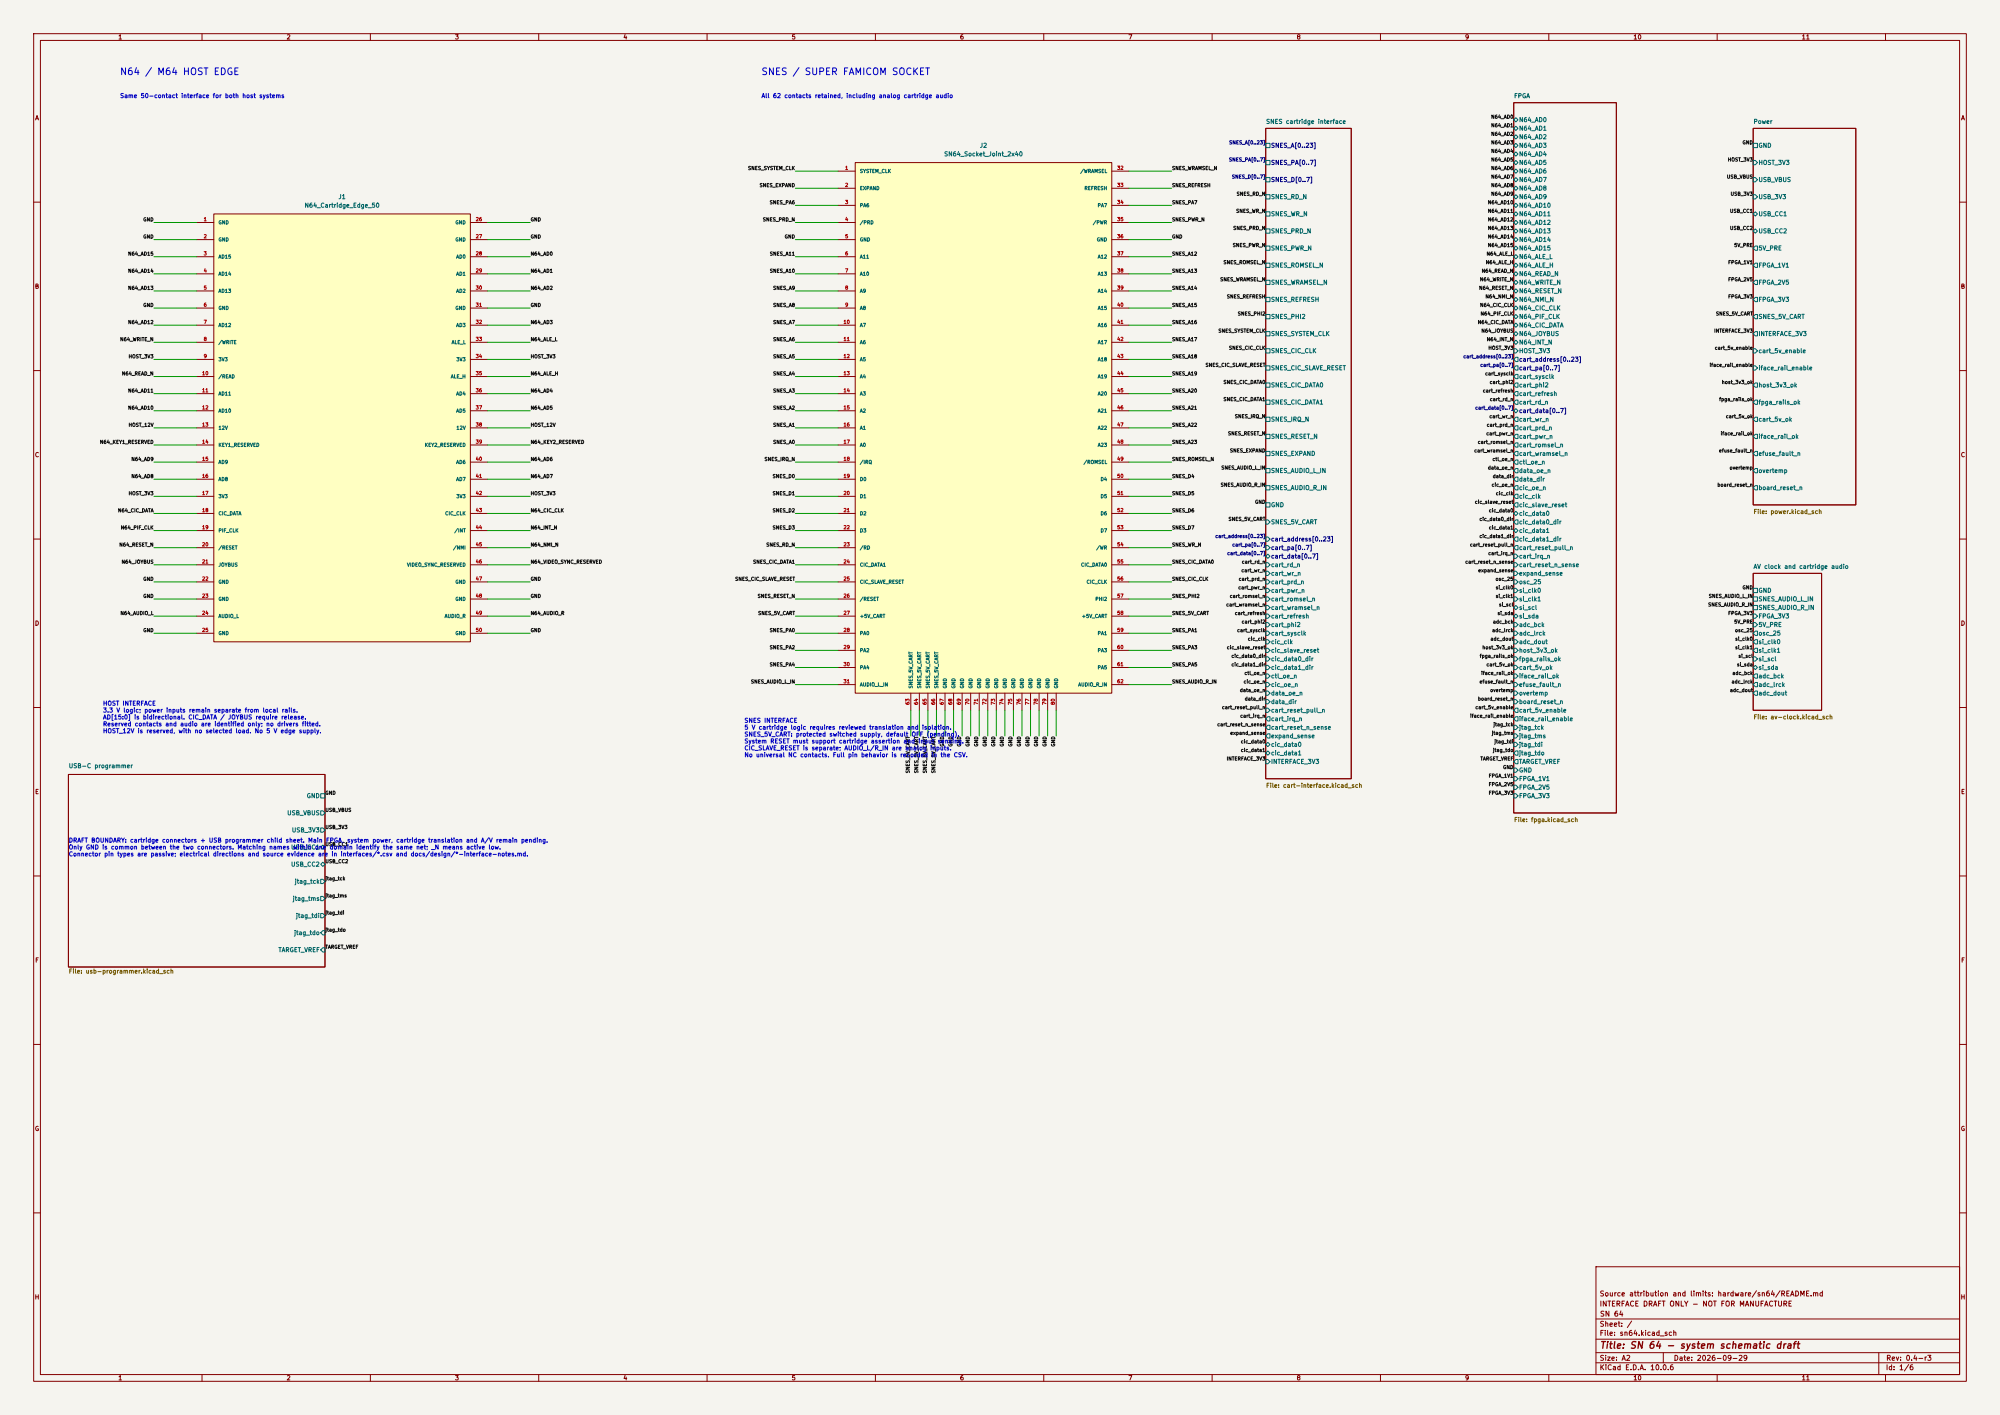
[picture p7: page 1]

SNES / SUPER FAMICOM SOCKET

Same 50-contact interface for both host systems

All 62 contacts retained, including analog cartridge audio

adc_bck adc_lrck adc_dout AV clock and cartridge audio

System RESET must support cartridge assertion and input sensing. CIC_SLAVE_RESET is separate; AUDIO_L/R_IN are analog inputs. No universal NC contacts. Full pin behavior is recorded in the CSV.

TARGET_VREF USB-C programmer File: usb-programmer.kicad_sch

Source attribution and limits: hardware/sn64/README.md
INTERFACE DRAFT ONLY - NOT FOR MANUFACTURE
Sheet: /
File: sn64.kicad_sch
Title: SN 64 - system schematic draft

Size: A2 | Rev: 0.4-r3
KiCad E.D.A. 10.0.6 | Id: 1/6

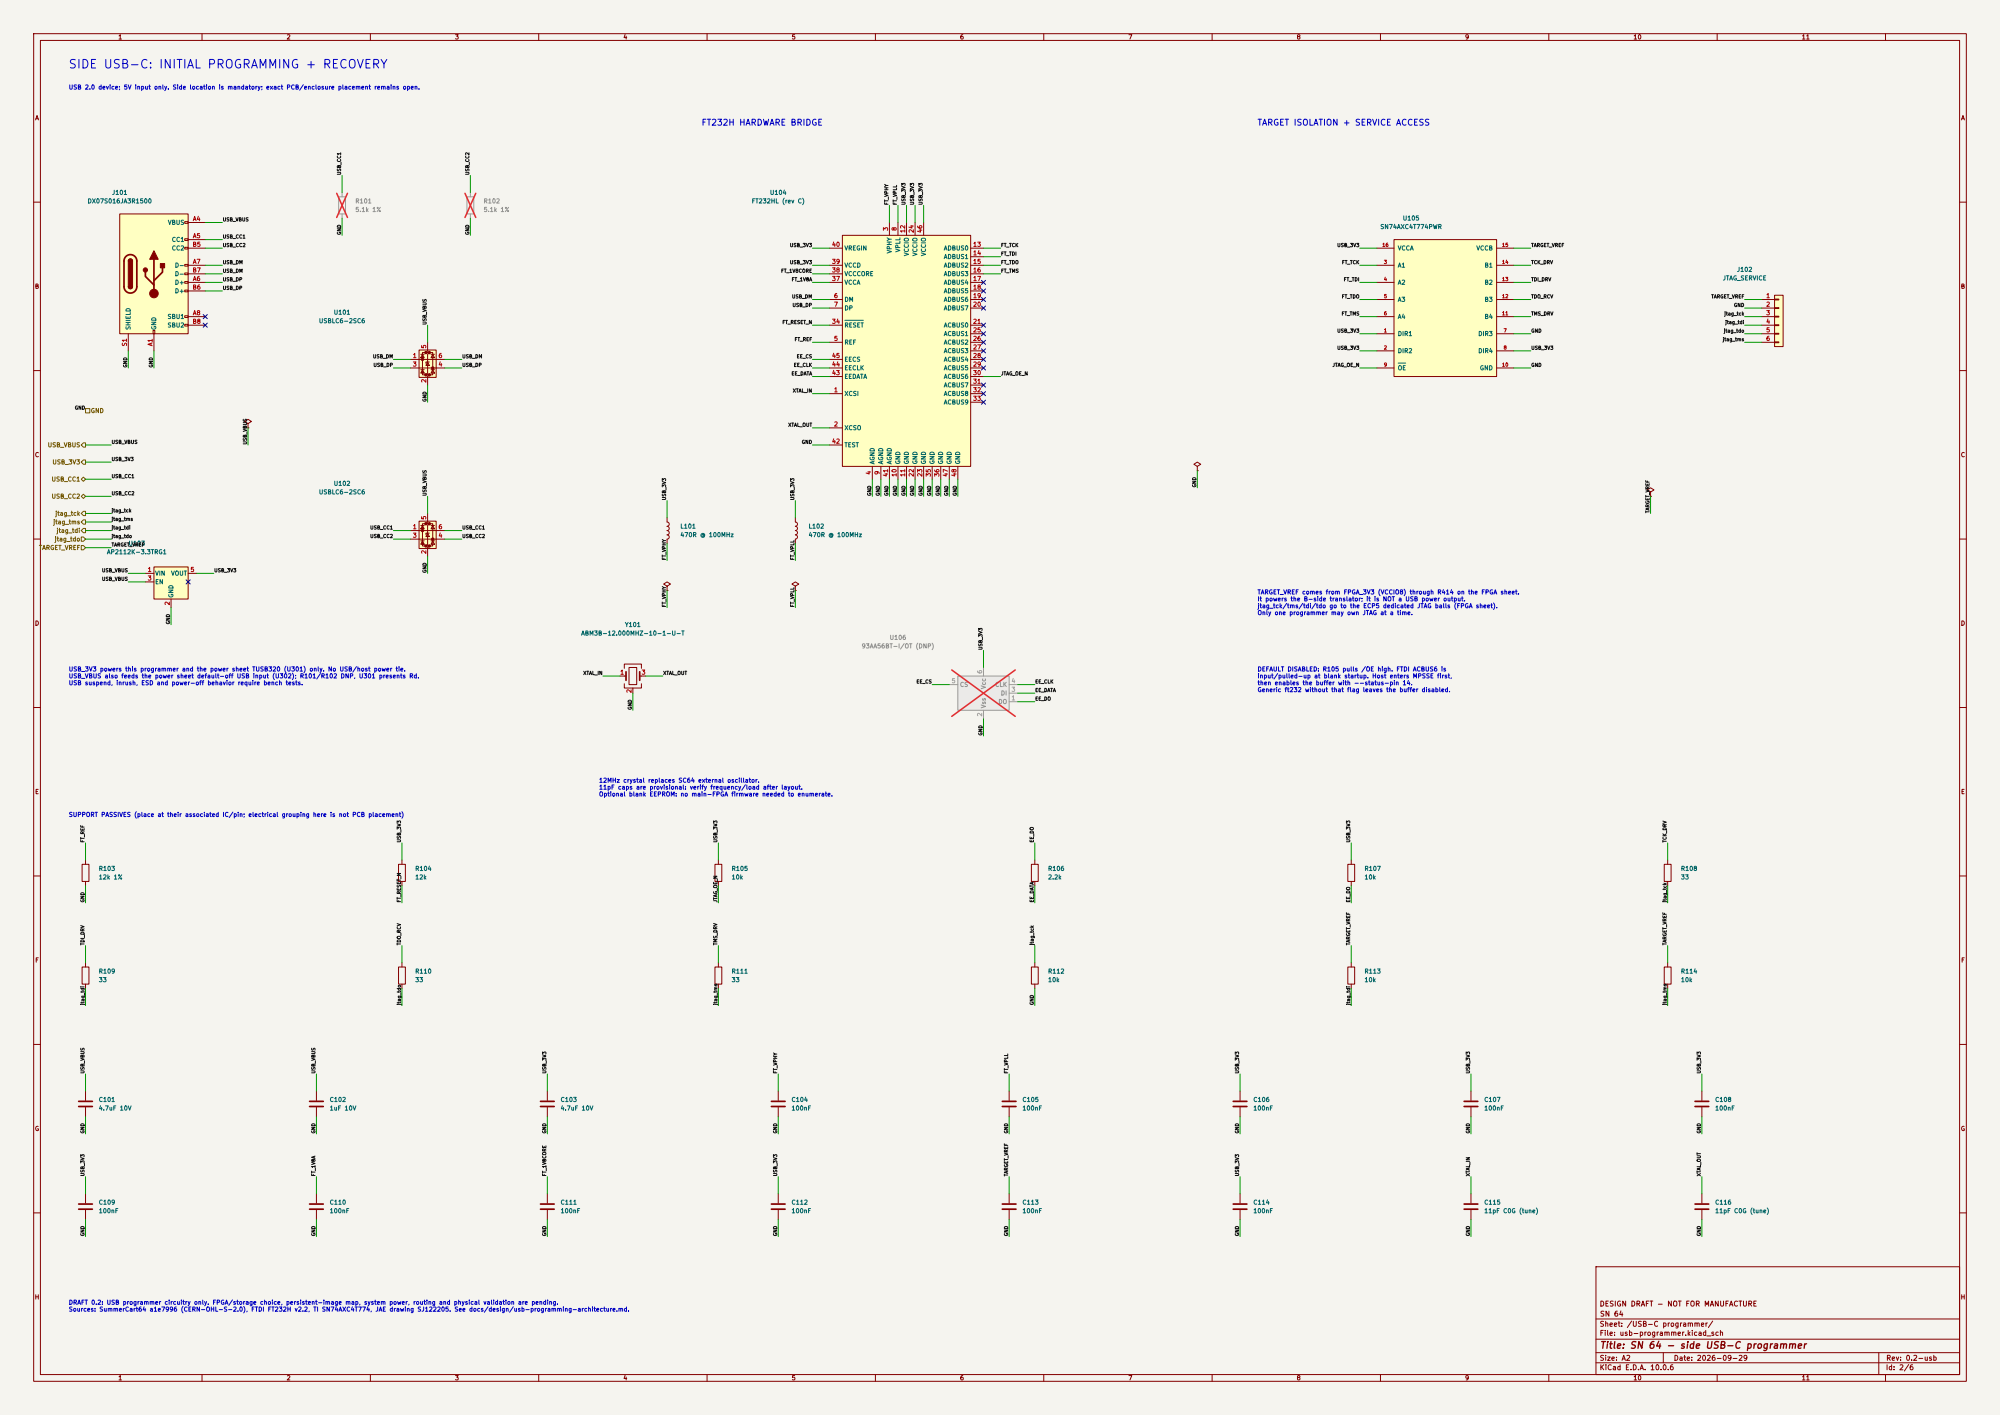
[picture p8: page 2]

SIDE USB-C: INITIAL PROGRAMMING + RECOVERY

4 REF 5 DM 6 DP 7 VPLL 8 AGND

DESIGN DRAFT - NOT FOR MANUFACTURE GND A1
TARGET_VREF USB_VBUS USB_3V3 USB_CC1 USB_CC2

input/pulled-up at blank startup. Host enters MPSSE first, then enables the buffer with --status-pin 14. Generic ft232 without that flag leaves the buffer disabled. TARGET_VREF comes from FPGA_3V3 (VCCIO8) through R414 on the FPGA sheet.
It powers the B-side translator; it is NOT a USB power output.
jtag_tck/tms/tdi/tdo go to the ECP5 dedicated JTAG balls (FPGA sheet).
Only one programmer may own JTAG at a time.

Optional blank EEPROM: no main-FPGA firmware needed to enumerate.

DRAFT 0.2: USB programmer circuitry only. FPGA/storage choice, persistent-image map, system power, routing and physical validation are pending. Sources: SummerCart64 a1e7996 (CERN-OHL-S-2.0), FTDI FT232H v2.2, TI SN74AXC4T774, JAE drawing SJ122205. See docs/design/usb-programming-architecture.md.

Sheet: /USB-C programmer/
File: usb-programmer.kicad_sch
Title: SN 64 - side USB-C programmer

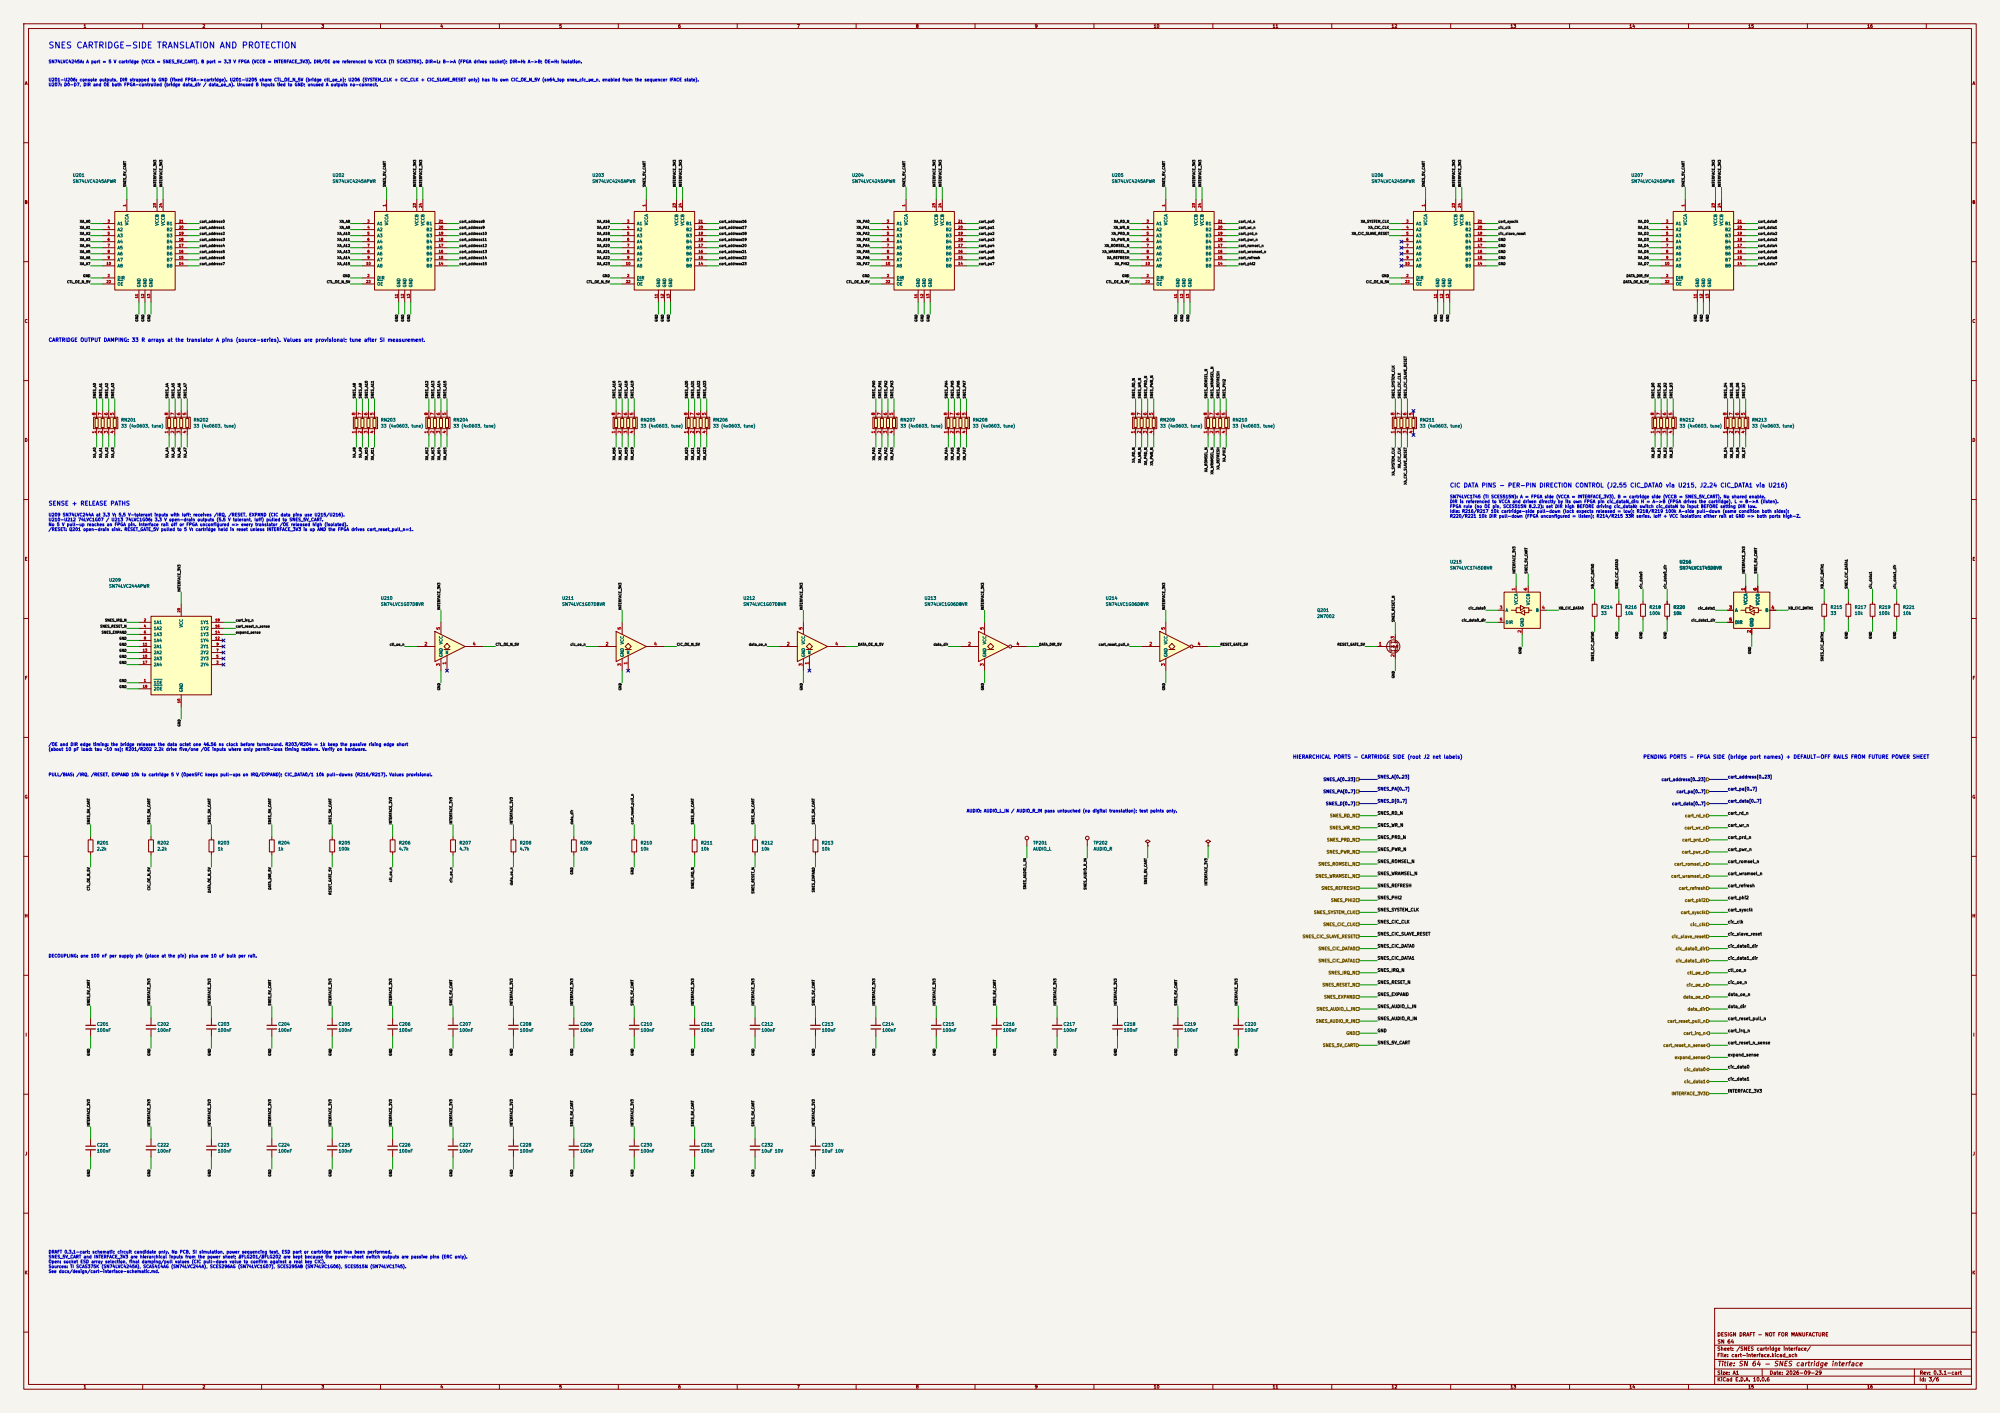
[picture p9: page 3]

SNES CARTRIDGE-SIDE TRANSLATION AND PROTECTION

SN74LVC4245A: A port = 5 V cartridge (VCCA = SNES_5V_CART), B port = 3.3 V FPGA (VCCB = INTERFACE_3V3). DIR/OE are referenced to VCCA (TI SCAS375K). DIR=L: B->A (FPGA drives socket); DIR=H: A->B; OE=H: isolation. U201-U206: console outputs, DIR strapped to GND (fixed FPGA->cartridge). U201-U205 share CTL_OE_N_5V (bridge ctl_oe_n); U206 (SYSTEM_CLK + CIC_CLK + CIC_SLAVE_RESET only) has its own CIC_OE_N_5V (sn64_top snes_cic_oe_n, enabled from the sequencer IFACE state). U207: D0-D7, DIR and OE both FPGA-controlled (bridge data_dir / data_oe_n). Unused B inputs tied to GND; unused A outputs no-connect.

1 DIR 2 A1 3 A2 4 A3 5 A4 6 A5 7 A6 8 A7 9 A8 10 GND 11 GND 12 GND 13 B8 14 B7 15 B6 16 B5 17 B4 18 B3 19 B2 20 B1 21 OE 22 VCCB 23 VCCB 24 U201

1 DIR 2 A1 3 A2 4 A3 5 A4 6 A5 7 A6 8 A7 9 A8 10 GND 11 GND 12 GND 13 B8 14 B7 15 B6 16 B5 17 B4 18 B3 19 B2 20 B1 21 OE 22 VCCB 23 VCCB 24 U202

1 DIR 2 A1 3 A2 4 A3 5 A4 6 A5 7 A6 8 A7 9 A8 10 GND 11 GND 12 GND 13 B8 14 B7 15 B6 16 B5 17 B4 18 B3 19 B2 20 B1 21 OE 22 VCCB 23 VCCB 24 U203
SN74LVC4245APWR

CARTRIDGE OUTPUT DAMPING: 33 R arrays at the translator A pins (source-series). Values are provisional; tune after SI measurement.

CIC DATA PINS - PER-PIN DIRECTION CONTROL (J2.55 CIC_DATA0 via U215, J2.24 CIC_DATA1 via U216)

U209 SN74LVC244A at 3.3 V: 5.5 V-tolerant inputs with Ioff; receives /IRQ, /RESET, EXPAND (CIC data pins use U215/U216). U210-U212 74LVC1G07 / U213 74LVC1G06: 3.3 V open-drain outputs (5.5 V tolerant, Ioff) pulled to SNES_5V_CART. No 5 V pull-up reaches an FPGA pin. Interface rail off or FPGA unconfigured => every translator /OE released high (isolated).

Idle: R216/R217 10k cartridge-side pull-down (lock expects released = low); R218/R219 100k A-side pull-down (same condition both sides);
R220/R221 10k DIR pull-down (FPGA unconfigured = listen); R214/R215 33R series. Ioff + VCC isolation: either rail at GND => both ports high-Z.

DRAFT 0.3.1-cart: schematic circuit candidate only. No PCB, SI simulation, power sequencing test, ESD part or cartridge test has been performed. SNES_5V_CART and INTERFACE_3V3 are hierarchical inputs from the power sheet; #FLG201/#FLG202 are kept because the power-sheet switch outputs are passive pins (ERC only).

Open: socket ESD array selection, final damping/pull values (CIC pull-down value to confirm against a real key CIC). Sources: TI SCAS375K (SN74LVC4245A), SCAS414AG (SN74LVC244A), SCES296AG (SN74LVC1G07), SCES295AB (SN74LVC1G06), SCES515N (SN74LVC1T45). See docs/design/cart-interface-schematic.md.

DESIGN DRAFT - NOT FOR MANUFACTURE
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

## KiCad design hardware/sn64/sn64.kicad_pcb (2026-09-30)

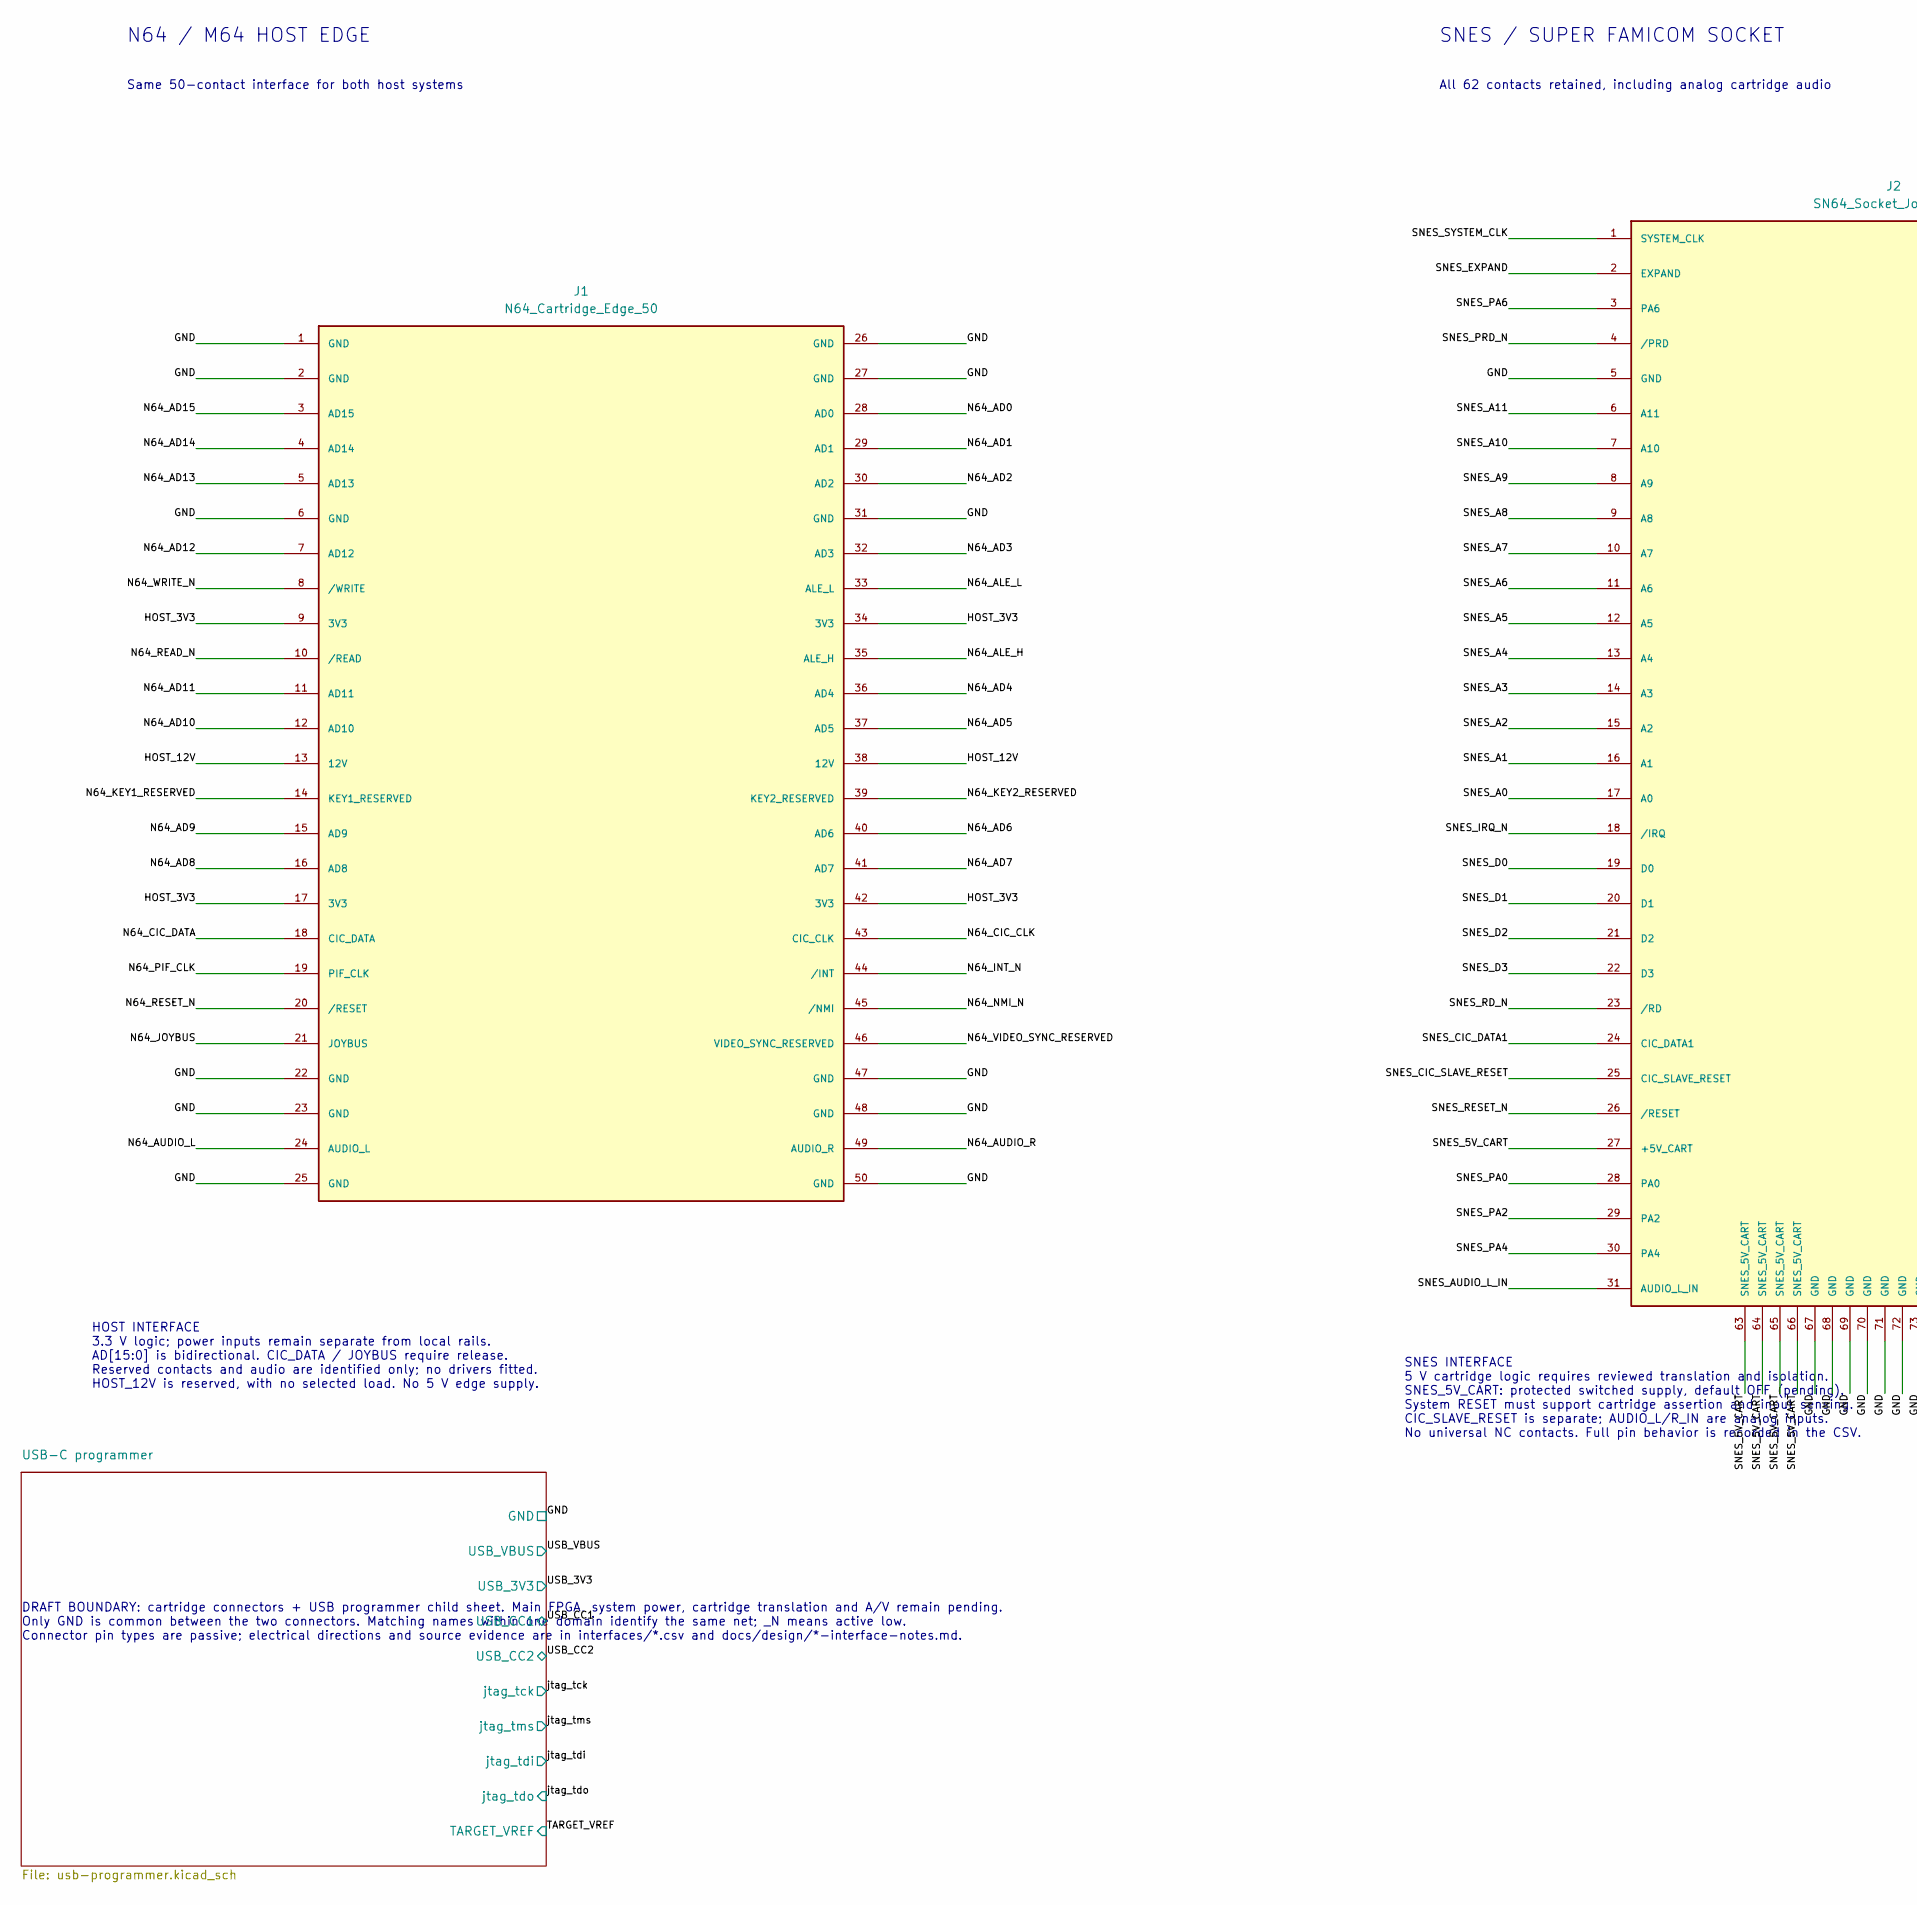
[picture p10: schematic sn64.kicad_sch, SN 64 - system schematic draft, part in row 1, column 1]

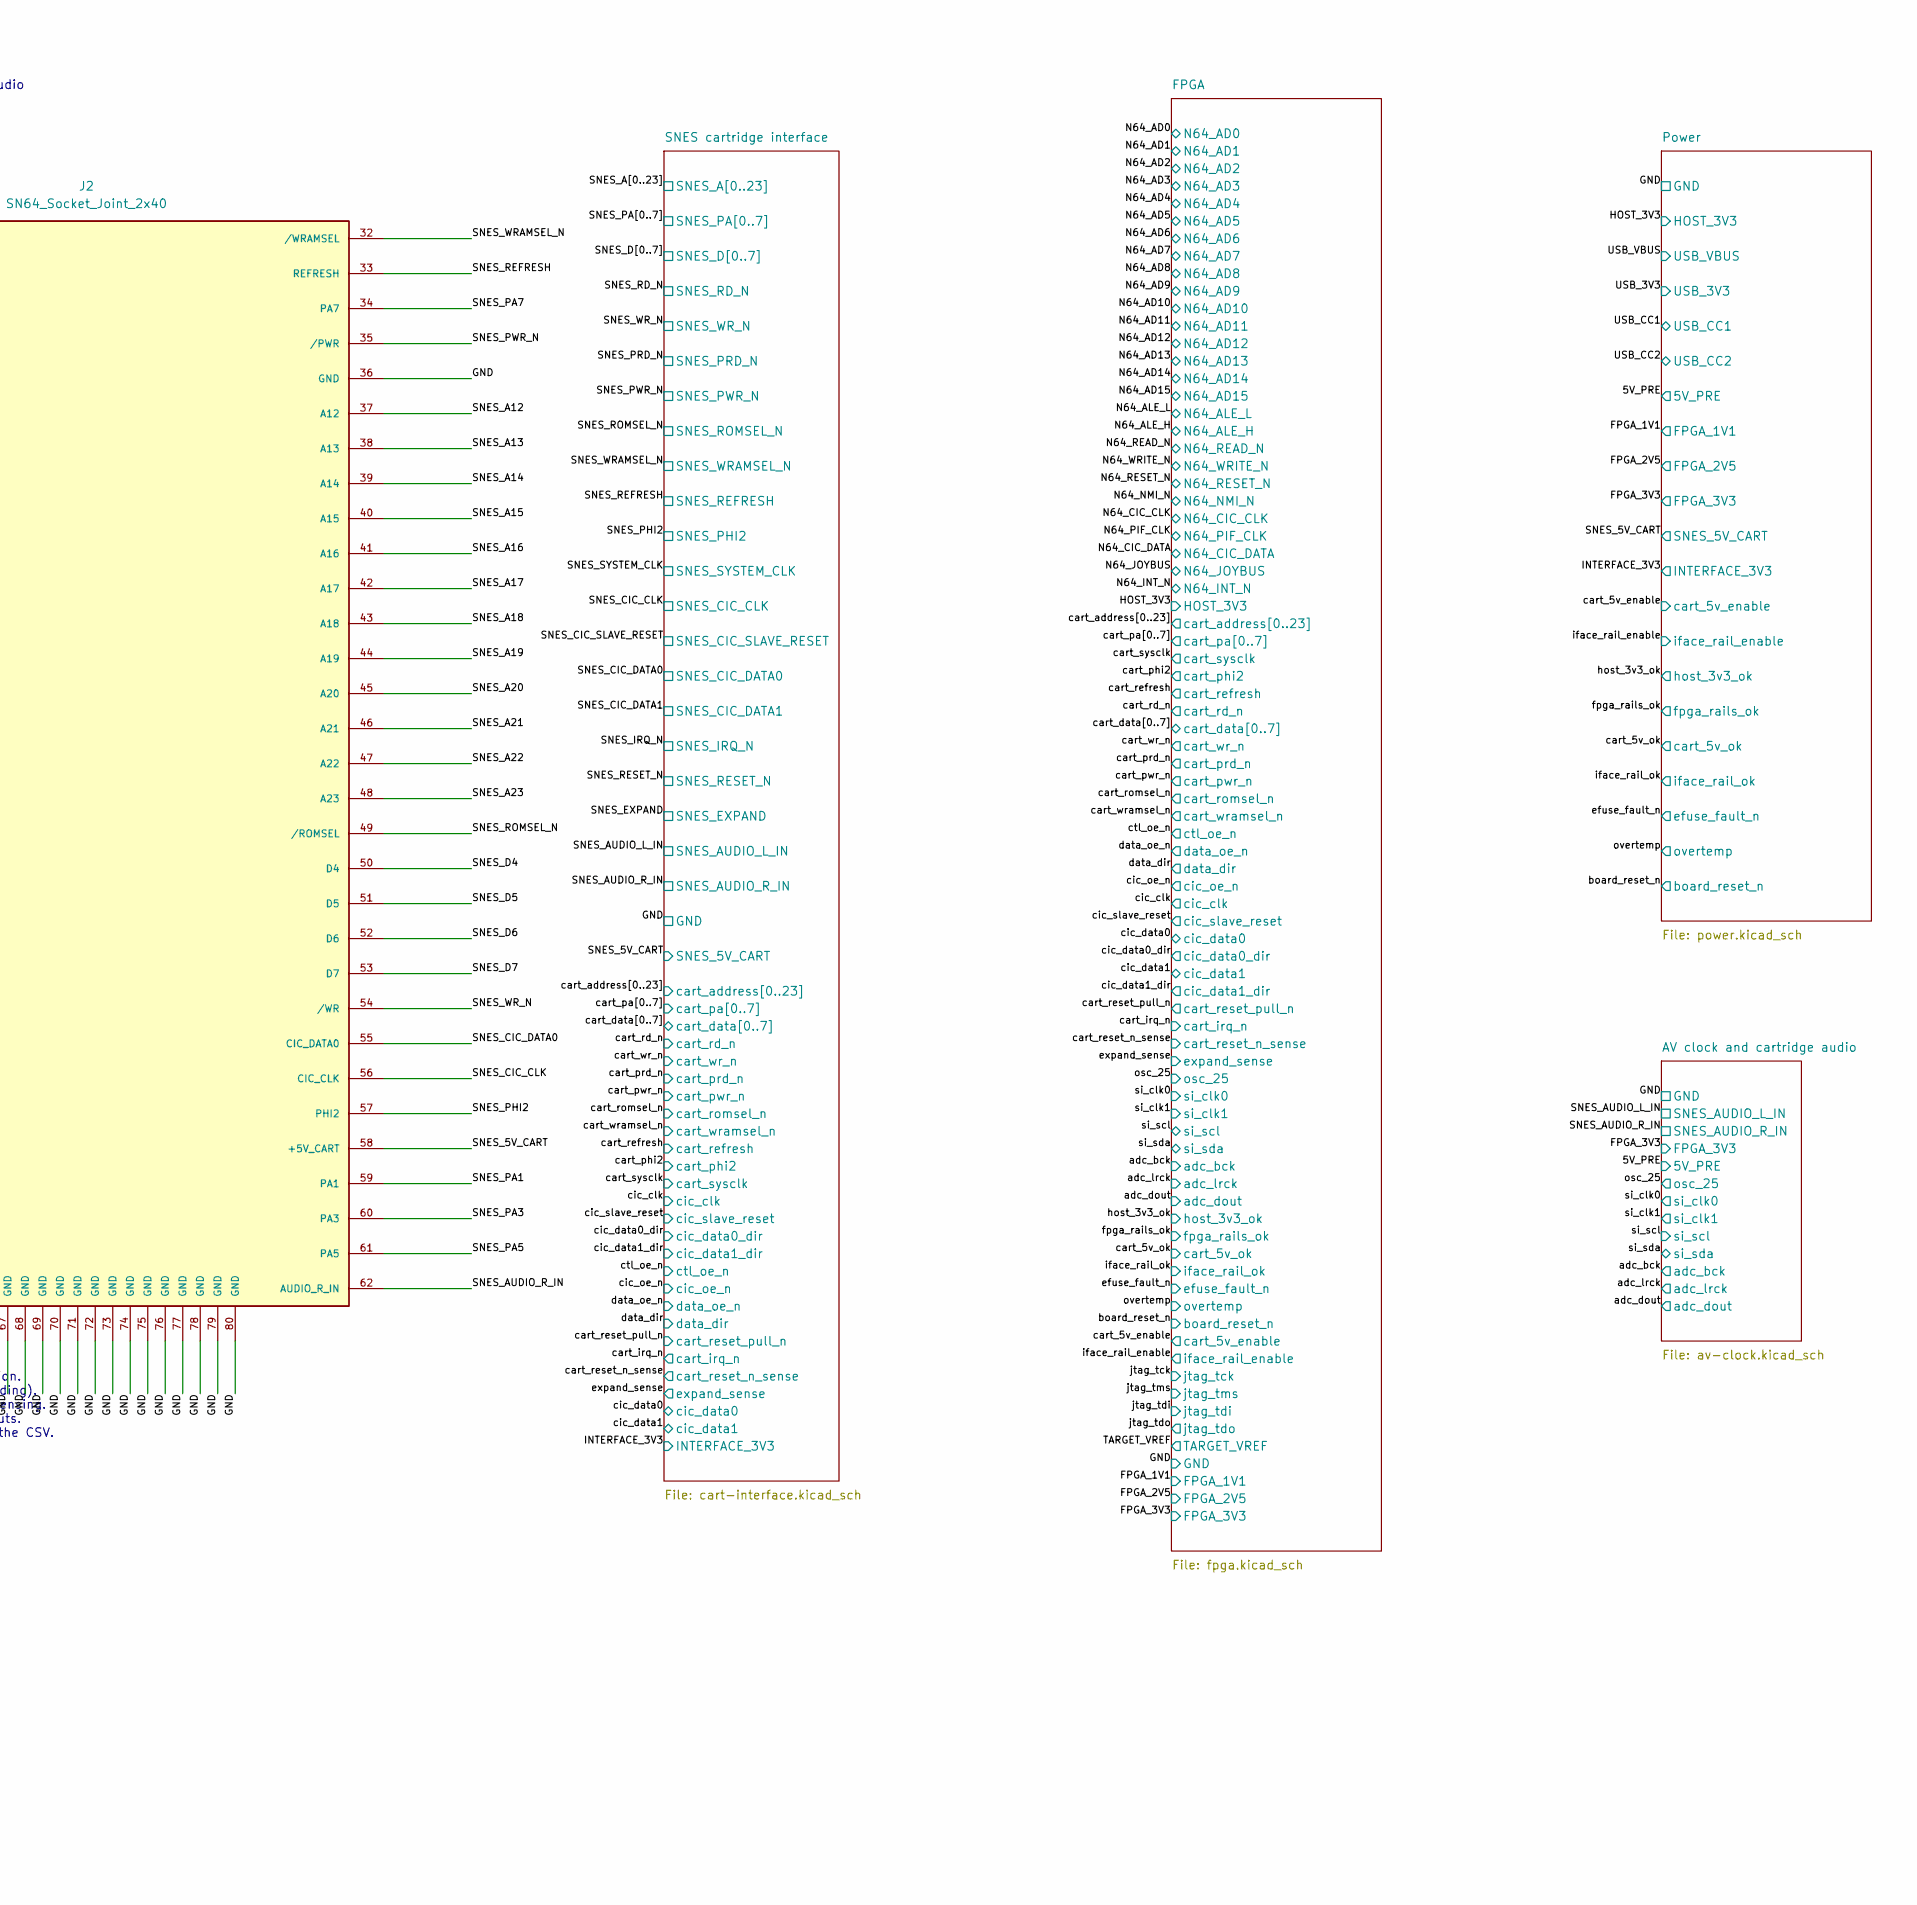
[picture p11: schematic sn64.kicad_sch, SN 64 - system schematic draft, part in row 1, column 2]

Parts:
J1: N64_Cartridge_Edge_50; N64_Edge_SC64_Reference
J2: SN64_Socket_Joint_2x40; PinHeader_2x40_P2.00mm_Horizontal

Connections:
/GND: J1.1 (GND), J1.2 (GND), J1.6 (GND), J1.22 (GND), J1.23 (GND), J1.25 (GND), J1.26 (GND), J1.27 (GND), J1.31 (GND), J1.47 (GND), J1.48 (GND), J1.50 (GND), J2.5 (GND), J2.36 (GND), J2.67 (GND), J2.68 (GND), J2.69 (GND), J2.70 (GND), J2.71 (GND), J2.72 (GND), J2.73 (GND), J2.74 (GND), J2.75 (GND), J2.76 (GND), J2.77 (GND), J2.78 (GND), J2.79 (GND), J2.80 (GND); also elsewhere on the board
/HOST_3V3: J1.9 (3V3), J1.17 (3V3), J1.34 (3V3), J1.42 (3V3); also elsewhere on the board
/HOST_12V: J1.13 (12V), J1.38 (12V)
/N64_AD0: J1.28 (AD0); also elsewhere on the board
/N64_AD1: J1.29 (AD1); also elsewhere on the board
/N64_AD2: J1.30 (AD2); also elsewhere on the board
/N64_AD3: J1.32 (AD3); also elsewhere on the board
/N64_AD4: J1.36 (AD4); also elsewhere on the board
/N64_AD5: J1.37 (AD5); also elsewhere on the board
/N64_AD6: J1.40 (AD6); also elsewhere on the board
/N64_AD7: J1.41 (AD7); also elsewhere on the board
/N64_AD8: J1.16 (AD8); also elsewhere on the board
/N64_AD9: J1.15 (AD9); also elsewhere on the board
/N64_AD10: J1.12 (AD10); also elsewhere on the board
/N64_AD11: J1.11 (AD11); also elsewhere on the board
/N64_AD12: J1.7 (AD12); also elsewhere on the board
/N64_AD13: J1.5 (AD13); also elsewhere on the board
/N64_AD14: J1.4 (AD14); also elsewhere on the board
/N64_AD15: J1.3 (AD15); also elsewhere on the board
/N64_ALE_H: J1.35 (ALE_H); also elsewhere on the board
/N64_ALE_L: J1.33 (ALE_L); also elsewhere on the board
/N64_AUDIO_L: J1.24 (AUDIO_L)
/N64_AUDIO_R: J1.49 (AUDIO_R)
/N64_CIC_CLK: J1.43 (CIC_CLK); also elsewhere on the board
/N64_CIC_DATA: J1.18 (CIC_DATA); also elsewhere on the board
/N64_INT_N: J1.44 (/INT); also elsewhere on the board
/N64_JOYBUS: J1.21 (JOYBUS); also elsewhere on the board
/N64_KEY1_RESERVED: J1.14 (KEY1_RESERVED)
/N64_KEY2_RESERVED: J1.39 (KEY2_RESERVED)
/N64_NMI_N: J1.45 (/NMI); also elsewhere on the board
/N64_PIF_CLK: J1.19 (PIF_CLK); also elsewhere on the board
/N64_READ_N: J1.10 (/READ); also elsewhere on the board
/N64_RESET_N: J1.20 (/RESET); also elsewhere on the board
/N64_VIDEO_SYNC_RESERVED: J1.46 (VIDEO_SYNC_RESERVED)
/N64_WRITE_N: J1.8 (/WRITE); also elsewhere on the board
/SNES_5V_CART: J2.27 (+5V_CART), J2.58 (+5V_CART), J2.63 (SNES_5V_CART), J2.64 (SNES_5V_CART), J2.65 (SNES_5V_CART), J2.66 (SNES_5V_CART); also elsewhere on the board
/SNES_A0: J2.17 (A0); also elsewhere on the board
/SNES_A1: J2.16 (A1); also elsewhere on the board
/SNES_A2: J2.15 (A2); also elsewhere on the board
/SNES_A3: J2.14 (A3); also elsewhere on the board
/SNES_A4: J2.13 (A4); also elsewhere on the board
/SNES_A5: J2.12 (A5); also elsewhere on the board
/SNES_A6: J2.11 (A6); also elsewhere on the board
/SNES_A7: J2.10 (A7); also elsewhere on the board
/SNES_A8: J2.9 (A8); also elsewhere on the board
/SNES_A9: J2.8 (A9); also elsewhere on the board
/SNES_A10: J2.7 (A10); also elsewhere on the board
/SNES_A11: J2.6 (A11); also elsewhere on the board
/SNES_A12: J2.37 (A12); also elsewhere on the board
/SNES_A13: J2.38 (A13); also elsewhere on the board
/SNES_A14: J2.39 (A14); also elsewhere on the board
/SNES_A15: J2.40 (A15); also elsewhere on the board
/SNES_A16: J2.41 (A16); also elsewhere on the board
/SNES_A17: J2.42 (A17); also elsewhere on the board
/SNES_A18: J2.43 (A18); also elsewhere on the board
/SNES_A19: J2.44 (A19); also elsewhere on the board
/SNES_A20: J2.45 (A20); also elsewhere on the board
/SNES_A21: J2.46 (A21); also elsewhere on the board
/SNES_A22: J2.47 (A22); also elsewhere on the board
/SNES_A23: J2.48 (A23); also elsewhere on the board
/SNES_AUDIO_L_IN: J2.31 (AUDIO_L_IN); also elsewhere on the board
/SNES_AUDIO_R_IN: J2.62 (AUDIO_R_IN); also elsewhere on the board
/SNES_CIC_CLK: J2.56 (CIC_CLK); also elsewhere on the board
/SNES_CIC_DATA0: J2.55 (CIC_DATA0); also elsewhere on the board
/SNES_CIC_DATA1: J2.24 (CIC_DATA1); also elsewhere on the board
/SNES_CIC_SLAVE_RESET: J2.25 (CIC_SLAVE_RESET); also elsewhere on the board
/SNES_D0: J2.19 (D0); also elsewhere on the board
/SNES_D1: J2.20 (D1); also elsewhere on the board
/SNES_D2: J2.21 (D2); also elsewhere on the board
/SNES_D3: J2.22 (D3); also elsewhere on the board
/SNES_D4: J2.50 (D4); also elsewhere on the board
/SNES_D5: J2.51 (D5); also elsewhere on the board
/SNES_D6: J2.52 (D6); also elsewhere on the board
/SNES_D7: J2.53 (D7); also elsewhere on the board
/SNES_EXPAND: J2.2 (EXPAND); also elsewhere on the board
/SNES_IRQ_N: J2.18 (/IRQ); also elsewhere on the board
/SNES_PA0: J2.28 (PA0); also elsewhere on the board
/SNES_PA1: J2.59 (PA1); also elsewhere on the board
/SNES_PA2: J2.29 (PA2); also elsewhere on the board
/SNES_PA3: J2.60 (PA3); also elsewhere on the board
/SNES_PA4: J2.30 (PA4); also elsewhere on the board
/SNES_PA5: J2.61 (PA5); also elsewhere on the board
/SNES_PA6: J2.3 (PA6); also elsewhere on the board
/SNES_PA7: J2.34 (PA7); also elsewhere on the board
/SNES_PHI2: J2.57 (PHI2); also elsewhere on the board
/SNES_PRD_N: J2.4 (/PRD); also elsewhere on the board
/SNES_PWR_N: J2.35 (/PWR); also elsewhere on the board
/SNES_RD_N: J2.23 (/RD); also elsewhere on the board
/SNES_REFRESH: J2.33 (REFRESH); also elsewhere on the board
/SNES_RESET_N: J2.26 (/RESET); also elsewhere on the board
/SNES_ROMSEL_N: J2.49 (/ROMSEL); also elsewhere on the board
/SNES_SYSTEM_CLK: J2.1 (SYSTEM_CLK); also elsewhere on the board
/SNES_WRAMSEL_N: J2.32 (/WRAMSEL); also elsewhere on the board
/SNES_WR_N: J2.54 (/WR); also elsewhere on the board

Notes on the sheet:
N64 / M64 HOST EDGE
SNES / SUPER FAMICOM SOCKET
Same 50-contact interface for both host systems
All 62 contacts retained, including analog cartridge audio
HOST INTERFACE 3.3 V logic; power inputs remain separate from local rails. AD[15:0] is bidirectional. CIC_DATA / JOYBUS require release. Reserved contacts and audio are identified only; no drivers fitted. HOST_12V is reserved, with no selected load. No 5 V edge supply.
SNES INTERFACE 5 V cartridge logic requires reviewed translation and isolation. SNES_5V_CART: protected switched supply, default OFF (pending). System RESET must support cartridge assertion and input sensing. CIC_SLAVE_RESET is separate; AUDIO_L/R_IN are analog inputs. No universal NC contacts. Ful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
DRAFT BOUNDARY: cartridge connectors + USB programmer child sheet. Main FPGA, system power, cartridge translation and A/V remain pending. Only GND is common between the two connectors. Matching names within one domain identify the same net; _N means active low. Connector pin types are passive; elec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

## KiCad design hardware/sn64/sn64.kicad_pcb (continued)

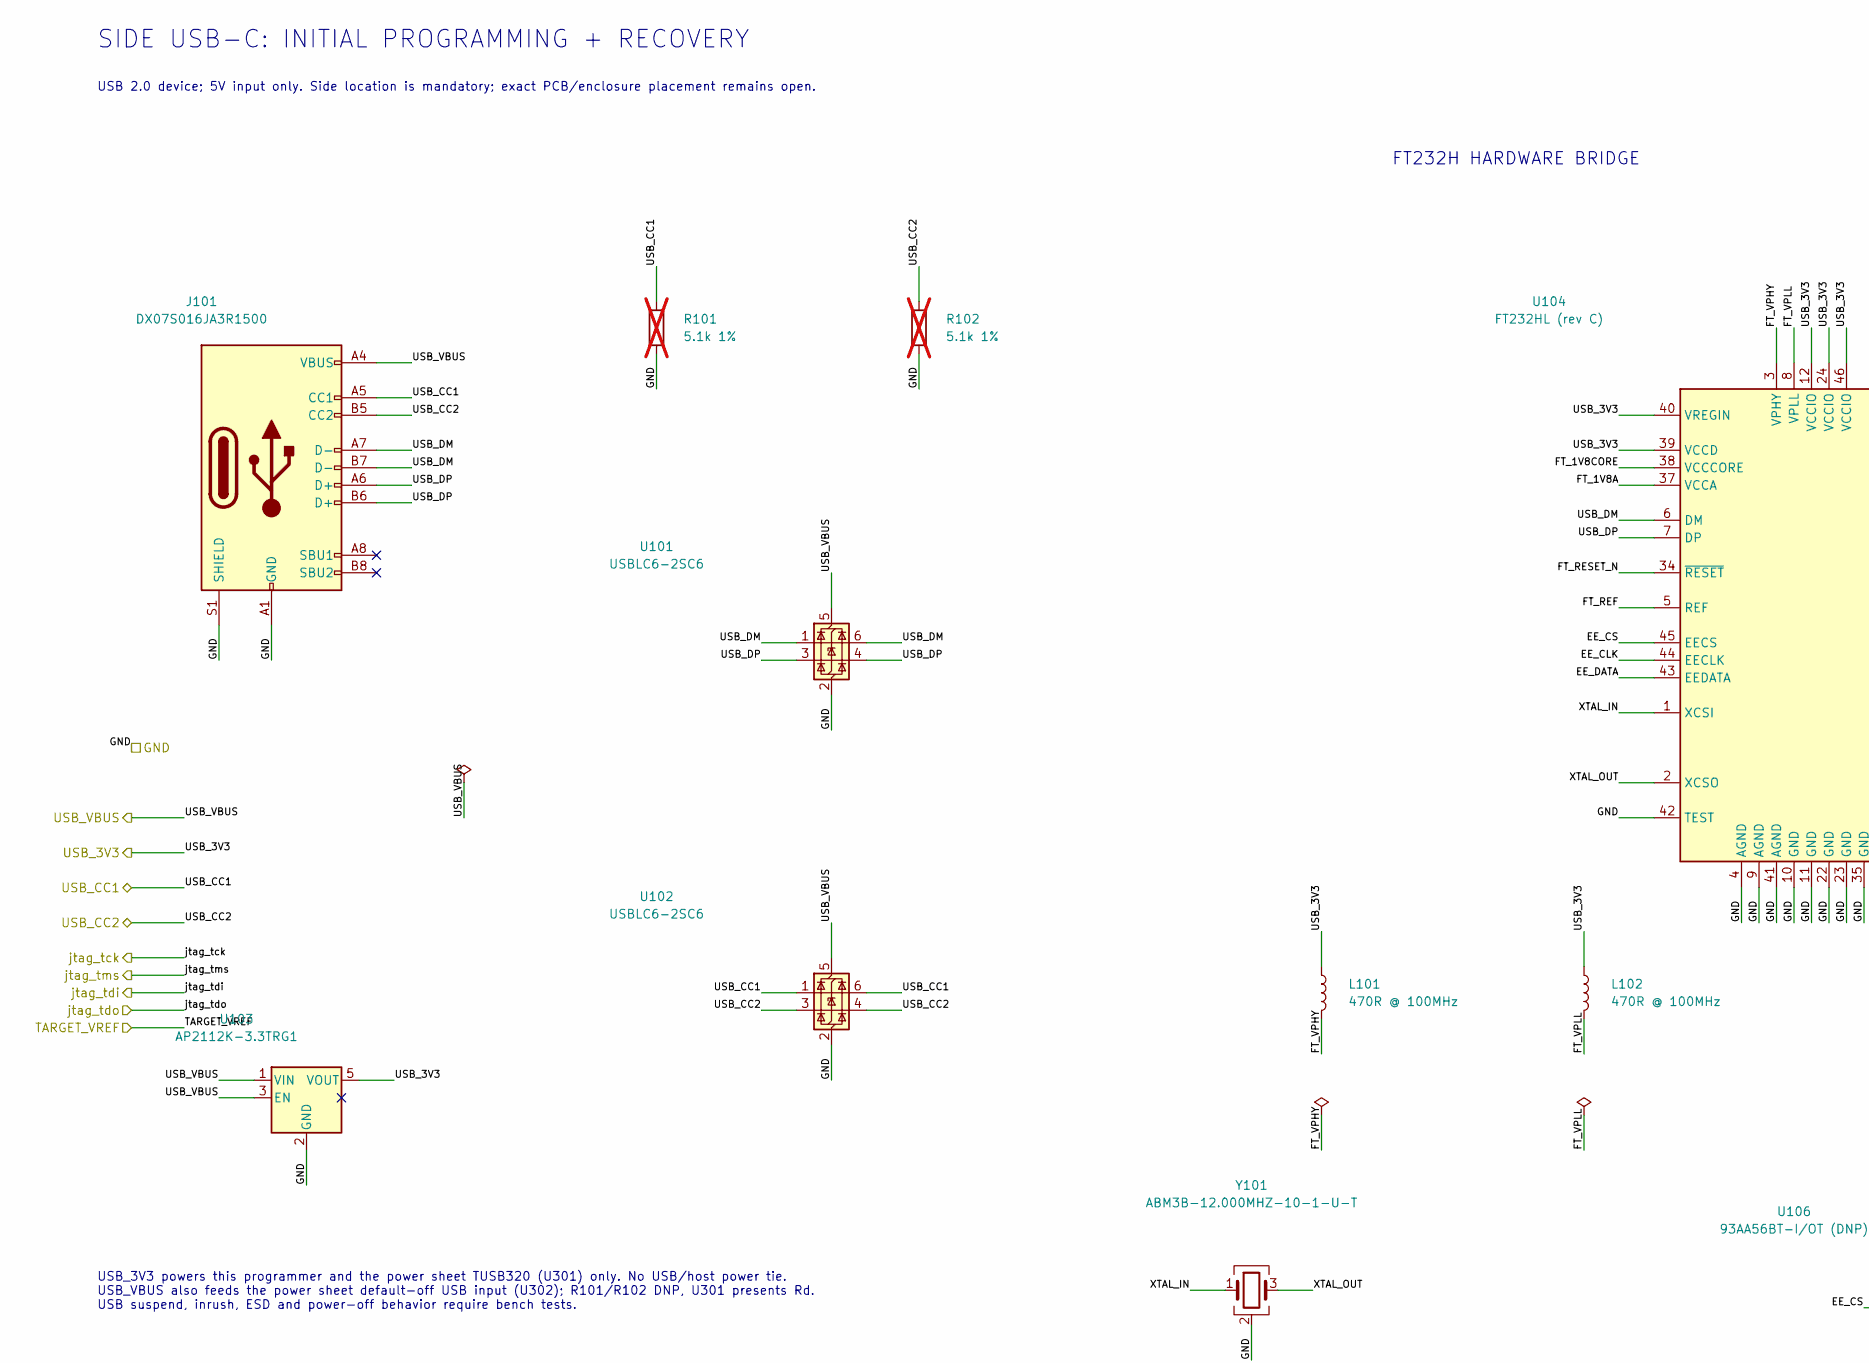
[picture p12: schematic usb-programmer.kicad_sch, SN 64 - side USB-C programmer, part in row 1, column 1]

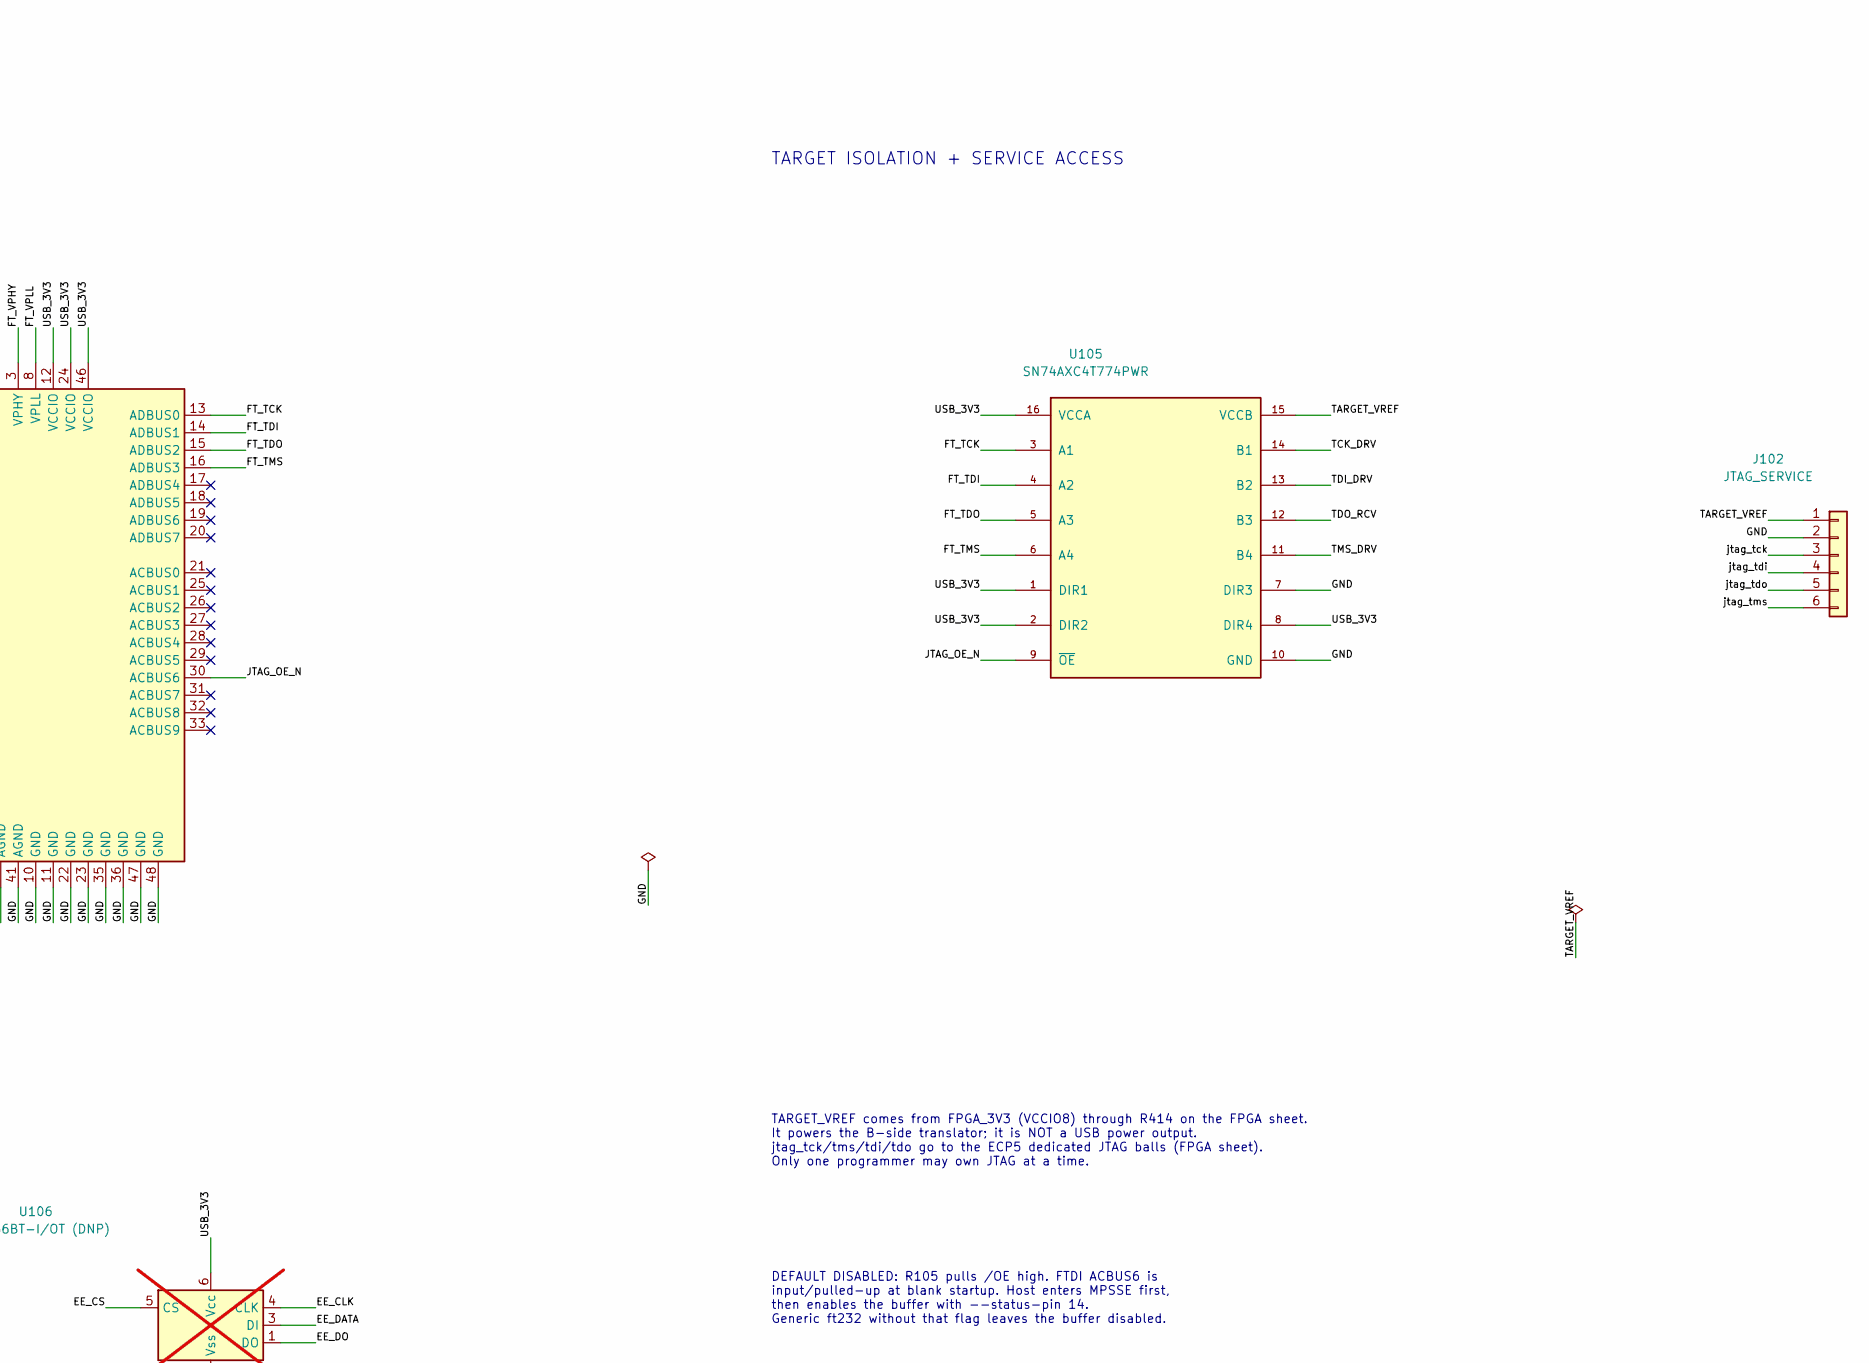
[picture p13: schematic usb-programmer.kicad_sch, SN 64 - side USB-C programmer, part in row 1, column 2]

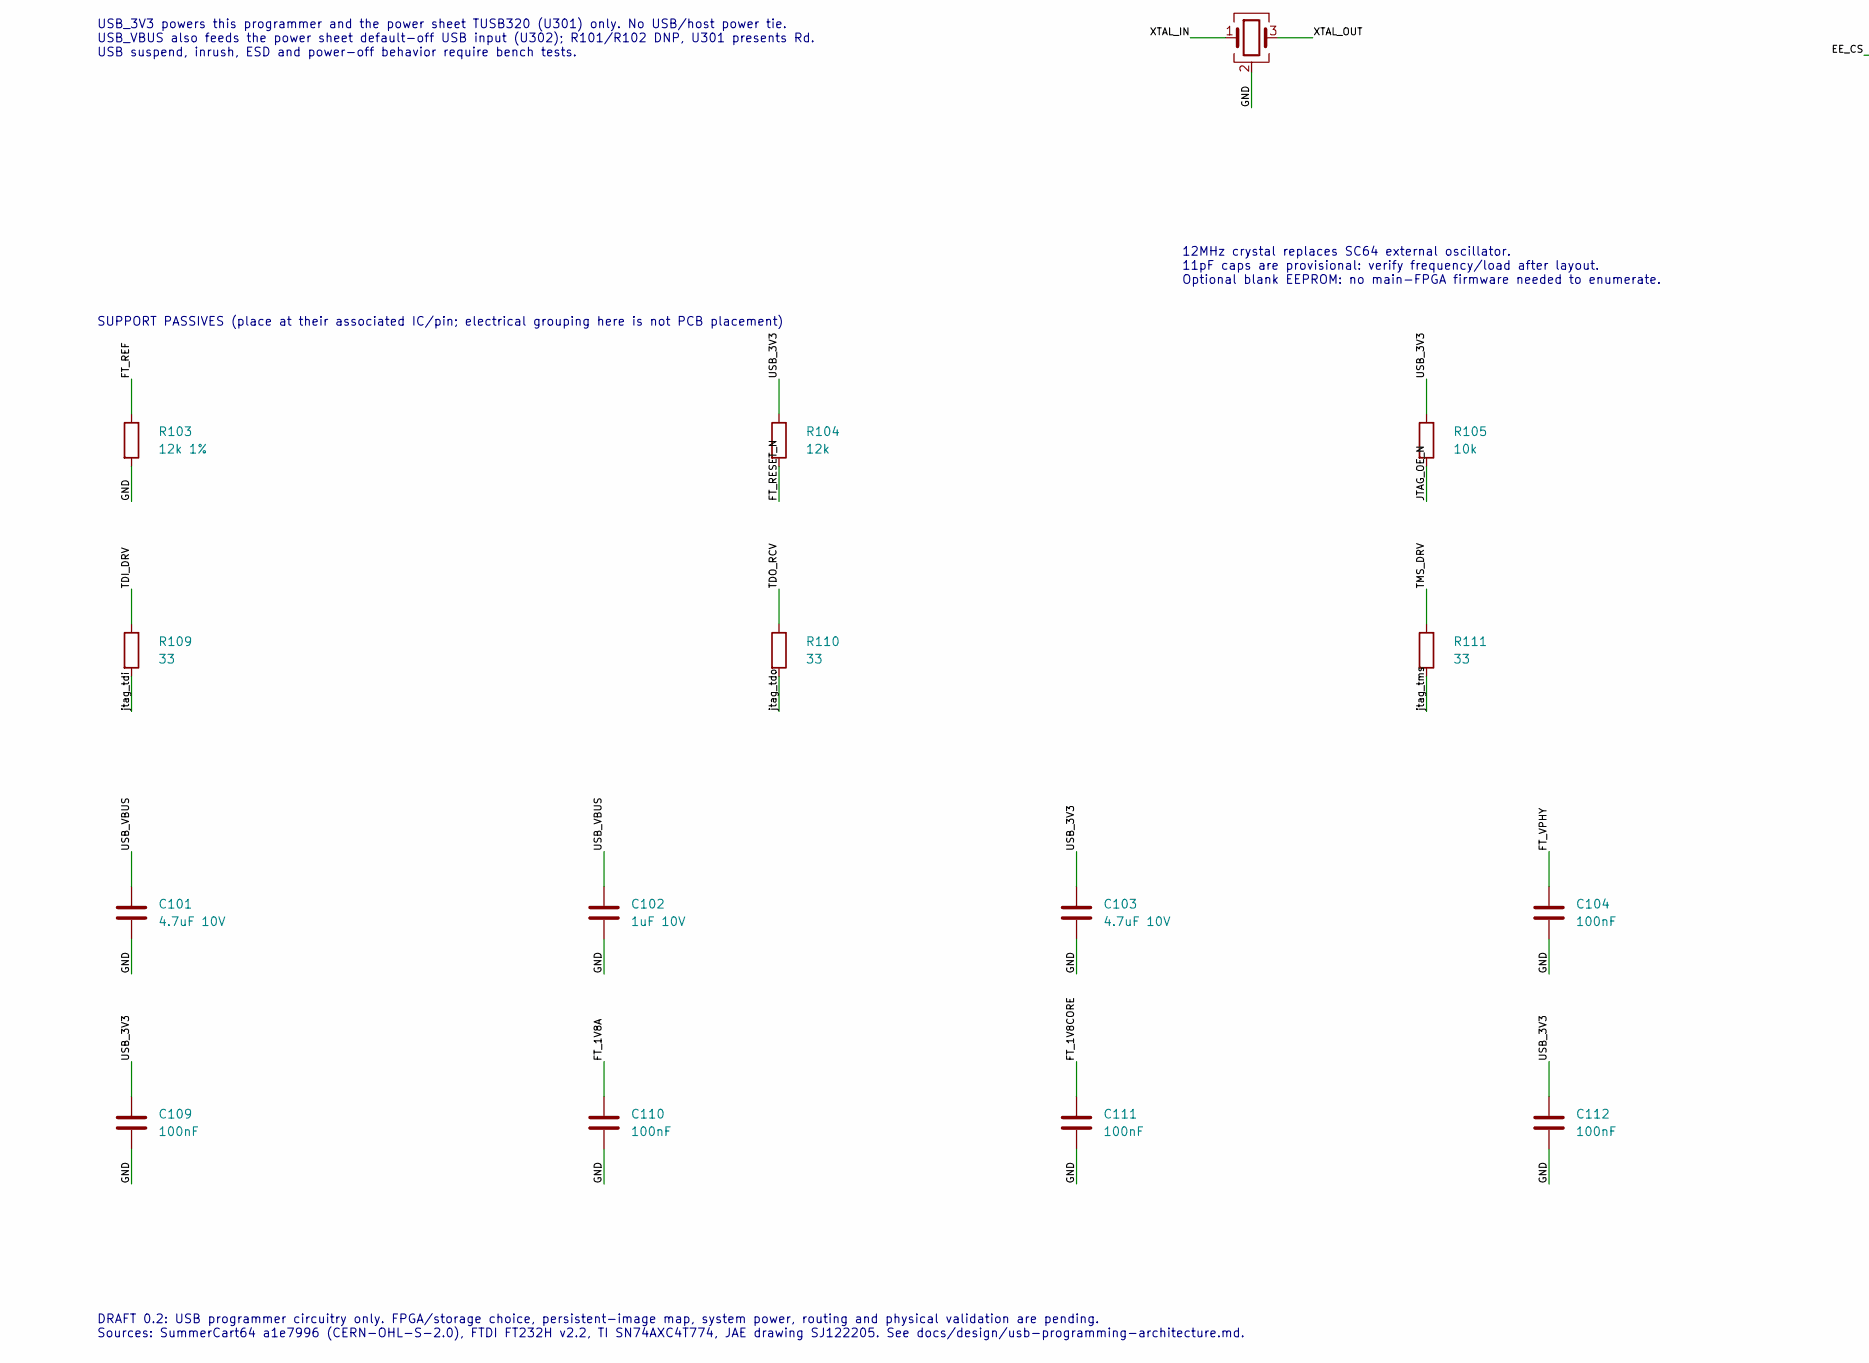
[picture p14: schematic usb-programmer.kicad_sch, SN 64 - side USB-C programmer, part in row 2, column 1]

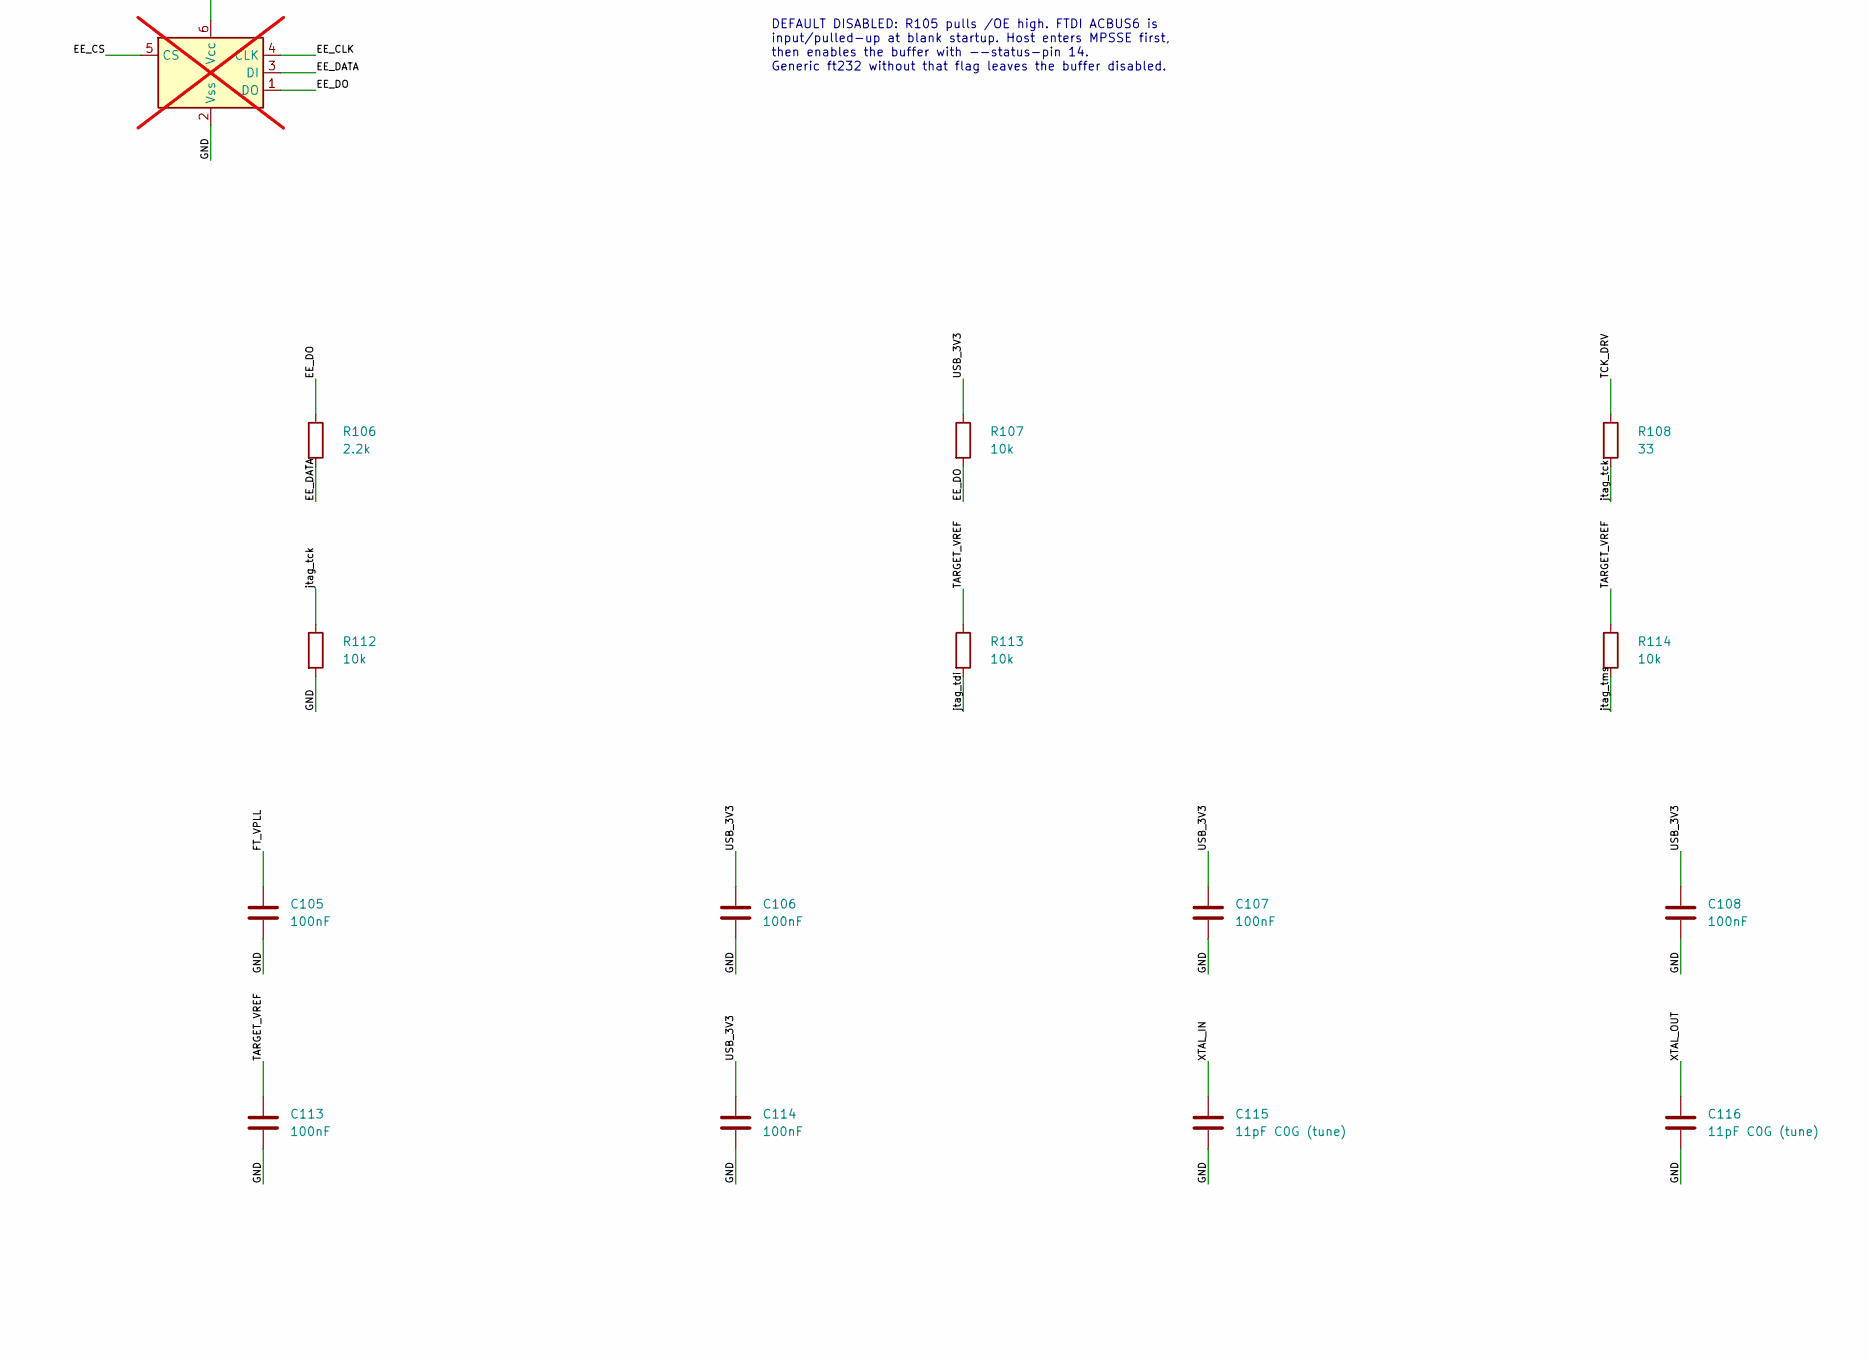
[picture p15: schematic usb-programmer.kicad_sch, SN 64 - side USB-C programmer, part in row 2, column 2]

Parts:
C101, C103: 4.7uF 10V; C_0603_1608Metric
C102: 1uF 10V; C_0603_1608Metric
C104, C105, C106, C107, C108, C109, C110, C111, C112, C113, C114: 100nF; C_0603_1608Metric
C115, C116: 11pF C0G (tune); C_0603_1608Metric
J101: DX07S016JA3R1500; USB_C_JAE_DX07S016JA3R1500
J102: JTAG_SERVICE; PinHeader_1x06_P2.54mm_Vertical
L101, L102: 470R @ 100MHz; L_0603_1608Metric
R101, R102: 5.1k 1%; R_0603_1608Metric; not fitted
R103: 12k 1%; R_0603_1608Metric
R104: 12k; R_0603_1608Metric
R105, R107, R112, R113, R114: 10k; R_0603_1608Metric
R106: 2.2k; R_0603_1608Metric
R108, R109, R110, R111: 33; R_0603_1608Metric
U101, U102: USBLC6-2SC6; SOT-23-6
U103: AP2112K-3.3TRG1; SOT-23-5
U104: FT232HL (rev C); LQFP-48_7x7mm_P0.5mm
U105: SN74AXC4T774PWR; TSSOP-16_4.4x5mm_P0.65mm
U106: 93AA56BT-I/OT (DNP); SOT-23-6; not fitted
Y101: ABM3B-12.000MHZ-10-1-U-T; Crystal_SMD_Abracon_ABM3B-4Pin_5.0x3.2mm

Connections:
/GND: C101.2, C102.2, C103.2, C104.2, C105.2, C106.2, C107.2, C108.2, C109.2, C110.2, C111.2, C112.2, C113.2, C114.2, C115.2, C116.2, J101.A1 (GND), J101.A12 (GND), J101.B1 (GND), J101.B12 (GND), J101.S1 (SHIELD), J102.2, R101.2, R102.2, R103.2, R112.2, U101.2 (GND), U102.2 (GND), U103.2 (GND), U104.4 (AGND), U104.9 (AGND), U104.10 (GND), U104.11 (GND), U104.22 (GND), U104.23 (GND), U104.35 (GND), U104.36 (GND), U104.41 (AGND), U104.42 (TEST), U104.47 (GND), U104.48 (GND), U105.7 (DIR3), U105.10 (GND), U106.2 (Vss), Y101.2 (G), Y101.4 (G); also elsewhere on the board
/TARGET_VREF: C113.1, J102.1, R113.1, R114.1, U105.15 (VCCB); also elsewhere on the board
/USB-C programmer/EE_CLK: U104.44 (EECLK), U106.4 (CLK)
/USB-C programmer/EE_CS: U104.45 (EECS), U106.5 (CS)
/USB-C programmer/EE_DATA: R106.2, U104.43 (EEDATA), U106.3 (DI)
/USB-C programmer/EE_DO: R106.1, R107.2, U106.1 (DO)
/USB-C programmer/FT_1V8A: C110.1, U104.37 (VCCA)
/USB-C programmer/FT_1V8CORE: C111.1, U104.38 (VCCCORE)
/USB-C programmer/FT_REF: R103.1, U104.5 (REF)
/USB-C programmer/FT_RESET_N: R104.2, U104.34 (~RESET)
/USB-C programmer/FT_TCK: U104.13 (ADBUS0), U105.3 (A1)
/USB-C programmer/FT_TDI: U104.14 (ADBUS1), U105.4 (A2)
/USB-C programmer/FT_TDO: U104.15 (ADBUS2), U105.5 (A3)
/USB-C programmer/FT_TMS: U104.16 (ADBUS3), U105.6 (A4)
/USB-C programmer/FT_VPHY: C104.1, L101.2, U104.3 (VPHY)
/USB-C programmer/FT_VPLL: C105.1, L102.2, U104.8 (VPLL)
/USB-C programmer/JTAG_OE_N: R105.2, U104.30 (ACBUS6), U105.9 (~OE)
/USB-C programmer/TCK_DRV: R108.1, U105.14 (B1)
/USB-C programmer/TDI_DRV: R109.1, U105.13 (B2)
/USB-C programmer/TDO_RCV: R110.1, U105.12 (B3)
/USB-C programmer/TMS_DRV: R111.1, U105.11 (B4)
/USB-C programmer/USB_DM: J101.A7 (D-), J101.B7 (D-), U101.1 (I/O1), U101.6 (I/O1), U104.6 (DM)
/USB-C programmer/USB_DP: J101.A6 (D+), J101.B6 (D+), U101.3 (I/O2), U101.4 (I/O2), U104.7 (DP)
/USB-C programmer/XTAL_IN: C115.1, U104.1 (XCSI), Y101.1
/USB-C programmer/XTAL_OUT: C116.1, U104.2 (XCSO), Y101.3
/USB_3V3: C103.1, C106.1, C107.1, C108.1, C109.1, C112.1, C114.1, L101.1, L102.1, R104.1, R105.1, R107.1, U103.5 (VOUT), U104.12 (VCCIO), U104.24 (VCCIO), U104.39 (VCCD), U104.40 (VREGIN), U104.46 (VCCIO), U105.1 (DIR1), U105.2 (DIR2), U105.8 (DIR4), U105.16 (VCCA), U106.6 (Vсс); also elsewhere on the board
/USB_CC1: J101.A5 (CC1), R101.1, U102.1 (I/O1), U102.6 (I/O1); also elsewhere on the board
/USB_CC2: J101.B5 (CC2), R102.1, U102.3 (I/O2), U102.4 (I/O2); also elsewhere on the board
/USB_VBUS: C101.1, C102.1, J101.A4 (VBUS), J101.A9 (VBUS), J101.B4 (VBUS), J101.B9 (VBUS), U101.5 (VBUS), U102.5 (VBUS), U103.1 (VIN), U103.3 (EN); also elsewhere on the board
/jtag_tck: J102.3, R108.2, R112.1; also elsewhere on the board
/jtag_tdi: J102.4, R109.2, R113.2; also elsewhere on the board
/jtag_tdo: J102.5, R110.2; also elsewhere on the board
/jtag_tms: J102.6, R111.2, R114.2; also elsewhere on the board

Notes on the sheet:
SIDE USB-C: INITIAL PROGRAMMING + RECOVERY
USB 2.0 device; 5V input only. Side location is mandatory; exact PCB/enclosure placement remains open.
FT232H HARDWARE BRIDGE
TARGET ISOLATION + SERVICE ACCESS
TARGET_VREF comes from FPGA_3V3 (VCCIO8) through R414 on the FPGA sheet. It powers the B-side translator; it is NOT a USB power output. jtag_tck/tms/tdi/tdo go to the ECP5 dedicated JTAG balls (FPGA sheet). Only one programmer may own JTAG at a time.
DEFAULT DISABLED: R105 pulls /OE high. FTDI ACBUS6 is input/pulled-up at blank startup. Host enters MPSSE first, then enables the buffer with --status-pin 14. Generic ft232 without that flag leaves the buffer disabled.
USB_3V3 powers this programmer and the power sheet TUSB320 (U301) only. No USB/host power tie. USB_VBUS also feeds the power sheet default-off USB input (U302); R101/R102 DNP, U301 presents Rd. USB suspend, inrush, ESD and power-off behavior require bench tests.
12MHz crystal replaces SC64 external oscillator. 11pF caps are provisional: verify frequency/load after layout. Optional blank EEPROM: no main-FPGA firmware needed to enumerate.
SUPPORT PASSIVES (place at their associated IC/pin; electrical grouping here is not PCB placement)
DRAFT 0.2: USB programmer circuitry only. FPGA/storage choice, persistent-image map, system power, routing and physical validation are pending. Sources: SummerCart64 a1e7996 (CERN-OHL-S-2.0), FTDI FT232H v2.2, TI SN74AXC4T774, JAE drawing SJ122205. See docs/design/usb-programming-architecture.md.

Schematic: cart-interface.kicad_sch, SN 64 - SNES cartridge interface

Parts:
C201, C202, C203, C204, C205, C206, C207, C208, C209, C210, C211, C212, C213, C214, C215, C216, C217, C218, C219, C220, C221, C222, C223, C224, C225, C226, C227, C228, C229, C230, C231: 100nF; C_0603_1608Metric
C232, C233: 10uF 10V; C_0805_2012Metric
Q201: 2N7002; SOT-23
R201, R202: 2.2k; R_0603_1608Metric
R203, R204: 1k; R_0603_1608Metric
R205, R218, R219: 100k; R_0603_1608Metric
R206, R207, R208: 4.7k; R_0603_1608Metric
R209, R210, R211, R212, R213, R216, R217, R220, R221: 10k; R_0603_1608Metric
R214, R215: 33; R_0603_1608Metric
RN201, RN202, RN203, RN204, RN205, RN206, RN207, RN208, RN209, RN210, RN211, RN212, RN213: 33 (4x0603, tune); R_Array_Convex_4x0603
TP201: AUDIO_L; TestPoint_Pad_D1.0mm
TP202: AUDIO_R; TestPoint_Pad_D1.0mm
U201, U202, U203, U204, U205, U206, U207: SN74LVC4245APWR; TSSOP-24_4.4x7.8mm_P0.65mm
U209: SN74LVC244APWR; TSSOP-20_4.4x6.5mm_P0.65mm
U210, U211, U212: SN74LVC1G07DBVR; SOT-23-5
U213, U214: SN74LVC1G06DBVR; SOT-23-5
U215, U216: SN74LVC1T45DBVR; SOT-23-6; LCSC C7843

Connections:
/GND: C201.2, C202.2, C203.2, C204.2, C205.2, C206.2, C207.2, C208.2, C209.2, C210.2, C211.2, C212.2, C213.2, C214.2, C215.2, C216.2, C217.2, C218.2, C219.2, C220.2, C221.2, C222.2, C223.2, C224.2, C225.2, C226.2, C227.2, C228.2, C229.2, C230.2, C231.2, C232.2, C233.2, Q201.2 (S), R209.2, R210.2, R216.2, R217.2, R218.2, R219.2, R220.2, R221.2, U201.2 (DIR), U201.11 (GND), U201.12 (GND), U201.13 (GND), U202.2 (DIR), U202.11 (GND), U202.12 (GND), U202.13 (GND), U203.2 (DIR), U203.11 (GND), U203.12 (GND), U203.13 (GND), U204.2 (DIR), U204.11 (GND), U204.12 (GND), U204.13 (GND), U205.2 (DIR), U205.11 (GND), U205.12 (GND), U205.13 (GND), U206.2 (DIR), U206.11 (GND), U206.12 (GND), U206.13 (GND), U206.14 (B8), U206.15 (B7), U206.16 (B6), U206.17 (B5), U206.18 (B4), U207.11 (GND), U207.12 (GND), U207.13 (GND), U209.1 (~1OE), U209.8 (1A4), U209.10 (GND), U209.11 (2A1), U209.13 (2A2), U209.15 (2A3), U209.17 (2A4), U209.19 (~2OE), U210.3 (GND), U211.3 (GND), U212.3 (GND), U213.3 (GND), U214.3 (GND), U215.2 (GND), U216.2 (GND); also elsewhere on the board
/INTERFACE_3V3: C202.1, C203.1, C205.1, C206.1, C208.1, C209.1, C211.1, C212.1, C214.1, C215.1, C217.1, C218.1, C220.1, C221.1, C222.1, C223.1, C224.1, C225.1, C226.1, C227.1, C228.1, C230.1, C233.1, R206.1, R207.1, R208.1, U201.23 (VCCB), U201.24 (VCCB), U202.23 (VCCB), U202.24 (VCCB), U203.23 (VCCB), U203.24 (VCCB), U204.23 (VCCB), U204.24 (VCCB), U205.23 (VCCB), U205.24 (VCCB), U206.23 (VCCB), U206.24 (VCCB), U207.23 (VCCB), U207.24 (VCCB), U209.20 (VCC), U210.5 (VCC), U211.5 (VCC), U212.5 (VCC), U213.5 (VCC), U214.5 (VCC), U215.1 (VCCA), U216.1 (VCCA); also elsewhere on the board
/SNES cartridge interface/CIC_OE_N_5V: R202.2, U206.22 (~OE), U211.4
/SNES cartridge interface/CTL_OE_N_5V: R201.2, U201.22 (~OE), U202.22 (~OE), U203.22 (~OE), U204.22 (~OE), U205.22 (~OE), U210.4
/SNES cartridge interface/DATA_DIR_5V: R204.2, U207.2 (DIR), U213.4
/SNES cartridge interface/DATA_OE_N_5V: R203.2, U207.22 (~OE), U212.4
/SNES cartridge interface/RESET_GATE_5V: Q201.1 (G), R205.2, U214.4
/SNES cartridge interface/XA_A0: RN201.1 (R1.1), U201.3 (A1)
/SNES cartridge interface/XA_A1: RN201.2 (R2.1), U201.4 (A2)
/SNES cartridge interface/XA_A2: RN201.3 (R3.1), U201.5 (A3)
/SNES cartridge interface/XA_A3: RN201.4 (R4.1), U201.6 (A4)
/SNES cartridge interface/XA_A4: RN202.1 (R1.1), U201.7 (A5)
/SNES cartridge interface/XA_A5: RN202.2 (R2.1), U201.8 (A6)
/SNES cartridge interface/XA_A6: RN202.3 (R3.1), U201.9 (A7)
/SNES cartridge interface/XA_A7: RN202.4 (R4.1), U201.10 (A8)
/SNES cartridge interface/XA_A8: RN203.1 (R1.1), U202.3 (A1)
/SNES cartridge interface/XA_A9: RN203.2 (R2.1), U202.4 (A2)
/SNES cartridge interface/XA_A10: RN203.3 (R3.1), U202.5 (A3)
/SNES cartridge interface/XA_A11: RN203.4 (R4.1), U202.6 (A4)
/SNES cartridge interface/XA_A12: RN204.1 (R1.1), U202.7 (A5)
/SNES cartridge interface/XA_A13: RN204.2 (R2.1), U202.8 (A6)
/SNES cartridge interface/XA_A14: RN204.3 (R3.1), U202.9 (A7)
/SNES cartridge interface/XA_A15: RN204.4 (R4.1), U202.10 (A8)
/SNES cartridge interface/XA_A16: RN205.1 (R1.1), U203.3 (A1)
/SNES cartridge interface/XA_A17: RN205.2 (R2.1), U203.4 (A2)
/SNES cartridge interface/XA_A18: RN205.3 (R3.1), U203.5 (A3)
/SNES cartridge interface/XA_A19: RN205.4 (R4.1), U203.6 (A4)
/SNES cartridge interface/XA_A20: RN206.1 (R1.1), U203.7 (A5)
/SNES cartridge interface/XA_A21: RN206.2 (R2.1), U203.8 (A6)
/SNES cartridge interface/XA_A22: RN206.3 (R3.1), U203.9 (A7)
/SNES cartridge interface/XA_A23: RN206.4 (R4.1), U203.10 (A8)
/SNES cartridge interface/XA_CIC_CLK: RN211.2 (R2.1), U206.4 (A2)
/SNES cartridge interface/XA_CIC_SLAVE_RESET: RN211.3 (R3.1), U206.5 (A3)
/SNES cartridge interface/XA_D0: RN212.1 (R1.1), U207.3 (A1)
/SNES cartridge interface/XA_D1: RN212.2 (R2.1), U207.4 (A2)
/SNES cartridge interface/XA_D2: RN212.3 (R3.1), U207.5 (A3)
/SNES cartridge interface/XA_D3: RN212.4 (R4.1), U207.6 (A4)
/SNES cartridge interface/XA_D4: RN213.1 (R1.1), U207.7 (A5)
/SNES cartridge interface/XA_D5: RN213.2 (R2.1), U207.8 (A6)
/SNES cartridge interface/XA_D6: RN213.3 (R3.1), U207.9 (A7)
/SNES cartridge interface/XA_D7: RN213.4 (R4.1), U207.10 (A8)
/SNES cartridge interface/XA_PA0: RN207.1 (R1.1), U204.3 (A1)
/SNES cartridge interface/XA_PA1: RN207.2 (R2.1), U204.4 (A2)
/SNES cartridge interface/XA_PA2: RN207.3 (R3.1), U204.5 (A3)
/SNES cartridge interface/XA_PA3: RN207.4 (R4.1), U204.6 (A4)
/SNES cartridge interface/XA_PA4: RN208.1 (R1.1), U204.7 (A5)
/SNES cartridge interface/XA_PA5: RN208.2 (R2.1), U204.8 (A6)
/SNES cartridge interface/XA_PA6: RN208.3 (R3.1), U204.9 (A7)
/SNES cartridge interface/XA_PA7: RN208.4 (R4.1), U204.10 (A8)
/SNES cartridge interface/XA_PHI2: RN210.4 (R4.1), U205.10 (A8)
/SNES cartridge interface/XA_PRD_N: RN209.3 (R3.1), U205.5 (A3)
/SNES cartridge interface/XA_PWR_N: RN209.4 (R4.1), U205.6 (A4)
/SNES cartridge interface/XA_RD_N: RN209.1 (R1.1), U205.3 (A1)
/SNES cartridge interface/XA_REFRESH: RN210.3 (R3.1), U205.9 (A7)
/SNES cartridge interface/XA_ROMSEL_N: RN210.1 (R1.1), U205.7 (A5)
/SNES cartridge interface/XA_SYSTEM_CLK: RN211.1 (R1.1), U206.3 (A1)
/SNES cartridge interface/XA_WRAMSEL_N: RN210.2 (R2.1), U205.8 (A6)
/SNES cartridge interface/XA_WR_N: RN209.2 (R2.1), U205.4 (A2)
/SNES cartridge interface/XB_CIC_DATA0: R214.1, U215.4 (B)
/SNES cartridge interface/XB_CIC_DATA1: R215.1, U216.4 (B)
/SNES_5V_CART: C201.1, C204.1, C207.1, C210.1, C213.1, C216.1, C219.1, C229.1, C231.1, C232.1, R201.1, R202.1, R203.1, R204.1, R205.1, R211.1, R212.1, R213.1, U201.1 (VCCA), U202.1 (VCCA), U203.1 (VCCA), U204.1 (VCCA), U205.1 (VCCA), U206.1 (VCCA), U207.1 (VCCA), U215.6 (VCCB), U216.6 (VCCB); also elsewhere on the board
/SNES_A0: RN201.8 (R1.2); also elsewhere on the board
/SNES_A1: RN201.7 (R2.2); also elsewhere on the board
/SNES_A2: RN201.6 (R3.2); also elsewhere on the board
/SNES_A3: RN201.5 (R4.2); also elsewhere on the board
/SNES_A4: RN202.8 (R1.2); also elsewhere on the board
/SNES_A5: RN202.7 (R2.2); also elsewhere on the board
/SNES_A6: RN202.6 (R3.2); also elsewhere on the board
/SNES_A7: RN202.5 (R4.2); also elsewhere on the board
/SNES_A8: RN203.8 (R1.2); also elsewhere on the board
/SNES_A9: RN203.7 (R2.2); also elsewhere on the board
/SNES_A10: RN203.6 (R3.2); also elsewhere on the board
/SNES_A11: RN203.5 (R4.2); also elsewhere on the board
/SNES_A12: RN204.8 (R1.2); also elsewhere on the board
/SNES_A13: RN204.7 (R2.2); also elsewhere on the board
/SNES_A14: RN204.6 (R3.2); also elsewhere on the board
/SNES_A15: RN204.5 (R4.2); also elsewhere on the board
/SNES_A16: RN205.8 (R1.2); also elsewhere on the board
/SNES_A17: RN205.7 (R2.2); also elsewhere on the board
/SNES_A18: RN205.6 (R3.2); also elsewhere on the board
/SNES_A19: RN205.5 (R4.2); also elsewhere on the board
/SNES_A20: RN206.8 (R1.2); also elsewhere on the board
/SNES_A21: RN206.7 (R2.2); also elsewhere on the board
/SNES_A22: RN206.6 (R3.2); also elsewhere on the board
/SNES_A23: RN206.5 (R4.2); also elsewhere on the board
/SNES_AUDIO_L_IN: TP201.1; also elsewhere on the board
/SNES_AUDIO_R_IN: TP202.1; also elsewhere on the board
/SNES_CIC_CLK: RN211.7 (R2.2); also elsewhere on the board
/SNES_CIC_DATA0: R214.2, R216.1; also elsewhere on the board
/SNES_CIC_DATA1: R215.2, R217.1; also elsewhere on the board
/SNES_CIC_SLAVE_RESET: RN211.6 (R3.2); also elsewhere on the board
/SNES_D0: RN212.8 (R1.2); also elsewhere on the board
/SNES_D1: RN212.7 (R2.2); also elsewhere on the board
/SNES_D2: RN212.6 (R3.2); also elsewhere on the board
/SNES_D3: RN212.5 (R4.2); also elsewhere on the board
/SNES_D4: RN213.8 (R1.2); also elsewhere on the board
/SNES_D5: RN213.7 (R2.2); also elsewhere on the board
/SNES_D6: RN213.6 (R3.2); also elsewhere on the board
/SNES_D7: RN213.5 (R4.2); also elsewhere on the board
/SNES_EXPAND: R213.2, U209.6 (1A3); also elsewhere on the board
/SNES_IRQ_N: R211.2, U209.2 (1A1); also elsewhere on the board
/SNES_PA0: RN207.8 (R1.2); also elsewhere on the board
/SNES_PA1: RN207.7 (R2.2); also elsewhere on the board
/SNES_PA2: RN207.6 (R3.2); also elsewhere on the board
/SNES_PA3: RN207.5 (R4.2); also elsewhere on the board
/SNES_PA4: RN208.8 (R1.2); also elsewhere on the board
/SNES_PA5: RN208.7 (R2.2); also elsewhere on the board
/SNES_PA6: RN208.6 (R3.2); also elsewhere on the board
/SNES_PA7: RN208.5 (R4.2); also elsewhere on the board
/SNES_PHI2: RN210.5 (R4.2); also elsewhere on the board
/SNES_PRD_N: RN209.6 (R3.2); also elsewhere on the board
/SNES_PWR_N: RN209.5 (R4.2); also elsewhere on the board
/SNES_RD_N: RN209.8 (R1.2); also elsewhere on the board
/SNES_REFRESH: RN210.6 (R3.2); also elsewhere on the board
/SNES_RESET_N: Q201.3 (D), R212.2, U209.4 (1A2); also elsewhere on the board
/SNES_ROMSEL_N: RN210.8 (R1.2); also elsewhere on the board
/SNES_SYSTEM_CLK: RN211.8 (R1.2); also elsewhere on the board
/SNES_WRAMSEL_N: RN210.7 (R2.2); also elsewhere on the board
/SNES_WR_N: RN209.7 (R2.2); also elsewhere on the board
/cart_address0: U201.21 (B1); also elsewhere on the board
/cart_address1: U201.20 (B2); also elsewhere on the board
/cart_address2: U201.19 (B3); also elsewhere on the board
/cart_address3: U201.18 (B4); also elsewhere on the board
/cart_address4: U201.17 (B5); also elsewhere on the board
/cart_address5: U201.16 (B6); also elsewhere on the board
/cart_address6: U201.15 (B7); also elsewhere on the board
/cart_address7: U201.14 (B8); also elsewhere on the board
/cart_address8: U202.21 (B1); also elsewhere on the board
/cart_address9: U202.20 (B2); also elsewhere on the board
/cart_address10: U202.19 (B3); also elsewhere on the board
/cart_address11: U202.18 (B4); also elsewhere on the board
/cart_address12: U202.17 (B5); also elsewhere on the board
/cart_address13: U202.16 (B6); also elsewhere on the board
/cart_address14: U202.15 (B7); also elsewhere on the board
/cart_address15: U202.14 (B8); also elsewhere on the board
/cart_address16: U203.21 (B1); also elsewhere on the board
/cart_address17: U203.20 (B2); also elsewhere on the board
/cart_address18: U203.19 (B3); also elsewhere on the board
/cart_address19: U203.18 (B4); also elsewhere on the board
/cart_address20: U203.17 (B5); also elsewhere on the board
/cart_address21: U203.16 (B6); also elsewhere on the board
/cart_address22: U203.15 (B7); also elsewhere on the board
/cart_address23: U203.14 (B8); also elsewhere on the board
/cart_data0: U207.21 (B1); also elsewhere on the board
/cart_data1: U207.20 (B2); also elsewhere on the board
/cart_data2: U207.19 (B3); also elsewhere on the board
/cart_data3: U207.18 (B4); also elsewhere on the board
/cart_data4: U207.17 (B5); also elsewhere on the board
/cart_data5: U207.16 (B6); also elsewhere on the board
/cart_data6: U207.15 (B7); also elsewhere on the board
/cart_data7: U207.14 (B8); also elsewhere on the board
/cart_irq_n: U209.18 (1Y1); also elsewhere on the board
/cart_pa0: U204.21 (B1); also elsewhere on the board
/cart_pa1: U204.20 (B2); also elsewhere on the board
/cart_pa2: U204.19 (B3); also elsewhere on the board
/cart_pa3: U204.18 (B4); also elsewhere on the board
/cart_pa4: U204.17 (B5); also elsewhere on the board
/cart_pa5: U204.16 (B6); also elsewhere on the board
/cart_pa6: U204.15 (B7); also elsewhere on the board
/cart_pa7: U204.14 (B8); also elsewhere on the board
/cart_phi2: U205.14 (B8); also elsewhere on the board
/cart_prd_n: U205.19 (B3); also elsewhere on the board
/cart_pwr_n: U205.18 (B4); also elsewhere on the board
/cart_rd_n: U205.21 (B1); also elsewhere on the board
/cart_refresh: U205.15 (B7); also elsewhere on the board
/cart_reset_n_sense: U209.16 (1Y2); also elsewhere on the board
/cart_reset_pull_n: R210.1, U214.2; also elsewhere on the board
/cart_romsel_n: U205.17 (B5); also elsewhere on the board
/cart_sysclk: U206.21 (B1); also elsewhere on the board
/cart_wr_n: U205.20 (B2); also elsewhere on the board
/cart_wramsel_n: U205.16 (B6); also elsewhere on the board
/cic_clk: U206.20 (B2); also elsewhere on the board
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

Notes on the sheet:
SNES CARTRIDGE-SIDE TRANSLATION AND PROTECTION
SN74LVC4245A: A port = 5 V cartridge (VCCA = SNES_5V_CART), B port = 3.3 V FPGA (VCCB = INTERFACE_3V3). DIR/OE are referenced to VCCA (TI SCAS375K). DIR=L: B->A (FPGA drives socket); DIR=H: A->B; OE=H: isolation.
U201-U206: console outputs, DIR strapped to GND (fixed FPGA->cartridge). U201-U205 share CTL_OE_N_5V (bridge ctl_oe_n); U206 (SYSTEM_CLK + CIC_CLK + CIC_SLAVE_RESET only) has its own CIC_OE_N_5V (sn64_top snes_cic_oe_n, enabled from the sequencer IFACE state). U207: D0-D7, DIR and OE both FPGA-cont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
CARTRIDGE OUTPUT DAMPING: 33 R arrays at the translator A pins (source-series). Values are provisional; tune after SI measurement.
SENSE + RELEASE PATHS
U209 SN74LVC244A at 3.3 V: 5.5 V-tolerant inputs with Ioff; receives /IRQ, /RESET, EXPAND (CIC data pins use U215/U216). U210-U212 74LVC1G07 / U213 74LVC1G06: 3.3 V open-drain outputs (5.5 V tolerant, Ioff) pulled to SNES_5V_CART. No 5 V pull-up reaches an FPGA pin. Interface rail off or FPGA uncon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
/OE and DIR edge timing: the bridge releases the data octet one 46.56 ns clock before turnaround. R203/R204 = 1k keep the passive rising edge short (about 10 pF load: tau ~10 ns); R201/R202 2.2k drive five/one /OE inputs where only permit-loss timing matters. Verify on hardware.
PULL/BIAS: /IRQ, /RESET, EXPAND 10k to cartridge 5 V (OpenSFC keeps pull-ups on IRQ/EXPAND); CIC_DATA0/1 10k pull-downs (R216/R217). Values provisional.
CIC DATA PINS - PER-PIN DIRECTION CONTROL (J2.55 CIC_DATA0 via U215, J2.24 CIC_DATA1 via U216)
SN74LVC1T45 (TI SCES515N): A = FPGA side (VCCA = INTERFACE_3V3), B = cartridge side (VCCB = SNES_5V_CART). No shared enable. DIR is referenced to VCCA and driven directly by its own FPGA pin cic_dataN_dir: H = A->B (FPGA drives the cartridge), L = B->A (listen). FPGA rule (no OE pin, SCES515N 8.2.2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
DECOUPLING: one 100 nF per supply pin (place at the pin) plus one 10 uF bulk per rail.
AUDIO: AUDIO_L_IN / AUDIO_R_IN pass untouched (no digital translation); test points only.
HIERARCHICAL PORTS - CARTRIDGE SIDE (root J2 net labels)
PENDING PORTS - FPGA SIDE (bridge port names) + DEFAULT-OFF RAILS FROM FUTURE POWER SHEET
DRAFT 0.3.1-cart: schematic circuit candidate only. No PCB, SI simulation, power sequencing test, ESD part or cartridge test has been performed. SNES_5V_CART and INTERFACE_3V3 are hierarchical inputs from the power sheet; #FLG201/#FLG202 are kept because the power-sheet switch outputs are passive p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

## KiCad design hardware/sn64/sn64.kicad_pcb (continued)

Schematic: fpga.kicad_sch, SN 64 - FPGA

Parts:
C401, C402, C403, C404, C405, C406, C407, C408, C409, C410, C411, C412, C413, C414, C415, C416, C417, C418, C419, C420, C424, C425, C426, C427, C429, C430, C432, C433, C435, C436, C437, C439, C440, C441, C443, C444, C445, C447, C448, C449, C451, C452, C454, C455, C456, C457, C458, C459: 100nF 16V X7R; C_0402_1005Metric
C421, C422, C423, C428, C431, C434, C438, C442, C446, C450, C453: 10uF 10V X5R; C_0603_1608Metric
D401: LED green 0603; LED_0603_1608Metric
FB401: BLM18PG121SN1D; L_0603_1608Metric; LCSC C14709
R401, R402, R403, R404, R407, R410, R411, R412, R413: 4.7k; R_0402_1005Metric
R405: 33; R_0402_1005Metric
R406, R419: 1k; R_0402_1005Metric
R408, R409, R416, R418: 10k; R_0402_1005Metric
R414: 0; R_0402_1005Metric
R415: 100k; R_0402_1005Metric
R417: 33k; R_0402_1005Metric
TP401: PROGRAMN; TestPoint_Pad_D1.0mm
TP402: INITN; TestPoint_Pad_D1.0mm
TP403: DONE; TestPoint_Pad_D1.0mm
TP404: FPGA_1V1; TestPoint_Pad_D1.0mm
TP405: VCCAUX; TestPoint_Pad_D1.0mm
TP406: FPGA_3V3; TestPoint_Pad_D1.0mm
TP407: FLASH_SCK; TestPoint_Pad_D1.0mm
TP408: N64_SW_OE_N; TestPoint_Pad_D1.0mm
U401: LFE5U-85F-6BG381C; Lattice_caBGA-381_17x17mm_Layout20x20_P0.8mm
U402, U403, U404: SN74CB3Q3384APWR; TSSOP-24_4.4x7.8mm_P0.65mm; LCSC C469874
U405: W25Q128JVSIQ; SOIC-8_5.3x5.3mm_P1.27mm; LCSC C97521
U406: SN74LVC1G14DBVR; SOT-23-5; LCSC C7835
U407: SN74LVC1G07DBVR; SOT-23-5; LCSC C7829

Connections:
/FPGA/FPGA_VCCAUX: C424.1, C425.1, C426.1, C427.1, C428.1, FB401.2, TP405.1, U401.F6 (VCCAUX), U401.F15 (VCCAUX), U401.P6 (VCCAUX), U401.P15 (VCCAUX)
/FPGA/flash_cs_n: R407.2, U401.R2 (PB15A), U405.1 (~CS)
/FPGA/flash_dq0: U401.W2 (PB11B), U405.5 (DI/IO_{0})
/FPGA/flash_dq1: U401.V2 (PB11A), U405.2 (DO/IO_{1})
/FPGA/flash_dq2: R408.2, U401.Y2 (PB9B), U405.3 (~WP/IO_{2})
/FPGA/flash_dq3: R409.2, U401.W1 (PB9A), U405.7 (~HOLD/~RESET/IO_{3})
/FPGA/flash_sck: R405.2, R406.2, TP407.1, U405.6 (CLK)
/FPGA/fpga_cfg1: R401.2, U401.T4 (CFG_1)
/FPGA/fpga_done: R404.2, TP403.1, U401.Y3 (DONE)
/FPGA/fpga_initn: R403.2, TP402.1, U401.V3 (~INIT)
/FPGA/fpga_mclk: R405.1, U401.U3 (CCLK)
/FPGA/fpga_n64_ad0: U401.E6 (PT6A), U402.2 (1B1)
/FPGA/fpga_n64_ad1: U401.D6 (PT6B), U402.5 (1B2)
/FPGA/fpga_n64_ad2: U401.E7 (PT9A), U402.6 (1B3)
/FPGA/fpga_n64_ad3: U401.D7 (PT9B), U402.9 (1B4)
/FPGA/fpga_n64_ad4: U401.C6 (PT11A), U402.10 (1B5)
/FPGA/fpga_n64_ad5: U401.C7 (PT11B), U402.15 (2B1)
/FPGA/fpga_n64_ad6: U401.E8 (PT13A), U402.16 (2B2)
/FPGA/fpga_n64_ad7: U401.D8 (PT13B), U402.19 (2B3)
/FPGA/fpga_n64_ad8: U401.C8 (PT15A), U402.20 (2B4)
/FPGA/fpga_n64_ad9: U401.B8 (PT15B), U402.23 (2B5)
/FPGA/fpga_n64_ad10: U401.A7 (PT18A), U403.2 (1B1)
/FPGA/fpga_n64_ad11: U401.A8 (PT18B), U403.5 (1B2)
/FPGA/fpga_n64_ad12: U401.D9 (PT20A), U403.6 (1B3)
/FPGA/fpga_n64_ad13: U401.E9 (PT20B), U403.9 (1B4)
/FPGA/fpga_n64_ad14: U401.C9 (PT54A), U403.10 (1B5)
/FPGA/fpga_n64_ad15: U401.D10 (PT56A), U403.15 (2B1)
/FPGA/fpga_n64_aleh: U401.B9 (PT58A), U403.19 (2B3)
/FPGA/fpga_n64_alel: U401.E10 (PT56B), U403.16 (2B2)
/FPGA/fpga_n64_cic_clk: U401.A10 (PT63A), U404.6 (1B3)
/FPGA/fpga_n64_cic_dq: U401.C11 (PT65B), U404.10 (1B5)
/FPGA/fpga_n64_int_n: U401.B6 (PT4B), U404.16 (2B2)
/FPGA/fpga_n64_nmi_n: U401.A11 (PT63B), U404.5 (1B2)
/FPGA/fpga_n64_read_n: U401.C10 (PT58B), U403.20 (2B4)
/FPGA/fpga_n64_reset_n: U401.B10 (PT60B), U404.2 (1B1)
/FPGA/fpga_n64_si_clk: U401.B11 (PT65A), U404.9 (1B4)
/FPGA/fpga_n64_si_dq: U401.A6 (PT4A), U404.15 (2B1)
/FPGA/fpga_n64_write_n: U401.A9 (PT60A), U403.23 (2B5)
/FPGA/fpga_programn: R402.2, TP401.1, U401.W3 (~PROGRAM), U407.4
/FPGA/host_det: R416.2, R417.1, U406.2
/FPGA/led_a: D401.2 (A), R419.2
/FPGA/led_status: R419.1, U401.B1 (PL35B)
/FPGA/n64_sw_oe_n: R418.2, TP408.1, U402.1 (~1OE), U402.13 (~2OE), U403.1 (~1OE), U403.13 (~2OE), U404.1 (~1OE), U404.13 (~2OE), U406.4
/FPGA_1V1: C401.1, C402.1, C403.1, C404.1, C405.1, C406.1, C407.1, C408.1, C409.1, C410.1, C411.1, C412.1, C413.1, C414.1, C415.1, C416.1, C417.1, C418.1, C419.1, C420.1, C421.1, C422.1, C423.1, TP404.1, U401.H8 (VCC), U401.H9 (VCC), U401.H10 (VCC), U401.H11 (VCC), U401.H12 (VCC), U401.H13 (VCC), U401.J8 (VCC), U401.J13 (VCC), U401.K8 (VCC), U401.K13 (VCC), U401.L8 (VCC), U401.L13 (VCC), U401.M8 (VCC), U401.M13 (VCC), U401.N8 (VCC), U401.N9 (VCC), U401.N10 (VCC), U401.N11 (VCC), U401.N12 (VCC), U401.N13 (VCC); also elsewhere on the board
/FPGA_2V5: FB401.1; also elsewhere on the board
/FPGA_3V3: C429.1, C430.1, C431.1, C432.1, C433.1, C434.1, C435.1, C436.1, C437.1, C438.1, C439.1, C440.1, C441.1, C442.1, C443.1, C444.1, C445.1, C446.1, C447.1, C448.1, C449.1, C450.1, C451.1, C452.1, C453.1, C454.1, C455.1, C456.1, C457.1, C458.1, C459.1, R401.1, R402.1, R403.1, R404.1, R406.1, R407.1, R408.1, R409.1, R410.1, R411.1, R412.1, R414.1, R418.1, TP406.1, U401.F9 (VCCIO0), U401.F10 (VCCIO0), U401.F11 (VCCIO1), U401.F12 (VCCIO1), U401.H6 (VCCIO7), U401.H7 (VCCIO7), U401.H14 (VCCIO2), U401.H15 (VCCIO2), U401.J6 (VCCIO7), U401.J15 (VCCIO2), U401.L6 (VCCIO6), U401.L7 (VCCIO6), U401.L14 (VCCIO3), U401.L15 (VCCIO3), U401.M6 (VCCIO6), U401.M15 (VCCIO3), U401.P9 (VCCIO8), U401.P10 (VCCIO8), U402.24 (VCC), U403.24 (VCC), U404.24 (VCC), U405.8 (VCC), U406.5 (VCC), U407.5 (VCC); also elsewhere on the board
/GND: C401.2, C402.2, C403.2, C404.2, C405.2, C406.2, C407.2, C408.2, C409.2, C410.2, C411.2, C412.2, C413.2, C414.2, C415.2, C416.2, C417.2, C418.2, C419.2, C420.2, C421.2, C422.2, C423.2, C424.2, C425.2, C426.2, C427.2, C428.2, C429.2, C430.2, C431.2, C432.2, C433.2, C434.2, C435.2, C436.2, C437.2, C438.2, C439.2, C440.2, C441.2, C442.2, C443.2, C444.2, C445.2, C446.2, C447.2, C448.2, C449.2, C450.2, C451.2, C452.2, C453.2, C454.2, C455.2, C456.2, C457.2, C458.2, C459.2, D401.1 (K), R413.2, R415.2, R417.2, U401.B7 (GND), U401.B14 (GND), U401.C19 (GND), U401.D4 (GND), U401.F7 (GND), U401.F8 (GND), U401.F13 (GND), U401.F14 (GND), U401.G4 (GND), U401.G6 (GND), U401.G7 (GND), U401.G8 (GND), U401.G9 (GND), U401.G10 (GND), U401.G11 (GND), U401.G12 (GND), U401.G13 (GND), U401.G14 (GND), U401.G15 (GND), U401.G17 (GND), U401.H19 (GND), U401.J2 (GND), U401.J7 (GND), U401.J9 (GND), U401.J10 (GND), U401.J11 (GND), U401.J12 (GND), U401.J14 (GND), U401.K6 (GND), U401.K7 (GND), U401.K9 (GND), U401.K10 (GND), U401.K11 (GND), U401.K12 (GND), U401.K14 (GND), U401.K15 (GND), U401.L9 (GND), U401.L10 (GND), U401.L11 (GND), U401.L12 (GND), U401.M2 (GND), U401.M7 (GND), U401.M9 (GND), U401.M10 (GND), U401.M11 (GND), U401.M12 (GND), U401.M14 (GND), U401.M16 (GND), U401.N6 (GND), U401.N7 (GND), U401.N14 (GND), U401.N15 (GND), U401.P7 (GND), U401.P8 (GND), U401.P11 (GND), U401.P12 (GND), U401.P13 (GND), U401.P14 (GND), U401.R4 (CFG_2), U401.R19 (GND), U401.T6 (GND), U401.T7 (GND), U401.T8 (GND), U401.T9 (GND), U401.T10 (GND), U401.T11 (GND), U401.T12 (GND), U401.T13 (GND), U401.T14 (GND), U401.T15 (GND), U401.U4 (CFG_0), U401.U6 (GND), U401.U7 (GND), U401.U8 (GND), U401.U9 (GND), U401.U10 (GND), U401.U11 (GND), U401.U12 (GND), U401.U13 (GND), U401.U14 (GND), U401.U15 (GND), U401.V5 (GND), U401.V6 (GND), U401.V7 (GND), U401.V8 (GND), U401.V9 (GND), U401.V10 (GND), U401.V11 (GND), U401.V12 (GND), U401.V13 (GND), U401.V14 (GND), U401.V15 (GND), U401.V16 (GND), U401.V17 (GND), U401.V18 (GND), U401.V19 (GND), U401.V20 (GND), U401.W6 (GND), U401.W7 (GND), U401.W12 (GND), U401.W15 (GND), U401.W16 (GND), U401.W19 (GND), U401.W20 (GND), U401.Y5 (GND), U401.Y6 (GND), U401.Y7 (GND), U401.Y8 (GND), U401.Y11 (GND), U401.Y12 (GND), U401.Y14 (GND), U401.Y15 (GND), U401.Y16 (GND), U401.Y17 (GND), U401.Y19 (GND), U402.12 (GND), U403.12 (GND), U404.12 (GND), U405.4 (GND), U406.3 (GND), U407.3 (GND); also elsewhere on the board
/HOST_3V3: R416.1; also elsewhere on the board
/N64_AD0: U402.3 (1A1); also elsewhere on the board
/N64_AD1: U402.4 (1A2); also elsewhere on the board
/N64_AD2: U402.7 (1A3); also elsewhere on the board
/N64_AD3: U402.8 (1A4); also elsewhere on the board
/N64_AD4: U402.11 (1A5); also elsewhere on the board
/N64_AD5: U402.14 (2A1); also elsewhere on the board
/N64_AD6: U402.17 (2A2); also elsewhere on the board
/N64_AD7: U402.18 (2A3); also elsewhere on the board
/N64_AD8: U402.21 (2A4); also elsewhere on the board
/N64_AD9: U402.22 (2A5); also elsewhere on the board
/N64_AD10: U403.3 (1A1); also elsewhere on the board
/N64_AD11: U403.4 (1A2); also elsewhere on the board
/N64_AD12: U403.7 (1A3); also elsewhere on the board
/N64_AD13: U403.8 (1A4); also elsewhere on the board
/N64_AD14: U403.11 (1A5); also elsewhere on the board
/N64_AD15: U403.14 (2A1); also elsewhere on the board
/N64_ALE_H: U403.18 (2A3); also elsewhere on the board
/N64_ALE_L: U403.17 (2A2); also elsewhere on the board
/N64_CIC_CLK: U404.7 (1A3); also elsewhere on the board
/N64_CIC_DATA: U404.11 (1A5); also elsewhere on the board
/N64_INT_N: U404.17 (2A2); also elsewhere on the board
/N64_JOYBUS: U404.14 (2A1); also elsewhere on the board
/N64_NMI_N: U404.4 (1A2); also elsewhere on the board
/N64_PIF_CLK: U404.8 (1A4); also elsewhere on the board
/N64_READ_N: U403.21 (2A4); also elsewhere on the board
/N64_RESET_N: U404.3 (1A1); also elsewhere on the board
/N64_WRITE_N: U403.22 (2A5); also elsewhere on the board
/TARGET_VREF: R414.2; also elsewhere on the board
/adc_bck: U401.J4 (PL50A); also elsewhere on the board
/adc_dout: U401.K3 (PL50D); also elsewhere on the board
/adc_lrck: U401.J3 (PL50C); also elsewhere on the board
/board_reset_n: U401.L4 (PL56C); also elsewhere on the board
/cart_5v_enable: U401.L5 (PL56D); also elsewhere on the board
/cart_5v_ok: U401.H1 (PL53C); also elsewhere on the board
/cart_address0: U401.C18 (PR11A); also elsewhere on the board
/cart_address1: U401.D17 (PR11B); also elsewhere on the board
/cart_address2: U401.E16 (PR11C); also elsewhere on the board
/cart_address3: U401.F16 (PR11D); also elsewhere on the board
/cart_address4: U401.D18 (PR14A); also elsewhere on the board
/cart_address5: U401.E17 (PR14B); also elsewhere on the board
/cart_address6: U401.E18 (PR14C); also elsewhere on the board
/cart_address7: U401.F18 (PR14D); also elsewhere on the board
/cart_address8: U401.F17 (PR17A); also elsewhere on the board
/cart_address9: U401.G18 (PR17B); also elsewhere on the board
/cart_address10: U401.G16 (PR17C); also elsewhere on the board
/cart_address11: U401.H16 (PR17D); also elsewhere on the board
/cart_address12: U401.H18 (PR20A); also elsewhere on the board
/cart_address13: U401.H17 (PR20B); also elsewhere on the board
/cart_address14: U401.J17 (PR20C); also elsewhere on the board
/cart_address15: U401.J16 (PR20D); also elsewhere on the board
/cart_address16: U401.K16 (PR29A); also elsewhere on the board
/cart_address17: U401.K17 (PR29B); also elsewhere on the board
/cart_address18: U401.C20 (PR35A); also elsewhere on the board
/cart_address19: U401.D19 (PR35B); also elsewhere on the board
/cart_address20: U401.D20 (PR35C); also elsewhere on the board
/cart_address21: U401.E19 (PR35D); also elsewhere on the board
/cart_address22: U401.E20 (PR38A); also elsewhere on the board
/cart_address23: U401.F19 (PR38B); also elsewhere on the board
/cart_data0: U401.L16 (PR50A); also elsewhere on the board
/cart_data1: U401.L17 (PR50B); also elsewhere on the board
/cart_data2: U401.L18 (PR50C); also elsewhere on the board
/cart_data3: U401.M18 (PR50D); also elsewhere on the board
/cart_data4: U401.N16 (PR53A); also elsewhere on the board
/cart_data5: U401.M17 (PR53B); also elsewhere on the board
/cart_data6: U401.N18 (PR53C); also elsewhere on the board
/cart_data7: U401.P17 (PR53D); also elsewhere on the board
/cart_irq_n: U401.T18 (PR89D); also elsewhere on the board
/cart_pa0: U401.F20 (PR38C); also elsewhere on the board
/cart_pa1: U401.G20 (PR38D); also elsewhere on the board
/cart_pa2: U401.G19 (PR41A); also elsewhere on the board
/cart_pa3: U401.H20 (PR41B); also elsewhere on the board
/cart_pa4: U401.J18 (PR41C); also elsewhere on the board
/cart_pa5: U401.K18 (PR41D); also elsewhere on the board
/cart_pa6: U401.J19 (PR44A); also elsewhere on the board
/cart_pa7: U401.K19 (PR44B); also elsewhere on the board
/cart_phi2: U401.M20 (PR47B); also elsewhere on the board
/cart_prd_n: U401.P16 (PR56B); also elsewhere on the board
/cart_pwr_n: U401.R16 (PR56C); also elsewhere on the board
/cart_rd_n: U401.M19 (PR47D); also elsewhere on the board
/cart_refresh: U401.L19 (PR47C); also elsewhere on the board
/cart_reset_n_sense: U401.U18 (PR92A); also elsewhere on the board
/cart_reset_pull_n: U401.U19 (PR89C); also elsewhere on the board
/cart_romsel_n: U401.R17 (PR56D); also elsewhere on the board
/cart_sysclk: U401.L20 (PR47A); also elsewhere on the board
/cart_wr_n: U401.N17 (PR56A); also elsewhere on the board
/cart_wramsel_n: U401.T16 (PR77A); also elsewhere on the board
/cic_clk: U401.P20 (PR86A); also elsewhere on the board
/cic_data0: U401.T20 (PR86C); also elsewhere on the board
/cic_data0_dir: U401.U20 (PR86D); also elsewhere on the board
/cic_data1: U401.T19 (PR89A); also elsewhere on the board
/cic_data1_dir: U401.R18 (PR89B); also elsewhere on the board
/cic_oe_n: U401.P18 (PR83D); also elsewhere on the board
/cic_slave_reset: U401.R20 (PR86B); also elsewhere on the board
/ctl_oe_n: U401.N19 (PR83A); also elsewhere on the board
/data_dir: U401.P19 (PR83C); also elsewhere on the board
/data_oe_n: U401.N20 (PR83B); also elsewhere on the board
/efuse_fault_n: U401.K4 (PL56A); also elsewhere on the board
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

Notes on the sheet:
SN64 FPGA - LFE5U-85F CABGA381, CONFIGURATION FLASH, JTAG, N64 HOST ISOLATION
Rails: VCC = FPGA_1V1 (1.1 V, DS-02012 Table 3.2), VCCAUX = FPGA_2V5 through FB401 (TN-02038 Figure 3.1), every VCCIO0/1/2/3/6/7/8 = FPGA_3V3. Bank plan: 0 = N64 PI/CIC/SI behind the bus switches (top bank, hot-socket capable), 1 = spare (HDMI removed in 0.5-fpga: video goes to the console over the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
Configuration: CFG[2:0] = 010 Master SPI (CFG0/CFG2 to GND, CFG1 4.7k to VCCIO8). PROGRAMN/INITN/DONE 4.7k to VCCIO8 (TN-02038 Table 6.2). U307 holds PROGRAMN low until fpga_rails_ok (DS-02012 3.5: MSPI needs VCCIO8 above the flash VIH before VCC/VCCAUX reach VPORUP, or PROGRAMN/INITN held low). U4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
N64 HOST ISOLATION: U402-U404 SN74CB3Q3384A FET bus switches (A = N64 edge, B = FPGA bank 0), VCC = FPGA_3V3. OE = NOT(HOST_3V3 present): U406 Schmitt inverter on the R416/R417 divider. USB-only (HOST_3V3 absent): OE high, switch off. FPGA_3V3 absent: switch unpowered, "isolation during power off" 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
DRAFT 0.5-fpga: schematic only - no PCB, no SI or power-integrity analysis, no hardware test. FPGA_1V1/2V5/3V3 come from the power sheet (its #FLG302-#FLG304 are their ERC origins). #FLG404 marks FPGA_VCCAUX, fed only through FB401. Pin map: interfaces/fpga-pin-map.csv; constraints: fpga/constraint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

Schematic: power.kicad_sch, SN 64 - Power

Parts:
C301, C311, C333, C334, C335, C336, C337, C338, C339, C340: 100nF; C_0603_1608Metric
C302, C305: 1.5nF 25V; C_0603_1608Metric
C303, C306, C309: 1.2nF; C_0603_1608Metric
C304, C307, C310: 1uF 25V; C_0805_2012Metric
C308: 680pF 25V; C_0603_1608Metric
C312, C313: 10uF 25V; C_0805_2012Metric
C314, C315: 22uF 25V; C_1206_3216Metric
C316, C317, C318, C320, C321, C322, C324, C325, C326, C328, C329, C330: 22uF 10V; C_0805_2012Metric
C319, C323, C327: 6.8pF C0G; C_0603_1608Metric
C331: 470pF 25V C0G; C_0603_1608Metric
C332: 1uF 10V; C_0603_1608Metric
L301: 1.5uH PNR4020-1R5M; L_APV_PNR4020; MPN PNR4020-1R5M; LCSC C54620133
L302, L303, L304: 2.2uH FNR4030S2R2MT; L_Changjiang_FNR4030S; MPN FNR4030S2R2MT; LCSC C167869
Q301, Q302, Q303, Q304, Q305, Q306, Q307, Q308: BSS138BK; SOT-23; MPN BSS138BK,215; LCSC C282529
R301: 887k 1%; R_0603_1608Metric
R302, R303, R304, R305, R306, R322, R323, R324, R325, R327, R333: 100k; R_0603_1608Metric
R307: 267k 1%; R_0603_1608Metric
R308, R310, R313, R315, R318, R320, R365: 100k 1%; R_0603_1608Metric
R309: 383k 1%; R_0603_1608Metric
R311: 2.55k 1%; R_0603_1608Metric
R312: 150k 1%; R_0603_1608Metric
R314: 215k 1%; R_0603_1608Metric
R316: 6.65k 1%; R_0603_1608Metric
R317: 287k 1%; R_0603_1608Metric
R319: 357k 1%; R_0603_1608Metric
R321: 3.32k 1%; R_0603_1608Metric
R326, R340: 1k; R_0603_1608Metric
R328: 470 0805; R_0805_2012Metric
R329, R360, R361, R362, R363, R366, R368: 10k; R_0603_1608Metric
R331, R357: 232k 0.1%; R_0603_1608Metric
R332, R356: 44.2k 0.1%; R_0603_1608Metric
R334: 100k 0.1%; R_0603_1608Metric
R335: 120k 0.1%; R_0603_1608Metric
R336: 361k 0.1%; R_0603_1608Metric
R337: 114k 0.1%; R_0603_1608Metric
R338: 459k 0.1%; R_0603_1608Metric
R339: 102k 0.1%; R_0603_1608Metric
R341: 100; R_0603_1608Metric
R342: 442k 0.1%; R_0603_1608Metric
R343: 37.4k 0.1%; R_0603_1608Metric
R344: 33.6k 0.1%; R_0603_1608Metric
R345: 115k 0.1%; R_0603_1608Metric
R346: 3.74k 0.1%; R_0603_1608Metric
R347: 64.2k 0.1%; R_0603_1608Metric
R348: 287k 0.1%; R_0603_1608Metric
R349: 3.16k 0.1%; R_0603_1608Metric
R350: 53.0k 0.1%; R_0603_1608Metric
R351: 277k 0.1%; R_0603_1608Metric
R352: 2.37k 0.1%; R_0603_1608Metric
R353: 37.0k 0.1%; R_0603_1608Metric
R354: 530k 0.1%; R_0603_1608Metric
R355: 3.79k 0.1%; R_0603_1608Metric
R358: 5.05k 0.1%; R_0603_1608Metric
R359: 30.1k 0.1%; R_0603_1608Metric
R364: 649k 1%; R_0603_1608Metric
R367: 47k; R_0603_1608Metric
TP301: SYS_VIN; TestPoint_Pad_D1.0mm
TP302: USB_FLT_N; TestPoint_Pad_D1.0mm
TP303: HOST_FLT_N; TestPoint_Pad_D1.0mm
TP304: HOST_AUXOFF; TestPoint_Pad_D1.0mm
TP305: CART_AUXOFF; TestPoint_Pad_D1.0mm
TP306: TC_OUT2; TestPoint_Pad_D1.0mm
TP307: 5V_PRE; TestPoint_Pad_D1.0mm
TP308: SNES_5V_CART; TestPoint_Pad_D1.0mm
TP309: USB_AUXOFF; TestPoint_Pad_D1.0mm
TP310: ILM_U309; TestPoint_Pad_D1.0mm
U301: TUSB320IRWBR; Texas_X2QFN-12_1.6x1.6mm_P0.4mm; LCSC C80170
U302, U303, U309: TPS259470LRPWR; Texas_RPW0010A_VQFN-HR-10_2x2mm; LCSC C3662793
U304: TPS63070RNMR; Texas_RNM0015A_VQFN-HR-15_2.5x3mm; LCSC C109322
U305, U306, U307: TLV62569DBVR; SOT-23-5; LCSC C141836
U308: TPS22918DBVR; SOT-23-6; LCSC C131941
U310, U311, U312, U313, U314, U315: TPS3700DDCR; SOT-23-6; LCSC C33002
U316: TPS3808G01DBVR; SOT-23-6; LCSC C19653
U317: TMP302ADRLR; SOT-563; LCSC C2877557

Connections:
/5V_PRE: C310.1, C316.1, C317.1, C318.1, C320.1, C324.1, C328.1, R317.1, R319.1, R327.1, R331.1, R333.1, TP307.1, U304.7 (VOUT), U304.8 (VOUT), U305.4 (VIN), U306.4 (VIN), U307.4 (VIN), U309.5 (IN); also elsewhere on the board
/FPGA_1V1: C319.1, C321.1, C322.1, L302.2, R334.1, R345.1; also elsewhere on the board
/FPGA_2V5: C323.1, C325.1, C326.1, L303.2, R336.1, R348.1; also elsewhere on the board
/FPGA_3V3: C327.1, C329.1, C330.1, C332.1, C333.1, C334.1, C335.1, C336.1, C337.1, C338.1, C339.1, C340.1, L304.2, R325.1, R329.1, R338.1, R351.1, R360.1, R361.1, R362.1, R363.1, R364.1, R366.1, R367.1, R368.1, U308.1 (VIN), U310.5 (VDD), U311.5 (VDD), U312.5 (VDD), U313.5 (VDD), U314.5 (VDD), U315.5 (VDD), U316.6 (VDD), U317.1 (TRIPSET0), U317.4 (HYSTSET), U317.5 (VS), U317.6 (TRIPSET1); also elsewhere on the board
/GND: C301.2, C302.2, C303.2, C304.2, C305.2, C306.2, C307.2, C308.2, C309.2, C310.2, C311.2, C312.2, C313.2, C314.2, C315.2, C316.2, C317.2, C318.2, C320.2, C321.2, C322.2, C324.2, C325.2, C326.2, C328.2, C329.2, C330.2, C331.2, C332.2, C333.2, C334.2, C335.2, C336.2, C337.2, C338.2, C339.2, C340.2, Q301.2 (S), Q302.2 (S), Q303.2 (S), Q304.2 (S), Q305.2 (S), Q306.2 (S), Q307.2 (S), Q308.2 (S), R308.2, R310.2, R311.2, R313.2, R315.2, R316.2, R318.2, R320.2, R321.2, R326.2, R332.2, R335.2, R337.2, R339.2, R340.2, R344.2, R347.2, R350.2, R353.2, R356.2, R359.2, R365.2, U301.3 (PORT), U301.10 (GND), U301.11 (~EN), U302.8 (GND), U303.8 (GND), U304.1 (PS/SYNC), U304.4 (GND), U304.10 (PGND), U304.15 (VSEL), U305.2 (GND), U306.2 (GND), U307.2 (GND), U308.2 (GND), U309.8 (GND), U310.2 (GND), U311.2 (GND), U312.2 (GND), U313.2 (GND), U314.2 (GND), U315.2 (GND), U316.2 (GND), U317.2 (GND); also elsewhere on the board
/HOST_3V3: C307.1, R312.1, R314.1, R323.1, R324.1, U303.5 (IN); also elsewhere on the board
/INTERFACE_3V3: R341.2, R357.1, U308.6 (VOUT); also elsewhere on the board
/Power/CART_AUXOFF: R325.2, TP305.1, U309.3 (AUXOFF)
/Power/CART_DIS: Q307.3 (D), R328.2
/Power/CART_EN: Q306.3 (D), R317.2, R318.1, U309.1 (EN/UVLO)
/Power/CART_INHIBIT: Q305.3 (D), Q306.1 (G), Q307.1 (G), R327.2
/Power/CART_OVLO: R319.2, R320.1, U309.2 (OVLO)
/Power/CT_IFACE: C331.1, U308.4 (CT)
/Power/DVDT_U302: C302.1, U302.7 (DVDT)
/Power/DVDT_U303: C305.1, U303.7 (DVDT)
/Power/DVDT_U309: C308.1, U309.7 (DVDT)
/Power/FB_1V1: C319.2, R334.2, R335.1, U305.5 (FB)
/Power/FB_2V5: C323.2, R336.2, R337.1, U306.5 (FB)
/Power/FB_3V3: C327.2, R338.2, R339.1, U307.5 (FB)
/Power/FB_5V: R331.2, R332.1, U304.5 (FB)
/Power/HOST_AUXOFF: R324.2, TP304.1, U303.3 (AUXOFF)
/Power/HOST_EN: Q304.3 (D), R312.2, R313.1, U303.1 (EN/UVLO)
/Power/HOST_FLT_N: R323.2, TP303.1, U303.4 (~FLT)
/Power/HOST_OVLO: R314.2, R315.1, U303.2 (OVLO)
/Power/ILM_U302: R311.1, U302.9 (ILM)
/Power/ILM_U303: R316.1, U303.9 (ILM)
/Power/ILM_U309: R321.1, TP310.1, U309.9 (ILM)
/Power/ITIMER_U302: C303.1, U302.10 (ITIMER)
/Power/ITIMER_U303: C306.1, U303.10 (ITIMER)
/Power/ITIMER_U309: C309.1, U309.10 (ITIMER)
/Power/L1_5V: L301.1, U304.11 (L1)
/Power/L2_5V: L301.2, U304.9 (L2)
/Power/MON_A_U310: R342.2, R343.1, U310.3 (INA+)
/Power/MON_A_U311: R345.2, R346.1, U311.3 (INA+)
/Power/MON_A_U312: R348.2, R349.1, U312.3 (INA+)
/Power/MON_A_U313: R351.2, R352.1, U313.3 (INA+)
/Power/MON_A_U314: R354.2, R355.1, U314.3 (INA+)
/Power/MON_A_U315: R357.2, R358.1, U315.3 (INA+)
/Power/MON_B_U310: R343.2, R344.1, U310.4 (INB-)
/Power/MON_B_U311: R346.2, R347.1, U311.4 (INB-)
/Power/MON_B_U312: R349.2, R350.1, U312.4 (INB-)
/Power/MON_B_U313: R352.2, R353.1, U313.4 (INB-)
/Power/MON_B_U314: R355.2, R356.1, U314.4 (INB-)
/Power/MON_B_U315: R358.2, R359.1, U315.4 (INB-)
/Power/OT_N: Q308.1 (G), R367.2, U317.3 (~OUT)
/Power/PG_5V: R333.2, U304.2 (PG), U305.1 (EN), U306.1 (EN), U307.1 (EN)
/Power/QOD_IFACE: R341.1, U308.5 (QOD)
/Power/SENSE_3V3: R364.2, R365.1, U316.5 (SENSE)
/Power/SW_1V1: L302.1, U305.3 (SW)
/Power/SW_2V5: L303.1, U306.3 (SW)
/Power/SW_3V3: L304.1, U307.3 (SW)
/Power/SYS_VIN: C312.1, C313.1, C314.1, C315.1, R342.1, TP301.1, U302.6 (OUT), U303.6 (OUT), U304.12 (VIN), U304.13 (VIN), U304.14 (EN)
/Power/TC_OUT1: Q301.1 (G), R302.2, U301.7 (SDA/OUT1)
/Power/TC_OUT2: R303.2, TP306.1, U301.8 (SCL/OUT2)
/Power/USB_AUXOFF: Q304.1 (G), R306.2, TP309.1, U302.3 (AUXOFF)
/Power/USB_EN: Q303.3 (D), R307.2, R308.1, U302.1 (EN/UVLO)
/Power/USB_FLT_N: R322.2, TP302.1, U302.4 (~FLT)
/Power/USB_INHIBIT: Q302.3 (D), Q303.1 (G), R305.2
/Power/USB_OVLO: R309.2, R310.1, U302.2 (OVLO)
/Power/USB_PERMIT: Q301.3 (D), Q302.1 (G), R304.2
/Power/VAUX_5V: C311.1, U304.3 (VAUX)
/Power/VBUS_DET: R301.2, U301.4 (VBUS_DET)
/SNES_5V_CART: R328.1, R354.1, TP308.1, U309.6 (OUT); also elsewhere on the board
/USB_3V3: C301.1, R302.1, R303.1, R304.1, R306.1, R322.1, U301.12 (VDD); also elsewhere on the board
/USB_CC1: U301.1 (CC1); also elsewhere on the board
/USB_CC2: U301.2 (CC2); also elsewhere on the board
/USB_VBUS: C304.1, R301.1, R305.1, R307.1, R309.1, U302.5 (IN); also elsewhere on the board
/board_reset_n: R366.2, U316.1 (~RESET); also elsewhere on the board
/cart_5v_enable: Q305.1 (G), R326.1; also elsewhere on the board
/cart_5v_ok: R362.2, U314.1 (OUTA), U314.6 (OUTB); also elsewhere on the board
/efuse_fault_n: R329.2, U309.4 (~FLT); also elsewhere on the board
/fpga_rails_ok: R361.2, U311.1 (OUTA), U311.6 (OUTB), U312.1 (OUTA), U312.6 (OUTB), U313.1 (OUTA), U313.6 (OUTB), U316.3 (~MR); also elsewhere on the board
/host_3v3_ok: R360.2, U310.1 (OUTA), U310.6 (OUTB); also elsewhere on the board
/iface_rail_enable: R340.1, U308.3 (ON); also elsewhere on the board
/iface_rail_ok: R363.2, U315.1 (OUTA), U315.6 (OUTB); also elsewhere on the board
/overtemp: Q308.3 (D), R368.2; also elsewhere on the board

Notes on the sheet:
SN64 POWER - source selection, system regulator, FPGA rails, cartridge eFuse, interface rail, monitors
Implements docs/design/power-architecture.md; math and sources in docs/design/power-schematic.md. HOST_12V is not used on this sheet. Priority power mux (TI SLVSFC9C Figure 8-14): U302 (USB, priority) AUXOFF -> Q304 pulls U303 (HOST_3V3, auxiliary) EN/UVLO low. Both eFuses have true reverse-current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
USB permission (default off): U302 enables only when TUSB320 OUT1 is low (1.5 A or 3 A advertised) AND USB_3V3 is present. TUSB320: PORT=GND (UFP), ADDR open (GPIO mode), EN_N=GND, VDD=USB_3V3 (power register PWR-L06). The USB sheet 5.1k Rd must be DNP.
SYSTEM REGULATOR: U304 TPS63070 buck-boost (forced PWM, +/-1% FB), SYS_VIN 2.7-6 V -> 5V_PRE 5.00 V. PG_5V enables the three TLV62569 bucks. ECP5: VCCIO8 must be valid before VCC/VCCAUX reach POR, or PROGRAMN/INITN held low (FPGA-DS-02012 3.4 sec. 3.5): fpga_rails_ok gates PROGRAMN on the FPGA shee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
CARTRIDGE 5 V: U309 TPS259470L, EN/UVLO default low (Q306 clamp until cart_5v_enable), UVLO 4.64 V / OVLO 5.48 V rising, ILIM 1.00 A (PROV), dVdt 680 pF (PROV), ITIMER 1.2 nF. Q307 + R328 470R discharge while inhibited (<=12 mA into an energized rail). INTERFACE_3V3: U308 TPS22918, ON default low (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
MONITORS (all powered from FPGA_3V3, outputs pulled up to FPGA_3V3 = 3.3 V-safe; supply loss reads NOT OK): U310 SYS_VIN -> host_3v3_ok | U311-U313 FPGA rails -> fpga_rails_ok | U314 SNES_5V_CART (socket side) -> cart_5v_ok | U315 INTERFACE_3V3 -> iface_rail_ok | U309 FLT (10k to FPGA_3V3) -> efuse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
DRAFT 0.1-power: schematic candidate only. No PCB, no measured load. Values marked PROV depend on unmeasured cartridge and FPGA current. Footprints for U302/U303/U309 (RPW0010A), U304 (RNM0015A) and L301 (PNR4020) are drawn from the manufacturer land patterns by tools/make_power_footprints.py; L302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

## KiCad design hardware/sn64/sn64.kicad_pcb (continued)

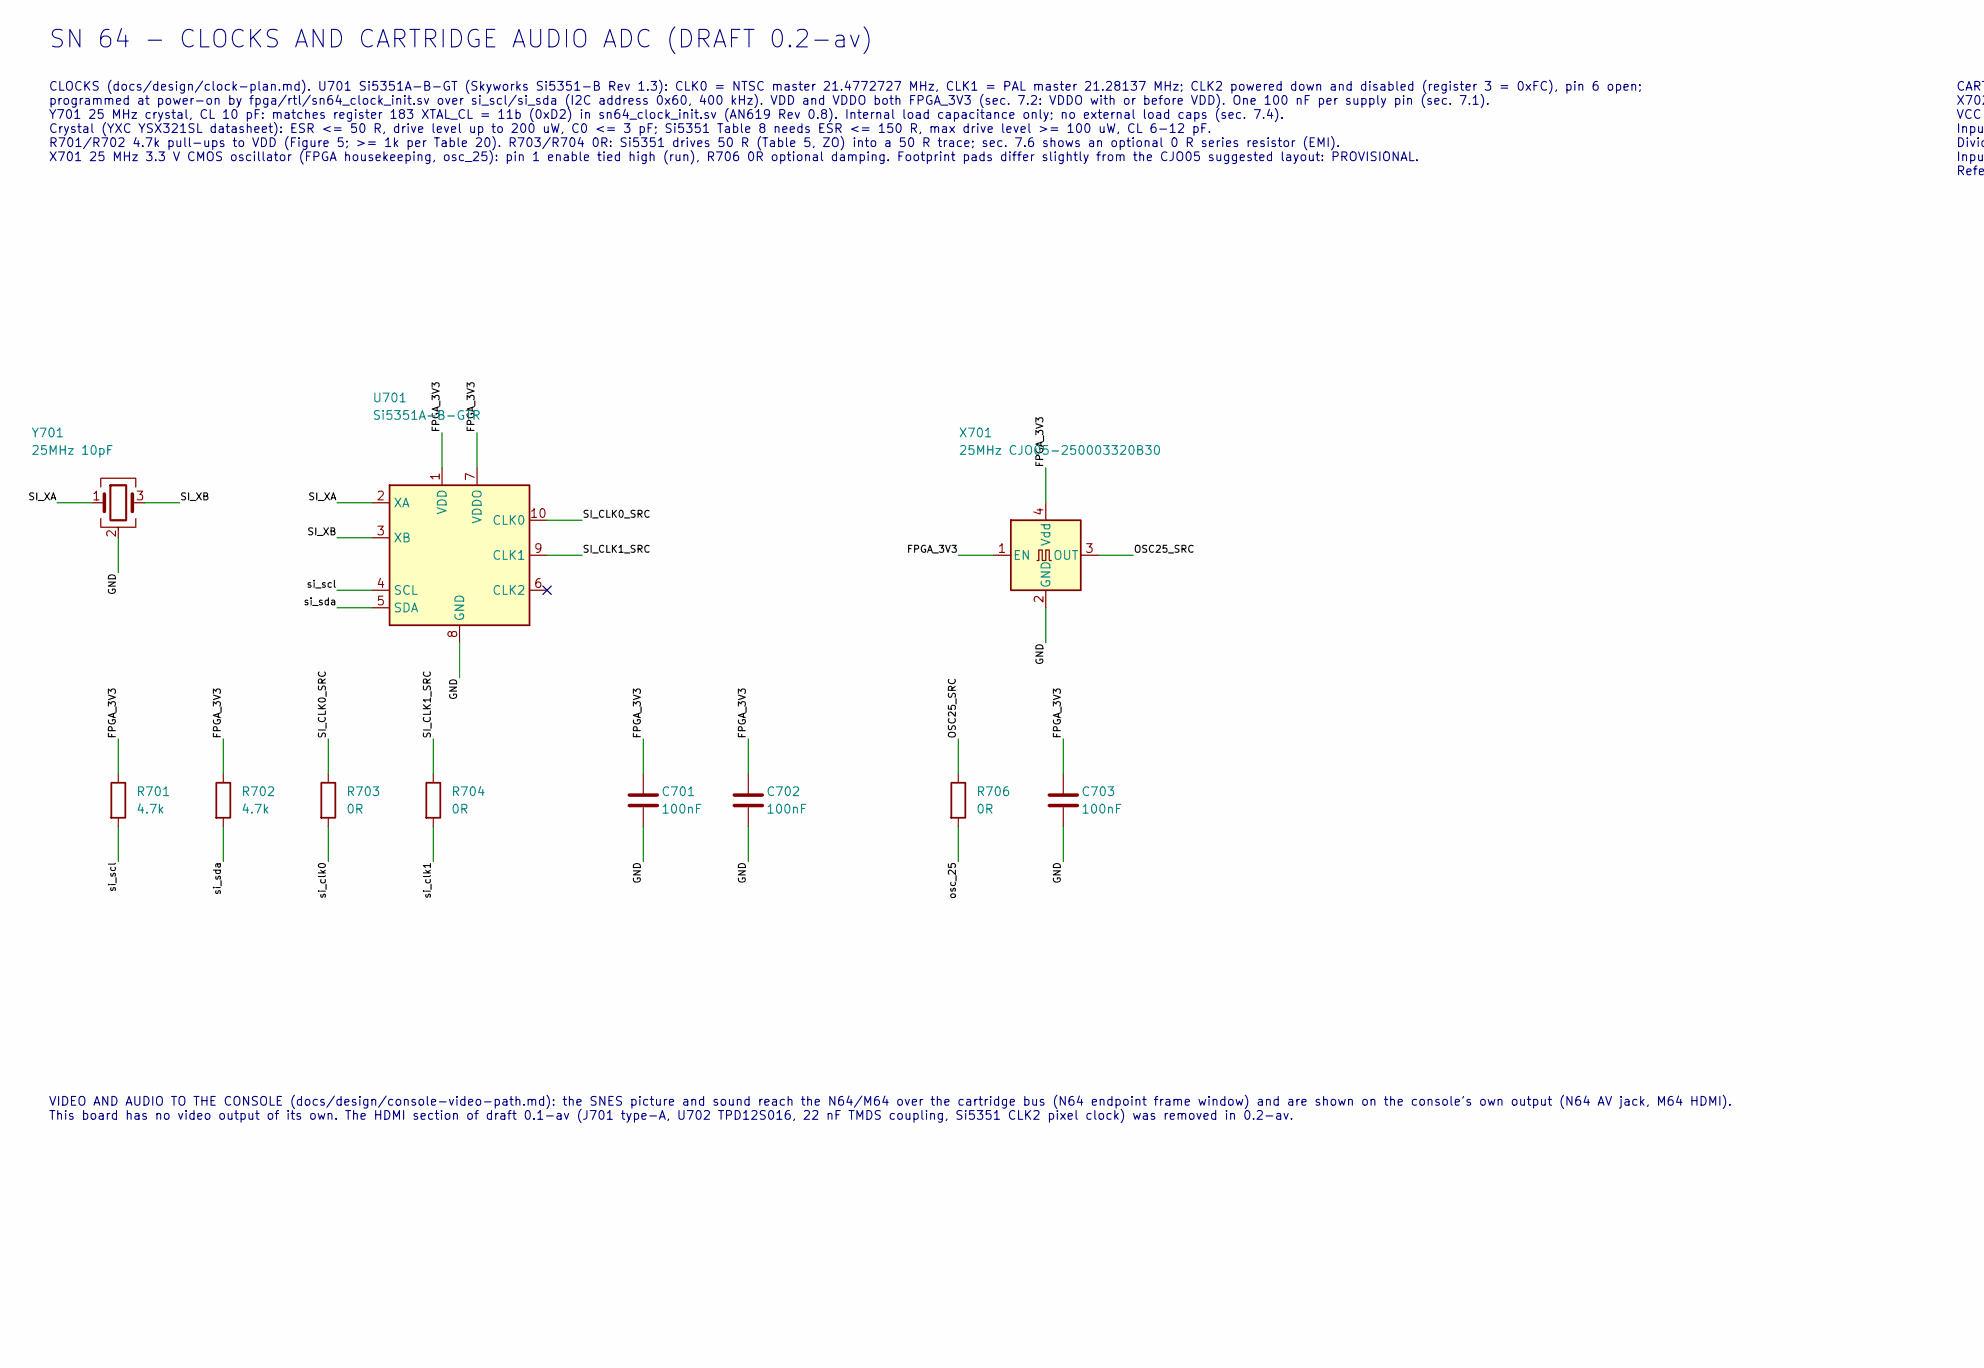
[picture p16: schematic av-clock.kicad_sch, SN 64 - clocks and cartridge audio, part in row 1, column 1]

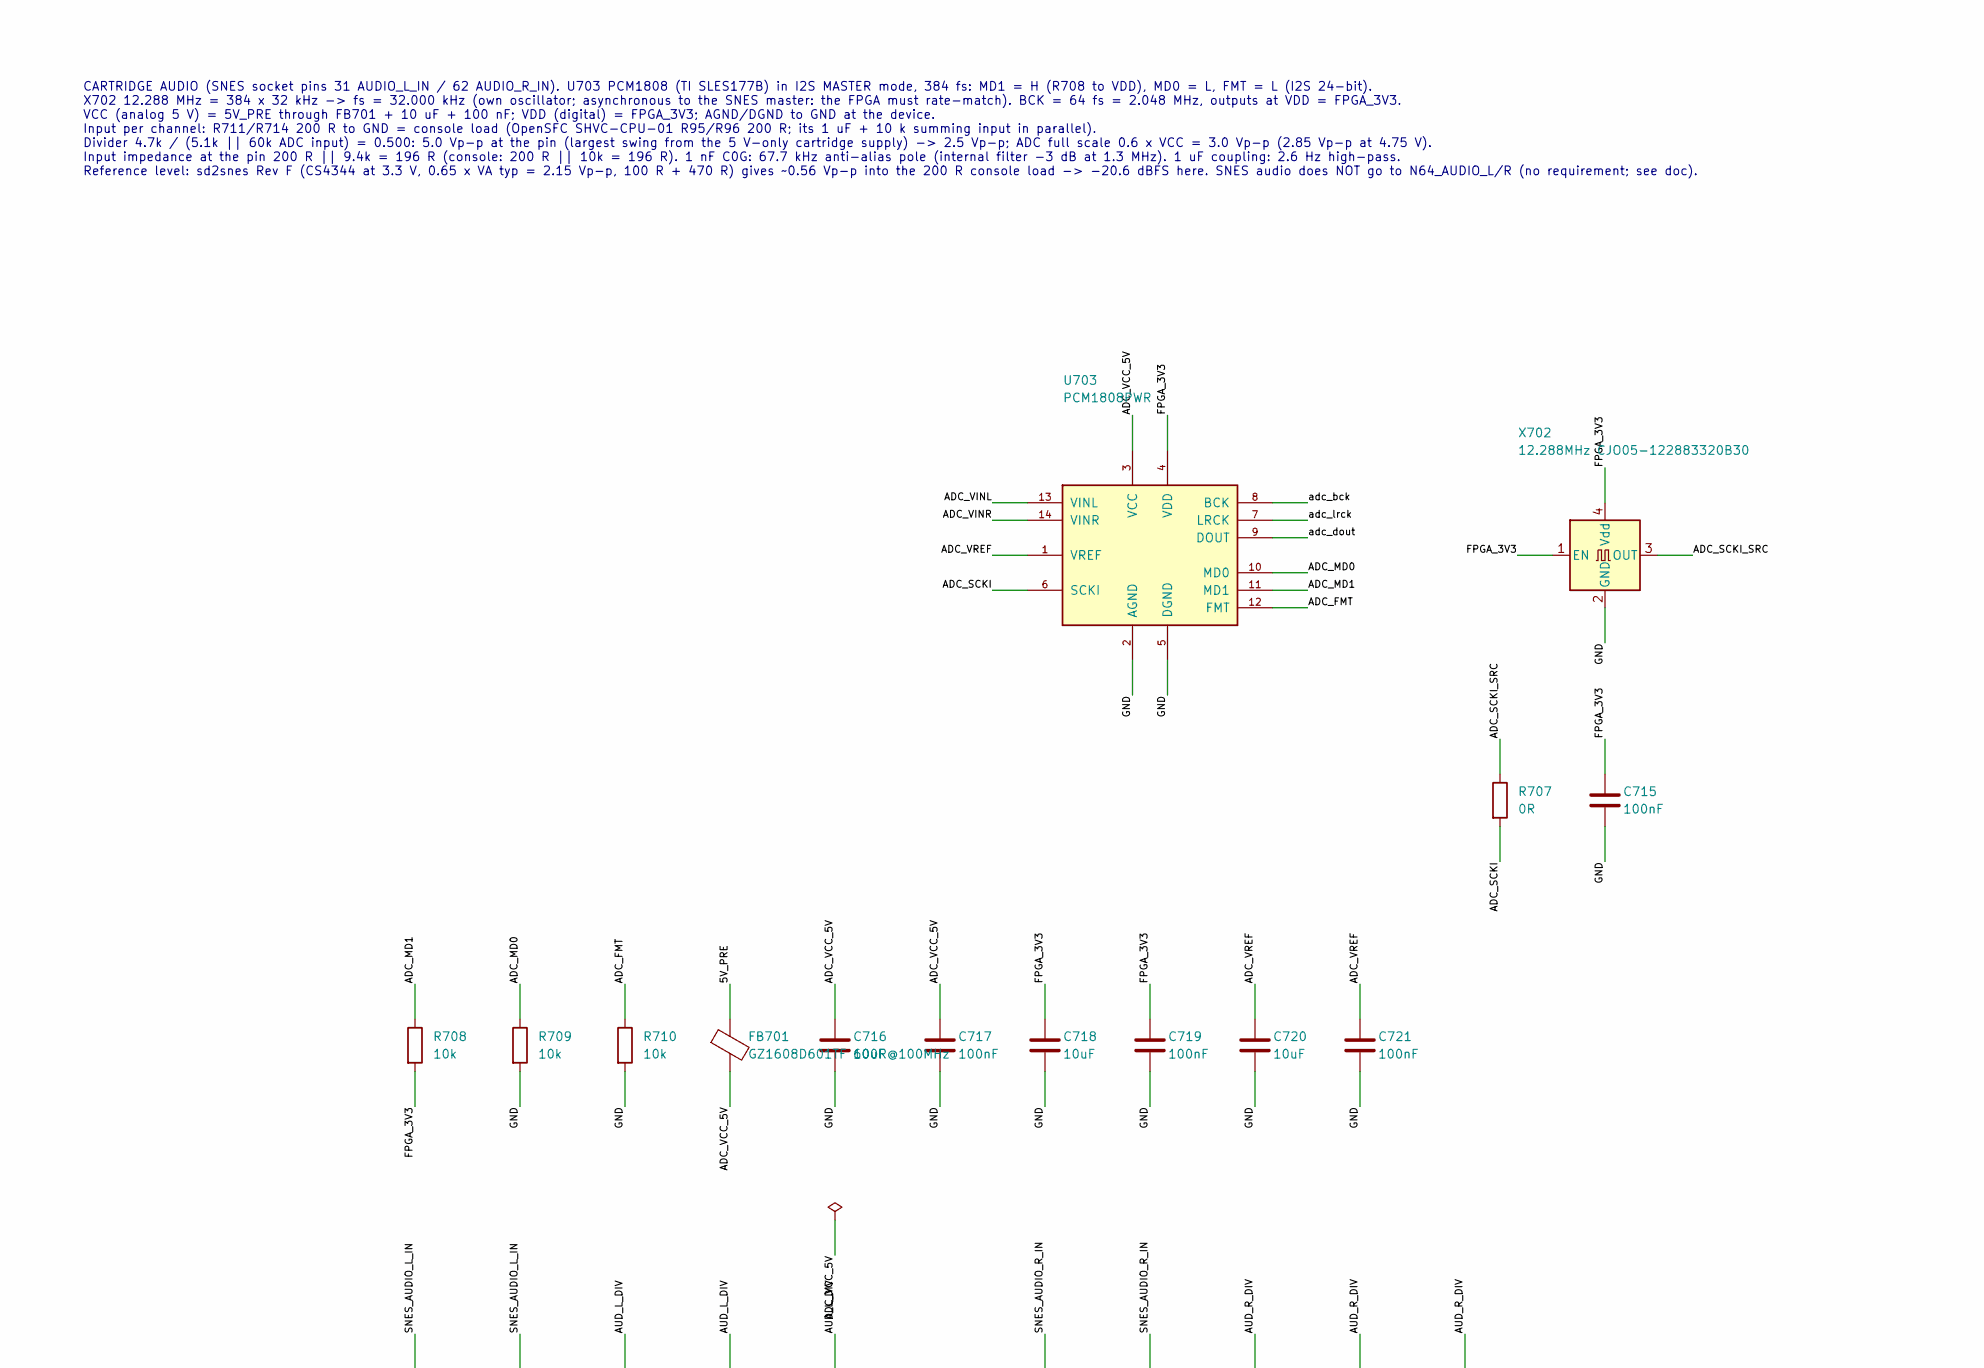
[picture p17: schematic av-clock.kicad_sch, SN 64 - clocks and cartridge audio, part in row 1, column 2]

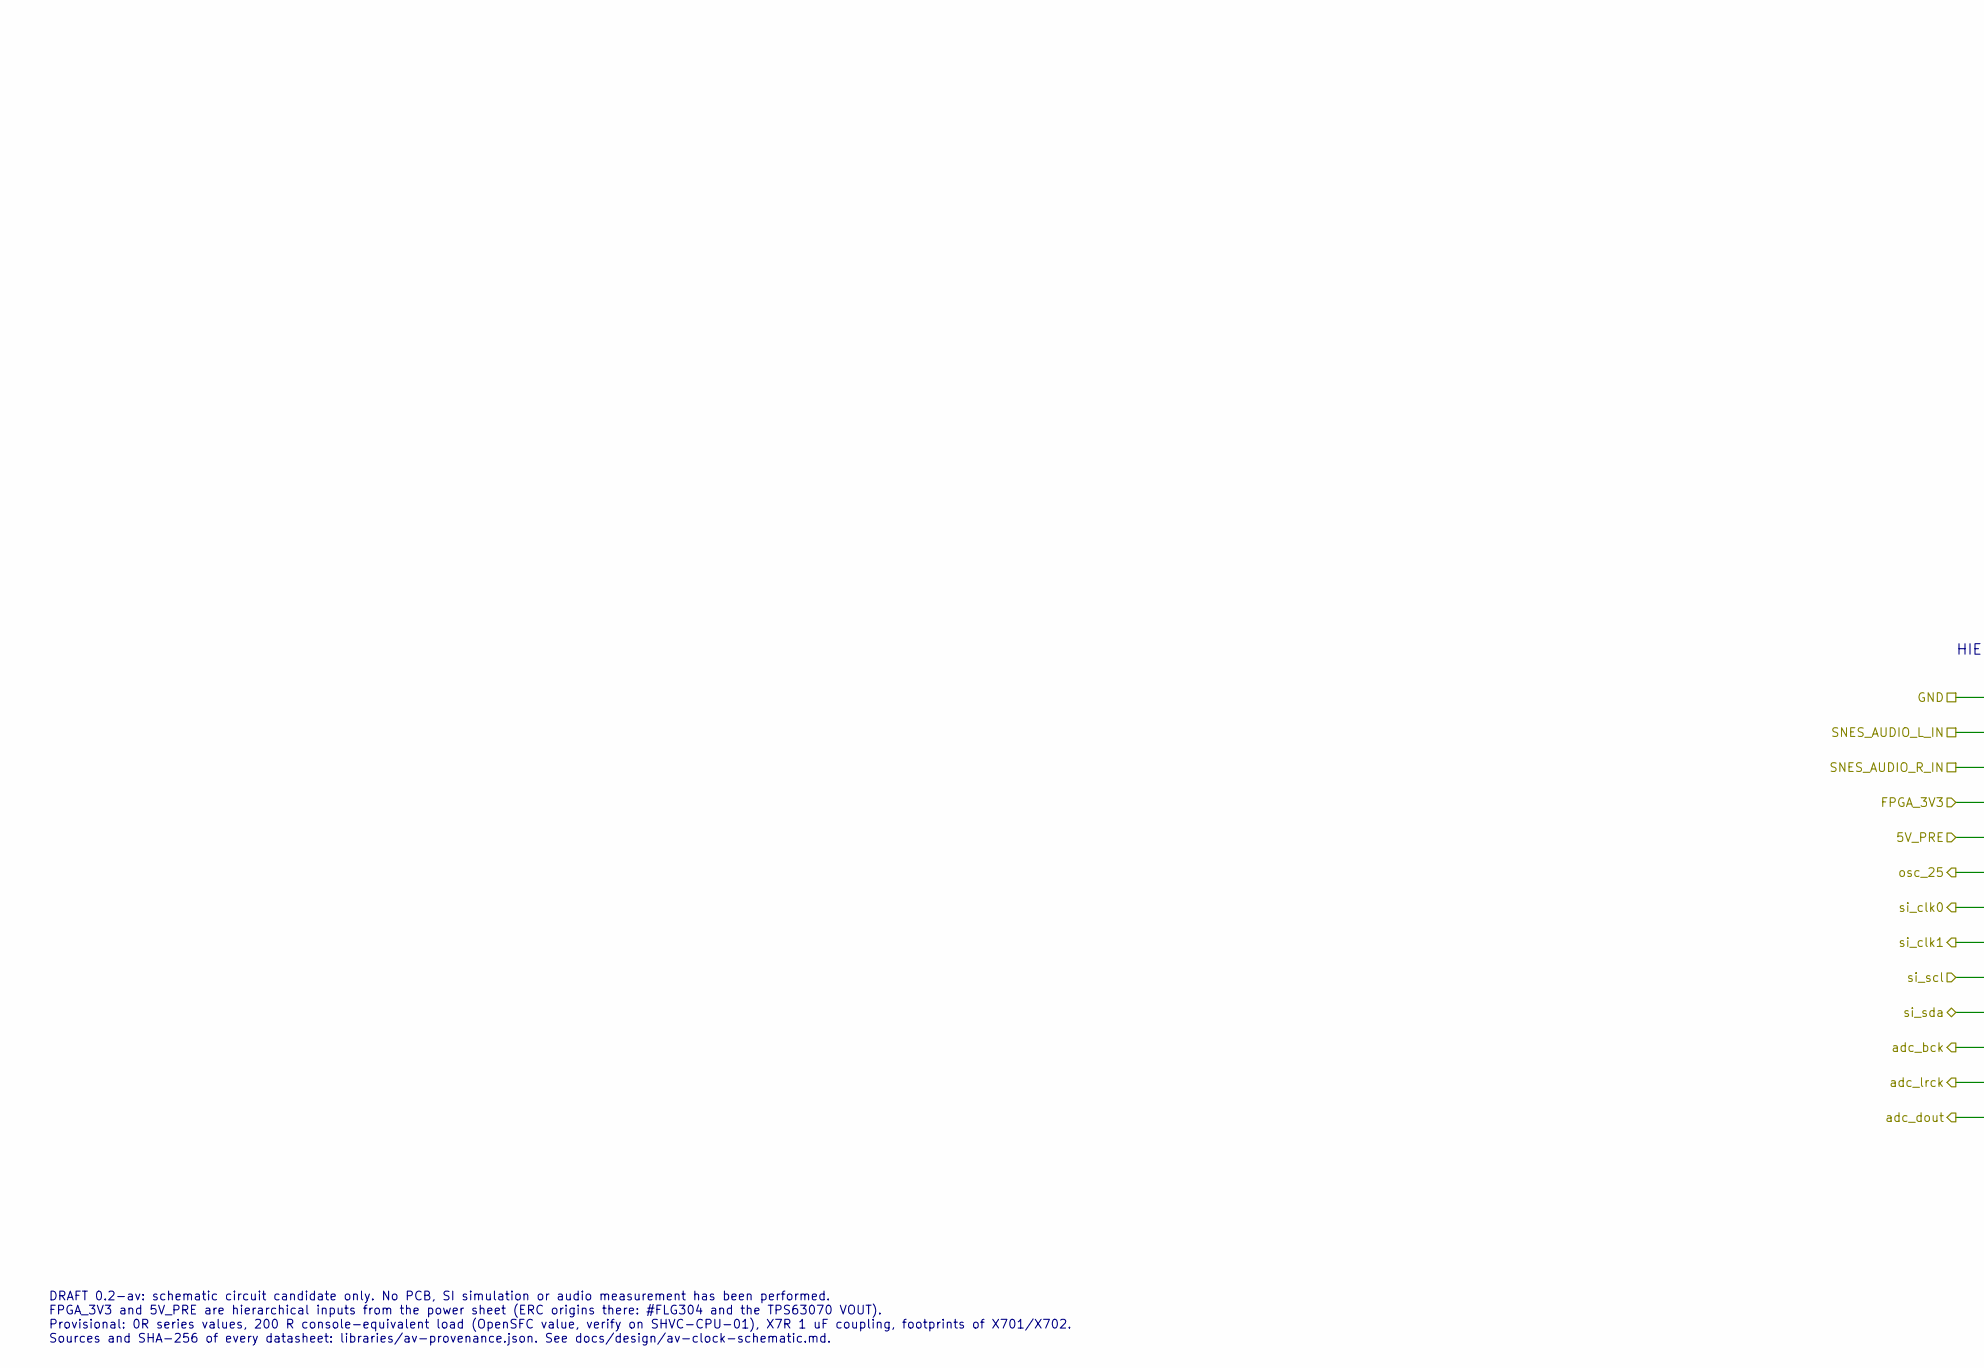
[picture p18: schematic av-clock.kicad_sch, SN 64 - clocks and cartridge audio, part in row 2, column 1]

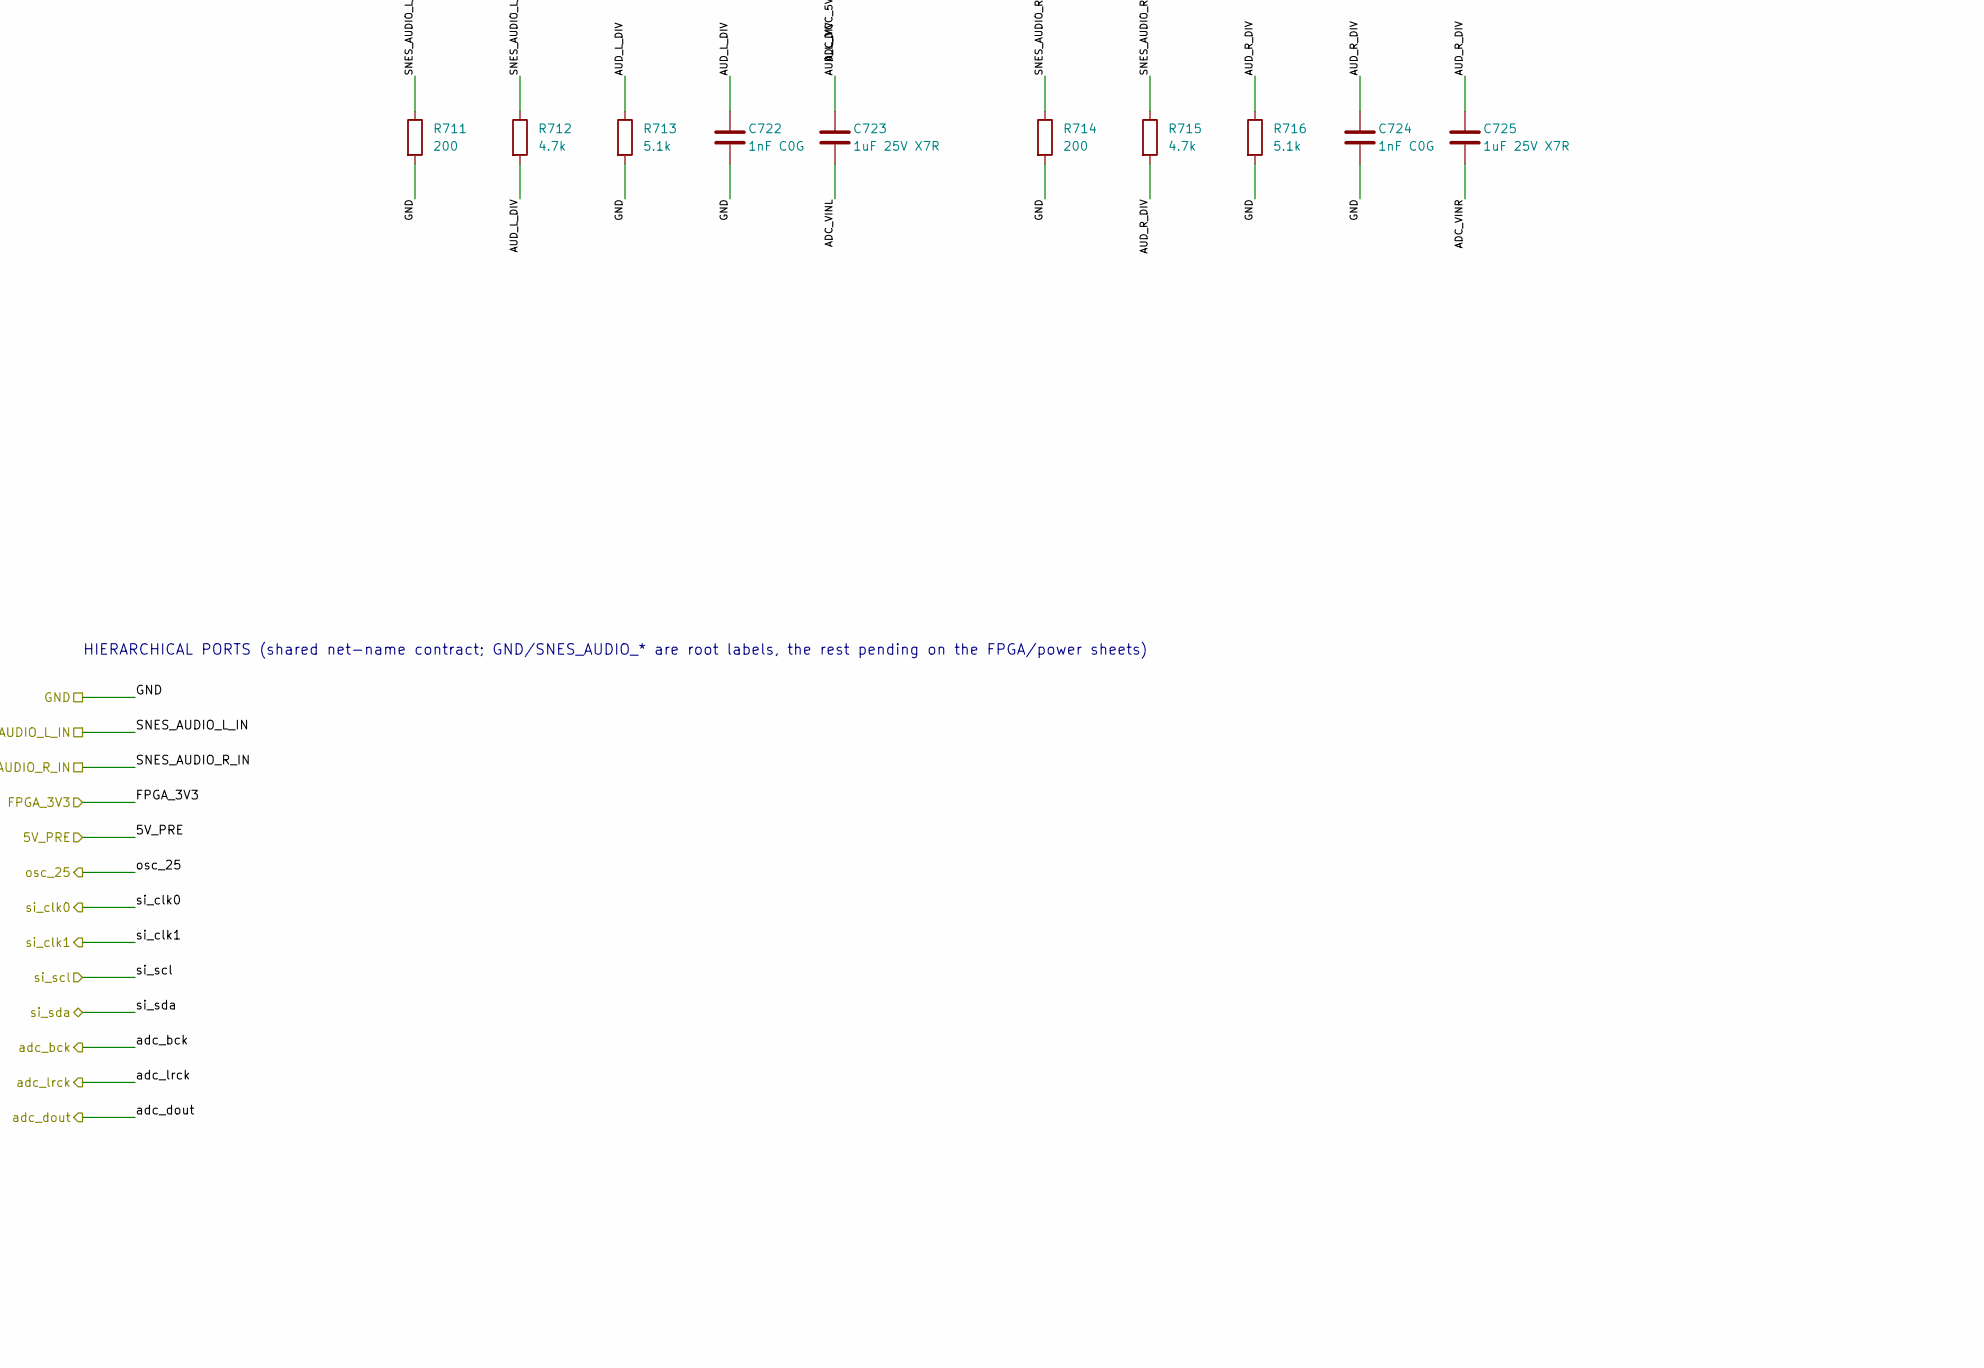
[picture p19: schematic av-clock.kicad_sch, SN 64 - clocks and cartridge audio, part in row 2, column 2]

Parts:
C701, C702, C703, C715, C717, C719, C721: 100nF; C_0603_1608Metric
C716, C718, C720: 10uF; C_0805_2012Metric
C722, C724: 1nF C0G; C_0603_1608Metric
C723, C725: 1uF 25V X7R; C_0805_2012Metric
FB701: GZ1608D601TF 600R@100MHz; L_0603_1608Metric; MPN GZ1608D601TF; LCSC C1002
R701, R702, R712, R715: 4.7k; R_0603_1608Metric
R703, R704, R706, R707: 0R; R_0603_1608Metric
R708, R709, R710: 10k; R_0603_1608Metric
R711, R714: 200; R_0603_1608Metric
R713, R716: 5.1k; R_0603_1608Metric
U701: Si5351A-B-GTR; MSOP-10_3x3mm_P0.5mm; MPN Si5351A-B-GTR; LCSC C504891
U703: PCM1808PWR; TSSOP-14_4.4x5mm_P0.65mm; MPN PCM1808PWR; LCSC C55513
X701: 25MHz CJO05-250003320B30; Oscillator_SMD_Abracon_ASE-4Pin_3.2x2.5mm; MPN CJO05-250003320B30; LCSC C712741
X702: 12.288MHz CJO05-122883320B30; Oscillator_SMD_Abracon_ASE-4Pin_3.2x2.5mm; MPN CJO05-122883320B30; LCSC C712747
Y701: 25MHz 10pF; Crystal_SMD_3225-4Pin_3.2x2.5mm; MPN X322525MMB4SI; LCSC C70582

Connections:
/5V_PRE: FB701.1; also elsewhere on the board
/AV clock and cartridge audio/ADC_FMT: R710.1, U703.12 (FMT)
/AV clock and cartridge audio/ADC_MD0: R709.1, U703.10 (MD0)
/AV clock and cartridge audio/ADC_MD1: R708.1, U703.11 (MD1)
/AV clock and cartridge audio/ADC_SCKI: R707.2, U703.6 (SCKI)
/AV clock and cartridge audio/ADC_SCKI_SRC: R707.1, X702.3 (OUT)
/AV clock and cartridge audio/ADC_VCC_5V: C716.1, C717.1, FB701.2, U703.3 (VCC)
/AV clock and cartridge audio/ADC_VINL: C723.2, U703.13 (VINL)
/AV clock and cartridge audio/ADC_VINR: C725.2, U703.14 (VINR)
/AV clock and cartridge audio/ADC_VREF: C720.1, C721.1, U703.1 (VREF)
/AV clock and cartridge audio/AUD_L_DIV: C722.1, C723.1, R712.2, R713.1
/AV clock and cartridge audio/AUD_R_DIV: C724.1, C725.1, R715.2, R716.1
/AV clock and cartridge audio/OSC25_SRC: R706.1, X701.3 (OUT)
/AV clock and cartridge audio/SI_CLK0_SRC: R703.1, U701.10 (CLK0)
/AV clock and cartridge audio/SI_CLK1_SRC: R704.1, U701.9 (CLK1)
/AV clock and cartridge audio/SI_XA: U701.2 (XA), Y701.1
/AV clock and cartridge audio/SI_XB: U701.3 (XB), Y701.3
/FPGA_3V3: C701.1, C702.1, C703.1, C715.1, C718.1, C719.1, R701.1, R702.1, R708.2, U701.1 (VDD), U701.7 (VDDO), U703.4 (VDD), X701.1 (EN), X701.4 (Vdd), X702.1 (EN), X702.4 (Vdd); also elsewhere on the board
/GND: C701.2, C702.2, C703.2, C715.2, C716.2, C717.2, C718.2, C719.2, C720.2, C721.2, C722.2, C724.2, R709.2, R710.2, R711.2, R713.2, R714.2, R716.2, U701.8 (GND), U703.2 (AGND), U703.5 (DGND), X701.2 (GND), X702.2 (GND), Y701.2 (G), Y701.4 (G); also elsewhere on the board
/SNES_AUDIO_L_IN: R711.1, R712.1; also elsewhere on the board
/SNES_AUDIO_R_IN: R714.1, R715.1; also elsewhere on the board
/adc_bck: U703.8 (BCK); also elsewhere on the board
/adc_dout: U703.9 (DOUT); also elsewhere on the board
/adc_lrck: U703.7 (LRCK); also elsewhere on the board
/osc_25: R706.2; also elsewhere on the board
/si_clk0: R703.2; also elsewhere on the board
/si_clk1: R704.2; also elsewhere on the board
/si_scl: R701.2, U701.4 (SCL); also elsewhere on the board
/si_sda: R702.2, U701.5 (SDA); also elsewhere on the board

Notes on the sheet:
SN 64 - CLOCKS AND CARTRIDGE AUDIO ADC (DRAFT 0.2-av)
CLOCKS (docs/design/clock-plan.md). U701 Si5351A-B-GT (Skyworks Si5351-B Rev 1.3): CLK0 = NTSC master 21.4772727 MHz, CLK1 = PAL master 21.28137 MHz; CLK2 powered down and disabled (register 3 = 0xFC), pin 6 open; programmed at power-on by fpga/rtl/sn64_clock_init.sv over si_scl/si_sda (I2C address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
VIDEO AND AUDIO TO THE CONSOLE (docs/design/console-video-path.md): the SNES picture and sound reach the N64/M64 over the cartridge bus (N64 endpoint frame window) and are shown on the console's own output (N64 AV jack, M64 HDMI). This board has no video output of its own. The HDMI section of draft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
CARTRIDGE AUDIO (SNES socket pins 31 AUDIO_L_IN / 62 AUDIO_R_IN). U703 PCM1808 (TI SLES177B) in I2S MASTER mode, 384 fs: MD1 = H (R708 to VDD), MD0 = L, FMT = L (I2S 24-bit). X702 12.288 MHz = 384 x 32 kHz -> fs = 32.000 kHz (own oscillator; asynchronous to the SNES master: the FPGA must rate-match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
HIERARCHICAL PORTS (shared net-name contract; GND/SNES_AUDIO_* are root labels, the rest pending on the FPGA/power sheets)
DRAFT 0.2-av: schematic circuit candidate only. No PCB, SI simulation or audio measurement has been performed. FPGA_3V3 and 5V_PRE are hierarchical inputs from the power sheet (ERC origins there: #FLG304 and the TPS63070 VOUT). Provisional: 0R series values, 200 R console-equivalent load (OpenSFC v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

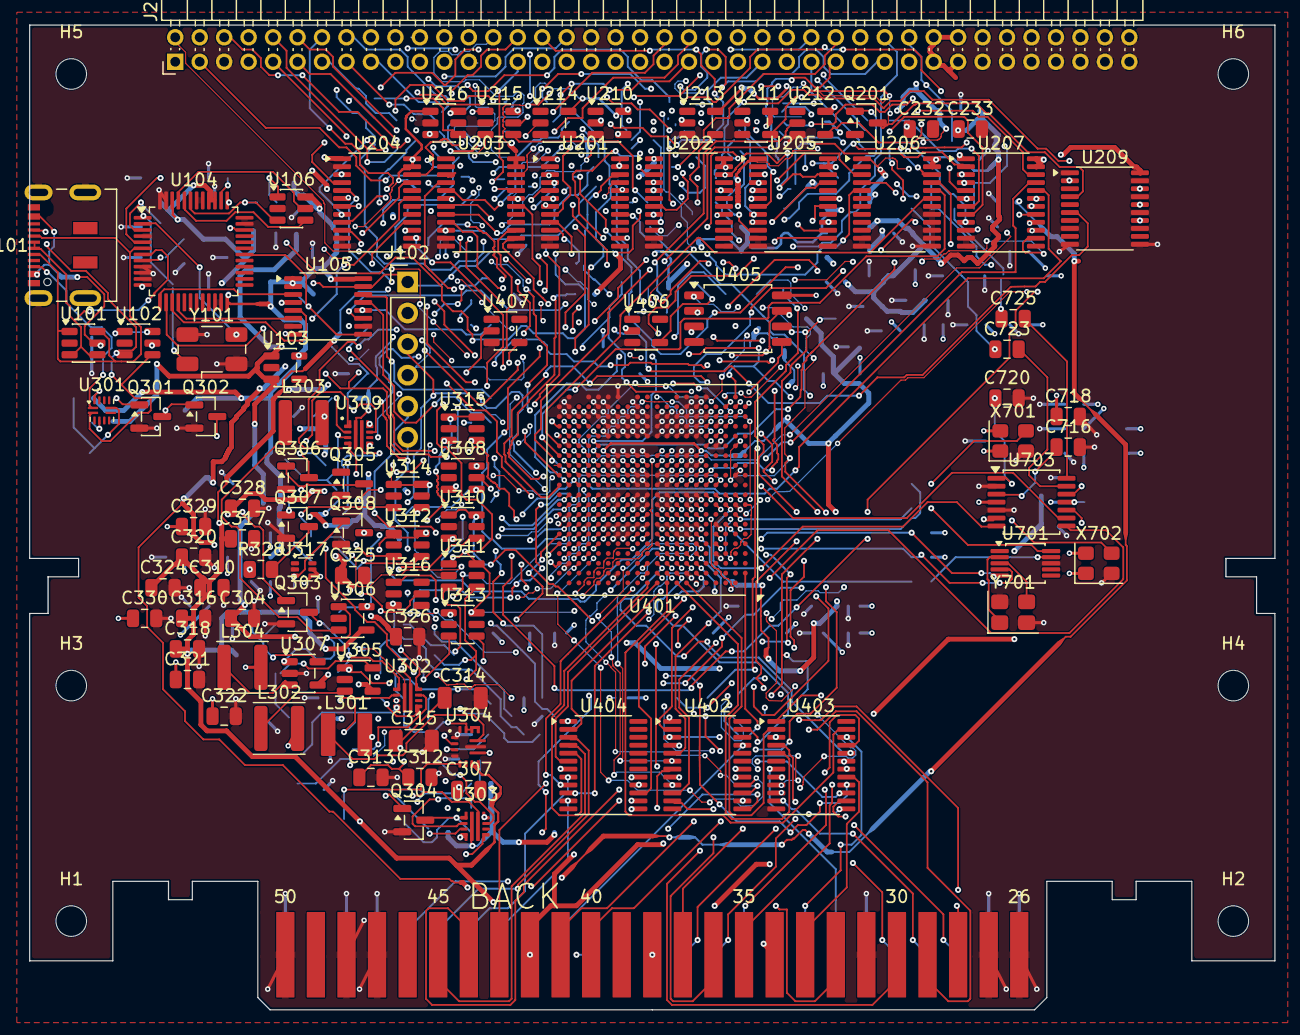
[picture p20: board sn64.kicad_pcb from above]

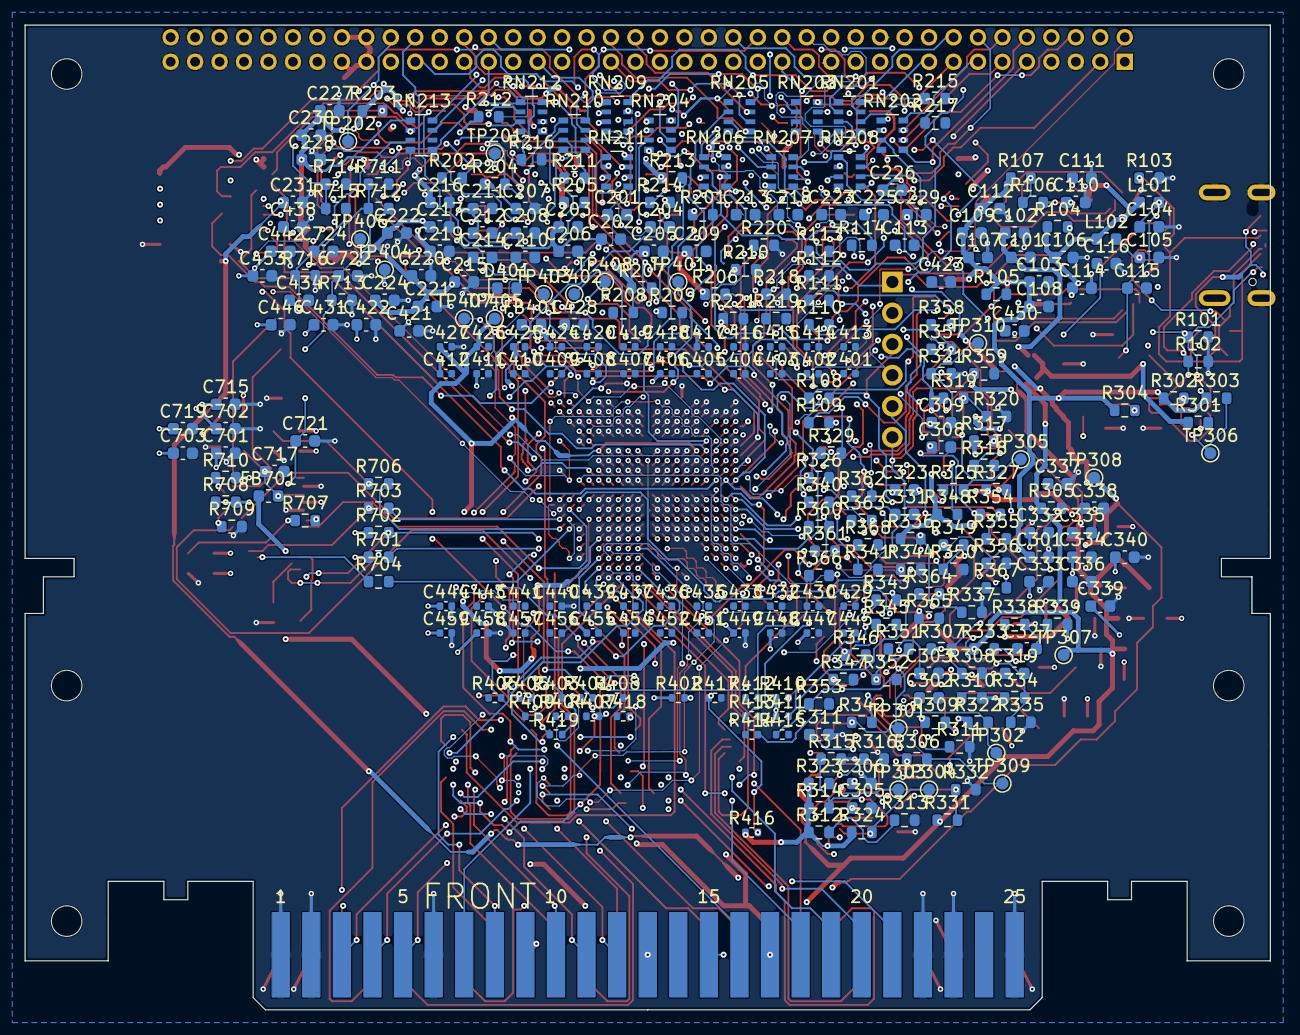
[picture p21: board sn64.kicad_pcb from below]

Board: 6 copper layers, 101.8 x 80.5 mm, 410 parts (309 on the bottom side), 378 nets.

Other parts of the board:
H1, H2, H3, H4, H5, H6: MountingHole_2.5mm

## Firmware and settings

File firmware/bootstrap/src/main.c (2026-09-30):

// SPDX-License-Identifier: GPL-3.0-or-later
// SN64 bootstrap: the menu program the N64/M64 boots from the SN64 cartridge
// ROM window. It forwards the N64 controllers to the SNES core through the
// SN64 mailbox and lets the user request (or drop) SNES cartridge power.
//
// Built with libdragon (Unlicense). Not yet run on hardware or an emulator;
// see docs/design/n64-bootstrap.md for what has been verified.
#include <stdarg.h>
#include <stdbool.h>
#include <stdint.h>
#include <stdio.h>

#include <libdragon.h>

#include "sn64_mailbox.h"
#include "sn64_mapping.h"

// ---- console video path: the SNES picture and sound through the console's own output
#define PI_BSD_DOM2_LAT_REG ((volatile uint32_t *)0xA4600024)
#define PI_BSD_DOM2_PWD_REG ((volatile uint32_t *)0xA4600028)
#define PI_BSD_DOM2_PGS_REG ((volatile uint32_t *)0xA460002C)
#define PI_BSD_DOM2_RLS_REG ((volatile uint32_t *)0xA4600030)
#define FRAME_CHUNK_LINES   56                 // 4 DMAs per frame, each after the SNES has finished those lines
#define GAME_TOP_LINE       8                  // the 224 SNES lines sit centred in the 240-line screen
static bool     game_display;                  // display is in the 256x240 game mode
static int      game_frames_shown;
static uint16_t aud_rptr;                      // next audio pair to fetch from the ring
static short    aud_tmp[2 * SN64_AUDIO_PAIRS] __attribute__((aligned(16)));

static void pi_dom2_fast(void)
{
    *PI_BSD_DOM2_LAT_REG = SN64_PI_DOM2_LAT;
    *PI_BSD_DOM2_PWD_REG = SN64_PI_DOM2_PWD;
    *PI_BSD_DOM2_PGS_REG = SN64_PI_DOM2_PGS;
    *PI_BSD_DOM2_RLS_REG = SN64_PI_DOM2_RLS;
}

static void display_mode(bool game)
{
    if (game == game_display) return;
    display_close();
    if (game) display_init(RESOLUTION_256x240, DEPTH_16_BPP, 2, GAMMA_NONE, FILTERS_RESAMPLE);
    else      display_init(RESOLUTION_320x240, DEPTH_16_BPP, 2, GAMMA_NONE, FILTERS_RESAMPLE);
    game_display = game;
}

// Copy the SNES frame into the screen buffer, chunk by chunk, each chunk only after the
// SNES has finished writing those lines (FRAME_STATUS.lines_done) or has already moved on
// to the next frame; the reader therefore stays behind the writer and never tears a line.
static void game_frame(surface_t *d)
{
    uint8_t *dst = (uint8_t *)d->buffer;
    uint32_t fs = io_read(SN64_MBOX_BASE + SN64_REG_REGION_SOURCE) & 0xFFFFu;
    uint32_t f0 = SN64_FRAME_STATUS_COUNT(fs);
    for (unsigned L = 0; L < SN64_FRAME_LINES; L += FRAME_CHUNK_LINES) {
        unsigned last = L + FRAME_CHUNK_LINES - 1;
        for (;;) {
            fs = io_read(SN64_MBOX_BASE + SN64_REG_REGION_SOURCE) & 0xFFFFu;
            uint32_t ld = SN64_FRAME_STATUS_LINES(fs);
            if (SN64_FRAME_STATUS_COUNT(fs) != f0) break;          // writer is already on the next frame
            if (ld != 0xFFu && ld >= last) break;                   // these lines are done
        }
        dma_read_raw_async(dst + (GAME_TOP_LINE + L) * SN64_FRAME_LINE_BYTES,
                           SN64_FRAME_BASE + L * SN64_FRAME_LINE_BYTES,
                           FRAME_CHUNK_LINES * SN64_FRAME_LINE_BYTES);
        dma_wait();
    }
}

// Move whatever the SNES has produced since last time from the audio ring to the N64's
// audio output. The ring is 1024 pairs (32 ms); the N64 buffers are filled whenever they
// have room, padding with silence if the ring runs dry.
static void game_audio(void)
{
    uint32_t aw = io_read(SN64_MBOX_BASE + SN64_REG_AUDIO_MODE) >> 16;
    while (audio_can_write()) {
        short *buf = audio_write_begin();
        int n = audio_get_buffer_length();                          // stereo pairs per N64 buffer
        int avail = (int)((aw - aud_rptr) & (SN64_AUDIO_PAIRS - 1));
        int take = avail < n ? avail : n;
        int done = 0;
        while (done < take) {
            int run = take - done;
            if (aud_rptr + run > SN64_AUDIO_PAIRS) run = SN64_AUDIO_PAIRS - aud_rptr;   // ring wrap
            data_cache_hit_writeback_invalidate(aud_tmp, run * 4);
            dma_read_raw_async(aud_tmp, SN64_FRAME_BASE + SN64_AUDIO_OFFSET + aud_rptr * 4u, run * 4u);
            dma_wait();
            data_cache_hit_invalidate(aud_tmp, run * 4);
            for (int i = 0; i < run * 2; i++) buf[(done * 2) + i] = aud_tmp[i];
            done += run;
            aud_rptr = (aud_rptr + run) & (SN64_AUDIO_PAIRS - 1);
        }
        for (int i = take * 2; i < n * 2; i++) buf[i] = 0;
        audio_write_end();
    }
}

#ifndef SN64_BOOTSTRAP_VERSION
#define SN64_BOOTSTRAP_VERSION "0.1.0"
#endif

// Held on controller 1 for ~1 s while a cartridge runs: return to the menu.
#define MENU_HOTKEY        (N64_BTN_Z | N64_BTN_L | N64_BTN_R)
#define MENU_HOTKEY_FRAMES 60

typedef enum { MODE_MENU, MODE_RUN } run_mode_t;
typedef enum { SCREEN_MAIN, SCREEN_MAPPING, SCREEN_STATUS } screen_t;
typedef enum { ITEM_START, ITEM_MAPPING, ITEM_STATUS, ITEM_POWER_DOWN, ITEM_COUNT } item_t;

static const char *const item_names[ITEM_COUNT] = {
    "Start SNES cartridge",
    "Controller mapping",
    "Status / diagnostics",
    "Power down cartridge",
};

static const char *const seq_state_names[16] = {
    "OFF", "RESET", "5V RAMP", "IFACE RAIL", "RUNNING", "SHUTDOWN", "FAULT",
    "?7", "?8", "?9", "?10", "?11", "?12", "?13", "?14", "?15",
};

// Mailbox state as last read from the hardware.
typedef struct {
    bool     present;
    uint16_t magic, version, status, seq;
    uint16_t rb_joy1, rb_joy2, rb_stick, rb_control;
    uint16_t region_info, region_source;
} mailbox_t;

static mailbox_t  mbox;
static sn64_map_t map;
static bool       run_request;            // bootstrap-owned; default off after every reset
static run_mode_t mode = MODE_MENU;
static screen_t   screen = SCREEN_MAIN;
static int        cursor;
static int        hotkey_frames;
static const char *message = "";

static uint16_t n64_word(joypad_buttons_t b)
{
    uint16_t w = 0;
    if (b.a)       w |= N64_BTN_A;
    if (b.b)       w |= N64_BTN_B;
    if (b.z)       w |= N64_BTN_Z;
    if (b.start)   w |= N64_BTN_START;
    if (b.d_up)    w |= N64_BTN_D_UP;
    if (b.d_down)  w |= N64_BTN_D_DOWN;
    if (b.d_left)  w |= N64_BTN_D_LEFT;
    if (b.d_right) w |= N64_BTN_D_RIGHT;
    if (b.l)       w |= N64_BTN_L;
    if (b.r)       w |= N64_BTN_R;
    if (b.c_up)    w |= N64_BTN_C_UP;
    if (b.c_down)  w |= N64_BTN_C_DOWN;
    if (b.c_left)  w |= N64_BTN_C_LEFT;
    if (b.c_right) w |= N64_BTN_C_RIGHT;
    return w;
}

// ---- mailbox access (32-bit PI accesses, register pairs; see sn64_mailbox.h)

static void mailbox_read(void)
{
    uint32_t mv = io_read(SN64_MBOX_BASE + SN64_REG_MAGIC_VERSION);
    mbox.magic   = (uint16_t)(mv >> 16);
    mbox.version = (uint16_t)mv;
    mbox.present = (mbox.magic == SN64_MAGIC);
    if (!mbox.present)
        return;
    uint32_t ss = io_read(SN64_MBOX_BASE + SN64_REG_STATUS_SEQ);
    uint32_t jj = io_read(SN64_MBOX_BASE + SN64_REG_JOY1_JOY2);
    uint32_t sc = io_read(SN64_MBOX_BASE + SN64_REG_STICK_CONTROL);
    uint32_t cr = io_read(SN64_MBOX_BASE + SN64_REG_COMMIT_REGION);   // {COMMIT reads 0, REGION_INFO}
    uint32_t rs = io_read(SN64_MBOX_BASE + SN64_REG_REGION_SOURCE);   // {REGION_SOURCE, reserved}
    mbox.status     = (uint16_t)(ss >> 16);
    mbox.seq        = (uint16_t)ss;
    mbox.rb_joy1    = (uint16_t)(jj >> 16);
    mbox.rb_joy2    = (uint16_t)jj;
    mbox.rb_stick   = (uint16_t)(sc >> 16);
    mbox.rb_control = (uint16_t)sc;
    mbox.region_info   = (uint16_t)cr;
    mbox.region_source = (uint16_t)(rs >> 16);
}

// One complete controller update per frame, then COMMIT (SEQ increments).
// Never writes unless MAGIC was seen: unknown hardware is left alone.
static void mailbox_write_frame(uint16_t joy1, uint16_t joy2, uint16_t stick, bool run)
{
    if (!mbox.present)
        return;
    io_write(SN64_MBOX_BASE + SN64_REG_JOY1_JOY2, ((uint32_t)joy1 << 16) | joy2);
    io_write(SN64_MBOX_BASE + SN64_REG_STICK_CONTROL,
             ((uint32_t)stick << 16) | (run ? SN64_CONTROL_RUN_REQUEST : 0u));
    io_write(SN64_MBOX_BASE + SN64_REG_COMMIT, 0x00010000u);   // COMMIT at 0x18; 0x1A ignored
}

// ---- menu logic

static void menu_select(item_t item)
{
    switch (item) {
    case ITEM_START:
        if (!mbox.present) {
            message = "SN64 hardware not detected";
        } else if (mbox.status & SN64_STATUS_FAULT_LATCHED) {
            message = "Power fault latched: not starting";
        } else {
            run_request = true;
            mode = MODE_RUN;
            message = "Running. Hold Z+L+R 1 s for menu";
        }
        break;
    case ITEM_MAPPING:
        screen = SCREEN_MAPPING;
        break;
    case ITEM_STATUS:
        screen = SCREEN_STATUS;
        break;
    case ITEM_POWER_DOWN:
        run_request = false;
        message = "Cartridge power request cleared";
        break;
    default:
        break;
    }
}

static void menu_input(joypad_buttons_t pressed)
{
    if (screen != SCREEN_MAIN) {
        if (pressed.b || pressed.start) screen = SCREEN_MAIN;
        return;
    }
    if (pressed.d_up)   cursor = (cursor + ITEM_COUNT - 1) % ITEM_COUNT;
    if (pressed.d_down) cursor = (cursor + 1) % ITEM_COUNT;
    if (pressed.a)      menu_select((item_t)cursor);
}

// ---- region telemetry text

// "PAL via key CIC", "NTSC via ROM header", ... or "not decided yet".
static void region_text(char *buf, size_t n)
{
    if (!(mbox.region_source & SN64_RSRC_DECIDED)) {
        snprintf(buf, n, "not decided yet");
        return;
    }
    snprintf(buf, n, "%s via %s%s", (mbox.region_source & SN64_RSRC_PAL) ? "PAL" : "NTSC",
             sn64_region_source_names[mbox.region_source & SN64_RSRC_SOURCE_MASK],
             (mbox.region_source & SN64_RSRC_TIMEOUT) ? " (timeout)" : "");
}

// ROM header probe: "valid, ctry 02" or "invalid, rej 0110" (+ " aborted").
static void header_text(char *buf, size_t n)
{
    uint16_t ri = mbox.region_info;
    if (!(ri & SN64_RINFO_DONE)) {
        snprintf(buf, n, "not probed");
        return;
    }
    unsigned rej = (ri & SN64_RINFO_REJECT_MASK) >> SN64_RINFO_REJECT_SHIFT;
    snprintf(buf, n, "%s ctry %02X rej %u%u%u%u%s", (ri & SN64_RINFO_VALID) ? "ok" : "bad",
             ri & SN64_RINFO_COUNTRY_MASK, (rej >> 3) & 1, (rej >> 2) & 1, (rej >> 1) & 1, rej & 1,
             (ri & SN64_RINFO_ABORTED) ? " abort" : "");
}

// ---- drawing (8x8 font, 320x240 => 40 columns)

static uint32_t col_text, col_dim, col_hi, col_warn, col_bg;

static void line(surface_t *d, int row, uint32_t colour, const char *fmt, ...)
    __attribute__((format(printf, 4, 5)));
static void line(surface_t *d, int row, uint32_t colour, const char *fmt, ...)
{
    char buf[48];
    va_list ap;
    va_start(ap, fmt);
    vsnprintf(buf, sizeof(buf), fmt, ap);
    va_end(ap);
    graphics_set_color(colour, 0);
    graphics_draw_text(d, 16, 12 + row * 10, buf);
}

static void draw_header(surface_t *d)
{
    line(d, 0, col_hi, "SN64 bootstrap v%s", SN64_BOOTSTRAP_VERSION);
    if (mbox.present)
        line(d, 1, col_text, "SN64 build %u.%u (0x%04X)",
             mbox.version >> 8, mbox.version & 0xFF, mbox.version);
    else
        line(d, 1, col_warn, "SN64 not detected (MAGIC %04X)", mbox.magic);
}

static void draw_main(surface_t *d)
{
    draw_header(d);
    if (mbox.present) {
        line(d, 2, col_text, "Status 0x%04X  seq %u  %s", mbox.status, mbox.seq,
             seq_state_names[(mbox.status & SN64_STATUS_SEQ_STATE_MASK) >> SN64_STATUS_SEQ_STATE_SHIFT]);
        if (mbox.status & SN64_STATUS_FAULT_LATCHED)
            line(d, 3, col_warn, "POWER FAULT LATCHED");
    }
    line(d, 4, col_text, "Cartridge: %s%s", run_request ? "run requested" : "off",
         (mbox.status & SN64_STATUS_BUS_PERMIT) ? ", permitted" : "");
    if (mbox.present) {
        char rt[40];
        region_text(rt, sizeof(rt));
        line(d, 5, col_text, "Region: %s", rt);
    }
    for (int i = 0; i < ITEM_COUNT; i++)
        line(d, 6 + i, i == cursor ? col_hi : col_text, "%c %s", i == cursor ? '>' : ' ', item_names[i]);
    line(d, 12, col_warn, "%s", message);
    line(d, 20, col_dim, "Up/Down select  A choose  B back");
}

static void draw_mapping(surface_t *d, uint16_t n1, uint16_t s1)
{
    char name[40];
    line(d, 0, col_hi, "Controller mapping (default)");
    line(d, 1, col_dim, "N64 button   -> SNES");
    for (int i = 0; i < SN64_MAP_ENTRIES; i++)
        line(d, 2 + i, col_text, "%-12s -> %s", map.entry[i].n64_name,
             sn64_snes_mask_name(map.entry[i].snes, name, sizeof(name)));
    line(d, 16, col_text, "Stick |x|,|y| >= %d -> D-pad", map.stick_threshold);
    line(d, 17, col_dim, "Up+Down / Left+Right cancel");
    line(d, 19, col_hi, "Live P1: N64 %04X -> SNES %04X", n1, s1);
    line(d, 20, col_text, "%s", sn64_snes_mask_name(s1, name, sizeof(name)));
    line(d, 22, col_dim, "B: back");
}

static void draw_status(surface_t *d)
{
    draw_header(d);
    if (!mbox.present) {
        line(d, 3, col_warn, "No mailbox at 0x%08lX", (unsigned long)SN64_MBOX_BASE);
        line(d, 22, col_dim, "B: back");
        return;
    }
    line(d, 2, col_text, "STATUS 0x%04X", mbox.status);
    for (unsigned i = 0; i < SN64_STATUS_BIT_COUNT; i++)
        line(d, 3 + (int)i, (mbox.status & sn64_status_bits[i].mask) ? col_hi : col_dim, "[%c] %s",
             (mbox.status & sn64_status_bits[i].mask) ? 'x' : ' ', sn64_status_bits[i].name);
    // Rows 3..14 hold the 12 STATUS bits; the rest starts below them.
    char rt[40], ht[40];
    region_text(rt, sizeof(rt));
    header_text(ht, sizeof(ht));
    line(d, 15, col_text, "Sequencer: %s  SEQ %u",
         seq_state_names[(mbox.status & SN64_STATUS_SEQ_STATE_MASK) >> SN64_STATUS_SEQ_STATE_SHIFT], mbox.seq);
    line(d, 16, col_text, "Region: %s", rt);
    line(d, 17, col_text, "Header: %s", ht);
    line(d, 18, col_dim, "RINFO %04X RSRC %04X", mbox.region_info, mbox.region_source);
    line(d, 19, col_text, "JOY1 %04X JOY2 %04X", mbox.rb_joy1, mbox.rb_joy2);
    line(d, 20, col_text, "STICK %04X CONTROL %04X", mbox.rb_stick, mbox.rb_control);
    line(d, 22, col_dim, "B: back");
}

int main(void)
{
    display_init(RESOLUTION_320x240, DEPTH_16_BPP, 2, GAMMA_NONE, FILTERS_RESAMPLE);
    game_display = false;
    audio_init(32000, 4);
    pi_dom2_fast();
    joypad_init();
    sn64_map_default(&map);

    col_bg   = graphics_make_color(0x10, 0x18, 0x30, 0xFF);
    col_text = graphics_make_color(0xE0, 0xE0, 0xE0, 0xFF);
    col_dim  = graphics_make_color(0x80, 0x88, 0x98, 0xFF);
    col_hi   = graphics_make_color(0xFF, 0xD8, 0x40, 0xFF);
    col_warn = graphics_make_color(0xFF, 0x60, 0x50, 0xFF);

    // Default-off: explicitly clear any stale request after every boot.
    run_request = false;
    mailbox_read();
    mailbox_write_frame(0, 0, 0, false);

    for (;;) {
        joypad_poll();
        joypad_inputs_t  in1 = joypad_get_inputs(JOYPAD_PORT_1);
        joypad_inputs_t  in2 = joypad_get_inputs(JOYPAD_PORT_2);
        joypad_buttons_t pressed = joypad_get_buttons_pressed(JOYPAD_PORT_1);

        uint16_t n1 = n64_word(in1.btn);
        uint16_t n2 = n64_word(in2.btn);
        uint16_t s1 = sn64_map_buttons(&map, n1, in1.stick_x, in1.stick_y);
        uint16_t s2 = sn64_map_buttons(&map, n2, in2.stick_x, in2.stick_y);
        uint16_t stick = sn64_pack_stick(in1.stick_x, in1.stick_y);

        if (mode == MODE_RUN) {
            if ((n1 & MENU_HOTKEY) == MENU_HOTKEY) {
                if (++hotkey_frames >= MENU_HOTKEY_FRAMES) {
                    mode = MODE_MENU;
                    screen = SCREEN_MAIN;
                    hotkey_frames = 0;
                    message = "Menu (cartridge still running)";
                }
            } else {
                hotkey_frames = 0;
            }
            if (!run_request) mode = MODE_MENU;
        } else {
            menu_input(pressed);
        }

        // While the menu owns controller 1, the SNES sees a neutral pad.
        if (mode == MODE_MENU) {
            display_mode(false);
            game_frames_shown = 0;
            uint16_t live1 = s1;
            s1 = 0; s2 = 0; stick = 0;
            mailbox_write_frame(s1, s2, stick, run_request);
            mailbox_read();
            surface_t *d = display_get();
            graphics_fill_screen(d, col_bg);
            if (screen == SCREEN_MAPPING)     draw_mapping(d, n1, live1);
            else if (screen == SCREEN_STATUS) draw_status(d);
            else                              draw_main(d);
            display_show(d);
        } else {
            // Game: the SNES picture and sound go to the console's own output.
            mailbox_write_frame(s1, s2, stick, run_request);
            mailbox_read();
            display_mode(true);
            surface_t *d = display_get();
            if (game_frames_shown < 2) graphics_fill_screen(d, graphics_make_color(0, 0, 0, 0xFF));   // both buffers' borders once
            game_frame(d);
            game_audio();
            display_show(d);
            game_frames_shown++;
        }
    }
}

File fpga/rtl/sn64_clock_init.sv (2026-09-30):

// SPDX-License-Identifier: GPL-3.0-or-later
// Si5351A start-up and SNES region clock selection.
//
// Programs the Si5351A over I2C from the 25 MHz housekeeping clock so that
// CLK0 = 21.4772727 MHz (NTSC SNES master) and CLK1 = 21.28137 MHz (PAL),
// both from a 25 MHz crystal, then waits for both PLLs to report lock
// (register 0: SYS_INIT and LOL_A/LOL_B clear) before asserting `clocks_ready`.
// CLK2 is powered down and its output disabled: the SNES picture and sound go
// to the console over the cartridge bus (docs/design/console-video-path.md), so
// the board has no pixel clock. Register values are derived in
// docs/design/clock-plan.md (AN619 formulas).
//
// Region: `region_pal` selects which master clock the SNES domain uses.
// Rule: the SNES master clock starts ONCE, at power-on, already at the chosen
// frequency, and never changes while it runs. Detection (key CIC type, which
// uses its own CIC clock, and the ROM header, which needs no SNES clock) and
// any user override from the N64 menu are latched only while the SNES clock
// is stopped (`snes_clock_stopped`). A menu change therefore takes effect at
// the next cartridge power-up, never live, so a flashcart is never disturbed
// mid-game or mid-launch.
//
// No register is written after start-up: the Si5351 is never touched while
// the SNES clock runs (tb_clock_init counts I2C STARTs after clocks_ready).
module sn64_clock_init #(
    parameter CLK_HZ = 25_000_000,
    parameter I2C_HZ = 400_000,
    parameter [6:0] SI5351_ADDR = 7'h60
) (
    input  wire clk,              // 25 MHz housekeeping clock
    input  wire reset_n,

    // I2C (open drain: drive low or release)
    output wire scl_oe,           // 1 = pull SCL low
    output wire sda_oe,           // 1 = pull SDA low
    input  wire sda_in,

    // Region selection
    input  wire [1:0] region_mode,     // 0 = auto, 1 = force NTSC, 2 = force PAL
    input  wire       detected_valid,  // auto-detection has a result
    input  wire       detected_pal,    // auto-detection result
    input  wire       snes_clock_stopped, // SNES master clock not yet started (power-on detection window)
    output reg        region_pal,      // clock select for the SNES domain (0 = CLK0 NTSC, 1 = CLK1 PAL)
    output wire       region_change_pending,

    output reg        clocks_ready,    // Si5351 configured and both PLLs locked
    output reg        i2c_error        // no ACK or lock timeout; latched until reset
);
    // ------------------------------------------------------------------
    // Register table: {register, value}. Written in order, then PLL reset,
    // then outputs enabled. Values from docs/design/clock-plan.md.
    // ------------------------------------------------------------------
    localparam N_WRITES = 37;
    function automatic [15:0] table_entry(input [5:0] i);
        case (i)
            0:  table_entry = {8'd3,   8'hFF};  // disable all outputs while programming
            1:  table_entry = {8'd16,  8'h80};  // CLK0 powered down during setup
            2:  table_entry = {8'd17,  8'h80};  // CLK1
            3:  table_entry = {8'd18,  8'h80};  // CLK2: stays powered down (no pixel clock)
            4:  table_entry = {8'd183, 8'hD2};  // crystal load 10 pF
            // PLLA (MSNA): 25 MHz x (34 + 4/11) = 859.0909 MHz, P1=3886 P2=6 P3=11
            5:  table_entry = {8'd26, 8'h00}; 6:  table_entry = {8'd27, 8'h0B};
            7:  table_entry = {8'd28, 8'h00}; 8:  table_entry = {8'd29, 8'h0F};
            9:  table_entry = {8'd30, 8'h2E}; 10: table_entry = {8'd31, 8'h00};
            11: table_entry = {8'd32, 8'h00}; 12: table_entry = {8'd33, 8'h06};
            // PLLB (MSNB): 25 MHz x (34 + 3137/62500) = 851.2548 MHz, P1=3846 P2=26536 P3=62500
            13: table_entry = {8'd34, 8'hF4}; 14: table_entry = {8'd35, 8'h24};
            15: table_entry = {8'd36, 8'h00}; 16: table_entry = {8'd37, 8'h0F};
            17: table_entry = {8'd38, 8'h06}; 18: table_entry = {8'd39, 8'h00};
            19: table_entry = {8'd40, 8'h67}; 20: table_entry = {8'd41, 8'hA8};
            // MS0: integer divide by 40 (P1=4608), R0 = 1
            21: table_entry = {8'd42, 8'h00}; 22: table_entry = {8'd43, 8'h01};
            23: table_entry = {8'd44, 8'h00}; 24: table_entry = {8'd45, 8'h12};
            25: table_entry = {8'd46, 8'h00}; 26: table_entry = {8'd47, 8'h00};
            27: table_entry = {8'd48, 8'h00}; 28: table_entry = {8'd49, 8'h00};
            // MS1: integer divide by 40
            29: table_entry = {8'd50, 8'h00}; 30: table_entry = {8'd51, 8'h01};
            31: table_entry = {8'd52, 8'h00}; 32: table_entry = {8'd53, 8'h12};
            33: table_entry = {8'd54, 8'h00}; 34: table_entry = {8'd55, 8'h00};
            35: table_entry = {8'd56, 8'h00}; 36: table_entry = {8'd57, 8'h00};
            default: table_entry = 16'h0000;
        endcase
    endfunction
    // After the table: reset both PLLs, power up CLK0 (MS0 integer, PLLA,
    // multisynth source, 8 mA) and CLK1 (MS1 integer, PLLB), enable outputs
    // 0 and 1 only (register 3: 1 = disabled; CLK2-7 stay disabled).
    localparam [15:0] W_PLL_RESET = {8'd177, 8'hA0};
    localparam [15:0] W_CLK0_CTRL = {8'd16,  8'h4F};
    localparam [15:0] W_CLK1_CTRL = {8'd17,  8'h6F};
    localparam [15:0] W_OE        = {8'd3,   8'hFC};

    // ------------------------------------------------------------------
    // Minimal I2C master: byte-level write and single-register read.
    // ------------------------------------------------------------------
    localparam integer QUARTER = CLK_HZ / I2C_HZ / 4;
    reg [15:0] qcnt; wire tick = (qcnt == 0);
    always @(posedge clk) qcnt <= (!reset_n || tick) ? QUARTER-1 : qcnt - 1;

    reg scl_low, sda_low;
    assign scl_oe = scl_low;
    assign sda_oe = sda_low;

    localparam [4:0] M_IDLE=0, M_START=1, M_BIT=2, M_ACK=3, M_STOP=4, M_RBIT=5, M_RNACK=6, M_DONE=7;
    reg [4:0] mstate; reg [1:0] phase; reg [3:0] bitn;
    reg [7:0] shreg; reg [7:0] rdata; reg nack;
    reg [2:0] nbytes, byte_idx; reg [7:0] bytes [0:2]; reg read_mode, rd_restart;
    reg go, busy;
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

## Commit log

2026-09-29 Add engineering specification, full project plan, peripheral research, and CAD repository settings
2026-09-29 Collect reusable SNES and N64 designs and extract connector geometry
    [n64-reference-pads.csv, snes-socket-reference-pads.csv]
2026-09-29 Add verified cartridge interface draft and reusable KiCad libraries
    [n64-pin-map.csv, sn64.kicad_sch, snes-pin-map.csv]
2026-09-29 Add side USB-C programming circuit and document source-checked interfaces
    [sn64.kicad_sch, usb-programmer-net-map.csv, usb-programmer.kicad_sch]
2026-09-29 Add sourced cartridge interfaces and side USB-C programmer draft
    Include the reusable-design research, native KiCad interface and USB programming sheets, local libraries and licenses, independent checks, schematic PDF, and ongoing work log. The complete FPGA/stora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
    [n64-pin-map.csv, n64-reference-pads.csv, sn64.kicad_sch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]
2026-09-29 Evaluate reused SNES core and establish full system design evidence
    [acceptance-matrix.csv, n64-sc64-board-reference.FCStd, n64-sc64-board-reference.step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]
2026-09-29 Correct cartridge-visible WRAM data and preserve bus evidence
    [acceptance-matrix.csv]
2026-09-29 Move development to Claude Code and record project notes
    Add CLAUDE.md with the project's working rules, decisions and check
    commands. Log the move from the Codex workspace, the re-run simulation
    and KiCad static checks, publication of the full local history to main,
    and the user's decision to let Claude choose better-suited tools.
2026-09-29 Add quick project risk assessment
    Rank the main technical, cost and scope risks with a response for each,
    state the limits of software-only verification, and recommend proving
    the physical cartridge path on development hardware before the custom
    BGA board.
2026-09-29 Add physical cartridge bridge with contention-checked simulation
    Implement sn64_cart_bridge: registered socket outputs gated by a hardware
    permission, a data-bus ownership state machine with one released clock at
    every owner change, look-ahead so turnarounds complete before the strobe
    edge reaches the cartridge, and one clock of write-data hold. Internal
    CPU-register reads are not exported, per the bus evidence audit.
    Add a socket-facing top level and a physical-bus testbench whose cartridge
    model drives only when selected and whose monitor fails on contention,
    unpermitted outputs, missing write data or a missing turnaround. The
    diagnostic passes (1,411 clocks, 56 ownership changes, zero co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
2026-09-29 Add N64/M64 host endpoint with reused SummerCart64 PI controller
    Vendor SummerCart64's N64 PI controller, FIFO and bus interfaces
    unmodified (GPL-3.0, commit a1e7996d) with a provenance manifest, and
    wrap them in sn64_n64_endpoint: a bootstrap ROM window at 0x1000_0000
    and a mailbox register block at 0x1FFF_0000 carrying controller state,
    analog stick, run request, status and build identity. Host reset clears
    the run request so cartridge power must be re-requested after every
    console reset.
    Add a host-model testbench that drives the PI protocol and checks AD-bus
    ownership, ROM burst/offset reads, mailbox read/write/readback and reset
    behaviour (PASS, 4,595 clocks); register it in evaluate.p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
2026-09-29 Add N64 CIC lockout and power-control state machine
    Vendor SummerCart64's CIC module, the SERV RISC-V core and the
    UltraCIC_C-derived CIC firmware unmodified, add build_cic.py to build the
    firmware with the xPack RISC-V toolchain, and instantiate the CIC in the
    N64 endpoint as CIC-6102/7101. The bit-serial soft CPU runs from a
    separate 62.5 MHz clock, as in SummerCart64, because it cannot answer the
    console in time at the 21.477 MHz master clock. A console-side model
    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
2026-09-29 Add clock plan, Si5351 start-up and fixed-at-power-on region selection
    The ECP5 PLL cannot produce the NTSC or PAL SNES master clocks within
    crystal accuracy from standard references, so a Si5351A synthesises both
    from a 25 MHz crystal (exact NTSC, sub-ppb PAL), while the ECP5 PLLs make
    the 62.5 MHz CIC and 135 MHz HDMI clocks from a 25 MHz oscillator.
    sn64_clock_init programs the Si5351 over I2C, waits for PLL lock and
    latches the region (key CIC type, ROM header, or menu override) only
    while the SNES clock is stopped: the master clock starts once at power-on
    and never changes while a cartridge or flashcart is running.
    The power sequencer gains hold_reset, a reset-button style soft reset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
    [sn64_clock_init.sv, tb_clock_init.sv]
2026-09-29 Add clock-domain crossing helpers and integrated top level
    sn64_top wires the N64 endpoint (always-on 62.5 MHz), the Si5351
    start-up, power sequencer and SNES CIC lock (25 MHz housekeeping) and the
    SNES core, cartridge bridge and controller emulation (SNES master clock).
    The SNES clock starts once per cartridge power-up after the region is
    decided; /RESET is released only after the clock has run for 1 ms.
    Mailbox CONTROL gains soft reset and region-mode bits, and the power
    sequencer waits for release_ok before releasing /RESET. The CDC word
    transfer is tested for torn values across unrelated clocks.
2026-09-29 Add whole-system power-on simulation and fix a /RESET deadlock
    tb_system drives sn64_top with an N64 host on the PI bus, a Si5351 I2C
    slave, cartridge rails, a ROM/SRAM cartridge and no key CIC. It checks the
    full flow from mailbox identification through ordered cartridge power,
    Si5351 lock, region decision, a single SNES clock start and /RESET release
    to an original SNES program that reads the N64 controller image through
    auto-joypad, with invariants for bus permission, clock start and region.
    The first run found a deadlock: the bridge held socket /RESET while the
    core was in reset, and the core reset followed the socket /RESET level.
    Socket /RESET is now owned by the power sequencer and b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
    [tb_system.sv]
2026-09-29 Add controller path, SNES CIC lock, N64 bootstrap ROM and integration
    - sn64_snes_joypad: two emulated standard SNES pads from the mailbox
    images, reusing SNESTang controller_adapter unmodified; forces the ID
    bits, keeps the multitap line idle, supports an empty port. Protocol and
    whole-core benches pass; a B/Y swap is rejected. Default N64 mapping v1.
    - sn64_snes_cic_lock: original HDL from published algorithm descriptions;
    NTSC/PAL keys pass for four seeds and match the reference program, absent
    and corrupted keys are flagged, two fault builds are rejected.
    - firmware/bootstrap: libdragon menu ROM (controller mapping, mailbox
    loop, start/power-down, diagnostics); IPL checksum m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
    [main.c]
2026-09-29 Add SNES cartridge-interface schematic sheet
    New KiCad child sheet with seven SN74LVC4245A translators (5 V cartridge
    side, 3.3 V FPGA side): five fixed-direction octets for address, B-bus and
    strobes on the bridge's shared enable, one octet for SYSTEM_CLK and the
    CIC outputs on its own enable, and D0-D7 with FPGA-controlled direction
    and enable. Every enable and the data DIR are pulled to cartridge 5 V and
    pulled low only through 3.3 V open-drain buffers, so an unconfigured FPGA
    or a missing interface rail leaves all translators disabled and no 5 V
    pull-up reaches an FPGA pin. Adds the /RESET sink transistor, a 5 V
    tolerant sense buffer, 33 R series arrays, bias and decoupling.
    verify_cart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
    [cart-interface.kicad_sch, sn64.kicad_sch]
2026-09-29 Record simulation evidence in the requirements register
    24 rows gain references to the passing benches that support them (bridge,
    N64 endpoint and CIC, SNES CIC lock, controllers, power sequencer, clock
    start-up, system power-on, bootstrap tests). 23 rows now carry partial
    simulation evidence; none is measured and all 136 remain NOT_ACCEPTED.
    [acceptance-matrix.csv]
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2026-09-29 Add HDMI output and lock its pixel clock to the SNES master
    sn64_av_out line-doubles the SNES picture into 720x480p HDMI with 32 kHz
    HDMI audio, using a 4-line buffer (2 DP16KD) and a raster locked to the
    SNES frame, never pausing or changing the SNES clock. It reuses the
    hdl-util/hdmi TMDS and packet modules (MIT/Apache-2.0). Its bench decodes
    the serial TMDS lanes: 2,430,720 pixels exact, sync and frame shape, 0 ECC
    errors, 4,792 audio samples in order; a flipped pixel bit and a short
    hsync are rejected.
    The pixel clock comes from the Si5351's spare CLK2 on the same PLL as the
    NTSC master (fractional divider 31 + 31/39 = exactly master x 39/31), so
    the raster cannot drift; sn64_clock_init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
    [sn64_clock_init.sv, tb_clock_init.sv, tb_system.sv]
2026-09-29 Board top with real ECP5 clocks; header region probe, flash boot ROM, CIC pin fix
    - sn64_board_top: EHXPLLL 25->62.5 MHz and pixel x5, one glitchless DCSC
    (NEG mode) that selects NTSC/PAL and starts/stops the SNES clock, bootstrap
    ROM from the configuration flash via USRMCLK, CIC pad DIR sequencing.
    Routed on the 85F with trial pins: all five clocks pass, 143/208 BRAM.
    - ROM-header region fallback (sn64_header_probe + socket mux) merged into
    sn64_top; priority forced > key CIC > valid header > NTSC. tb_system now
    also runs with an EU header and must start in PAL.
    - Bootstrap ROM window from SPI flash (SummerCart64 memory_flash, unmodified).
    - Cart sheet rev 0.3.1: per-pin SN74LVC1T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
    [cart-interface.kicad_sch, sn64.kicad_sch]
2026-09-30 Complete schematic draft: FPGA, power, clock/HDMI/audio sheets; PAL HDMI; cart audio
    - New child sheets attached and wired at the root: FPGA (all 381 balls,
    W25Q128JV config flash, JTAG to the USB programmer, N64 edge through
    host-gated bus switches), power (priority-muxed host/USB eFuses, TUSB320
    permission, TPS63070 5V_PRE, FPGA bucks, cartridge eFuse and monitors),
    clock/HDMI/audio (Si5351A, TPD12S016 HDMI, PCM1808 cartridge-audio ADC).
    - Real pinout: fpga/constraints/sn64_board.lpf; board top routed with it,
    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
    [acceptance-matrix.csv, av-clock.kicad_sch, cart-interface.kicad_sch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]
2026-09-30 Fix two SNESTang deviations from MiSTer; NTSC HDMI frame lock; mechanical plan
    - prepare_core.py: restore PPU long dots (SNESTang ported MiSTer's
    "H_CNT = 323 or H_CNT = 327" as "&&", so lines were 1360 clocks and the
    console ran 0.3 % fast). Measured after: NTSC frames 357,368/357,364
    (hardware short line), PAL 425,568.
    - prepare_core.py: restore the S-DSP rate (ACLK_FREQ 409600, region-correct
    CE divider as in MiSTer DSP.vhd): 32,000 Hz in both regions instead of
    32,180 / 31,886 Hz.
    - Si5351 NTSC MS2 = 31 + 14887/18733 so one HDMI frame equals the mean SNES
    frame; PAL MS2 = 31 + 31/54 (1364-clock lines); sn64_av_out LOCK_TOL 8.
    tb_system now checks frame lock in NTSC too, wit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
    [sn64_clock_init.sv, tb_clock_init.sv, tb_system.sv]
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2026-09-30 Two-board split: SNES socket on its own board, joined by a 2x40 2.00 mm header
    - Main root J2 becomes SN64_Socket_Joint_2x40 (pins 1-62 keep the socket
    names and wiring; 63-66 cartridge 5 V, 67-80 GND); footprint 2x40 2.00 mm
    right-angle header.
    - New hardware/sn64-socket project: J1 socket on SNES_Slot_Console_7mm
    (console-replacement family, OpenSFC CartSlot geometry, 7.0 mm rows,
    ears 95 mm), J2 joint socket, two 100 nF. ERC 0/0.
    - tools/split_socket_board.py (idempotent, native root edit) and
    tools/verify_socket_joint.py (9/9, negative 3/3); verify_interfaces
    understands the joint (31/31). Every other validator unchanged.
    - docs: mechanical-architecture decision, dimensions l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
    [bom.csv, sn64-socket.kicad_sch, sn64.kicad_sch]
2026-09-30 Footprints for the eFuses, TPS63070 and inductors from manufacturer land patterns; all 419 parts have footprints
    [power.kicad_sch]
2026-09-30 First-draft main PCB: 6-layer board from the netlist with block placement (build_main_pcb.py)
    [sn64.kicad_pcb]
2026-09-30 PCB: connectivity-pulled placement with occupancy map, corrected SC64 outline corners, edge keep-outs, rule file
    [sn64.kicad_pcb]
2026-09-30 Decision: SNES video/audio to the console over the cartridge bus is the primary A/V path (design note); six PCB mounting holes
    [sn64.kicad_pcb]
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2026-09-30 Remove the on-board HDMI output: the console's own output is the only video path
    Owner decision 2026-09-29: the SNES picture and sound reach the TV through the
    console (M64 HDMI, N64 AV jack) via the cartridge-bus frame window; the board
    has no video output of its own.
    FPGA: delete sn64_av_out/av_hdmi_tx/av_serializer, tb_av_out and the vendored
    hdl-util/hdmi tree; sn64_clock_init keeps CLK2 powered down (reg 3 = 0xFC) and
    writes nothing after start-up; board top keeps one PLL, drops si_clk2/hdmi_*.
    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
    [acceptance-matrix.csv, av-clock.kicad_sch, fpga-pin-map.csv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]
2026-09-30 PCB: routing preparation (BGA dog-bone fan-out, GND/3V3/1V1 planes, netclasses)
    prepare_route.py adds 240 through vias for the used inner balls of the
    caBGA-381 (0.4 mm diagonal dog-bones, 0.45/0.2 mm), a GND plane on In1, a
    FPGA_3V3 plane on In3 and a FPGA_1V1 island on In4 over the core balls and the
    decoupling bands, sets power/usb netclasses in the project file and exports
    the Specctra DSN for Freerouting; finish_route.py imports the session and adds
    outer GND pours. build_main_pcb.py moves the FPGA decoupling out of the via
    field into two bottom-side bands above and below the BGA (the vias landed on
    the capacitors before). DRC after preparation: no shorts or clearance errors,
    only the b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
    [sn64.kicad_pcb]
2026-09-30 Tools: 16 Verilator build jobs, Freerouting instance runner, via-drill fix on session import
    evaluate.py builds each bench with 16 jobs (suite 307 s on the 24-core box
    while two routers ran). fr_instance.ps1 starts an extra Freerouting API
    server on its own port and submits a variant job through the REST API, since
    one instance time-slices its jobs on a single core. finish_route.py pins every
    via drill to its diameter after ImportSpecctraSES (the importer gave the
    plane-net dog-bones a 0.3 mm drill). Routing notes record the hole-clearance
    and edge-clearance job settings Freerouting needs.
2026-09-30 PCB: FPGA rotated 180 degrees so the N64 bank faces the bus switches
    The first autoroute run left the N64 bus (fpga_n64_*) unrouted: at 0 degrees
    bank 0 faces the top of the board while the bus switches sit at the bottom.
    Board rebuilt and re-prepared (fan-out, planes, netclasses); DRC unchanged.
    [sn64.kicad_pcb]
2026-09-30 PCB: plane vias, N64-finger keep-out, PCBWay hole clearance; KiCadRoutingTools fab floors
    add_plane_vias.py drops a 0.45/0.2 via next to every GND / FPGA_3V3 / FPGA_1V1
    SMD pad on the prepared board (324 placed, 96 left for hand work), checking
    pads, tracks, vias, rule areas and the board edge on a 1 mm grid.
    prepare_route.py adds a track/via keep-out over the N64 edge tongue on both
    outer layers. Hole-to-copper relaxed to 0.2 mm (PCBWay standard 6-layer is
    8 mil). fab-pcbway.txt pins KiCadRoutingTools to the board's floors so it no
    longer narrows tracks and vias below them. finish_route.py can finish a board
    that already carries its routing. KiCad 10 note: PCB_VIA.GetWidth() without a
    layer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
    [sn64.kicad_pcb]
2026-09-30 PCB: first routed draft of the main board (KiCadRoutingTools run 2 + plane vias)
    Tracked board: FPGA at 180 degrees, 240 dog-bone fan-out vias, GND/3V3
    planes and the 1V1 island, signals routed by KiCadRoutingTools (Rust A*,
    pinned to the board's fab floors), 157 plane vias, outer GND pours. DRC has
    no shorts, crossings, clearance or hole errors; open: 75 signal/power nets
    (95 connections, mostly the translator row) and 219 plane pads, listed in
    validation/pcb-open-connections.json. Renders updated.
    Tools: add_plane_vias.py (layer-aware stubs, edge and keep-out checks),
    finish_route.py --no-import, fab-pcbway.txt; hole-to-copper 0.2 mm (PCBWay
    8 mil). Notes on the three routers tried, the P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
    [sn64.kicad_pcb]
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

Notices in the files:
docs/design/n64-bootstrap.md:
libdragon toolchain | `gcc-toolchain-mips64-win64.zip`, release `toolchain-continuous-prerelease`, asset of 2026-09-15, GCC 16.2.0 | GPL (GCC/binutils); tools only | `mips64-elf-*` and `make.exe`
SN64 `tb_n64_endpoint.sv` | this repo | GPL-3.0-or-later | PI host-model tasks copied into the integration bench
